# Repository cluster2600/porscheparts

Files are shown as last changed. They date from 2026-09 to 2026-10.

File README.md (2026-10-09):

<div align="center">

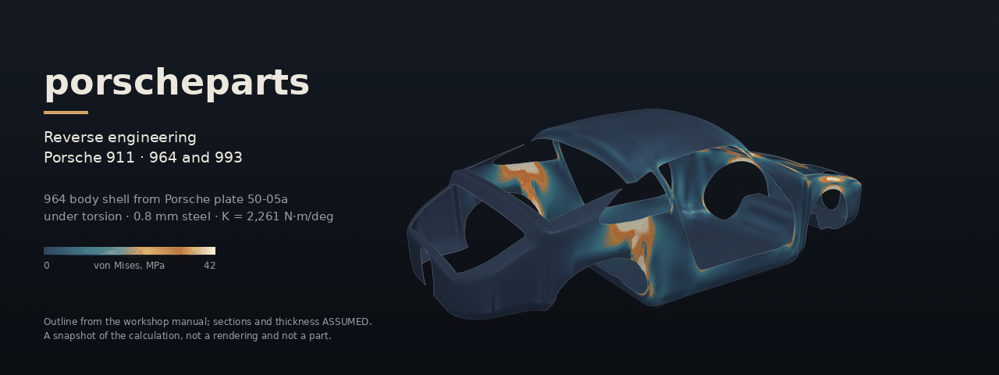
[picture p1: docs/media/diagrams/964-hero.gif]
The 964 body shell traced from the workshop manual, turning, coloured by von Mises stress under a torsion load


# porscheparts

**Reverse engineering for the Porsche 911 964 and 993**<br>
*Sourced data, falsifiable calculations, no part manufactured.*







[**Parts**](#2-993-parts-for-additive-manufacturing) ·
[**964 structure and monocoque**](#1-the-964-body-shell-and-the-carbon-monocoque-programme) ·
[**Engine cooling**](#3-engine-cooling) ·
[**Gallery**](docs/GALLERY.md) ·
[**Run the checks**](#quick-start) ·
[**Safety first**](SAFETY.md)

</div>

---

This repository does not publish a library of files to print. It publishes
**sourced data** and **falsifiable calculations**: every claim of fit, mass,
airflow or stiffness is tied to a measurement, a verifiable source or a
calculation anyone can rerun, and it is **withdrawn when it no longer holds**.
The repository has withdrawn several, listed
[further down this page](#what-the-repository-withdrew-from-its-own-results).

> [!IMPORTANT]
> **No part is validated.** All 41 part records are at status `concept`, and 23
> of them are `prohibited_pending_engineering`. Read [SAFETY.md](SAFETY.md).

<table>
<tr>
<td align="center"><h3>527</h3>qualified source records</td>
<td align="center"><h3>41</h3>part records<br><sub>23 prohibited as they stand</sub></td>
<td align="center"><h3>34</h3>993 design dossiers<br><sub>for additive manufacturing</sub></td>
</tr>
<tr>
<td align="center"><h3>10</h3>digital twin records<br><sub>none at <code>F2_interface</code></sub></td>
<td align="center"><h3>21</h3>LPBF print simulations<br><sub>17 screened, 4 not</sub></td>
<td align="center"><h3>3,391</h3>tests run by<br><code>make check</code></td>
</tr>
</table>

## What changed recently

| date | change |
|---|---|
| 2026-10-09 | **Two monocoque architectures in torsion**: on the same mesh and load, closed sections formed by the skin are 1.4 to 1.9 times stiffer per kilogram than tubes tangent to it, at all three meshes. A ranking of two hypotheses. [Comparison](twins/964-chassis/monocoque/README.md#two-architectures-one-load-case) |
| 2026-10-09 | **Torsion of the monocoque architecture**: K about 29,500 N·m/deg in steel and 22,300 in CFRP (75 kg), stable within 7% over three meshes, more than five times the open shell; carbon gives ×1.15 to ×1.28 per kilogram. A model value, not a car's. [Torsion](twins/964-chassis/monocoque/README.md#torsion-of-the-monocoque-architecture) |
| 2026-10-08 | **A ZESAD-type carbon monocoque in PicoGK**, inside the traced shell: closed sections around every aperture, boxed sills, tunnel and rails, sandwich floor and bulkheads; about 95 kg from assumed layups. A design envelope, not a part. [Monocoque](twins/964-chassis/monocoque/picogk/README.md) |
| 2026-10-08 | **A 911-shaped monocoque shell**: outline traced from the workshop manual's plate 50-05a, sections modelled, a first whole-body torsion run; it replaces the box cell in the banner. [Shell](twins/964-chassis/monocoque/README.md) |
| 2026-10-08 | **964 datum chain closed** from the workshop manual's own plates (50-02, 50-03, 50-05a): every suspension and power-unit mount of the monocoque interface contract now has a fore-aft position, checked against the underside scan. [Details](twins/964-chassis/README.md#the-longitudinal-chain-closed-from-plate-50-05a) |
| 2026-10-08 | **LPBF print simulation pictured**: build-up videos for the F1 cooling impeller and its stator. [Impeller dossier](docs/993/993_COOLING_IMPELLER_WE43_F1.md#print-simulation-pictured) |
| 2026-10-08 | **PicoGK batch 01**: ten parametric concept parts from one voxel-kernel project. [Batch page](parts/picogk-993-batch-01/README.md) |
| 2026-10-07 | **F1 cooling impeller redesigned from the original Turbo rotor**: same cup, windows and envelope, airfoil blades in WE43; the earlier generic shrouded design was withdrawn. [Dossier](docs/993/993_COOLING_IMPELLER_WE43_F1.md) |

> [!TIP]
> **Printable today:**
> - 🖨️ the **[switch trim ring, F1](parts/993-int-switch-trim-ring-f1-0001/print/README.md)**: a part the
>   repository designed, printed as designed, 17 minutes of PETG or ASA, no supports. Fit on the car not
>   checked yet ([decision 0010](docs/decisions/0010-print-the-trim-ring-f1-in-polymer.md)).
> - a **[fit-test kit for the dashboard switch blank](parts/993-int-switch-blank-0001/print/README.md)**: three
>   sizes to find the real opening ([decision 0009](docs/decisions/0009-first-fit-test-print-switch-blank.md)).
> - 🧩 **display mock-ups** of two prohibited designs, engraved "MOCK-UP / NOT FOR USE":
>   [the F0 connecting rod](parts/993-eng-connecting-rod-ti64-f0-0001/print/README.md) and
>   [the K16 wheel pair on a stand](parts/993-eng-k16-compressor-wheel-al2139-f1-0001/print/README.md)
>   ([decision 0011](docs/decisions/0011-printable-display-mockups-of-prohibited-parts.md)).
>
> None of them is validated.

## How the repository works

Every artifact climbs the same ladder, and every rung is checked by `make check`.
Nothing leaves the last rung: manufacturing is suspended by design.

```mermaid
flowchart LR
    S["Sources<br/><sub>catalog/sources/</sub>"] --> R["Part records<br/><sub>catalog/parts/</sub>"]
    R --> D["Design dossiers<br/><sub>docs/993/</sub>"]
    D --> T["Digital twins<br/><sub>twins/</sub>"]
    T --> C["FEA · CFD · print simulation<br/><sub>CalculiX · OpenFOAM · LPBF</sub>"]
    C --> G{"Quality gates<br/><sub>docs/QUALITY_GATES.md</sub>"}
    G -- "claim fails" --> W["Withdrawn, and said so"]
    G -- "claim holds" --> E["Evidence<br/><sub>pinned by SHA-256</sub>"]
    E -. "suspended in the active phase" .-> M["Manufacturing"]
    classDef stop fill:#fde2e1,stroke:#c0392b,color:#1a1a1a;
    classDef ok fill:#e3f1e6,stroke:#2e7d32,color:#1a1a1a;
    class M,W stop
    class E ok
```

### Where to start

| I want to… | go to |
|---|---|
| print something today | [the F1 switch trim ring](parts/993-int-switch-trim-ring-f1-0001/print/README.md) · [the switch blank fit-test kit](parts/993-int-switch-blank-0001/print/README.md) |
| see which 993 parts exist and their status | [the parts table](#2-993-parts-for-additive-manufacturing) → one page per part in [`docs/pieces/`](docs/pieces/) |
| follow the carbon monocoque programme | [section 1](#1-the-964-body-shell-and-the-carbon-monocoque-programme) → [the programme](docs/MONOCOQUE_964_993_PROGRAMME.md) |
| see the engine cooling work | [section 3](#3-engine-cooling) → [the fan programmes](docs/FAN_DEVELOPMENT_PROGRAMMES.md) |
| watch a print simulation | [F1 impeller build-up](parts/993-eng-cooling-impeller-we43-f1-0001/media/print-simulation/build.gif) · [all print screens](docs/993/print-screen-status.json) |
| know what may and may not be built | [SAFETY.md](SAFETY.md) · [docs/QUALITY_GATES.md](docs/QUALITY_GATES.md) |
| add a part or a source | [CONTRIBUTING.md](CONTRIBUTING.md) · [docs/WORKFLOW.md](docs/WORKFLOW.md) · [docs/SOURCE_POLICY.md](docs/SOURCE_POLICY.md) |
| find any document | [the documentation index](docs/README.md) · [the gallery](docs/GALLERY.md) · [dated reports](docs/reports/README.md) |
| browse the digital twins | [twins/README.md](twins/README.md) |
| run the checks locally | [Quick start](#quick-start) |

### Contents

1. [The 964 body shell and the carbon monocoque programme](#1-the-964-body-shell-and-the-carbon-monocoque-programme)
2. [993 parts for additive manufacturing](#2-993-parts-for-additive-manufacturing)
3. [Engine cooling](#3-engine-cooling)
4. [Engine and turbo research](#4-engine-and-turbo-research)
5. [Body and interior](#5-body-and-interior)
6. [The catalogue and its data contract](#6-the-catalogue-and-its-data-contract)
7. [The rules](#the-rules) · [What the repository withdrew](#what-the-repository-withdrew-from-its-own-results) · [What it does not claim](#what-the-project-does-not-claim)
8. [Quick start](#quick-start) · [Layout](#repository-layout) · [Status](#status)

---

## 1. The 964 body shell and the carbon monocoque programme

The main workstream. Its goal is a **replacement carbon monocoque for 964 and
993 restomods**, competing with the one existing offer on the axis where that
offer is bare: published data. The [programme](docs/MONOCOQUE_964_993_PROGRAMME.md)
says what has to be established, in what order, and that it **contradicts the
written scope** of [ROADMAP.md](ROADMAP.md).

### The structure: what the shell model shows

A finite-element shell model of the floor pan, the box section and the full
cell answers **relative** questions: between changing the material and closing
the body shell, which pays off more? Where does the load go in torsion?

The shell model, bare floor pan and full cell

**Results that hold**, see [`twins/964-chassis/fea/`](twins/964-chassis/fea/):

- the **side rail** carries torsion, not the floor pan, which agrees with plate
  50-013 of the workshop manual, which places high-strength steel there;
- **closing a ring does not just add stiffness, it changes the mechanism that
  carries it**: bending on the bare floor pan, shear on the closed cell;
- from bare floor pan to closed cell, **K × 3.77 for mass × 2.3**;
- roof and windshield frame together are worth **1.63 times** the sum of their
  separate contributions: the roof only works once the ring is closed;
- at equal mass, closing the body shell is worth more than switching to carbon.

von Mises stress on the bare floor pan

A **corpus of 3,000 CalculiX cases** in quadratic shells is built to train a
design surrogate later, its validation set frozen before any model exists:
[docs/MONOCOQUE_964_993_CHAINE_CALCUL.md](docs/MONOCOQUE_964_993_CHAINE_CALCUL.md).

### The shape: a 964 shell from the workshop manual

The box cell above has no 911 shape. The
[monocoque shell](twins/964-chassis/monocoque/README.md) takes its outline
from plate 50-05a, which draws the body-in-white to scale from the side and
from above, with wings, doors and lids off. Side profile, plan width, door
aperture, quarter window and rear wheel house are traced from it; the sections
between them (tumblehome, barrel sides, 880 mm beltline) are modelled.

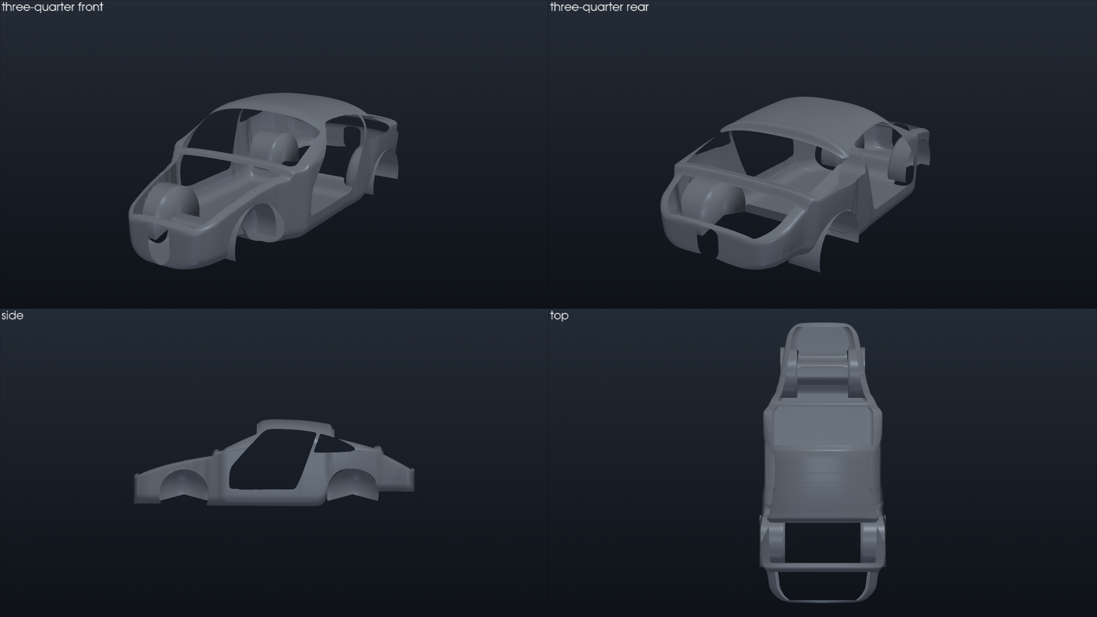
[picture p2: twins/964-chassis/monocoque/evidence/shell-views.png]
The monocoque shell traced from plate 50-05a


A first torsion run on it, uniform 0.8 mm steel with every aperture open,
puts the load around the windscreen frame, the A-pillars, the door corners and
the C-pillars: the open shell a monocoque has to close. Its K, 2,261 N·m/deg,
belongs to that surface model, not to a 964.

Inside that shell, [a ZESAD-type carbon monocoque](twins/964-chassis/monocoque/picogk/README.md)
is generated in voxels with PicoGK. Each aperture gets a closed section and
the sills, tunnel and rails are boxes, so the closures the box-cell study
ranked first are there by construction. Member sizes and layups are
hypotheses. In torsion, on the same mesh and load as the open shell, the
architecture is more than five times stiffer. Its K is stable within 7%
across meshes, while the open shell's is not
([torsion](twins/964-chassis/monocoque/README.md#torsion-of-the-monocoque-architecture)).

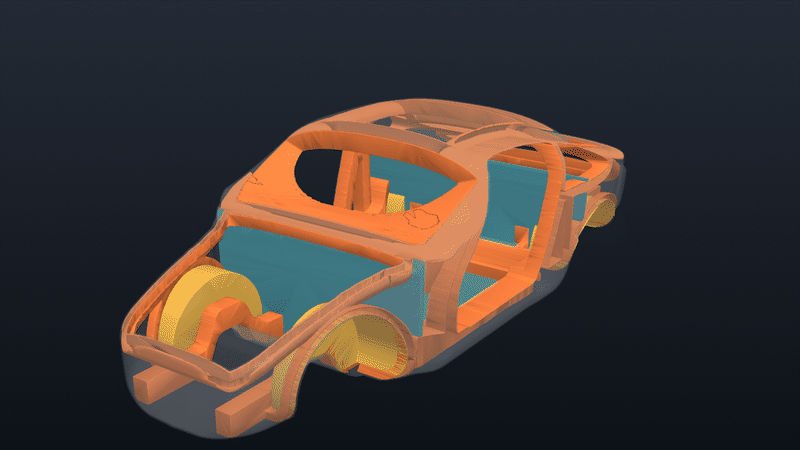
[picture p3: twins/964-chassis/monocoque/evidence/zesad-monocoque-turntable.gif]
A ZESAD-type monocoque generated with PicoGK


### The interfaces: where a monocoque has to bolt up

A monocoque replaces the body shell, so it must carry every suspension,
power-unit and jacking interface in one frame. Until October 2026 the
fore-aft position of those points could not be established. It now is, from
Porsche's own repair plates: plate 50-05a dimensions three points from a 0 line
through the front strut mounts, plate 50-02 shows dimension P is longitudinal,
and the rear diagonals of plate 50-03 are read the way both drawings and the
scan confirm. Two independent published paths place the front jacking point
within 1.9 mm of each other.

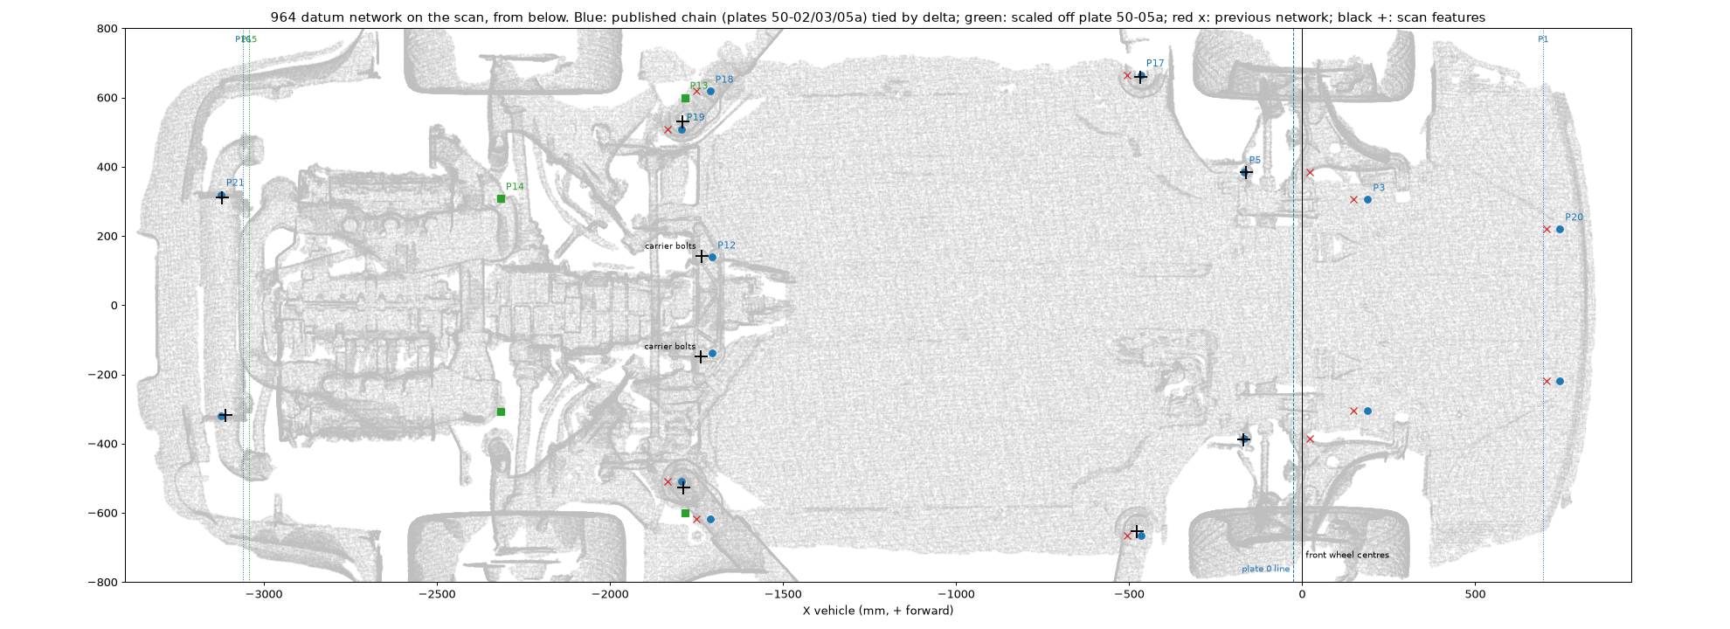
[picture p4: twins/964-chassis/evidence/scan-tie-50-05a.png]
Published datum chain tied to the underside scan


*Blue: points placed from published dimensions. Green: rear mounts scaled off
the plate. Black: features measured on the scan. Red: the previous, wrong
network.*

The monocoque's governing span, front suspension mount to transmission
carrier, is **1535.6 mm**, both ends published. What is missing now is
tolerance, not data: the points carry ±2 to 9 mm where a tool needs ±1 mm.
[The full chain, its checks and its limits](twins/964-chassis/README.md#the-longitudinal-chain-closed-from-plate-50-05a).

## 2. 993 parts for additive manufacturing

**34 design dossiers** in [`docs/993/`](docs/993/) and **41 part records**,
from the headlamp spring hook to the K16 turbine wheel in Inconel 718, by way
of the Ti-6Al-4V connecting rod, the AlSi10Mg compressor wheel, the IN625
exhaust manifold and the WE43 cooling impeller. Each dossier starts from
dimensions published by a supplier, separates what is sourced from what is
assumed, and states what it does not contain.

**Print simulation.** Every part with a STEP master goes through a geometric
LPBF simulation: full-height slicing at the material's layer thickness, fit in
the EOS M 290 envelope, an orientation, a support proxy, a wall-thickness
screen and a trapped-powder screen. 17 parts pass; 3 fail closed and say why, and 1 hit the memory cap, which is not a verdict.
It is not a process simulation, and it authorizes nothing.

<div align="center">

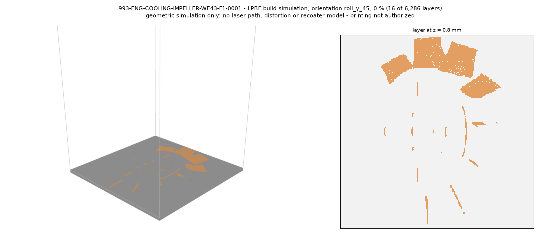
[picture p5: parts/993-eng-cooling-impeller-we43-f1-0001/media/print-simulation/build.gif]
The F1 cooling impeller built up layer by layer in the print simulation


*The F1 cooling impeller, 6,286 layers of 30 µm, tilted 45° on the plate,
with its support proxy in orange. Geometry only: printing is not authorized.*

</div>

**PicoGK batch 01.** [Ten parametric concept parts](parts/picogk-993-batch-01/README.md)
generated from one C# voxel-kernel project, each parameter tagged
`published`, `community` or `assumption`. Their mounting interfaces are
assumptions, so none is functional.

The table below is generated from `catalog/parts/` on every `make check`. The
"status" column is the record's, not an intention: a part **prohibited pending
engineering** stays so until an engineering review lifts it.

<!-- parts:start - generated by scripts/render_parts_table.py -->

> [!CAUTION]
> These are concept models for studying parts in software, not validated parts. 🖨️ marks a printable design, 🧩 an engraved display mock-up (never for use).

<table>
<tr>
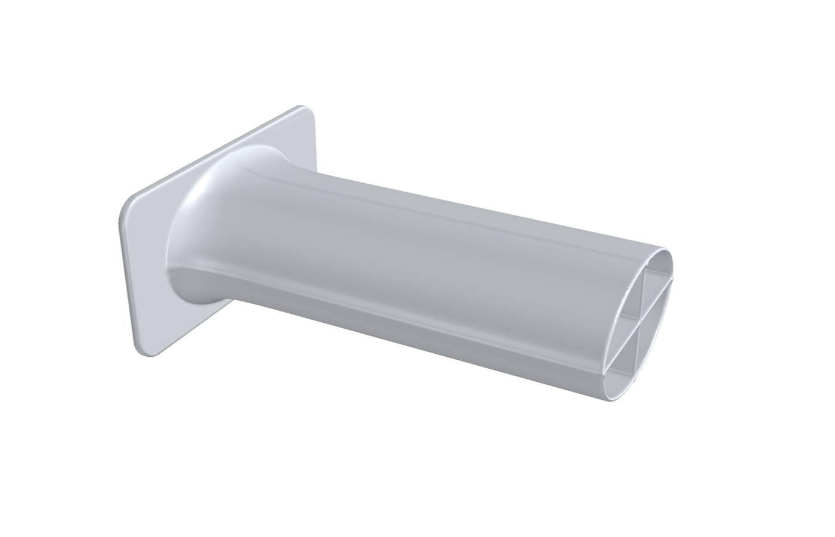
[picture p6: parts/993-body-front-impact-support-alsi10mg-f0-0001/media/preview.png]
993 front impact support
<td align="center" width="16%"><a href="parts/993-body-front-impact-support-alsi10mg-f0-0001/"><br><sub>993 front impact support</sub></a></td>
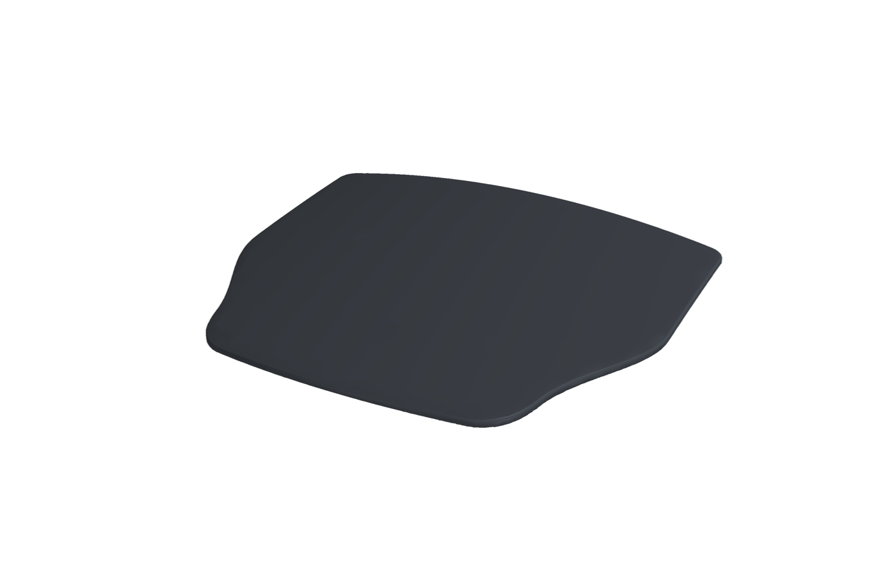
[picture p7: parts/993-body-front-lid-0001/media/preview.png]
Front lid
<td align="center" width="16%"><a href="parts/993-body-front-lid-0001/"><br><sub>Front lid</sub></a></td>
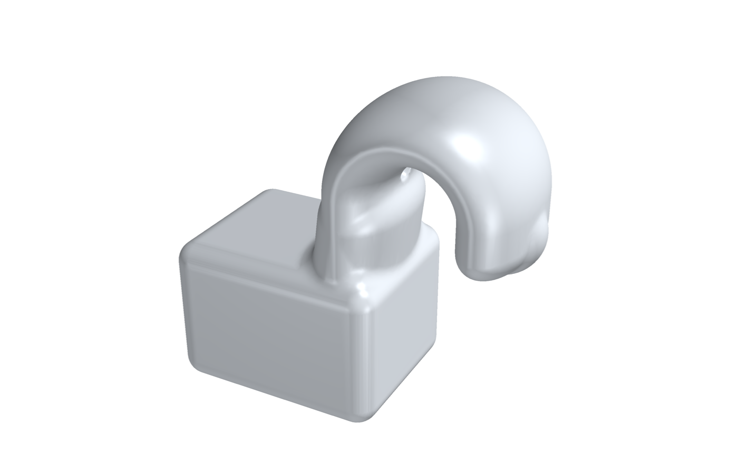
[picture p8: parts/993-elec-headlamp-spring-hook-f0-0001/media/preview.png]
Headlamp spring hook repair
<td align="center" width="16%"><a href="parts/993-elec-headlamp-spring-hook-f0-0001/"><br><sub>Headlamp spring hook repair</sub></a></td>
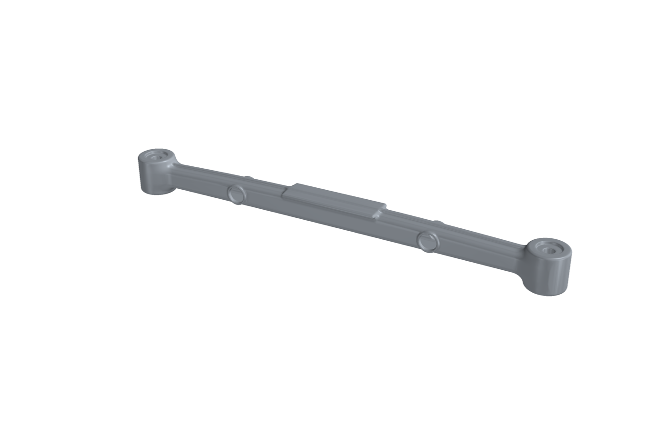
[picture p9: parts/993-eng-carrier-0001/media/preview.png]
Turbo engine carrier (Motortraege…
<td align="center" width="16%"><a href="parts/993-eng-carrier-0001/"><br><sub>Turbo engine carrier (Motortraege…</sub></a></td>
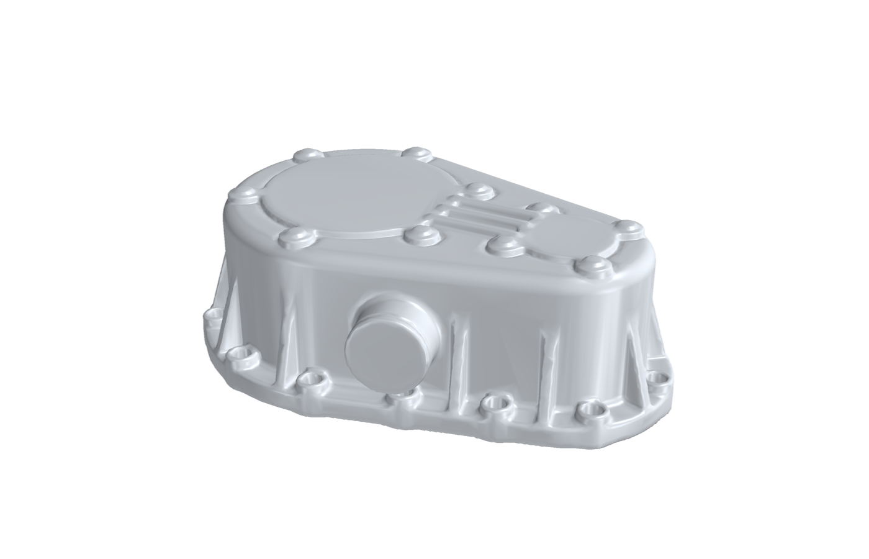
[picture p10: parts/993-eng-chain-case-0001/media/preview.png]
993 timing chain case and its lids
<td align="center" width="16%"><a href="parts/993-eng-chain-case-0001/"><br><sub>993 timing chain case and its lids</sub></a></td>
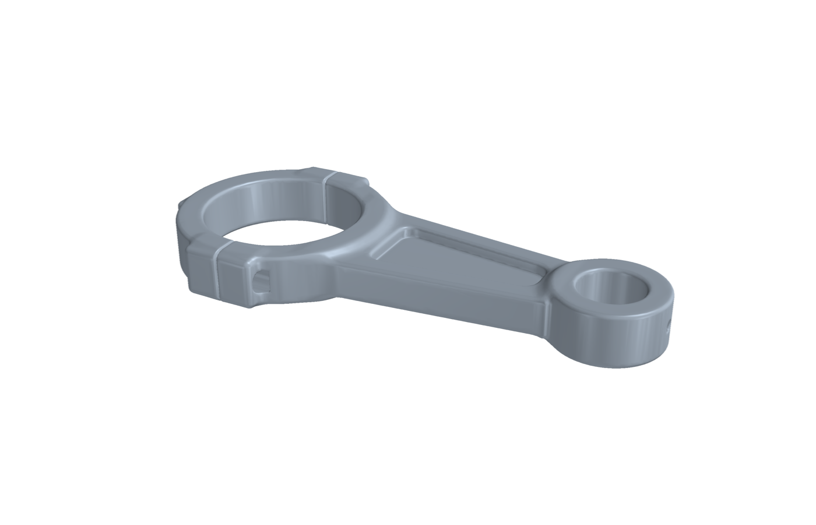
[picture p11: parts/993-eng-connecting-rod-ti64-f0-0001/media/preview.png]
🧩 993/993 Turbo connecting rod
<td align="center" width="16%"><a href="parts/993-eng-connecting-rod-ti64-f0-0001/"><br><sub>🧩 993/993 Turbo connecting rod</sub></a></td>
</tr>
<tr>
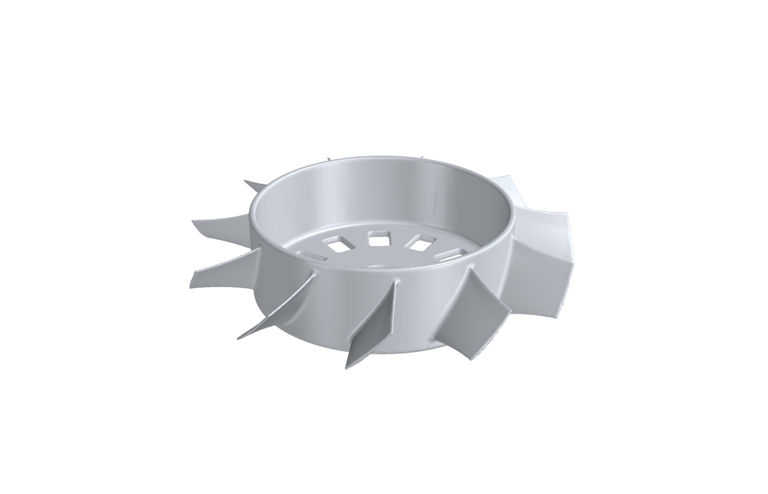
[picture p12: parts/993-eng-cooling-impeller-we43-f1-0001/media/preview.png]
Engine cooling fan impeller
<td align="center" width="16%"><a href="parts/993-eng-cooling-impeller-we43-f1-0001/"><br><sub>Engine cooling fan impeller</sub></a></td>
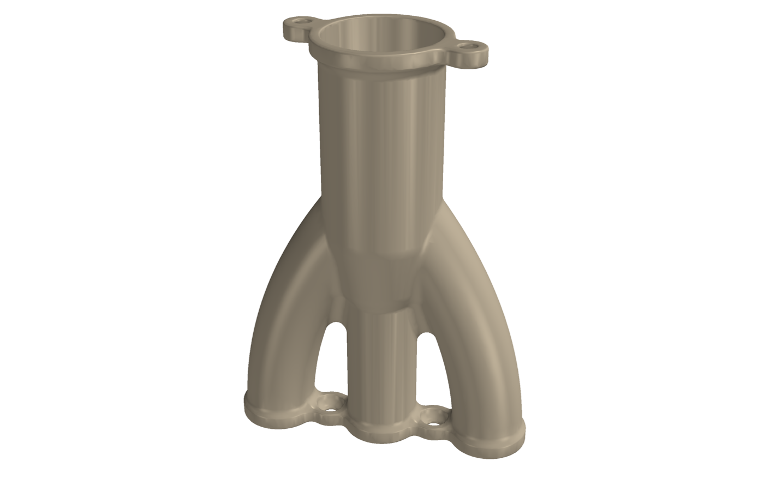
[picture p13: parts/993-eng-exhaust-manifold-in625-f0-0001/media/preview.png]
993 Turbo three-into-one exhaust…
<td align="center" width="16%"><a href="parts/993-eng-exhaust-manifold-in625-f0-0001/"><br><sub>993 Turbo three-into-one exhaust…</sub></a></td>
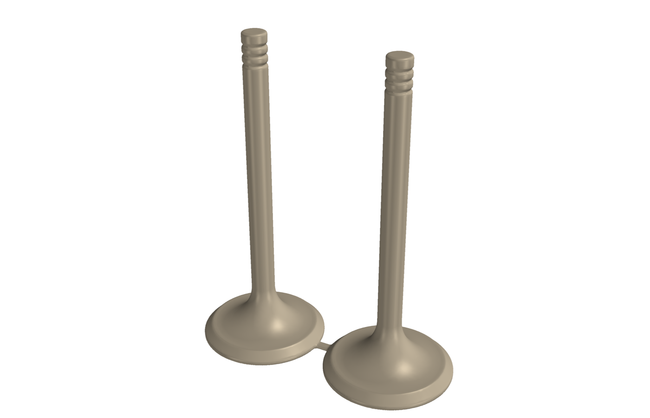
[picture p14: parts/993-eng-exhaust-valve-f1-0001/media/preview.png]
993 exhaust valves - F1 proxies
<td align="center" width="16%"><a href="parts/993-eng-exhaust-valve-f1-0001/"><br><sub>993 exhaust valves - F1 proxies</sub></a></td>
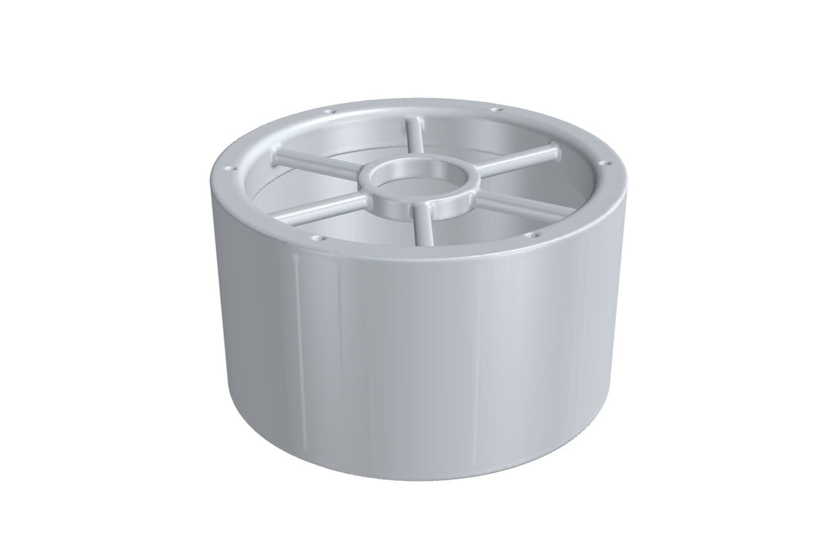
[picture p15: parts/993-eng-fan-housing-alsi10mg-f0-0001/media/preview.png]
Stationary engine fan housing
<td align="center" width="16%"><a href="parts/993-eng-fan-housing-alsi10mg-f0-0001/"><br><sub>Stationary engine fan housing</sub></a></td>
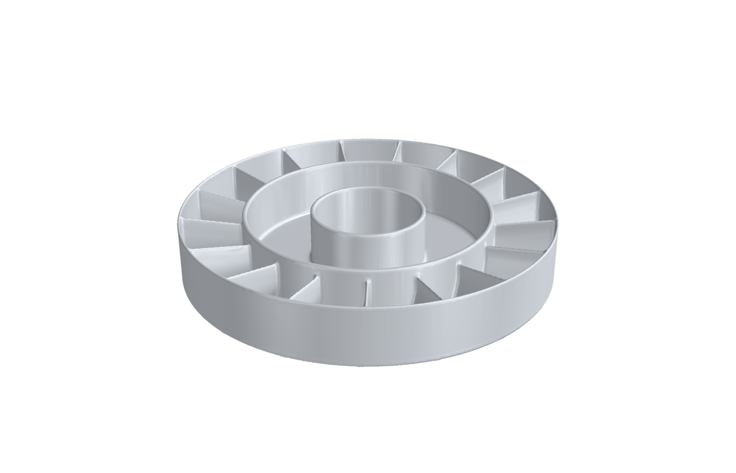
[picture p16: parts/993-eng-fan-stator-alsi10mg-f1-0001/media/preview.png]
Engine cooling fan guide-vane rin…
<td align="center" width="16%"><a href="parts/993-eng-fan-stator-alsi10mg-f1-0001/"><br><sub>Engine cooling fan guide-vane rin…</sub></a></td>
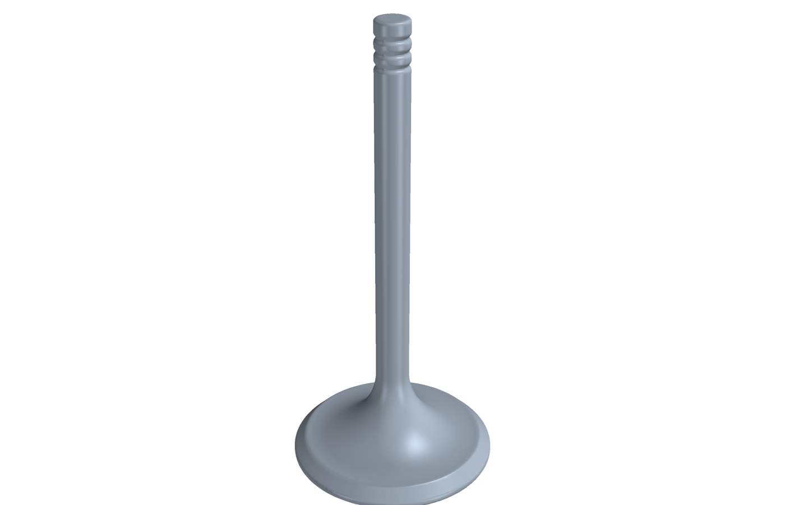
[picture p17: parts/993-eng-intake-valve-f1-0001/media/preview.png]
993 intake valve - F1 proxy and t…
<td align="center" width="16%"><a href="parts/993-eng-intake-valve-f1-0001/"><br><sub>993 intake valve - F1 proxy and t…</sub></a></td>
</tr>
<tr>
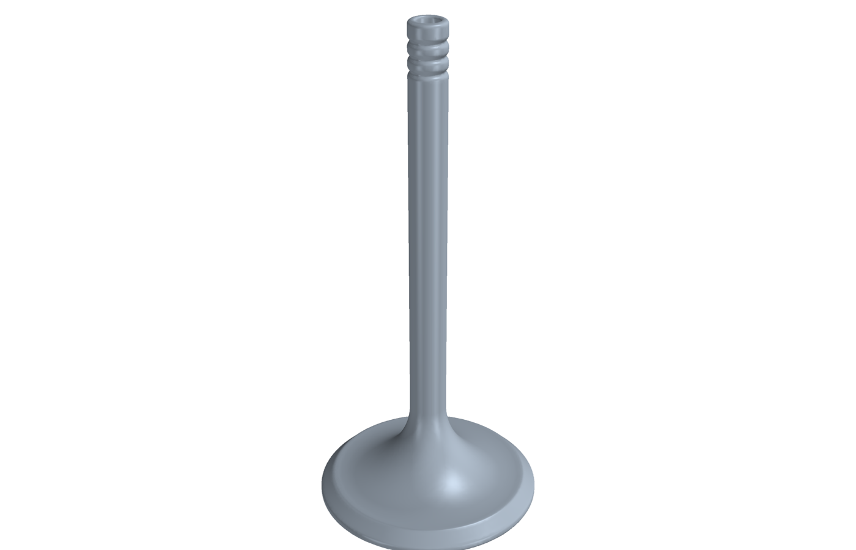
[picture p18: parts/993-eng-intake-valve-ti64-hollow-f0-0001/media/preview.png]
993 hollow Ti64 intake valve
<td align="center" width="16%"><a href="parts/993-eng-intake-valve-ti64-hollow-f0-0001/"><br><sub>993 hollow Ti64 intake valve</sub></a></td>
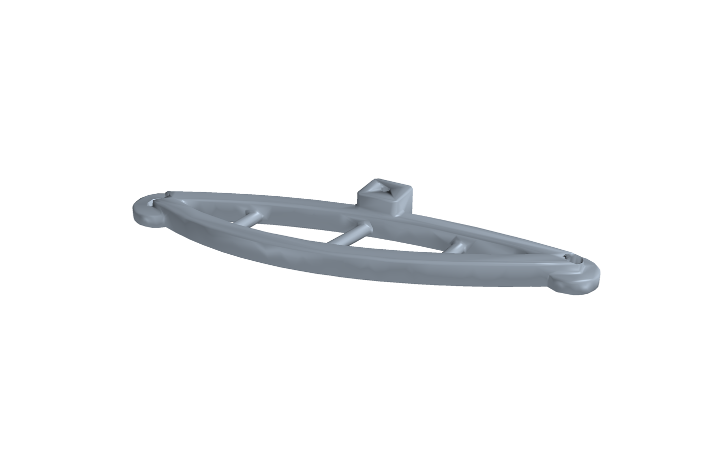
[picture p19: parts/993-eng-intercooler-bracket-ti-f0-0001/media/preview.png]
993 Turbo/GT2 intercooler bracket
<td align="center" width="16%"><a href="parts/993-eng-intercooler-bracket-ti-f0-0001/"><br><sub>993 Turbo/GT2 intercooler bracket</sub></a></td>
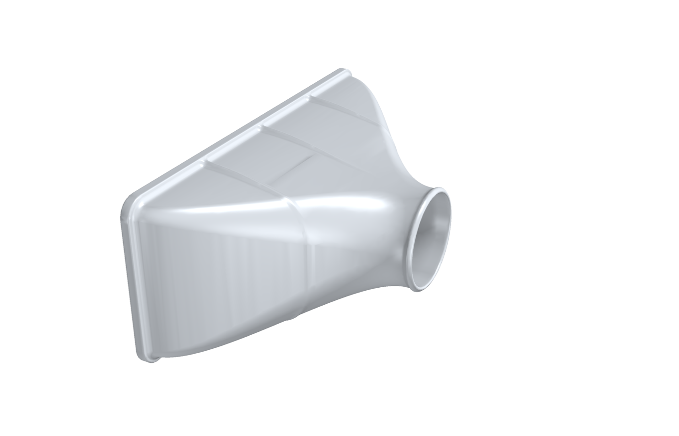
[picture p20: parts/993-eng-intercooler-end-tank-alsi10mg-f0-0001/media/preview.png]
993 Turbo intercooler end tank
<td align="center" width="16%"><a href="parts/993-eng-intercooler-end-tank-alsi10mg-f0-0001/"><br><sub>993 Turbo intercooler end tank</sub></a></td>
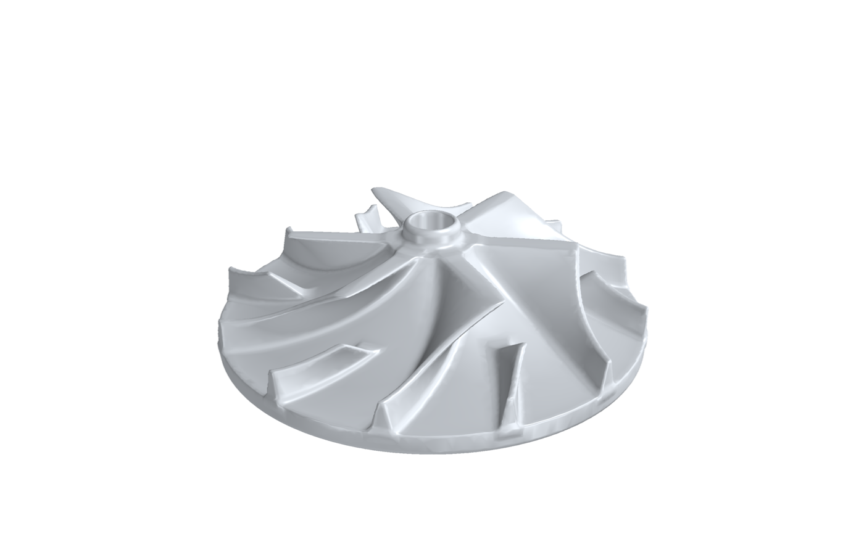
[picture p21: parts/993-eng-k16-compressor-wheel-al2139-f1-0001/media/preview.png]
🧩 K16 compressor wheel
<td align="center" width="16%"><a href="parts/993-eng-k16-compressor-wheel-al2139-f1-0001/"><br><sub>🧩 K16 compressor wheel</sub></a></td>
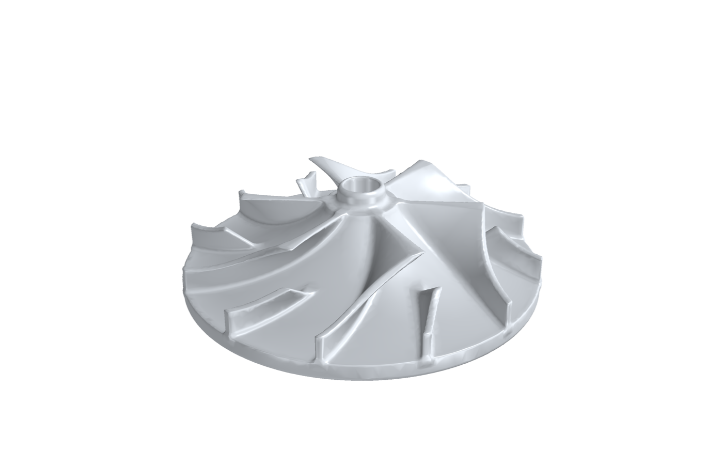
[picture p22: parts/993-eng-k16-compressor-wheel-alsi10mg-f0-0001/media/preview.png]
993 K16 compressor wheel
<td align="center" width="16%"><a href="parts/993-eng-k16-compressor-wheel-alsi10mg-f0-0001/"><br><sub>993 K16 compressor wheel</sub></a></td>
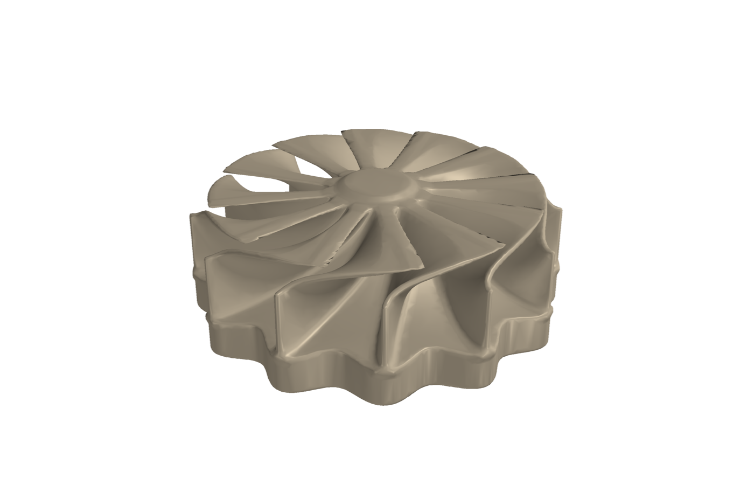
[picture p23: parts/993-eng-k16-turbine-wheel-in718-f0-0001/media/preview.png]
🧩 K16 turbine wheel
<td align="center" width="16%"><a href="parts/993-eng-k16-turbine-wheel-in718-f0-0001/"><br><sub>🧩 K16 turbine wheel</sub></a></td>
</tr>
<tr>
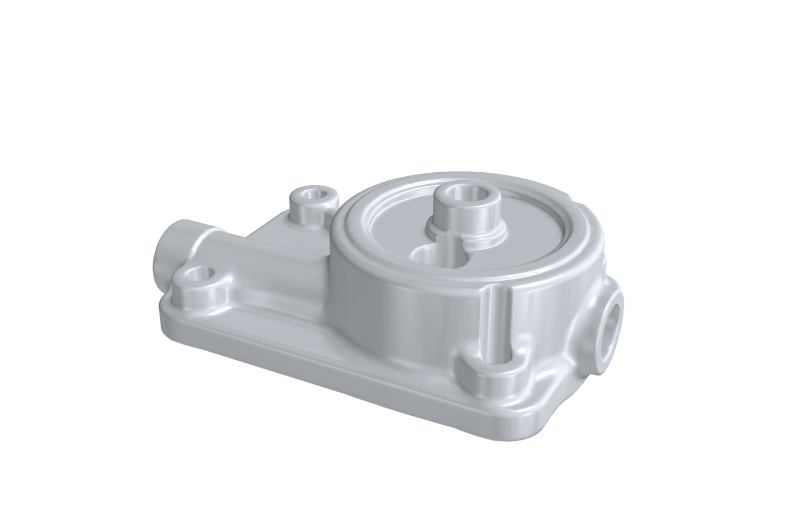
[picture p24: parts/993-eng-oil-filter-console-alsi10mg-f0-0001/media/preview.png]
Engine oil filter console with in…
<td align="center" width="16%"><a href="parts/993-eng-oil-filter-console-alsi10mg-f0-0001/"><br><sub>Engine oil filter console with in…</sub></a></td>
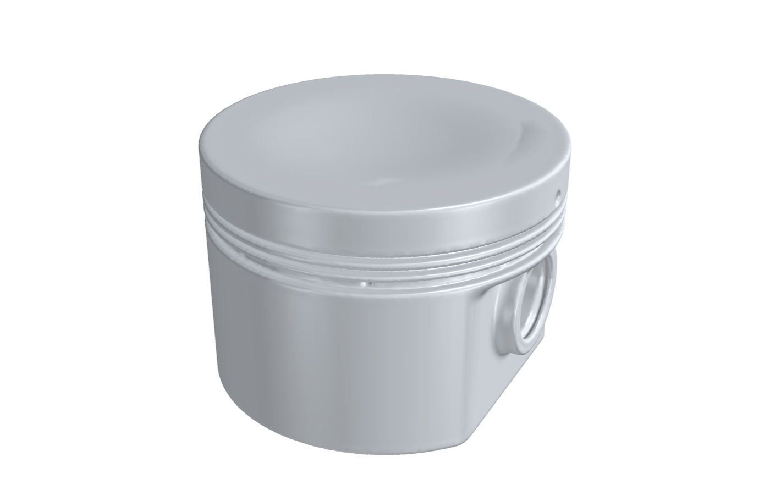
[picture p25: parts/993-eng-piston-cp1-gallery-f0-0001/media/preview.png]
M64/60 piston with cooling gallery
<td align="center" width="16%"><a href="parts/993-eng-piston-cp1-gallery-f0-0001/"><br><sub>M64/60 piston with cooling gallery</sub></a></td>
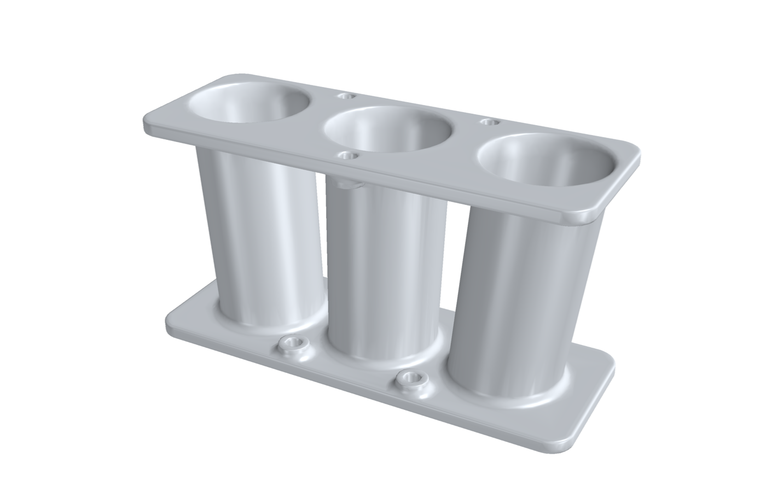
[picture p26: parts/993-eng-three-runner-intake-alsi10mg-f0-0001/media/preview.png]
993 three-runner intake manifold
<td align="center" width="16%"><a href="parts/993-eng-three-runner-intake-alsi10mg-f0-0001/"><br><sub>993 three-runner intake manifold</sub></a></td>
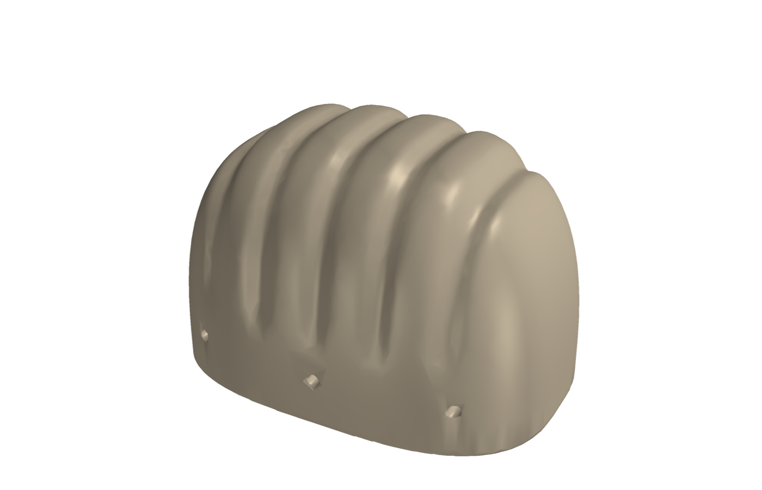
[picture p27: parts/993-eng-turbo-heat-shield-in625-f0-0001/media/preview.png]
993 left turbo heat shield cover
<td align="center" width="16%"><a href="parts/993-eng-turbo-heat-shield-in625-f0-0001/"><br><sub>993 left turbo heat shield cover</sub></a></td>
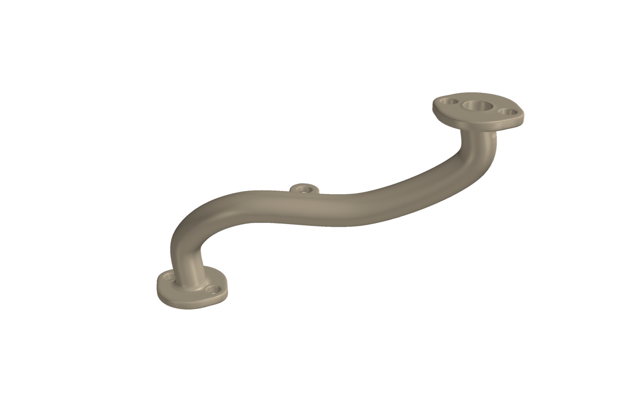
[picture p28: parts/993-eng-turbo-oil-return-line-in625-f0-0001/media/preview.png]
Turbo oil return line
<td align="center" width="16%"><a href="parts/993-eng-turbo-oil-return-line-in625-f0-0001/"><br><sub>Turbo oil return line</sub></a></td>
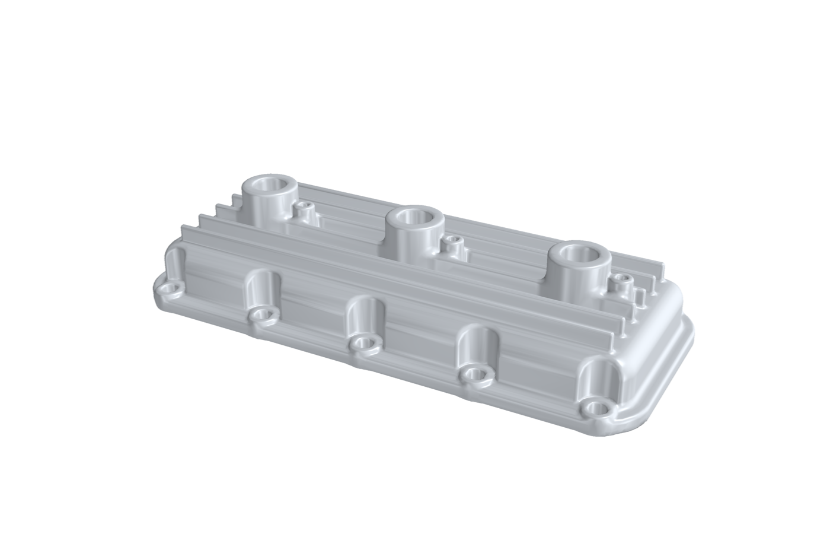
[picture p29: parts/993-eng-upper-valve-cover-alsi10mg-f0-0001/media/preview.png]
Upper valve cover with COP towers
<td align="center" width="16%"><a href="parts/993-eng-upper-valve-cover-alsi10mg-f0-0001/"><br><sub>Upper valve cover with COP towers</sub></a></td>
</tr>
<tr>
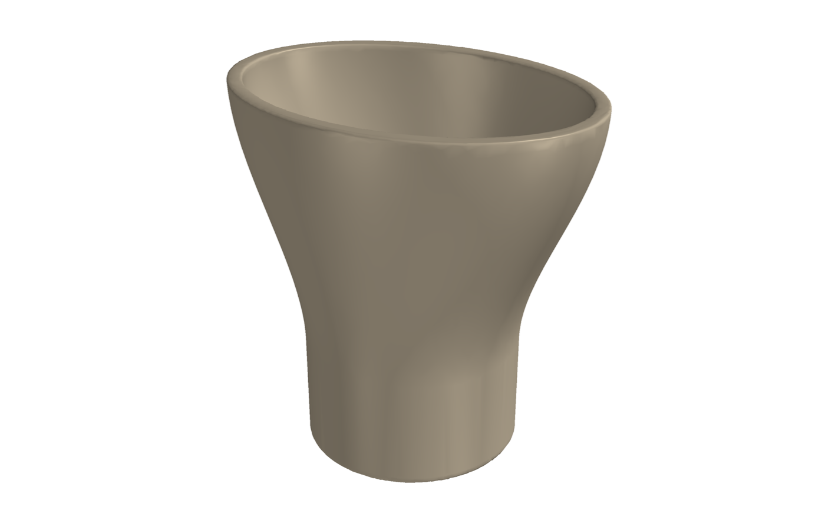
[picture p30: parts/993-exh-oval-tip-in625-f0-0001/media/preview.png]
993 oval exhaust tip
<td align="center" width="16%"><a href="parts/993-exh-oval-tip-in625-f0-0001/"><br><sub>993 oval exhaust tip</sub></a></td>
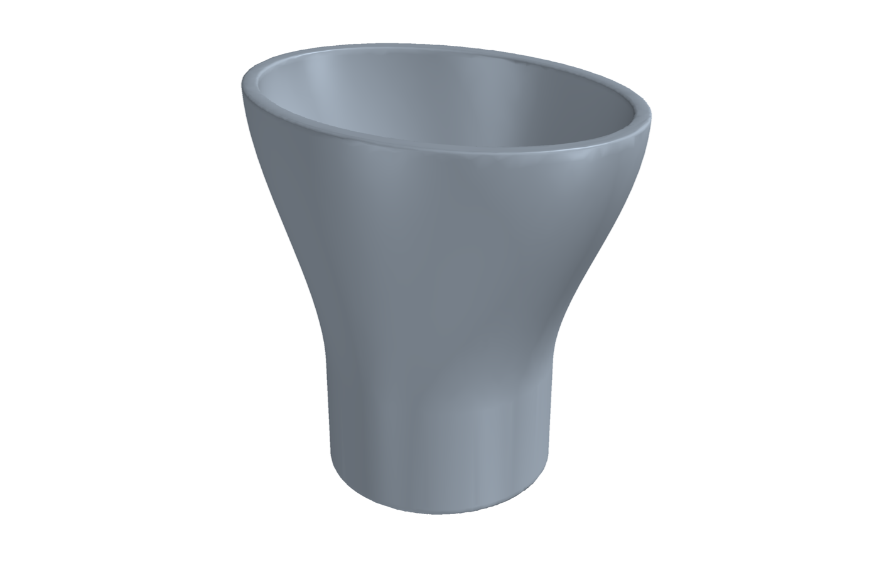
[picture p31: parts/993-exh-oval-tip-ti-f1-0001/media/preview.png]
Oval exhaust tip
<td align="center" width="16%"><a href="parts/993-exh-oval-tip-ti-f1-0001/"><br><sub>Oval exhaust tip</sub></a></td>
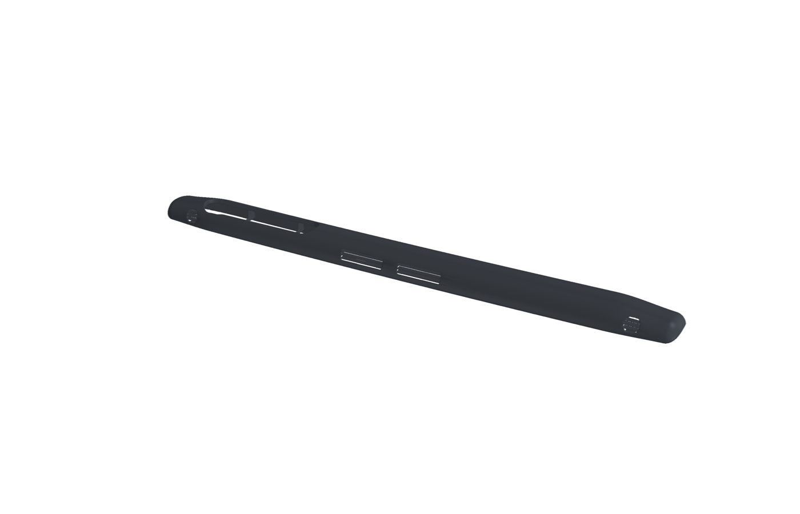
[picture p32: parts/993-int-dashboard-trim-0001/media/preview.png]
Dashboard trim
<td align="center" width="16%"><a href="parts/993-int-dashboard-trim-0001/"><br><sub>Dashboard trim</sub></a></td>
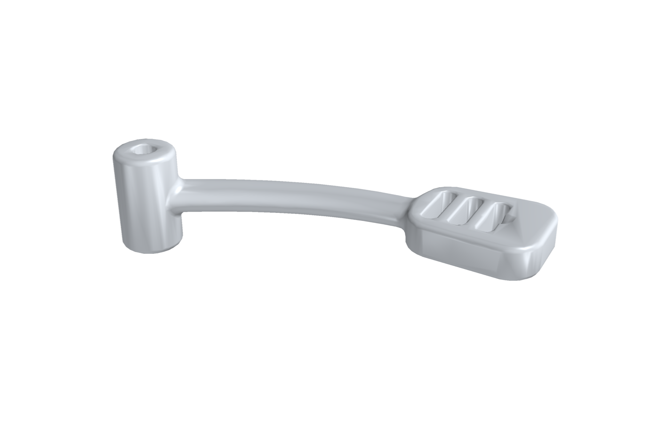
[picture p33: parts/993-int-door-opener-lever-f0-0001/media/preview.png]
993 interior door opener lever
<td align="center" width="16%"><a href="parts/993-int-door-opener-lever-f0-0001/"><br><sub>993 interior door opener lever</sub></a></td>
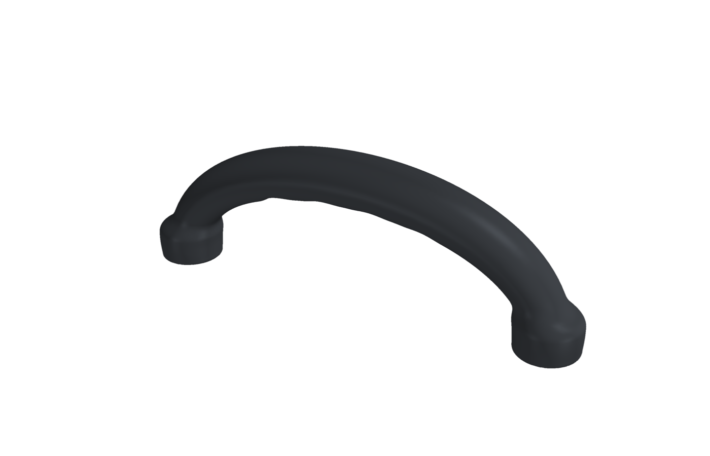
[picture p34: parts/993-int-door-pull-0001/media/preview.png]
Interior door pull handle
<td align="center" width="16%"><a href="parts/993-int-door-pull-0001/"><br><sub>Interior door pull handle</sub></a></td>
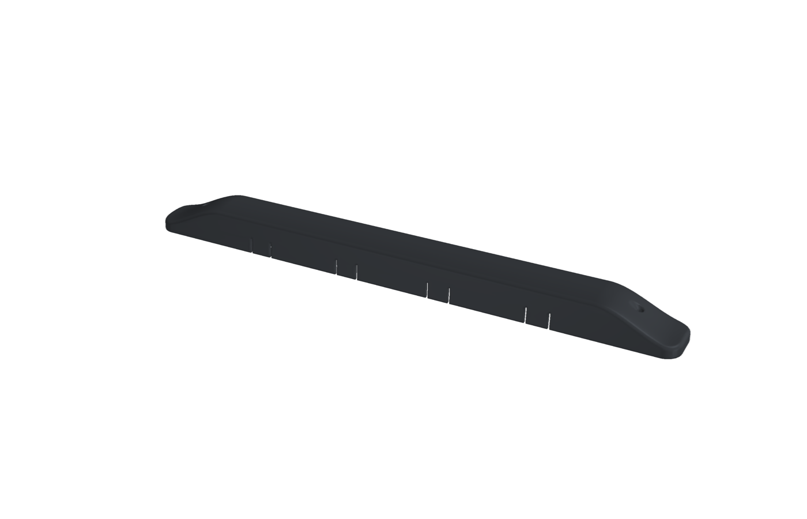
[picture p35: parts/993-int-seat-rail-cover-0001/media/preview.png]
Seat rail cover
<td align="center" width="16%"><a href="parts/993-int-seat-rail-cover-0001/"><br><sub>Seat rail cover</sub></a></td>
</tr>
<tr>
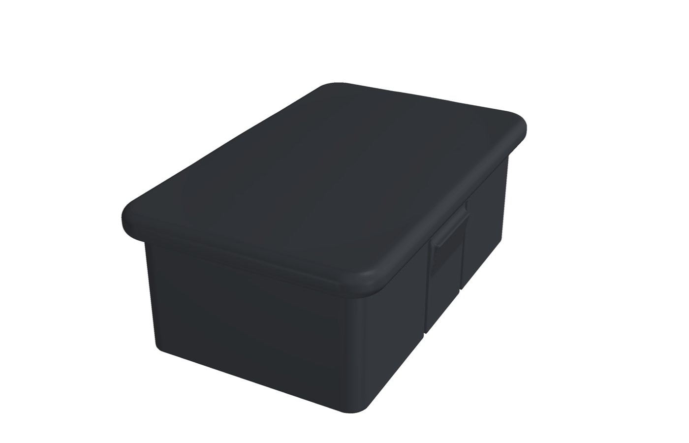
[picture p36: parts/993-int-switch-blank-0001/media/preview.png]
Switch blank
<td align="center" width="16%"><a href="parts/993-int-switch-blank-0001/"><br><sub>Switch blank</sub></a></td>
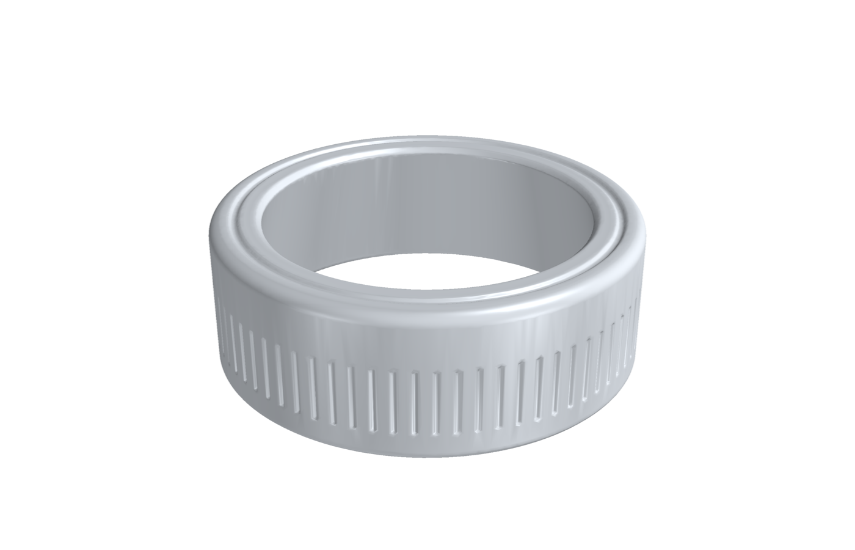
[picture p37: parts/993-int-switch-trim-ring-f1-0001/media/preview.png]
🖨️ Aluminum switch trim ring
<td align="center" width="16%"><a href="parts/993-int-switch-trim-ring-f1-0001/"><br><sub>🖨️ Aluminum switch trim ring</sub></a></td>
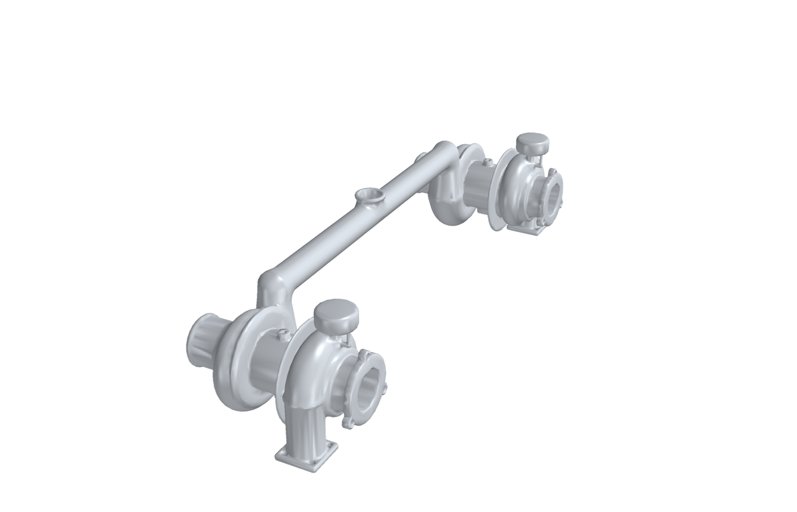
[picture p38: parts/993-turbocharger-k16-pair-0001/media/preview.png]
Pair of K16 turbochargers of the…
<td align="center" width="16%"><a href="parts/993-turbocharger-k16-pair-0001/"><br><sub>Pair of K16 turbochargers of the…</sub></a></td>
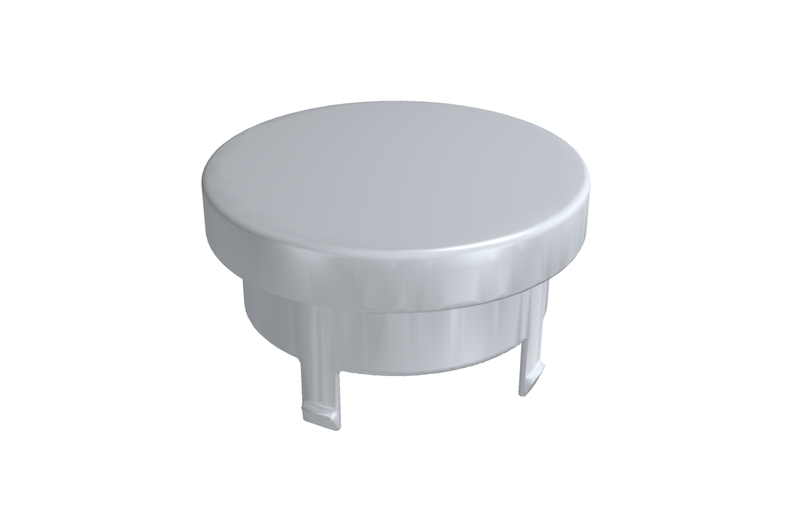
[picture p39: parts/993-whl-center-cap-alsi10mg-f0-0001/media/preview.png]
993 center cap
<td align="center" width="16%"><a href="parts/993-whl-center-cap-alsi10mg-f0-0001/"><br><sub>993 center cap</sub></a></td>
</tr>
</table>

*Concept models rendered by `scripts/render_part_previews.py`: 34 of 41 are PicoGK voxel models ([`parts/picogk-catalog/`](parts/picogk-catalog/README.md)), the others concept CAD blocks. **None of these is the original part, and none is validated**: 41 of 41 records are at `concept`, and 0 of 41 have measured geometry. 🖨️ Printable as designed, fit unchecked: Aluminum switch trim ring. 🧩 Printable as an engraved display mock-up, never for use: 993/993 Turbo connecting rod, K16 compressor wheel, K16 turbine wheel. Click a part to see it next to the original.*

```mermaid
pie showData title 41 part records by safety class
    "prohibited pending engineering" : 23
    "safety-critical" : 1
    "functional" : 12
    "non-critical" : 5
```

```mermaid
flowchart LR
    L0["concept<br/><b>41</b> records"]
    L1["dimensionally_reviewed<br/><b>0</b> records"]
    L2["prototype_fitted<br/><b>0</b> records"]
    L3["functionally_tested<br/><b>0</b> records"]
    L4["engineering_reviewed<br/><b>0</b> records"]
    L5["released<br/><b>0</b> records"]
    L0 --> L1 --> L2 --> L3 --> L4 --> L5
    classDef here fill:#fff4d6,stroke:#b7791f,color:#1a1a1a;
    classDef empty fill:#f4f4f4,stroke:#9e9e9e,color:#6b6b6b;
    class L0 here
    class L1 empty
    class L2 empty
    class L3 empty
    class L4 empty
    class L5 empty
```

*The validation ladder of `catalog/schemas/part.schema.json`, with the number of records whose `validation.status` names each step. Both charts are computed from the records.*

**Engine, intake and cooling**

| part | candidate material | process | status |
|---|---|---|---|
| [Turbo engine carrier (Motortraeger)](docs/pieces/993-eng-carrier-0001.md) | unknown | undecided | **safety-critical** |
| [993 timing chain case and its lids](docs/pieces/993-eng-chain-case-0001.md) | unidentified | undecided | **prohibited pending engineering** |
| [Left chain case lid 964 105 107 01](docs/pieces/993-eng-chain-case-lid-ti-f0-0001.md) | Ti-6Al-4V Grade 5, plate — deliberate c… | CNC | functional |
| [993/993 Turbo connecting rod](docs/pieces/993-eng-connecting-rod-ti64-f0-0001.md) | Ti-6Al-4V Grade 5 LPBF for screening | LPBF | **prohibited pending engineering** |
| [993 engine cooling fan — archived Carrera F0…](docs/pieces/993-eng-cooling-impeller-alsi10mg-f0-0001.md) | EOS Aluminium AlSi10Mg T6 for comparison | undecided | **prohibited pending engineering** |
| [Engine cooling fan impeller](docs/pieces/993-eng-cooling-impeller-we43-f1-0001.md) | WE43 LPBF, solutionized and aged, for c… | LPBF | **prohibited pending engineering** |
| [M64 four-valve cylinder head — creation prepa…](docs/pieces/993-eng-cylinder-head-4v-f0-0001.md) | not selected | undecided | **prohibited pending engineering** |
| [993 Turbo three-into-one exhaust manifold](docs/pieces/993-eng-exhaust-manifold-in625-f0-0001.md) | EOS NickelAlloy IN625 / UNS N06625 for… | undecided | **prohibited pending engineering** |
| [993 exhaust valves - F1 proxies](docs/pieces/993-eng-exhaust-valve-f1-0001.md) | INCONEL 751 / UNS N07751 candidate | CNC | **prohibited pending engineering** |
| [Stationary engine fan housing](docs/pieces/993-eng-fan-housing-alsi10mg-f0-0001.md) | EOS Aluminium AlSi10Mg T6 for comparison | undecided | **prohibited pending engineering** |
| [Engine cooling fan guide-vane ring (stator)](docs/pieces/993-eng-fan-stator-alsi10mg-f1-0001.md) | EOS Aluminium AlSi10Mg T6 for comparison | LPBF | **prohibited pending engineering** |
| [993 intake valve - F1 proxy and titanium vari…](docs/pieces/993-eng-intake-valve-f1-0001.md) | Ti-6Al-4V Grade 5 | DMLS | **prohibited pending engineering** |
| [993 hollow Ti64 intake valve](docs/pieces/993-eng-intake-valve-ti64-hollow-f0-0001.md) | Ti-6Al-4V Grade 5 LPBF, screening | LPBF | **prohibited pending engineering** |
| [993 Turbo/GT2 intercooler bracket](docs/pieces/993-eng-intercooler-bracket-ti-f0-0001.md) | Ti-6Al-4V Grade 5 for screening | CNC | functional |
| [993 Turbo intercooler end tank](docs/pieces/993-eng-intercooler-end-tank-alsi10mg-f0-0001.md) | EOS Aluminium AlSi10Mg for screening | LPBF | **prohibited pending engineering** |
| [K16 compressor wheel](docs/pieces/993-eng-k16-compressor-wheel-al2139-f1-0001.md) | EOS Aluminium Al2139 AM, M290 60 µm, he… | LPBF | **prohibited pending engineering** |
| [993 K16 compressor wheel](docs/pieces/993-eng-k16-compressor-wheel-alsi10mg-f0-0001.md) | EOS AlSi10Mg, screening | LPBF | **prohibited pending engineering** |
| [K16 turbine wheel](docs/pieces/993-eng-k16-turbine-wheel-in718-f0-0001.md) | EOS NickelAlloy IN718 API, M290 40 µm… | undecided | **prohibited pending engineering** |
| [Engine oil filter console with integrated gal…](docs/pieces/993-eng-oil-filter-console-alsi10mg-f0-0001.md) | EOS Aluminium AlSi10Mg T6 for comparison | undecided | **prohibited pending engineering** |
| [M64/60 piston with cooling gallery](docs/pieces/993-eng-piston-cp1-gallery-f0-0001.md) | Constellium Aheadd CP1, Velo3D Sapphire… | LPBF | **prohibited pending engineering** |
| [993 three-runner intake manifold](docs/pieces/993-eng-three-runner-intake-alsi10mg-f0-0001.md) | generic AlSi10Mg for screening | undecided | functional |
| [993 left turbo heat shield cover](docs/pieces/993-eng-turbo-heat-shield-in625-f0-0001.md) | EOS NickelAlloy IN625 / UNS N06625, scr… | undecided | functional |
| [Turbo oil return line](docs/pieces/993-eng-turbo-oil-return-line-in625-f0-0001.md) | EOS NickelAlloy IN625 / UNS N06625 for… | undecided | **prohibited pending engineering** |
| [Upper valve cover with COP towers](docs/pieces/993-eng-upper-valve-cover-alsi10mg-f0-0001.md) | EOS Aluminium AlSi10Mg T6, for comparis… | undecided | **prohibited pending engineering** |

**Charge air**

| part | candidate material | process | status |
|---|---|---|---|
| [993 Turbo charge-air tract transcribed parts…](docs/pieces/993-ca-charge-pipe-set-pet-0001.md) | unknown per line item (hoses are rubber… | undecided | non-critical |
| [993 Turbo turbocharging intake tract (group 1…](docs/pieces/993-ca-turbo-intake-manifold-pet-0001.md) | unknown | undecided | non-critical |

**Turbocharger**

| part | candidate material | process | status |
|---|---|---|---|
| [Pair of K16 turbochargers of the 993 Turbo](docs/pieces/993-turbocharger-k16-pair-0001.md) | undetermined | undecided | **prohibited pending engineering** |

**Exhaust**

| part | candidate material | process | status |
|---|---|---|---|
| [993 Turbo catalytic converters (front muffler…](docs/pieces/993-exh-cat-converter-pair-pet-0001.md) | unknown | undecided | **prohibited pending engineering** |
| [993 Turbo exhaust heat exchangers (manifolds)](docs/pieces/993-exh-heat-exchanger-pair-pet-0001.md) | unknown (an IN625 aftermarket offer exi… | undecided | **prohibited pending engineering** |
| [993 oval exhaust tip](docs/pieces/993-exh-oval-tip-in625-f0-0001.md) | EOS NickelAlloy IN625 / UNS N06625 for… | undecided | functional |
| [Oval exhaust tip](docs/pieces/993-exh-oval-tip-ti-f1-0001.md) | Ti-6Al-4V if the actual temperature all… | LPBF | functional |

**Body**

| part | candidate material | process | status |
|---|---|---|---|
| [993 front impact support](docs/pieces/993-body-front-impact-support-alsi10mg-f0-0001.md) | generic screening AlSi10Mg | undecided | **prohibited pending engineering** |
| [Front lid](docs/pieces/993-body-front-lid-0001.md) | fiber and resin to be determined | undecided | functional |

**Interior**

| part | candidate material | process | status |
|---|---|---|---|
| [Dashboard trim](docs/pieces/993-int-dashboard-trim-0001.md) | fiber and resin to be determined | undecided | functional |
| [993 interior door opener lever](docs/pieces/993-int-door-opener-lever-f0-0001.md) | AlSi10Mg, screening | LPBF | functional |
| [Interior door pull handle](docs/pieces/993-int-door-pull-0001.md) | to_be_determined_after_load_test | undecided | functional |
| [Seat rail cover](docs/pieces/993-int-seat-rail-cover-0001.md) | to_be_determined_after_fit_test | FFF | non-critical |
| [Switch blank](docs/pieces/993-int-switch-blank-0001.md) | to_be_determined_after_fit_test | FFF | non-critical |
| [Aluminum switch trim ring](docs/pieces/993-int-switch-trim-ring-f1-0001.md) | EN AW-6063 T6 retained for bright anodi… | CNC | non-critical |

**Lighting**

| part | candidate material | process | status |
|---|---|---|---|
| [Headlamp spring hook repair](docs/pieces/993-elec-headlamp-spring-hook-f0-0001.md) | EOS Aluminium AlSi10Mg / AlSi10Mg_FlexM… | LPBF | functional |

**Wheels**

| part | candidate material | process | status |
|---|---|---|---|
| [993 center cap](docs/pieces/993-whl-center-cap-alsi10mg-f0-0001.md) | AlSi10Mg for screening | undecided | functional |

*41 records, 23 of them prohibited pending engineering, none released. Each link opens the part's description page in [`docs/pieces/`](docs/pieces/), generated from its `catalog/parts/*.json` record; the design dossiers are in [`docs/993/`](docs/993/). Table generated by `scripts/render_parts_table.py`, checked by `make check`.*

<!-- parts:end -->

## 3. Engine cooling

Two programmes, kept separate
([docs/FAN_DEVELOPMENT_PROGRAMMES.md](docs/FAN_DEVELOPMENT_PROGRAMMES.md)):
the **upright 993 fan** behind the engine, and the **935-type horizontal fan**
lying on top of it.

| programme | where it stands | start here |
|---|---|---|
| 993 upright fan, F1 impeller | redesigned from the visual rebuild of the original Turbo rotor: same cup, windows and envelope, airfoil blades, WE43. On a duty inferred from the rebuild: +2 % air at equal power, +9 % with a matched stator. Print simulation passes. | [impeller dossier](docs/993/993_COOLING_IMPELLER_WE43_F1.md) · [stator](docs/993/993_FAN_STATOR_ALSI10MG_F1.md) |
| 993 fan system and CFD | reference rebuild, organic blade studies, mesh recovery and CFD campaigns, OpenUSD twin; no installed-airflow result yet | [system twin](twins/993-engine-cooling-fan-system-f0/README.md) · [latest results and open gates](twins/993-engine-cooling-fan-system-f0/program/ENGINEERING_RESULTS_20261003.md) |
| 935 horizontal fan | multilingual source research, CAD reconstruction, assembly S1, D2/D3 CFD diagnostics | [935 system](twins/935-horizontal-cooling-system/README.md) · [reconstruction](models/horizontal-fan-reconstruction/README.en.md) · [S1 assembly and manufacturing](models/horizontal-fan-reconstruction/ASSEMBLY_MANUFACTURING_S1.en.md) |
| fan alloys | aluminium, WE43 and Ti64 compared on the same rotor: mass, inertia, centrifugal stress | [alloy comparison](twins/fan-alloy-comparison-f0/README.en.md) |

No fan gain is claimed over the Porsche part: its performance is not
published, and every comparison here is against a rebuild or a synthetic
reference.

## 4. Engine and turbo research

- **M64/60 (993 Turbo)**: whole-engine bill of materials
  ([`m64-bom-v1.json`](twins/m64-engine-system/bom/m64-bom-v1.json),
  [coverage](twins/m64-engine-system/bom/coverage.md)) and a dated series of
  cylinder-head, valvetrain and meshing reports in
  [docs/reports/](docs/reports/README.md).
- **Four-valve cylinder head**: [air + oil study](docs/studies/993-air-oil-20261002/README.md).
- **K16 and hybrid turbos**: [2 October research](docs/research/993-turbo-20261002/README.md),
  [Mezger variants and materials](docs/research/mezger-turbo-materials-20261003/README.md),
  [German-source supplement](docs/research/mezger-german-sources-20261003/README.md).
- **Local compute**: [architecture](docs/architecture/README.md) and
  [local Qwen training](training/m64-qwen/README.md).

## 5. Body and interior

**Bolt-on** panels (fenders, lids, spoiler, doors) are a legitimate target;
the load-bearing structure is not. The factory catalogue draws the line in part
numbers: [docs/research/993-964-panneaux-carbone.md](docs/research/993-964-panneaux-carbone.md).

Those panels can already be ordered from several tuners, so the part chosen is
the one nobody sells: the **dashboard trim**, `993-INT-DASHBOARD-TRIM-0001`,
restricted to vehicles **without a passenger airbag**. On the others it
carries the deployment flap, which makes it an occupant-restraint part. Its
[measurement plan](parts/993-int-dashboard-trim-0001/evidence/measurement-plan.md)
opens with an entry gate that can stop the project.

## 6. The catalogue and its data contract

**527 source records** qualified by provenance, rights and level of evidence;
41 part records, 10 twin records, 4 components, 2 assemblies and 3 workshop-manual
transcriptions. Everything is validated by a JSON schema and by the test suite.

A record keeps technical access, reading method and reuse rights separate. An
accessible page is not redistributable; a page read in a browser is neither an
authorized download nor a validation of accuracy.

```mermaid
flowchart TB
    subgraph catalog["catalog/ — source of truth, JSON-schema validated"]
      direction LR
      src["sources/<br/>527 records"] --- prt["parts/<br/>41 records"]
      prt --- tw["twins/<br/>10 records"]
      prt --- cmp["components/ · assemblies/"]
      prt --- mea["measurements/<br/>3 manual transcriptions"]
    end
    prt -- "render_part_pages.py" --> pages["docs/pieces/<br/>one page per part"]
    prt -- "render_parts_table.py" --> table["README parts table"]
    tw --> twins["twins/&lt;zone&gt;/<br/>CAD · analysis · evidence"]
```

---

## The rules

| rule | what it requires |
|---|---|
| **Source before STL** | FreeCAD, OpenSCAD, build123d, PicoGK or STEP remain the master formats |
| **Evidence before publication** | every claim of fit or accuracy is tied to a measurement or a source |
| **Digital before prototype** | the active phase manufactures nothing |
| **Interface before appearance** | a measured zone that allows a clearance check beats a full scan of unknown accuracy |
| **Explicit safety** | when in doubt, the part is lowered to `prohibited_pending_engineering`; see [SAFETY.md](SAFETY.md) |
| **No vendor harvesting** | a site closed to robots is not queried; see [decision 0003](docs/decisions/0003-no-vendor-harvesting.md) |
| **Accessible tools** | a free, open-source, local toolchain |

## What the repository withdrew from its own results

This is the most useful part of its history, and it is public.

Stiffness by architecture in linear and quadratic shells

| withdrawn claim | what defeated it |
|---|---|
| "the structure works in membrane shear" | a test decoupling `E` and `G`: the bare floor pan works in almost pure bending |
| "stiffness follows thickness exactly linearly" | the exponent is 1.00 with linear elements and **1.10** with quadratic ones: the exactness belonged to the element |
| "the windshield frame has the best return per kilogram" | in quadratic shells, it is the center tunnel |
| a cross member counted in the model's mass | a connectivity check: it was attached to nothing |
| eleven lost analysis cases, read as a near-singular system | a defect in the solver's partitioner, whose message went to `stderr` |
| the datum network's front cross-member mount P5 | plate 50-02 draws dimension P as longitudinal, not as a diagonal: P5 was 230 mm out, and the monocoque's governing span with it |
| a first F1 cooling impeller, generic and shrouded | next to a photo of the original it shared nothing, and it left no room for the alternator end the original cup wraps |
| +20 % fan airflow from that impeller | radial equilibrium, once modelled, put its hub section at de Haller 0.58 with a stalled station |

The figures on this page are regenerated from data kept in the repository:
`twins/964-chassis/fea/figures.py` for the charts and model views,
`twins/964-chassis/fea/hero.py` for the banner, from the torsion snapshot of
the monocoque shell kept in `twins/964-chassis/monocoque/derived/`. None of them is a rendering: they are the
calculation's data.

## What the project does not claim

- **No absolute stiffness value is a 964 stiffness.** The model's sections are
  `ASSUMED` and the mesh is not converged; only ratios and rankings are usable.
- **No part is validated.** The printable files above have not been checked on
  a car. All 41 records are at status `concept`, 23 of them
  `prohibited_pending_engineering`. No twin reaches the `F2_interface` level.
- **No physical measurement is recorded yet.** The three records in
  `catalog/measurements/` are transcriptions from the workshop manual, not
  instrumented measurements.
- **No fan gain over the Porsche part.** Its performance is not published.
- **A rendering or a simulation is not evidence of physical behavior**:
  neither Omniverse, nor an image, nor a print simulation.

## What is archived

The **917 cylinder head** dossier, 891 files from iteration F1 to F50, is
retired as a product and kept as a numerical regression, along with the 935
cylinder-head scan. It was not moved into an archive folder:
[ARCHIVE.md](ARCHIVE.md) explains that it carries 2,014 SHA-256 digests that
moving it would invalidate. Evidence beats tidiness.

---

## Quick start

Requirements: Python 3.11 or newer and `make`. Clone onto a native Linux file
system (on WSL, not under `/mnt/c`; see [AGENTS.md](AGENTS.md)).

```bash
git clone https://github.com/cluster2600/porscheparts.git
cd porscheparts
make help                 # active targets, grouped by theme
make check                # schemas, tests, generators and digests
```

To add a part:

```bash
cp catalog/templates/part-record.json catalog/parts/993-xxx-0001.json
# fill in the record, add licensed CAD files under parts/<part_id>/
make part-pages parts-table   # regenerate its page and the README table
make check
```

Conventions in detail: [CONTRIBUTING.md](CONTRIBUTING.md). The `917-*` targets
drive the archived line and are listed by `make help-917`. Tests that need
`numpy`, `matplotlib` or CAD kernels are skipped or fail without them; the
compute images in [`containers/`](containers/) carry the full stack, and the
CAD, print-simulation and rendering scripts run in the `cadsim` image.

## Repository layout

```text
catalog/            records: sources, parts, measurements, twins, components
  schemas/            the catalogue's data contract
  templates/          record, measurement and manufacturing-request templates
parts/              geometry, evidence, media and print files per part
components/         component geometry; assemblies/ holds their evidence
twins/              digital twins, one folder per zone; see twins/README.md
  964-chassis/        964 chassis: datum chain, CAD, FEA, corpus
  993-*/              993 functional zones
  m64-*/              M64 engine and cylinder-head twins
models/             reconstructions, e.g. the horizontal fan
docs/               plans, quality criteria, software chain; see docs/README.md
  993/                the 34 design dossiers of the 993 parts
  pieces/             one generated page per part record
  decisions/          numbered architecture decisions
  reports/            dated execution and audit reports, indexed by day
  research/           source research by topic
  media/              diagrams, banner and video projects
  GALLERY.md          every figure and render on one page
simulation/         CFD and forced-induction analysis cases
archive/917/docs/   the written dossiers of the 917 cylinder head
scripts/  tests/    automatic checks, generators and guardrails
containers/ deploy/ reproducible compute images and deployment
```

## Status

| phase | state |
|---|---|
| 0 — foundation | ✅ done |
| 1 — source inventory | 🟡 past its quantitative threshold; cross-qualification and direct measurements still open |
| 2 — physical inventory and twin assembly | 🟡 run in digital mode; physical prototypes suspended, except non-critical printable files (decisions 0009, 0010, 0011) |
| 3 — titanium engineering twin, no manufacturing | ⬜ open: candidate `993-ENG-CARRIER-0001` under study |
| 4 — public catalog | ⬜ open: only parts that clear their quality gates will be published |

Details and exit criteria: [ROADMAP.md](ROADMAP.md) ·
[docs/PROJECT_CHARTER.md](docs/PROJECT_CHARTER.md) ·
[docs/DIGITAL_TWIN.md](docs/DIGITAL_TWIN.md) ·
[docs/QUALITY_GATES.md](docs/QUALITY_GATES.md).

Sourced state of the 993 digital twin

*Sourced logical relationships of the 993 twin, not the actual position of
the components in the car.*

---

## Disclaimer

This repository provides research and manufacturing data without warranty.
Printing, fitting and road use remain the responsibility of whoever makes and
installs the part. Read [SAFETY.md](SAFETY.md) before any manufacturing.

Porsche and 911 are trademarks of their respective owners. This project is
independent and not affiliated with Porsche AG.

## License

**© 2026 Maxime Grenu. All rights reserved.** The repository is under a custom
[proprietary license](LICENSE): you may view it, but copying, modifying,
printing or manufacturing parts, redistributing, commercial use and AI training
all need prior written permission; ask by opening an issue. Third-party
sources and models keep their own license; see [LICENSES.md](LICENSES.md).
Revisions published before 2026-09-25 were under the MIT License.

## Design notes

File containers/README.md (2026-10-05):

# Compute images

Seven reproducible images for the work that does not fit on an ordinary
workstation. They are not needed to contribute to the catalogue.

| File | Image | Requirement |
|---|---|---|
| `recon.Dockerfile` | `3dprinting993-recon` | CUDA GPU: photos to mesh |
| `cadsim.Dockerfile` | `3dprinting993-cadsim` | CPUs: CAD, meshing, FE, CFD, slicing |
| `mesh-cfd.Dockerfile` | `3dprinting993-mesh-cfd` | CPUs and memory: scans, segmentation and CFD |
| `physicsml.Dockerfile` | `3dprinting993-physicsml` | CUDA GPU: CAD, differentiable FE and Physics ML |
| `simready.Dockerfile` | `3dprinting993-simready` | RTX GPU: OVRTX, Material/Physics Agents and USD validation |
| `simready-workflow.Dockerfile` | `3dprinting993-simready-workflow` | RTX GPU: SimReady image, CAD preflight and verified Vast.ai startup |
| `simready-local-ai.Dockerfile` | `3dprinting993-simready-local-ai` | 48–80 GB GPU: SimReady, local Qwen VLM and PhysicsNeMo with no inference API |

```mermaid
flowchart LR
  subgraph CPU["CPU hosts"]
    cadsim["3dprinting993-cadsim"]
    meshcfd["3dprinting993-mesh-cfd"]
  end
  subgraph GPU["GPU hosts"]
    recon["3dprinting993-recon"]
    physicsml["3dprinting993-physicsml"]
    simready["3dprinting993-simready"]
    workflow["3dprinting993-simready-workflow"]
    localai["3dprinting993-simready-local-ai"]
  end
  cadsim --> W1["CAD, meshing, FE,<br/>CFD, slicing"]
  meshcfd --> W2["scans, segmentation, CFD"]
  recon --> W3["photos to mesh"]
  physicsml --> W4["differentiable FE,<br/>Physics ML"]
  simready --> W5["OVRTX, Material/Physics<br/>Agents, USD validation"]
  workflow --> W6["CAD preflight,<br/>verified Vast.ai startup"]
  localai --> W7["local Qwen VLM,<br/>PhysicsNeMo, no inference API"]
```

Every embedded tool runs without a graphical interface, so that a script can
replay a complete chain identically.

```bash
make container-cadsim
make container-smoke
make container-physicsml
make container-smoke-physicsml
make container-simready
make container-simready-workflow
make container-simready-local-ai
make container-smoke-simready
make container-smoke-simready-workflow
make container-smoke-simready-local-ai
```

`simready` is deliberately a single container. Vast.ai already runs the image
in an unprivileged container and does not allow Docker-in-Docker. OVRTX,
Material Agent and Physics Agent are therefore installed in separate Python
environments and launched directly by Supervisor. No secret is included in the
image: `simready-services start` refuses to start before the OpenBao wrapper has
installed `/workspace/secrets/nvidia.env`. It then runs
`simready-nvidia-auth-check`: a minimal call to the configured model must
succeed before OVRTX and the agents are launched, so as not to pay for a render
bound to end on an authorization error.

```mermaid
flowchart TD
  A["simready-services start"] --> B{"/workspace/secrets/nvidia.env<br/>installed by the OpenBao wrapper?"}
  B -- no --> X["refuses to start"]:::stop
  B -- yes --> C{"simready-nvidia-auth-check:<br/>minimal model call succeeds?"}
  C -- no --> Y["no render launched"]:::stop
  C -- yes --> D["OVRTX, Material Agent,<br/>Physics Agent under Supervisor"]:::ok
  classDef stop fill:#fde2e1,stroke:#c0392b,color:#1a1a1a;
  classDef ok fill:#e3f1e6,stroke:#2e7d32,color:#1a1a1a;
```

The `simready-workflow` image embeds `simready-vast-onstart`. This script fixes
the permissions of the `authorized_keys` file injected by Vast.ai, checks the
GPU and the SimReady runtime, then creates `/workspace/READY`. The OpenBao
wrapper can therefore call this script instead of copying a shell sequence that
could drift.

The validation environment includes Pillow: OVRTX renders can thus fail
automatically when a PNG is empty or uniform, instead of only validating that a
file exists. The smoke test blocks publication if this pixel inspection is not
available.

`simready-profile-validate <asset.usd> --profile <name> --version <version>`
adds the paths of the SimReady rules, functions and profiles installed in the
image. This wrapper prevents a profile that is present from being wrongly
reported as unregistered.

`simready-local-ai` embeds the vLLM runtime, PhysicsNeMo 2.2.0 and an immutable
snapshot of `Qwen/Qwen2.5-VL-7B-Instruct`. Material Agent and Physics Agent both
use `http://127.0.0.1:8000/v1`: no NVIDIA key and no remote inference API is
needed. The vLLM wheel is CUDA 12.9; its process prepends NVIDIA's immutable
`cuda-compat-12-9` package to its library path so it can be checked on the
reviewed r570/CUDA 12.8 Vast offer. The startup gate still requires a real GPU
run: NVIDIA reports errors 803 or 804 when the provider driver or GPU cannot
use forward compatibility. The weights add about 16.6 GB to the image; this
variant is therefore reserved for rentals with 500 GB of disk and at least 48 GB
of VRAM, 80 GB being preferable so that OVRTX and the solvers can coexist.

This image combines components under distinct licenses. The NVIDIA CAD
converter remains subject to its own Omniverse license and must not be presented
as a free component, even though the repository's orchestration is.

`physicsml` bundles JAX-FEM, PhysicsNeMo and DeepXDE with the
geometry/meshing/FE tools of `cadsim`. The PhysicsNeMo GNN extra is disabled by
default to keep a build reproducible across several architectures; enable it
with `--build-arg PHYSICSNEMO_EXTRAS=cu12,sym,mesh-extras,model-extras,gnns`.

`examples/cad_to_fea.py` runs the complete chain — parametric solid, STEP,
tetrahedral mesh, CalculiX analysis — without a single graphical interaction.
That is the useful check: a tool that answers `--version` proves nothing.

`smoke-test.sh` fails if an announced tool does not respond; `entrypoint.sh`
makes the container environment visible in sessions injected by a host;
`provision-vastai.sh` installs on demand what is too heavy for the image.

Deployment, costs and data hygiene:
[../docs/COMPUTE_ENVIRONMENT.md](../docs/COMPUTE_ENVIRONMENT.md).
Rationale for the software choices:
[../docs/decisions/0002-scriptable-toolchain.md](../docs/decisions/0002-scriptable-toolchain.md).

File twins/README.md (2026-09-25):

# Digital twins

Each directory below holds the code, contracts and evidence of one digital twin
or one twin workstream. Records live in `catalog/twins/*.json` where one exists;
files under any `evidence/` directory are pinned by SHA-256 digest and never
edited. No twin here releases a part: each page and record states its own
fidelity level and limits. The method, the fidelity levels and the overall state
are in [docs/DIGITAL_TWIN.md](../docs/DIGITAL_TWIN.md).

## Directories

| directory | what it is | source of the line |
|---|---|---|
| [`964-chassis/`](964-chassis/README.md) | 964 floor pan and body-shell frame, steel; `F1_envelope`, with the torsion shell FEA under [`fea/`](964-chassis/fea/README.md) | README, `TWIN-964-CHASSIS-FLOOR-0001` |
| [`993-cabin-dashboard-switch-0001/`](993-cabin-dashboard-switch-0001/) | functional zone of the dashboard switch cover; `F0_reference` | `TWIN-993-CABIN-DASH-SWITCH-0001` |
| [`993-door-opener-lever-alsi10mg-f0/`](993-door-opener-lever-alsi10mg-f0/) | 993 interior door opener lever in AlSi10Mg; `F1_envelope` | `TWIN-993-DOOR-OPENER-LEVER-ALSI10MG-F0` |
| [`993-engine-cooling-fan-system-f0/`](993-engine-cooling-fan-system-f0/) | 993 engine cooling fan housing and impeller subassembly; `F1_envelope` | `TWIN-993-ENGINE-COOLING-FAN-SYSTEM-F0` |
| [`993-exhaust-tip-ti-f0/`](993-exhaust-tip-ti-f0/) | evidence for the titanium F1 variant of the oval exhaust tip (Ti-6Al-4V and Ti-6242 routes, LPBF screen) | part record `993-EXH-OVAL-TIP-TI-F1-0001` |
| [`993-headlamp-spring-hook-alsi10mg-f0/`](993-headlamp-spring-hook-alsi10mg-f0/) | 993 headlamp spring repair hook in AlSi10Mg; `F1_envelope` | `TWIN-993-HEADLAMP-SPRING-HOOK-ALSI10MG-F0` |
| [`993-intercooler-bracket-ti-f0/`](993-intercooler-bracket-ti-f0/) | 993 Turbo/GT2 intercooler bracket in titanium; `F1_envelope` | `TWIN-993-INTERCOOLER-BRACKET-TI-F0` |
| [`993-m64-60-piston-gallery-f0/`](993-m64-60-piston-gallery-f0/) | M64/60 CP1 piston with closed oil gallery; `F1_envelope` | `TWIN-993-M64-60-PISTON-GALLERY-F0` |
| [`993-oval-exhaust-tip-in625-f0/`](993-oval-exhaust-tip-in625-f0/) | 993 oval exhaust tip in IN625; `F1_envelope` | `TWIN-993-OVAL-EXHAUST-TIP-IN625-F0` |
| [`993-reference-envelope/`](993-reference-envelope/README.md) | parametric bounding cage of the 993 USA profile from seven manual dimensions; not the body | README |
| [`993-switch-trim-ring-f1/`](993-switch-trim-ring-f1/) | switch trim ring F1 reconstruction: LPBF screen, supplier and turning routes; the route concluded it must be turned, not sintered | part record `993-INT-SWITCH-TRIM-RING-F1-0001` |
| [`engine-simulation-contracts/`](engine-simulation-contracts/README.md) | F1 register of engine components, interfaces, candidate materials and load cases; every simulation case blocked | README |
| [`m64-cylinder-head/`](m64-cylinder-head/README.md) | M64 cylinder head work: code, records and receipts; no validated cylinder head | README |
| [`m64-engine-twin/`](m64-engine-twin/) | GPU session manifest of 2026-09-15 for the agent-driven M64 engine twin; manufacturing not authorized | `session-20260915.json`, [deploy page](../deploy/vast/engine-twin/README.md) |
| [`omniverse-engine-assembly/`](omniverse-engine-assembly/README.md) | F0 OpenUSD scenes composing the 917 scan and the 935 valvetrain rig; not a single-engine assembly | README |
| [`reference-917-engine/`](reference-917-engine/README.md) | **archived** — Porsche 917 engine reference twin, iterations F1 to F50 | README, [ARCHIVE.md](../ARCHIVE.md) |
| [`reference-935-cylinder-head/`](reference-935-cylinder-head/README.md) | **archived** — Wolfe Classics 935 cylinder-head scan, reference morphology | README, [ARCHIVE.md](../ARCHIVE.md) |

The catalog also holds `TWIN-993-WHEEL-HUB-INTERFACES-0001` (Fuchs wheel and hub
nominal interfaces), which has no directory under `twins/`.

## Map by vehicle zone

Groupings follow the `scope.zone` of each record and what each README says it
covers.

```mermaid
flowchart LR
  subgraph BODY["Body shell and envelope"]
    C964["964-chassis"]
    ENV["993-reference-envelope"]
  end
  subgraph INT["Interior"]
    DASH["993-cabin-dashboard-switch-0001"]
    DOOR["993-door-opener-lever-alsi10mg-f0"]
    RING["993-switch-trim-ring-f1"]
  end
  subgraph LIGHT["Lighting"]
    HOOK["993-headlamp-spring-hook-alsi10mg-f0"]
  end
  subgraph EXH["Exhaust"]
    TIP["993-oval-exhaust-tip-in625-f0<br/>993-exhaust-tip-ti-f0"]
  end
  subgraph ENG["Engine, intake and cooling"]
    FAN["993-engine-cooling-fan-system-f0"]
    IC["993-intercooler-bracket-ti-f0"]
    M64["993-m64-60-piston-gallery-f0<br/>m64-cylinder-head<br/>m64-engine-twin"]
    SIM["engine-simulation-contracts<br/>omniverse-engine-assembly"]
  end
  subgraph ARC["Archived"]
    REF["reference-917-engine<br/>reference-935-cylinder-head"]
  end
  classDef stop fill:#fde2e1,stroke:#c0392b,color:#1a1a1a;
  class REF stop;
```

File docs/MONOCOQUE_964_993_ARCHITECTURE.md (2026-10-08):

# 964/993 monocoque — architecture concept and layup strategy

Status: **concept**. No geometry, no part dimension, no executable layup.
`prohibited_pending_engineering` class unchanged.

This document contains the design work that **depends on no unknown in the
datum network** — topology, load paths, ply orientation — and which could
therefore be done before the jig bench survey. The interfaces, for their part,
are declared as parameters in `twins/964-chassis/source/monocoque_interface.py`.

## 1. What the monocoque must do, according to our own measurements

`twins/964-chassis/fea/README.md` establishes three things that drive the form.

**Stiffness follows thickness linearly, not its cube** (1.251 for 1.250).
That rules out plate bending, but NOT thin-walled beam bending: see section
3bis, where the measurement shows that the floor pan alone works in bending and
not in shear, contrary to what the dossier claimed.

**What pays is closing the rings, not the material.** From the bare floor pan to
the closed cell, K x 3.7. But the windshield frame, 1.1 kg, returns 172 to 191
times more per kilogram than the roof, 10.5 kg; and the B-pillars added alone,
with nothing to close the front, return zero for 7.5 kg.

**Carbon is the weak lever.** x 1.25 at equal mass, against x 1.51 for closing
the box section.

Design conclusion: **a monocoque is not a carbon body shell, it is a body shell
whose rings are closed by construction.** The material comes after. That is
also what makes the concept defensible against ZESAD without access to their
product: the argument is structural, not commercial.

## 2. The rings, in order of return

The architecture is defined as a set of closed rings connected by longitudinal
beams. Order established by `ring_study.py` and `body_study.py`:

| ring / element | function | measured return |
|---|---|---|
| windshield frame | closes the cell at the top front | **the highest in the whole model** |
| center tunnel or equivalent longitudinal beam | connects the two end rings | +71 % on its own |
| wheel arches | extend the side rail upward at the ends | high |
| front bulkhead and rear bulkhead | close the box section at the ends | medium |
| B-pillars and sills | only worth anything if a ring closes | zero in isolation |
| roof | fills a surface already carried | near zero |

Two consequences that run against the "monocoque = shell" intuition:

- **the roof is not a structural part** at this load level. It can be thin,
  removable, or glazed, without notable loss of torsional stiffness. That is a
  design freedom, and it is free;
- **the B-pillars are not sized in isolation.** They only serve as the upright
  of a closed ring. A massive B-pillar without a windshield frame is dead mass,
  measured as such.

**Caveat.** The model that produces this ranking has no bonded glazing, no
doors, and no panel openings. All three absences flatter the closed ring. The
ranking is robust — verified at three mesh densities — but the ratios are less
so than the order.

## 3. The layup: result corrected after verification

**A first version of this section announced a x 1.75 gain for a +/-45 layup.
That number is wrong and it is withdrawn.** It held as an analytical prediction
— a +/-45 stack does give 1.75 times the shear modulus of a quasi-isotropic one
— but the assumption that carried it to the body shell, "this structure works
in shear", turned out to be false. See section 3bis.

Finite element calculation is now possible: `run_fea_laminate.py` solves a real
multilayer laminate (`*SHELL SECTION, COMPOSITE`, one `*ORIENTATION` per ply and
per panel family). The chain is validated on an analytical case — uniaxial
tension on a UD ply, `verify_laminate_shear.py` and the uniaxial check — which
gives back E1 at 0 degrees, E2 at 90 and the off-axis value at 45, to within
3 %.

Same mass, eight 0.4 mm plies, same boundary conditions:

| stack | floor pan alone (open) | closed cell |
|---|---|---|
| quasi-isotropic | 1586 | 6311 |
| **+/-45** | 696 (**0.44x**) | **6849 (1.09x)** |
| 0/90 | 1910 (1.20x) | 4043 (0.64x) |

**The ranking reverses between the open architecture and the closed
architecture.** On the floor pan alone, +/-45 loses more than half the
stiffness. On the closed cell it gains, but by 9 % — not by 75 %.

What this means for the layup:

- **there is no universally good stack** for this body shell. A ply is only good
  relative to the load path of the panel that carries it;
- **+/-45 dominant only in panels genuinely in shear** — side-rail webs of a
  closed section, bulkhead webs — and only once the rings are closed;
- **0/90 where the load is axial**: side-rail flanges, edges, bending paths,
  surroundings of hard points;
- **quasi-isotropic remains a reasonable default compromise**, which is a result
  in itself: it is not the bad setting this section used to claim.

Zoned layup remains the real process lever, but its gain is counted in tens of
percent, not in factors, and it requires knowing the load path panel by panel —
which the current model does not resolve.

## 3bis. This body shell does not work in shear, except once closed

The dossier claimed "box section in membrane shear, the criterion is `G/rho`
and not `E/rho`". That claim rested on two observations, neither of which
demonstrates it:

- stiffness follows thickness linearly and not its cube. That rules out
  **plate** bending, but not bending of a **thin-walled beam**, whose second
  moment of area also varies linearly with thickness;
- the iso-stiffness prediction when changing material landed at 6.9 %. But all
  the materials compared were isotropic, hence `G` proportional to `E`: that
  check cannot, by construction, distinguish one from the other.

`dominance_study.py` settles it by varying `E` and `G` **separately**, with a
fictitious orthotropic material in which the two are decoupled:

| architecture | double E | double G | mechanism |
|---|---|---|---|
| floor pan, side rails, crossmembers | **+93.8 %** | +2.1 % | bending, near pure |
| closed cell | +37.7 % | **+56.9 %** | shear dominant, but mixed |

**The floor pan alone does not work in shear at all.** In torsion, its two side
rails bend in opposite directions: they are two cantilevers, and the criterion
there is `E`. Shear only appears once the rings are closed, and it never becomes
exclusive.

It is the same discovery as ring closure, seen from the other end: **closing a
ring does not just add stiffness, it changes the mechanism that carries it.**
And that explains exactly the reversal in the layup table above.

Consequence for the material conclusions: for the floor pan alone, the
criterion is `E/rho`, not `G/rho`. The carbon > aramid ranking is not affected,
since carbon dominates on both criteria.

## 4. The question of the steel windshield frame

ZESAD sells a "monocoque with steel windshield frame" configuration. Our own
ranking puts the windshield frame first in return. Three possible readings, not
mutually exclusive, none confirmed:

1. **structural**: it is the most loaded ring, and a laminate handles
   concentrated loads and glass bonding poorly there;
2. **process**: the aperture requires a shape accuracy that large-format
   composite holds with difficulty without re-machining;
3. **vehicle identity**: retaining an original element can serve the
   homologation route, see `MONOCOQUE_964_993_PROGRAMME.md` section 7.

This question must be settled early: it changes the nature of the product, its
tooling and probably its regulatory dossier. It is settled by reading 3 first,
which is legal and cheap.

## 5. What remains undetermined, and what unblocks it

| undetermined | unblocked by |
|---|---|
| suspension and engine interface positions | jig bench survey (M1) |
| P5 -> P12 spacing, front axle crossmember support -> gearbox crossmember support (not the wheelbase) | jig bench survey (M1) |
| absolute stiffness target | torsion test on a donor body shell (M2) |
| load path panel by panel, to zone the layup | model with real sections, not available |
| load introduction at hard points | vehicle load model, not started |
| crashworthiness | physical tests, not substitutable |

## 6. What this document is not

- It is not a design: no dimension, no thickness, no stacking sequence.
- The x 1.75 announced in the first version was wrong: see section 3.
- The ring ranking comes from a model with `ASSUMED` sections that is not
  mesh-converged. Only the order and the orders of magnitude are usable.
- Nothing here concerns crashworthiness, strength, delamination, buckling,
  fatigue or fire.

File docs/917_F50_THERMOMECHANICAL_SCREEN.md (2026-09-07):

# F50 — criblage thermo-mécanique comparatif 2V / 4V

## Verdict

La campagne F50 a réellement exécuté **18 jobs CalculiX 2.21** sur six
maillages Gmsh : trois niveaux pour la version 2 soupapes et trois pour la
version 4 soupapes. Les trois indicateurs de convergence du couple
medium/fin passent pour les deux architectures.

Le résultat d'ingénierie reste néanmoins **rouge**. Au maillage fin, les deux
témoins dépassent 300 °C et leur contrainte thermo-élastique p95 dépasse même
la limite d'élasticité CP1 publiée à température ambiante. Une limite ambiante
n'est pas une limite admissible à chaud; elle n'est utilisée ici que comme
alarme optimiste.

Cette campagne n'est pas une FEA de culasse complète. Le maillage volumique de
la peau F43 est privé et n'est pas publié. F50 refuse donc de le remplacer par
une enveloppe inventée. Le domaine calculé est seulement un **témoin local
circulaire du pont de chambre**, à l'intérieur du bore de 90 mm, percé des
sections fonctionnelles circulaires F47. La peau extérieure F43 n'est ni
chargée, ni modifiée, ni approximée. Aucun ovale, aucune ellipse et aucun
redimensionnement anisotrope ne sont utilisés.

## Entrées verrouillées

Le contrat
[`thermomechanical-screen-f50.json`](../twins/reference-917-engine/thermomechanical-screen-f50.json)
verrouille par SHA-256 :

- le rapport de peau externe F43, dont on reprend uniquement l'aire totale
  publique et non la géométrie privée ;
- les architectures et sections circulaires F45/F47 ;
- une trace F46 complète par architecture, `Cd=0,72` et pas de vilebrequin
  `0,25°` ;
- le criblage matériau/process F49.

La F50 ne forme jamais une histoire de charge avec l'enveloppe point par point
F47. Chaque variante conserve l'identité d'une trajectoire F46 complète.

## Modèle mathématique

### Charges d'un cycle

Pour chaque trace complète, la pression mécanique est :

\[
p_g = \max_\theta p_{abs}(\theta)-101\,325\quad [\mathrm{Pa}].
\]

Le flux stationnaire du criblage est la moyenne signée sur les 720 degrés :

\[
\bar q = \frac{1}{720^\circ}\int_0^{720^\circ}q_w(\theta)\,d\theta.
\]

Le temps physique de la trace reste défini par :

\[
t=\frac{\theta}{6N},\qquad N=9\,000\ \mathrm{tr/min}.
\]

| Entrée F46 | 2V | 4V |
|---|---:|---:|
| Pression de pointe absolue | 20,139 MPa | 21,902 MPa |
| Pression de pointe relative | 20,038 MPa | 21,800 MPa |
| Flux moyen signé | 1,085 MW/m² | 1,149 MW/m² |
| Flux instantané maximal | 12,119 MW/m² | 13,028 MW/m² |

### Conduction

CalculiX résout sur le témoin :

\[
\nabla\cdot(k\nabla T)=0,
\]

avec `k = 187 W/(m·K)`, seule valeur CP1 publique de F49. Elle est maintenue
constante alors qu'elle n'est documentée qu'à température ambiante; la porte
« carte chaude » reste donc fermée.

La face chambre reçoit `q̄`. Les faces supérieure et périphérique reçoivent
une condition de Robin. Comme le témoin local omet les ailettes, la conductance
globale hypothétique est conservée par :

\[
h_{eq}=h_{air}\frac{A_{F43}}{A_{témoin}},
\]

avec `h_air = 250 W/(m²·K)`, `T_air = 80 °C` et
`A_F43 = 112 256,35 mm²`. Ce choix est une hypothèse de sensibilité et non une
CHT. Le bilan est contrôlé par :

\[
\varepsilon_Q=\frac{|Q_{entrée}-Q_{film}|}{|Q_{entrée}|}\le 2\%.
\]

### Structure

Le calcul C3D4 linéaire utilise :

\[
\nabla\cdot\boldsymbol\sigma=0,
\qquad
\boldsymbol\sigma=\mathbf C:
(\boldsymbol\varepsilon-\alpha(T-T_0)\mathbf I).
\]

Les hypothèses `E = 70 GPa`, `ν = 0,33` et
`α = 23×10⁻⁶ K⁻¹` ne proviennent pas d'une carte CP1 qualifiée F49. La rive
circulaire est encastrée; cette condition représente la continuité locale avec
la culasse et tend à majorer les contraintes thermiques. Le contact des sièges,
la précharge des goujons, la plasticité, le fluage et la relaxation ne sont pas
modélisés.

La contrainte équivalente publiée est :

\[
\sigma_{vm}=\sqrt{\frac12[(\sigma_1-\sigma_2)^2+
(\sigma_2-\sigma_3)^2+(\sigma_3-\sigma_1)^2]}.
\]

Le p95 principal exclut une bande fixe de 5 mm au voisinage de l'encastrement,
tout en conservant les maxima bruts dans le rapport.

### Proxy de fatigue

Faute de courbes HCF, LCF et TMF à chaud, F50 ne calcule ni durée de vie ni
dommage de Miner. Le seul indicateur est une demi-amplitude élastique
relâché-froid vers chargé-chaud :

\[
\sigma_a=\frac{\Delta\sigma_{vm}}{2},
\qquad
P_{SWT}^{*}=\frac{\sigma_a^2}{E}.
\]

Cet indicateur sert à comparer les architectures; son unité en MPa ne doit pas
être interprétée comme un critère de durée de vie.

## Résultats CalculiX

| Maillage | Variante | Tétraèdres | Tmin qualité | Tmax | p95 thermo-pression | Umax |
|---:|:---:|---:|---:|---:|---:|---:|
| 5,0 mm | 2V | 3 731 | > 0,38 | 382,87 °C | 777,98 MPa | 0,1926 mm |
| 3,5 mm | 2V | 10 164 | > 0,38 | 382,55 °C | 777,20 MPa | 0,1914 mm |
| 2,5 mm | 2V | 26 154 | 0,3895 | 382,48 °C | 769,46 MPa | 0,1973 mm |
| 5,0 mm | 4V | 3 809 | > 0,38 | 397,72 °C | 808,50 MPa | 0,1739 mm |
| 3,5 mm | 4V | 10 389 | > 0,38 | 397,31 °C | 786,76 MPa | 0,1796 mm |
| 2,5 mm | 4V | 25 864 | 0,3820 | 396,65 °C | 775,12 MPa | 0,1812 mm |

À pression seule sur la maille fine, le p95 vaut 53,54 MPa en 2V et
65,99 MPa en 4V. Le saut vers environ 770–775 MPa vient donc surtout de
l'expansion thermique empêchée par l'encastrement du témoin; il ne doit pas
être transposé tel quel à la culasse sans interfaces et contacts réels.

| Convergence medium → fin | Limite | 2V | 4V | Statut |
|---|---:|---:|---:|:---:|
| Tmax | 2 % | 0,0196 % | 0,1668 % | passe numérique |
| contrainte p95 | 10 % | 0,996 % | 1,479 % | passe numérique |
| Umax | 5 % | 2,996 % | 0,887 % | passe numérique |

Sur la maille fine, la 4V est plus chaude de 3,70 %, a un p95 supérieur de
0,74 %, un déplacement maximal inférieur de 8,14 % et un proxy SWT supérieur
de 1,48 %. Les deux variantes échouent néanmoins les écrans 300 °C et limite
d'élasticité ambiante.

## Reproduction

Le solveur ne détruit jamais un résultat existant. Il faut choisir un dossier
`work/` neuf :

```bash
make 917-thermomechanical-f50
make 917-thermomechanical-f50-publish
make 917-thermomechanical-f50-check
```

Le mode `solve` conserve localement les `.msh`, `.inp`, `.dat`, `.frd` et
`.npz`. Ils ne sont pas publiés. Le mode `publish` produit seulement le rapport
agrégé, les images de champs du témoin et leur manifeste :

- [`rapport agrégé`](../twins/reference-917-engine/evidence/f50-thermomechanical/thermomechanical-screen-report.json) ;
- [`champ 2V`](../twins/reference-917-engine/evidence/f50-thermomechanical/f50-local-deck-2v-fields.png) ;
- [`champ 4V`](../twins/reference-917-engine/evidence/f50-thermomechanical/f50-local-deck-4v-fields.png) ;
- [`convergence`](../twins/reference-917-engine/evidence/f50-thermomechanical/f50-local-deck-mesh-convergence.png) ;
- [`manifeste`](../twins/reference-917-engine/evidence/f50-thermomechanical/manifest.json).

## Ce qui bloque une validation de culasse

La convergence numérique du témoin ne ferme aucune des portes suivantes :

1. maillage solide complet lié à la même peau F43 pour 2V et 4V ;
2. surfaces chambre, ailettes, sièges, guides et goujons vérifiées sur la CAO ;
3. carte CP1 dépendante de la température avec plasticité, fluage et
   relaxation, issue des coupons du procédé exact ;
4. contacts, interférences de sièges/guides, précharges et cycle transitoire ;
5. CHT corrélée, thermocouples, pression cylindre et fatigue TMF ;
6. CT/CND, étanchéité, banc de flux et banc moteur.

En conséquence, `manufacturing_authorized`, `metal_print_authorized` et
`engine_start_authorized` restent explicitement `false`.

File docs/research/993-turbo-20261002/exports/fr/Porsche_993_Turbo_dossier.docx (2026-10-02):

# Porsche 993 Turbo — moteur M64/60

Recherche documentaire — 2 octobre 2026

# Objet et résultat

Le moteur recherché est le six cylindres boxer 3,6 litres biturbo refroidi par air de la Porsche 993 Turbo, identifié M64/60. La référence principale est la version 300 kW / 408 ch et 540 Nm. La recherche a croisé les deux dépôts cluster2600, la brochure Porsche de lancement, le PET Porsche, des bulletins de service et le catalogue BorgWarner. Les données 430 et 450 ch sont séparées. Le terme Mezger situe la filiation ; pour retrouver les documents, M64.60 et 911 Turbo (993) sont plus précis.

# Comment lire les preuves

« Usine vérifié » signifie que le document Porsche a été ouvert et la valeur localisée. « Architecture recoupée » désigne une correspondance mécanique ou de catalogue, avec une limite de variante explicite. Les déclarations vendeur décrivent un article précis. Les calculs sont dérivés des données et ne sont pas des mesures. Les références existantes non relues gardent leur statut. Aucune nuance de fabrication n’est inventée pour combler une absence.

# Couverture et limites

Le registre contient 164 entrées, 84 références documentaires, 15 points d’audit et 19 familles à documenter. Les 2496 enregistrements déjà présents dans le registre manuel Carrera restent dans leur corpus d’origine ; ils ne sont pas recopiés dans cet export public. Ces occurrences OCR ne sont pas des données Turbo validées. La recherche n’a pas obtenu le manuel complet spécifique M64/60, les plans OEM ni les cartes de vitesse des K16. Les moteurs de recherche généralistes ont renvoyé des challenges ou des résultats inutilisables ; la recherche s’appuie donc surtout sur les archives et documents directement accessibles. Une exhaustivité absolue n’est pas revendiquée.

# Résultats à retenir

Turbo 408 ch : 100 × 76,4 mm, 3 600 cm³, compression 8,0:1 ; 300 kW à 5 750 tr/min ; 540 Nm à 4 500 tr/min ; deux K16 en parallèle, pression maximale publiée 0,8 bar. Allumage simple, six bougies. Porsche annonce +15 % de vitesse du ventilateur, sans ratio absolu dans la brochure. Le rapport alternateur/vilebrequin 2,68:1 est explicitement confirmé par un bulletin.

# Disposition et flux

L’air filtré est mesuré, réparti vers les deux compresseurs K16, refroidi dans les circuits air-air et admis dans les cylindres. Les gaz de chaque banc passent par la turbine correspondante et la ligne d’échappement ; les wastegates intégrées limitent l’énergie turbine. L’air de refroidissement suit la grille d’aileron, l’échangeur, le ventilateur et les surfaces à ailettes avant d’être évacué sous la voiture. Les soupapes de bypass de l’admission et les wastegates ont des fonctions distinctes.

# Trois refroidissements à distinguer

L’air forcé évacue la chaleur des cylindres et culasses ; l’huile participe au refroidissement interne, notamment par les six gicleurs longs sous pistons ; les échangeurs air-air abaissent la température de charge. Il n’y a pas de circuit de refroidissement moteur à eau comme sur une 996/997. La brochure précise des choix d’aluminium, de magnésium et de composites pour le système, sans attribuer une nuance à chaque référence.

# Ce qui tourne et ce qui oscille

Le vilebrequin et la partie primaire du volant tournent au régime moteur. Les arbres à cames d’un quatre temps tournent à la moitié de ce régime. L’arbre intermédiaire est décrit à mi-régime dans l’architecture M64 ; l’allumeur simple se calcule à mi-régime pour distribuer les six combustions sur 720°. L’alternateur tourne à 2,68 fois le moteur dans la configuration du bulletin, hors glissement. Les pistons ne tournent pas : leur vitesse est alternative. Les bielles combinent translation et oscillation. Un rotor K16 relie turbine et compresseur au même régime, mais son régime varie avec le débit, la pression et la charge ; il n’est pas proportionnel au vilebrequin.

# Matériaux : niveau de certitude

Le carter aluminium–silicium et les composants forgés sont documentés pour la famille M64 et recoupés par références communes du PET. Les nuances exactes Turbo restent non obtenues. Le Nikasil est explicitement décrit pour les cylindres Carrera dans la formation ; il faut une preuve liée au cylindre Turbo exact avant de transformer cette information en spécification OEM M64.60. Les soupapes d’échappement Turbo ont des références différentes de la Carrera. Les matériaux Ti-6Al-4V, AlSi10Mg LPBF, Inconel 625/718 ou aluminium 2618 proposés dans des projets et kits ne décrivent pas automatiquement les pièces Porsche d’origine.

# Refroidissement du ventilateur : pas de fausse précision

Le ratio environ 1,6:1 et le débit 1 010 L/s à 6 100 tr/min proviennent de la documentation Carrera. La Turbo a des références spécifiques d’impeller, carter et poulies ; la brochure annonce +15 %. Le produit 1,6 × 1,15 = 1,84 est une hypothèse de rapprochement, pas une valeur usine confirmée. Il est conservé dans le registre avec ce statut. Une cote extérieure de poulie ne suffit pas : le rapport dépend des diamètres primitifs et de la configuration des demi-poulies.

# Turbos : données obtenues et absentes

BorgWarner confirme la paire K16-6735 / K16-6736. TurboMaster permet de relier 6736 au gauche et 6735 au droit via les références Porsche et fournit des identifiants de roues, CHRA et carters. Le catalogue n’a pas fourni de carte compresseur K16 spécifique avec lignes de vitesse. Les 500 hp stock et 555 hp upgrade sont des limites commerciales. Les 950/980 °C du tableau ne constituent pas des températures métal ou des valeurs mesurées sur le K16 de série. Aucune vitesse de rotor, efficacité ou inertie K16 n’est présentée comme acquise.

# Calculs et conventions

Les calculs utilisent une course de 0,0764 m. Vitesse moyenne piston = 2 × course × n / 60. À 5 750 tr/min : 14,643 m/s ; AAC et allumeur : 2 875 tr/min ; alternateur : 15 410 tr/min. Avec 540 Nm et 3,6 L, BMEP = 4πT/V = 18,85 bar ; cette moyenne effective n’est pas la pression maximale de cylindre. Le volume résiduel calculé à 8:1 est 85,72 cm³ par cylindre, incluant toutes les contributions au volume au PMH. À ambiance 1,0 bar, 0,8 bar de boost donne 1,8 bar absolu. Le régime 6 500 tr/min du tableau est un exemple de calcul, pas une limite de régime attestée.

# Apport par rapport aux dépôts

Porschefanatics sépare déjà correctement les données de série de celles du kit MAHLE 3,8 L. Porsche Parts apporte un grand registre Carrera et des références vendeurs, mais certaines fiches mélangent les variantes ou citent un mauvais lien. L’audit joint documente les corrections proposées avec la preuve primaire. Les nouveaux liens d’archives sont des pistes de complément ; leur absence de l’intégralité de factory-literature.json n’a pas été démontrée, car ce gros fichier n’a pas été intégralement obtenu par le connecteur. Aucun dépôt n’a été modifié ni publié.

# Documentation prioritaire à obtenir ensuite

Le complément décisif est le manuel usine spécifique 911 Turbo (993) avec données M64.60 et bulletins par millésime. Le bulletin de calage confirme son existence et ses pages 15-7 à 15-18. Pour les matériaux et vitesses internes, les définitions MAHLE et BorgWarner par références OEM seront plus utiles qu’un article généraliste. Les essais doivent préciser charge, température, ambiance et configuration ; les documents d’homologation GT2 restent une variante différente. Les pistes FIA et articles SAE/ATZ/MTZ n’ont pas produit ici de document spécifique exploitable.

# Fichiers et traçabilité

Le tableur comprend Données moteur, Sources, Vitesses calculées, Audit, À documenter ; le contexte Carrera reste dans le registre manuel existant du dépôt. Le JSON permet l’intégration future en conservant application, statut, source et localisation. Les CSV sont séparés par points-virgules en UTF-8 avec BOM. Les PDF Porsche et les pages commerciales ne sont pas redistribués dans le paquet : les liens et les faits extraits sont fournis. Les documents originaux ont servi à la consultation locale.

# Registre technique

## Identité et géométrie

Paramètre | Valeur | Preuve et limites
Code moteur | M64.60 | Usine vérifié — S05 Index modèles PDF p.6 M64/60 — Turbo 408 ch M64/60 est l’identifiant usine utile ; « Mezger » désigne sa filiation technique.
Architecture | Boxer, six cylindres opposés | Usine vérifié — S01 PDF p.22 M64/60 — Turbo 408 ch
Cycle | 4 temps, essence | Usine vérifié — S01 PDF p.22 M64/60 — Turbo 408 ch
Nombre de cylindres | 6 | Usine vérifié — S01 PDF p.22 M64/60 — Turbo 408 ch
Bancs | 2 | Usine vérifié — S01 PDF p.22 M64/60 — Turbo 408 ch Comptage dérivé de la configuration publiée.
Cylindres par banc | 3 | Usine vérifié — S01 PDF p.22 M64/60 — Turbo 408 ch Comptage dérivé de la configuration publiée.
Alésage nominal | 100 mm | Usine vérifié — S01 PDF p.22 M64/60 — Turbo 408 ch
Course | 76.4 mm | Usine vérifié — S01 PDF p.22 M64/60 — Turbo 408 ch
Cylindrée publiée | 3600 cm³ | Usine vérifié — S01 PDF p.22 M64/60 — Turbo 408 ch
Rapport volumétrique | 8 à 1 | Usine vérifié — S01 PDF p.22 M64/60 — Turbo 408 ch
Soupapes par cylindre | 2 | Usine vérifié — S01 PDF p.22 M64/60 — Turbo 408 ch
Soupapes totales | 12 | Usine vérifié — S01 PDF p.22 M64/60 — Turbo 408 ch Comptage dérivé de la configuration publiée.
Puissance nominale | 300 kW | Usine vérifié — S01 PDF p.22 M64/60 — Turbo 408 ch
Puissance nominale métrique | 408 ch / PS | Usine vérifié — S01 PDF p.22 M64/60 — Turbo 408 ch La brochure écrit 408 hp ; 300 kW correspond à environ 408 PS et 402 hp mécaniques.
Régime de puissance nominale | 5750 tr/min | Usine vérifié — S01 PDF p.22 M64/60 — Turbo 408 ch
Couple maximal | 540 N·m | Usine vérifié — S01 PDF p.22 M64/60 — Turbo 408 ch
Régime du couple maximal | 4500 tr/min | Usine vérifié — S01 PDF p.22 M64/60 — Turbo 408 ch
Carburant prescrit dans la brochure | 98 RON | Usine vérifié — S01 PDF p.22 M64/60 — Turbo 408 ch
Alternateur | 115 A | Usine vérifié — S01 PDF p.22 M64/60 — Turbo 408 ch
Puissance électrique annoncée | 1610 W | Usine vérifié — S01 PDF p.22 M64/60 — Turbo 408 ch
Puissance démarreur | 1.7 kW | Usine vérifié — S01 PDF p.22 M64/60 — Turbo 408 ch
Vitesse maximale de la voiture | 290 km/h | Usine vérifié — S01 PDF p.22 M64/60 — Turbo 408 ch Vitesse du véhicule, pas d’une pièce moteur.
0–100 km/h | 4.5 s | Usine vérifié — S01 PDF p.22 M64/60 — Turbo 408 ch
Embrayage | 240 mm | Usine vérifié — S01 PDF p.22 M64/60 — Turbo 408 ch Diamètre publié, volant bimasse.
Augmentation de puissance usine | 430 ch / PS | Usine vérifié — S22 Section Engines Turbo avec augmentation de puissance, dès MY1996 selon S22 Ne pas attribuer les valeurs de couple / calibration de cette variante au 408 ch sans document spécifique.
Turbo S / pack 450 ch | 450 ch / PS | Usine vérifié — S22 Section Engines Turbo S / pack 450 selon marché et millésime S22 cite MY1998 ; vérifier millésime et marché pour une voiture donnée.
Disposition des turbos | Parallèle | Usine vérifié — S04 Section 911 Turbo (993) M64/60 — Turbo 408 ch
Nombre de turbos | 2 | Usine vérifié — S04 Section 911 Turbo (993) M64/60 — Turbo 408 ch
Turbos par banc | 1 | Usine vérifié — S04 Section 911 Turbo (993) M64/60 — Turbo 408 ch
Wastegates | Intégrées aux turbos | Usine vérifié — S04 Section 911 Turbo (993) M64/60 — Turbo 408 ch
Pression de suralimentation maximale | 0.8 bar relatif | Usine vérifié — S04 Section 911 Turbo (993) M64/60 — Turbo 408 ch
Refroidissement de charge | Deux intercoolers / circuits air-air | Usine vérifié — S01 PDF p.6 M64/60 — Turbo 408 ch La présentation en deux circuits ne constitue pas deux références PET distinctes pour l’ensemble échangeur.
Bypass | Deux soupapes de bypass | Usine vérifié — S01 PDF p.6 M64/60 — Turbo 408 ch La présentation en deux circuits ne constitue pas deux références PET distinctes pour l’ensemble échangeur.
Catalyseurs | Deux | Usine vérifié — S01 PDF p.6 M64/60 — Turbo 408 ch La présentation en deux circuits ne constitue pas deux références PET distinctes pour l’ensemble échangeur.
Débitmètre | Un capteur de masse d’air à film chaud | Usine vérifié — S01 PDF p.6 M64/60 — Turbo 408 ch La présentation en deux circuits ne constitue pas deux références PET distinctes pour l’ensemble échangeur.
Injection | Séquentielle, gestion électronique | Usine vérifié — S01 PDF p.22 M64/60 — Turbo 408 ch
Gestion | Motronic ; régulation anti-cliquetis | Usine vérifié — S01 PDF p.7 et p.22 M64/60 — Turbo 408 ch
Réaction au cliquetis | Retard d’allumage et réduction de pression de suralimentation | Usine vérifié — S01 PDF p.7 M64/60 — Turbo 408 ch
Surveillance émissions | OBD II, sondes d’oxygène additionnelles après catalyseurs | Usine vérifié — S01 PDF p.7 M64/60 — Turbo 408 ch Équipement/calibration à vérifier par marché et millésime ; brochure UK février 1995.
Refroidissement principal | Air forcé ; cylindres à ailettes | Usine vérifié — S01 PDF p.7 M64/60 — Turbo 408 ch
Trajet air moteur | Grille d’aileron → échangeur → ventilateur → ailettes → évacuation vers le sol | Usine vérifié — S01 PDF p.7 M64/60 — Turbo 408 ch
Régime du ventilateur par rapport à la référence de Porsche | Augmenté de 15 % | Usine vérifié — S01 PDF p.7 M64/60 — Turbo 408 ch La brochure ne donne pas ici le rapport absolu vilebrequin/ventilateur ni la référence de comparaison chiffrée.
Matériaux du système de refroidissement | Aluminium pour éléments fortement sollicités ; composites synthétiques ou magnésium pour éléments moins sollicités | Usine vérifié — S01 PDF p.7 M64/60 — Turbo 408 ch Déclaration globale ; aucune cartographie pièce → nuance précise.
Graissage | Carter sec, réservoir séparé | Architecture recoupée — S02; S06 PET groupes huile ; S06 D-3 M64/60 — Turbo 408 ch Les capacités, débits et pressions exacts doivent venir d’un document M64.60 ; la fiche S06 est Carrera.
Gicleurs de refroidissement piston | 6 longs | Usine vérifié — S09 PDF p.2 M64/60 — Turbo 408 ch Bulletin : ne pas réusiner l’alésage. Le millésime est MY1996 et suivants.
Longueur gicleur long | 33.5 mm | Usine vérifié — S09 PDF p.2 M64/60 — Turbo 408 ch Bulletin : ne pas réusiner l’alésage. Le millésime est MY1996 et suivants.
Diamètre gicleur standard | 6.3 mm | Usine vérifié — S09 PDF p.2 M64/60 — Turbo 408 ch Bulletin : ne pas réusiner l’alésage. Le millésime est MY1996 et suivants.
Diamètre gicleur surcote | 6.7 mm | Usine vérifié — S09 PDF p.2 M64/60 — Turbo 408 ch Bulletin : ne pas réusiner l’alésage. Le millésime est MY1996 et suivants.
Profondeur d’alésage exigée pour gicleur long | 33 mm | Usine vérifié — S09 PDF p.2 M64/60 — Turbo 408 ch Bulletin : ne pas réusiner l’alésage. Le millésime est MY1996 et suivants.
Gicleur long standard | 993 101 018 51 | Usine vérifié — S09 PDF p.2 M64/60 — Turbo 408 ch Bulletin : ne pas réusiner l’alésage. Le millésime est MY1996 et suivants.
Gicleur long surcote | 993 101 018 60 | Usine vérifié — S09 PDF p.2 M64/60 — Turbo 408 ch Bulletin : ne pas réusiner l’alésage. Le millésime est MY1996 et suivants.
Petit filtre Turbo historique | 993 107 203 02 | Usine vérifié — S10 PDF p.1 M64/60 — Turbo 408 ch Références datées ; ce dossier n’établit pas la disponibilité ni la dernière substitution.
Grand filtre historique | 993 207 201 01 | Usine vérifié — S10 PDF p.1 M64/60 — Turbo 408 ch Références datées ; ce dossier n’établit pas la disponibilité ni la dernière substitution.
Petit filtre Turbo PET 2017 | 993 107 203 04 | Usine vérifié — S02 PDF p.120 M64/60 — Turbo 408 ch Références datées ; ce dossier n’établit pas la disponibilité ni la dernière substitution.
Erreur de petit filtre | Mauvaise référence susceptible de fumée au démarrage à froid | Usine vérifié — S10 PDF p.1 M64/60 — Turbo 408 ch
Soufflet remplissage huile | 993 207 363 50 | Usine vérifié — S13 PDF p.1 M64/60 — Turbo 408 ch Nouvelle version à partir de production juin 1996.
Allongement du nouveau soufflet | 40 mm | Usine vérifié — S13 PDF p.1 M64/60 — Turbo 408 ch Nouvelle version à partir de production juin 1996.
Longueur annoncée étirée | 210–225 mm | Usine vérifié — S13 PDF p.1 M64/60 — Turbo 408 ch Nouvelle version à partir de production juin 1996.
Turbocompresseur gauche Porsche | 993 123 013 51 / 52 / CX | Usine vérifié — S02 PDF p.144 / planche 202-16 M64/60 — Turbo 408 ch Le catalogue ne définit pas à lui seul le débit ni la vitesse de pompe.
Turbocompresseur droit Porsche | 993 123 014 51 / 52 / DX | Usine vérifié — S02 PDF p.144 / planche 202-16 M64/60 — Turbo 408 ch Le catalogue ne définit pas à lui seul le débit ni la vitesse de pompe.
Collecteur huile turbo gauche | 993 107 127 51 | Usine vérifié — S02 PDF p.144 / planche 202-16 M64/60 — Turbo 408 ch Le catalogue ne définit pas à lui seul le débit ni la vitesse de pompe.
Collecteur huile turbo droit | 993 107 128 51 | Usine vérifié — S02 PDF p.144 / planche 202-16 M64/60 — Turbo 408 ch Le catalogue ne définit pas à lui seul le débit ni la vitesse de pompe.
Conduites huile gauche | 993 107 125 53 ; 993 107 339 53 | Usine vérifié — S02 PDF p.144 / planche 202-16 M64/60 — Turbo 408 ch Le catalogue ne définit pas à lui seul le débit ni la vitesse de pompe.
Conduites huile droite | 993 107 126 53 ; 993 107 338 53 | Usine vérifié — S02 PDF p.144 / planche 202-16 M64/60 — Turbo 408 ch Le catalogue ne définit pas à lui seul le débit ni la vitesse de pompe.
Support avec pompe huile turbo | 993 107 005 52 / 53 | Usine vérifié — S02 PDF p.144 / planche 202-16 M64/60 — Turbo 408 ch Le catalogue ne définit pas à lui seul le débit ni la vitesse de pompe.
K16 gauche BorgWarner | 5316-988-6736 | Fabricant / vendeur vérifié — S03; S20; S21 S03 PDF p.56 ; pages TurboMaster M64/60 — Turbo 408 ch Latéralité recoupée avec références Porsche. La nomenclature n’est pas un plan géométrique.
K16 droit BorgWarner | 5316-988-6735 | Fabricant / vendeur vérifié — S03; S20; S21 S03 PDF p.56 ; pages TurboMaster M64/60 — Turbo 408 ch Latéralité recoupée avec références Porsche. La nomenclature n’est pas un plan géométrique.
Famille modèle TurboMaster | K16-2467GGA/8.88 | Fabricant / vendeur vérifié — S03; S20; S21 S03 PDF p.56 ; pages TurboMaster M64/60 — Turbo 408 ch Latéralité recoupée avec références Porsche. La nomenclature n’est pas un plan géométrique.
CHRA catalogué | 5316-710-0520 | Fabricant / vendeur vérifié — S03; S20; S21 S03 PDF p.56 ; pages TurboMaster M64/60 — Turbo 408 ch Latéralité recoupée avec références Porsche. La nomenclature n’est pas un plan géométrique.
Roue turbine cataloguée | 5316-120-5000 | Fabricant / vendeur vérifié — S03; S20; S21 S03 PDF p.56 ; pages TurboMaster M64/60 — Turbo 408 ch Latéralité recoupée avec références Porsche. La nomenclature n’est pas un plan géométrique.
Roue compresseur cataloguée | 5324-123-2006 | Fabricant / vendeur vérifié — S03; S20; S21 S03 PDF p.56 ; pages TurboMaster M64/60 — Turbo 408 ch Latéralité recoupée avec références Porsche. La nomenclature n’est pas un plan géométrique.
Carter de palier gauche | 5316-151-0008 | Fabricant / vendeur vérifié — S03; S20; S21 S03 PDF p.56 ; pages TurboMaster M64/60 — Turbo 408 ch Latéralité recoupée avec références Porsche. La nomenclature n’est pas un plan géométrique.
Carter de palier droit | 5316-151-0002 | Fabricant / vendeur vérifié — S03; S20; S21 S03 PDF p.56 ; pages TurboMaster M64/60 — Turbo 408 ch Latéralité recoupée avec références Porsche. La nomenclature n’est pas un plan géométrique.
Actionneur catalogué | 5825-110-4006 | Fabricant / vendeur vérifié — S03; S20; S21 S03 PDF p.56 ; pages TurboMaster M64/60 — Turbo 408 ch Latéralité recoupée avec références Porsche. La nomenclature n’est pas un plan géométrique.
A/R affiché par TurboMaster | 8.00 | Vendeur — convention à clarifier — S20; S21 M64/60 — Turbo 408 ch Ne pas traiter 8.00 comme une valeur A/R automobile normalisée de 0,xx.
Limite commerciale stock turbo | 500 hp selon catalogue | Fabricant — limite commerciale — S03 PDF p.56 M64/60 — Turbo 408 ch Valeur de capacité du système turbo, pas de résistance validée du moteur.
Upgrade BorgWarner | 5324-988-7003 + 7004 | Fabricant — aftermarket — S03 PDF p.56 K24 upgrade
Limite commerciale upgrade | 555 hp selon catalogue | Fabricant — aftermarket — S03 PDF p.56 K24 upgrade
Max. T3 continu / temporaire | 950 / 980 °C | Fabricant — tableau upgrade — S03 PDF p.56 Ligne upgrade 993 du catalogue Ni température réelle mesurée sur K16 de série, ni température métal, ni certificat de matériau.
Allumeur Turbo | Un : 993 602 016 00 | Usine vérifié — S02 PDF p.596 / planche 901-01 M64/60 — Turbo 408 ch Allumage simple : ne pas copier les 12 bougies de la Carrera atmosphérique.
Bobine Turbo | Une : 993 602 073 00 | Usine vérifié — S02 PDF p.596 / planche 901-01 M64/60 — Turbo 408 ch Allumage simple : ne pas copier les 12 bougies de la Carrera atmosphérique.
Nombre de bougies Turbo | 6 | Usine vérifié — S02 PDF p.596 / planche 901-01 M64/60 — Turbo 408 ch Allumage simple : ne pas copier les 12 bougies de la Carrera atmosphérique.
Bougie cataloguée | 999 170 195 90 / 14FR 6LDU | Usine vérifié — S02 PDF p.596 / planche 901-01 M64/60 — Turbo 408 ch Allumage simple : ne pas copier les 12 bougies de la Carrera atmosphérique.
Ordre d’allumage | 1–6–2–4–3–5 | M64 — à confirmer dans manuel Turbo — S06 D-4 M64/60 — Turbo 408 ch S06 concerne Carrera ; aucune fiche d’ordre d’allumage M64.60 distincte obtenue.
Arbres à cames | Un par banc, entraînement par chaînes doubles | Architecture recoupée — S02; S05 Groupes distribution ; S05 p.56 imprimée M64/60 — Turbo 408 ch Les levées et angles de la Carrera ne sont pas transposés au M64.60.
Rattrapage du jeu | Hydraulique | Usine vérifié — S01 PDF p.7 M64/60 — Turbo 408 ch
Poussoir Turbo standard | 993 105 141 03 | Usine vérifié — S08 PDF p.1 M64/60 — Turbo 408 ch
Poussoir Turbo taille 1 | 993 105 141 50 | Usine vérifié — S08 PDF p.1 M64/60 — Turbo 408 ch
Poussoir Turbo taille 2 | 993 105 141 60 | Usine vérifié — S08 PDF p.1 M64/60 — Turbo 408 ch
Exception calage AAC MY1996 | Moteurs 61T00500 à 61T00657 : contrôle au comparateur | Usine vérifié — S11 PDF p.1 M64/60 — Turbo 408 ch Erreur possible de position de rainure ; manuel Turbo p.15-13 à 15-18. Pas de valeur de calage chiffrée dans ce bulletin.
Rapport alternateur / vilebrequin | 2.68 :1 | Usine vérifié — S07 PDF p.1 M64/60 — Turbo 408 ch Rapport théorique, glissement de courroie non inclus.
Courroie alternateur révisée | 999 192 372 50 | Usine vérifié — S07 PDF p.1 M64/60 — Turbo 408 ch Rapport théorique, glissement de courroie non inclus.
Longueur courroie alternateur révisée | 757 mm | Usine vérifié — S07 PDF p.1 M64/60 — Turbo 408 ch Rapport théorique, glissement de courroie non inclus.
Demi-poulies alternateur révisées | 993 106 268 01 | Usine vérifié — S07 PDF p.1 M64/60 — Turbo 408 ch Rapport théorique, glissement de courroie non inclus.
Épaisseurs de cales disponibles | 0,5 / 0,7 mm | Usine vérifié — S07 PDF p.1 M64/60 — Turbo 408 ch Rapport théorique, glissement de courroie non inclus.
Ventilateur Turbo | 964 106 015 21 / 22 | Usine vérifié — S02 PDF p.78 / planche 105-00 M64/60 — Turbo 408 ch Pièces spécifiques M64.60 ; 96410601531 et 99310666703 concernent d’autres affectations dans ce PET.
Carter ventilateur Turbo | 993 106 667 50 | Usine vérifié — S02 PDF p.78 / planche 105-00 M64/60 — Turbo 408 ch Pièces spécifiques M64.60 ; 96410601531 et 99310666703 concernent d’autres affectations dans ce PET.
Demi-poulie ventilateur intérieure Turbo | 993 106 509 50 | Usine vérifié — S02 PDF p.78 / planche 105-00 M64/60 — Turbo 408 ch Pièces spécifiques M64.60 ; 96410601531 et 99310666703 concernent d’autres affectations dans ce PET.
Demi-poulie ventilateur extérieure Turbo | 993 106 510 50 | Usine vérifié — S02 PDF p.78 / planche 105-00 M64/60 — Turbo 408 ch Pièces spécifiques M64.60 ; 96410601531 et 99310666703 concernent d’autres affectations dans ce PET.
Courroie ventilateur Turbo | 999 192 343 50 — 9,5 × 760 mm | Usine vérifié — S02 PDF p.78 / planche 105-00 M64/60 — Turbo 408 ch Pièces spécifiques M64.60 ; 96410601531 et 99310666703 concernent d’autres affectations dans ce PET.
Accès à la courroie | Console climatisation parfois à reprendre pour dégagement | Usine vérifié — S12 PDF p.1 M64/60 — Turbo 408 ch Bulletin MY1996 ; contient une illustration de la zone, pas de cote de reprise.
Vilebrequin catalogue à partir de 1995 | 993 102 021 02 | Usine vérifié — S02 PDF p.43–52 M64/60 — Turbo 408 ch
Volant bimasse M64.60 | 996 114 012 50 | Usine vérifié — S02 PDF p.43–52 M64/60 — Turbo 408 ch
Bielle, familles révisées | 993 103 020 64 à 69 | Usine vérifié — S02 PDF p.43–52 M64/60 — Turbo 408 ch
Classes de masse bielles révisées | 534–540 / 540–546 / 546–552 / 552–558 / 558–564 / 564–570 g | Usine vérifié — S02 PDF p.43–52 M64/60 — Turbo 408 ch
Seuil moteur de bielle révisée pour Turbo | M 61T 00932 >> | Usine vérifié — S02 PDF p.43–52 M64/60 — Turbo 408 ch
Ensemble cylindre/piston Turbo groupe 5 jusqu’à MY1996 | 993 103 915 51 / 52 | Usine vérifié — S02 PDF p.43–52 M64/60 — Turbo 408 ch
Ensemble cylindre/piston Turbo groupe 5 dès MY1997 | 993 103 915 56 / 57 | Usine vérifié — S02 PDF p.43–52 M64/60 — Turbo 408 ch
Classes de masse piston Turbo cataloguées | 576–584 / 584–592 g | Usine vérifié — S02 PDF p.43–52 M64/60 — Turbo 408 ch Les classes de masse de l’ensemble vendu ne définissent pas une pesée de piston nu. Les références dépendent du groupe et du millésime.
Joint de pied cylindre | 999 707 152 40 — 102 × 2 mm | Usine vérifié — S02 PDF p.43–52 M64/60 — Turbo 408 ch
Joint de culasse | 964 104 115 20 — quantité 6 | Usine vérifié — S02 PDF p.43–52 M64/60 — Turbo 408 ch
Guide-air Turbo | 993 106 257 51 — quantité 6 | Usine vérifié — S02 PDF p.43–52 M64/60 — Turbo 408 ch
Culasse M64.60 | 993 104 033 52 / 993 104 053 52 | Usine vérifié — S02 PDF p.35 et 54 M64/60 — Turbo 408 ch
Soupape admission M64.60 | 993 105 409 02 — quantité 6 | Usine vérifié — S02 PDF p.35 et 54 M64/60 — Turbo 408 ch
Soupape échappement M64.60 | 993 105 419 52 — quantité 6 | Usine vérifié — S02 PDF p.35 et 54 M64/60 — Turbo 408 ch
Jeu ressorts de soupape | 993 105 901 51 — quantité 12 | Usine vérifié — S02 PDF p.35 et 54 M64/60 — Turbo 408 ch
Écrou culasse M64.60 | 993 104 382 53 — quantité 24 | Usine vérifié — S02 PDF p.35 et 54 M64/60 — Turbo 408 ch
Goujons de culasse M64.60 | 993 101 170 51 / 53 — quantité 24 | Usine vérifié — S02 PDF p.35 et 54 M64/60 — Turbo 408 ch
Goujons Dilavar | Famille Dilavar ; substitution 93010117002 → 99310117051 | Usine recoupé — S02; S16 PET p.35 ; bulletin p.1 M64/60 — Turbo 408 ch Nuance chimique et propriétés métallurgiques exactes non publiées dans ces documents.
Carter moteur | Alliage aluminium–silicium, deux demi-carters | Architecture M64 recoupée — S02; S05 S05 PDF p.57 / page imprimée 53 M64/60 — Turbo 408 ch Chapitre Carrera ; le PET partage les familles carter. Nuance OEM et procédé exact Turbo non établis ici.
Vilebrequin / bielles | Forgeage documenté dans la famille M64 | Architecture M64 — recoupement — S05; S06; S02 S06 D-2 ; PET 102-00 M64/60 — Turbo 408 ch La composition exacte de l’acier, le traitement et la dureté d’origine Turbo restent à obtenir.
Cylindres Turbo | Cylindres pressés selon brochure ; alliage léger | Usine / architecture recoupée — S01; S05 S01 PDF p.7 M64/60 — Turbo 408 ch Brochure « pressed cylinders ». Nikasil explicitement documenté sur Carrera dans S05, pas confirmé ici par une fiche spécifique Turbo.
Couvre-arbres polyamide renforcé fibre de verre | Documenté pour Carrera 993 | Contexte Carrera uniquement — S05 PDF p.63 / imprimée p.59 Carrera 993 Ne permet pas de qualifier tous les couvercles de la Turbo.
Sorties optionnelles XLB | Acier inoxydable chromé | Usine vérifié — S23 PDF p.1 993 Turbo, option XLB Références gauche 99311198103, droite 99311198203 ; nuance inox non précisée.
Soupape admission de remplacement | Tête 49 ; queue 8 mm | Déclaration vendeur existante — SRC-FVD-993-INLET-VALVE-DIMENSIONS FVD 99310540902EQ1, remplacement M64.60 Le produit est explicitement non refroidi au sodium ; ne pas assimiler son matériau ou sa masse à l’OEM.
Soupape échappement de remplacement | Longueur 108,9 ; tête 43,5 ; queue 8 mm | Déclaration vendeur existante — SRC-PARTWORKS-993-EXHAUST-VALVE-DIMENSIONS SM Motorenteile / partworks pour Turbo 408 ch Pas de tolérances ni de preuve métallurgique. Diffère de la soupape Carrera tête 42,5 mm.
Piston MAHLE 3,8 L | 2618 ; 468 g ; axe 23 mm | Aftermarket déjà référencé — S19 PP102-012N / LN105-102/109, alésage 102 mm Aucune de ces valeurs ne prouve l’alliage ni la masse du piston 3,6 L de série.
Support moteur révisé | 964 375 043 81 ; remplacement par paire | Usine vérifié — S14 PDF p.1 Turbo S / Turbo X73 MY1997–1998
Rondelles support moteur révisé | 45.5 mm | Usine vérifié — S14 PDF p.1 Turbo S / Turbo X73 MY1997–1998 Ancienne rondelle 34 mm ; ne pas extrapoler aux interfaces de fixation.
Vis support moteur version X73 / S | M12 × 1,5 × 125 mm | Usine vérifié — S14 PDF p.1 Turbo S / Turbo X73 MY1997–1998 Corps du bulletin ; table de pièces comporte 1,2 au lieu de 1,5, contradiction conservée dans l’audit.
Banc à rouleaux — bulletin historique | Porsche déconseille le test de la nouvelle Turbo | Usine vérifié — S15 PDF p.1 M64/60 — Turbo 408 ch Air de charge insuffisamment refroidi → baisse puissance et surchauffe ; transmission / glissement des pneus. Ce n’est pas une certification d’un banc moderne.
Cylindrée géométrique | 3600.2652 cm³ | Calcul — S01; S04 Formule dans commentaire M64/60 — Turbo 408 ch π/4 × 100² × 76,4 × 6, unités mm.
Cylindrée unitaire | 600.0442 cm³ | Calcul — S01; S04 Formule dans commentaire M64/60 — Turbo 408 ch Cylindrée géométrique / 6.
Rayon de manivelle | 38.2 mm | Calcul — S01; S04 Formule dans commentaire M64/60 — Turbo 408 ch Course / 2.
Volume résiduel théorique à 8:1 | 85.7206 cm³ / cylindre | Calcul — S01; S04 Formule dans commentaire M64/60 — Turbo 408 ch Vd/(r−1) ; volume total au PMH, pas le volume nu de la culasse.
Puissance spécifique | 83.3333 kW/L | Calcul — S01; S04 Formule dans commentaire M64/60 — Turbo 408 ch Puissance nominale / cylindrée publiée.
Couple spécifique | 150.0 N·m/L | Calcul — S01; S04 Formule dans commentaire M64/60 — Turbo 408 ch Couple maximal / cylindrée publiée.
Pression moyenne effective au couple maximal | 18.8496 bar | Calcul — S01; S04 Formule dans commentaire M64/60 — Turbo 408 ch BMEP = 4πT/V pour moteur 4 temps ; ce n’est pas la pression maximale de combustion.
Couple correspondant à 300 kW et 5750 tr/min | 498.2242 N·m | Calcul — S01; S04 Formule dans commentaire M64/60 — Turbo 408 ch T = P/ω.
Puissance à 540 Nm et 4500 tr/min | 254.469 kW | Calcul — S01; S04 Formule dans commentaire M64/60 — Turbo 408 ch P = Tω ; n’est pas la puissance maximale.
Pression admission absolue avec 0,8 bar de boost | 1.8 bar | Calcul — S01; S04 Formule dans commentaire M64/60 — Turbo 408 ch Hypothèse ambiance 1,0 bar ; la vraie pression dépend de l’ambiante.
Intervalle moyen entre combustions | 120 degrés vilebrequin | Calcul — S01; S04 Formule dans commentaire M64/60 — Turbo 408 ch 720° / 6 pour allumage régulier.
Alternateur à 1000 tr/min moteur | 2680.0 tr/min | Calcul — S01; S07; S02 M64/60 — Turbo 408 ch Sans glissement de courroie ; distribution 4 temps, architecture M64
Arbres à cames à 1000 tr/min moteur | 500.0 tr/min | Calcul — S01; S07; S02 M64/60 — Turbo 408 ch Sans glissement de courroie ; distribution 4 temps, architecture M64
Allumeur à 1000 tr/min moteur | 500.0 tr/min | Calcul — S01; S07; S02 M64/60 — Turbo 408 ch Sans glissement de courroie ; distribution 4 temps, architecture M64
Vitesse moyenne piston à 1000 tr/min moteur | 2.5467 m/s | Calcul — S01; S07; S02 M64/60 — Turbo 408 ch Sans glissement de courroie ; distribution 4 temps, architecture M64
Combustions de tout le moteur à 1000 tr/min moteur | 50.0 Hz | Calcul — S01; S07; S02 M64/60 — Turbo 408 ch Sans glissement de courroie ; distribution 4 temps, architecture M64
Alternateur à 4500 tr/min moteur | 12060.0 tr/min | Calcul — S01; S07; S02 M64/60 — Turbo 408 ch Sans glissement de courroie ; distribution 4 temps, architecture M64
Arbres à cames à 4500 tr/min moteur | 2250.0 tr/min | Calcul — S01; S07; S02 M64/60 — Turbo 408 ch Sans glissement de courroie ; distribution 4 temps, architecture M64
Allumeur à 4500 tr/min moteur | 2250.0 tr/min | Calcul — S01; S07; S02 M64/60 — Turbo 408 ch Sans glissement de courroie ; distribution 4 temps, architecture M64
Vitesse moyenne piston à 4500 tr/min moteur | 11.46 m/s | Calcul — S01; S07; S02 M64/60 — Turbo 408 ch Sans glissement de courroie ; distribution 4 temps, architecture M64
Combustions de tout le moteur à 4500 tr/min moteur | 225.0 Hz | Calcul — S01; S07; S02 M64/60 — Turbo 408 ch Sans glissement de courroie ; distribution 4 temps, architecture M64
Alternateur à 5750 tr/min moteur | 15410.0 tr/min | Calcul — S01; S07; S02 M64/60 — Turbo 408 ch Sans glissement de courroie ; distribution 4 temps, architecture M64
Arbres à cames à 5750 tr/min moteur | 2875.0 tr/min | Calcul — S01; S07; S02 M64/60 — Turbo 408 ch Sans glissement de courroie ; distribution 4 temps, architecture M64
Allumeur à 5750 tr/min moteur | 2875.0 tr/min | Calcul — S01; S07; S02 M64/60 — Turbo 408 ch Sans glissement de courroie ; distribution 4 temps, architecture M64
Vitesse moyenne piston à 5750 tr/min moteur | 14.6433 m/s | Calcul — S01; S07; S02 M64/60 — Turbo 408 ch Sans glissement de courroie ; distribution 4 temps, architecture M64
Combustions de tout le moteur à 5750 tr/min moteur | 287.5 Hz | Calcul — S01; S07; S02 M64/60 — Turbo 408 ch Sans glissement de courroie ; distribution 4 temps, architecture M64
Alternateur à 6500 tr/min moteur | 17420.0 tr/min | Calcul — S01; S07; S02 M64/60 — Turbo 408 ch 6500 tr/min est un exemple de calcul, pas un régime limite confirmé
Arbres à cames à 6500 tr/min moteur | 3250.0 tr/min | Calcul — S01; S07; S02 M64/60 — Turbo 408 ch 6500 tr/min est un exemple de calcul, pas un régime limite confirmé
Allumeur à 6500 tr/min moteur | 3250.0 tr/min | Calcul — S01; S07; S02 M64/60 — Turbo 408 ch 6500 tr/min est un exemple de calcul, pas un régime limite confirmé
Vitesse moyenne piston à 6500 tr/min moteur | 16.5533 m/s | Calcul — S01; S07; S02 M64/60 — Turbo 408 ch 6500 tr/min est un exemple de calcul, pas un régime limite confirmé
Combustions de tout le moteur à 6500 tr/min moteur | 325.0 Hz | Calcul — S01; S07; S02 M64/60 — Turbo 408 ch 6500 tr/min est un exemple de calcul, pas un régime limite confirmé
Rapport de vitesse ventilateur conditionnel | 1.84 :1 | Hypothèse non validée — S01; S06 M64/60 — Turbo 408 ch 1,6 × 1,15 ; seulement si la référence du +15 % est exactement la Carrera à 1,6. Ne pas publier 1,84 comme ratio usine Turbo.
Arbre turbo | Turbine et compresseur du même turbo : même régime | Relation mécanique — S20; S21 M64/60 — Turbo 408 ch Aucun rapport fixe au vilebrequin. Les deux turbos ne sont pas mécaniquement synchronisés.

## Performance et électricité

Paramètre | Valeur | Preuve et limites
Code moteur | M64.60 | Usine vérifié — S05 Index modèles PDF p.6 M64/60 — Turbo 408 ch M64/60 est l’identifiant usine utile ; « Mezger » désigne sa filiation technique.
Architecture | Boxer, six cylindres opposés | Usine vérifié — S01 PDF p.22 M64/60 — Turbo 408 ch
Cycle | 4 temps, essence | Usine vérifié — S01 PDF p.22 M64/60 — Turbo 408 ch
Nombre de cylindres | 6 | Usine vérifié — S01 PDF p.22 M64/60 — Turbo 408 ch
Bancs | 2 | Usine vérifié — S01 PDF p.22 M64/60 — Turbo 408 ch Comptage dérivé de la configuration publiée.
Cylindres par banc | 3 | Usine vérifié — S01 PDF p.22 M64/60 — Turbo 408 ch Comptage dérivé de la configuration publiée.
Alésage nominal | 100 mm | Usine vérifié — S01 PDF p.22 M64/60 — Turbo 408 ch
Course | 76.4 mm | Usine vérifié — S01 PDF p.22 M64/60 — Turbo 408 ch
Cylindrée publiée | 3600 cm³ | Usine vérifié — S01 PDF p.22 M64/60 — Turbo 408 ch
Rapport volumétrique | 8 à 1 | Usine vérifié — S01 PDF p.22 M64/60 — Turbo 408 ch
Soupapes par cylindre | 2 | Usine vérifié — S01 PDF p.22 M64/60 — Turbo 408 ch
Soupapes totales | 12 | Usine vérifié — S01 PDF p.22 M64/60 — Turbo 408 ch Comptage dérivé de la configuration publiée.
Puissance nominale | 300 kW | Usine vérifié — S01 PDF p.22 M64/60 — Turbo 408 ch
Puissance nominale métrique | 408 ch / PS | Usine vérifié — S01 PDF p.22 M64/60 — Turbo 408 ch La brochure écrit 408 hp ; 300 kW correspond à environ 408 PS et 402 hp mécaniques.
Régime de puissance nominale | 5750 tr/min | Usine vérifié — S01 PDF p.22 M64/60 — Turbo 408 ch
Couple maximal | 540 N·m | Usine vérifié — S01 PDF p.22 M64/60 — Turbo 408 ch
Régime du couple maximal | 4500 tr/min | Usine vérifié — S01 PDF p.22 M64/60 — Turbo 408 ch
Carburant prescrit dans la brochure | 98 RON | Usine vérifié — S01 PDF p.22 M64/60 — Turbo 408 ch
Alternateur | 115 A | Usine vérifié — S01 PDF p.22 M64/60 — Turbo 408 ch
Puissance électrique annoncée | 1610 W | Usine vérifié — S01 PDF p.22 M64/60 — Turbo 408 ch
Puissance démarreur | 1.7 kW | Usine vérifié — S01 PDF p.22 M64/60 — Turbo 408 ch
Vitesse maximale de la voiture | 290 km/h | Usine vérifié — S01 PDF p.22 M64/60 — Turbo 408 ch Vitesse du véhicule, pas d’une pièce moteur.
0–100 km/h | 4.5 s | Usine vérifié — S01 PDF p.22 M64/60 — Turbo 408 ch
Embrayage | 240 mm | Usine vérifié — S01 PDF p.22 M64/60 — Turbo 408 ch Diamètre publié, volant bimasse.
Augmentation de puissance usine | 430 ch / PS | Usine vérifié — S22 Section Engines Turbo avec augmentation de puissance, dès MY1996 selon S22 Ne pas attribuer les valeurs de couple / calibration de cette variante au 408 ch sans document spécifique.
Turbo S / pack 450 ch | 450 ch / PS | Usine vérifié — S22 Section Engines Turbo S / pack 450 selon marché et millésime S22 cite MY1998 ; vérifier millésime et marché pour une voiture donnée.
Disposition des turbos | Parallèle | Usine vérifié — S04 Section 911 Turbo (993) M64/60 — Turbo 408 ch
Nombre de turbos | 2 | Usine vérifié — S04 Section 911 Turbo (993) M64/60 — Turbo 408 ch
Turbos par banc | 1 | Usine vérifié — S04 Section 911 Turbo (993) M64/60 — Turbo 408 ch
Wastegates | Intégrées aux turbos | Usine vérifié — S04 Section 911 Turbo (993) M64/60 — Turbo 408 ch
Pression de suralimentation maximale | 0.8 bar relatif | Usine vérifié — S04 Section 911 Turbo (993) M64/60 — Turbo 408 ch
Refroidissement de charge | Deux intercoolers / circuits air-air | Usine vérifié — S01 PDF p.6 M64/60 — Turbo 408 ch La présentation en deux circuits ne constitue pas deux références PET distinctes pour l’ensemble échangeur.
Bypass | Deux soupapes de bypass | Usine vérifié — S01 PDF p.6 M64/60 — Turbo 408 ch La présentation en deux circuits ne constitue pas deux références PET distinctes pour l’ensemble échangeur.
Catalyseurs | Deux | Usine vérifié — S01 PDF p.6 M64/60 — Turbo 408 ch La présentation en deux circuits ne constitue pas deux références PET distinctes pour l’ensemble échangeur.
Débitmètre | Un capteur de masse d’air à film chaud | Usine vérifié — S01 PDF p.6 M64/60 — Turbo 408 ch La présentation en deux circuits ne constitue pas deux références PET distinctes pour l’ensemble échangeur.
Injection | Séquentielle, gestion électronique | Usine vérifié — S01 PDF p.22 M64/60 — Turbo 408 ch
Gestion | Motronic ; régulation anti-cliquetis | Usine vérifié — S01 PDF p.7 et p.22 M64/60 — Turbo 408 ch
Réaction au cliquetis | Retard d’allumage et réduction de pression de suralimentation | Usine vérifié — S01 PDF p.7 M64/60 — Turbo 408 ch
Surveillance émissions | OBD II, sondes d’oxygène additionnelles après catalyseurs | Usine vérifié — S01 PDF p.7 M64/60 — Turbo 408 ch Équipement/calibration à vérifier par marché et millésime ; brochure UK février 1995.
Refroidissement principal | Air forcé ; cylindres à ailettes | Usine vérifié — S01 PDF p.7 M64/60 — Turbo 408 ch
Trajet air moteur | Grille d’aileron → échangeur → ventilateur → ailettes → évacuation vers le sol | Usine vérifié — S01 PDF p.7 M64/60 — Turbo 408 ch
Régime du ventilateur par rapport à la référence de Porsche | Augmenté de 15 % | Usine vérifié — S01 PDF p.7 M64/60 — Turbo 408 ch La brochure ne donne pas ici le rapport absolu vilebrequin/ventilateur ni la référence de comparaison chiffrée.
Matériaux du système de refroidissement | Aluminium pour éléments fortement sollicités ; composites synthétiques ou magnésium pour éléments moins sollicités | Usine vérifié — S01 PDF p.7 M64/60 — Turbo 408 ch Déclaration globale ; aucune cartographie pièce → nuance précise.
Graissage | Carter sec, réservoir séparé | Architecture recoupée — S02; S06 PET groupes huile ; S06 D-3 M64/60 — Turbo 408 ch Les capacités, débits et pressions exacts doivent venir d’un document M64.60 ; la fiche S06 est Carrera.
Gicleurs de refroidissement piston | 6 longs | Usine vérifié — S09 PDF p.2 M64/60 — Turbo 408 ch Bulletin : ne pas réusiner l’alésage. Le millésime est MY1996 et suivants.
Longueur gicleur long | 33.5 mm | Usine vérifié — S09 PDF p.2 M64/60 — Turbo 408 ch Bulletin : ne pas réusiner l’alésage. Le millésime est MY1996 et suivants.
Diamètre gicleur standard | 6.3 mm | Usine vérifié — S09 PDF p.2 M64/60 — Turbo 408 ch Bulletin : ne pas réusiner l’alésage. Le millésime est MY1996 et suivants.
Diamètre gicleur surcote | 6.7 mm | Usine vérifié — S09 PDF p.2 M64/60 — Turbo 408 ch Bulletin : ne pas réusiner l’alésage. Le millésime est MY1996 et suivants.
Profondeur d’alésage exigée pour gicleur long | 33 mm | Usine vérifié — S09 PDF p.2 M64/60 — Turbo 408 ch Bulletin : ne pas réusiner l’alésage. Le millésime est MY1996 et suivants.
Gicleur long standard | 993 101 018 51 | Usine vérifié — S09 PDF p.2 M64/60 — Turbo 408 ch Bulletin : ne pas réusiner l’alésage. Le millésime est MY1996 et suivants.
Gicleur long surcote | 993 101 018 60 | Usine vérifié — S09 PDF p.2 M64/60 — Turbo 408 ch Bulletin : ne pas réusiner l’alésage. Le millésime est MY1996 et suivants.
Petit filtre Turbo historique | 993 107 203 02 | Usine vérifié — S10 PDF p.1 M64/60 — Turbo 408 ch Références datées ; ce dossier n’établit pas la disponibilité ni la dernière substitution.
Grand filtre historique | 993 207 201 01 | Usine vérifié — S10 PDF p.1 M64/60 — Turbo 408 ch Références datées ; ce dossier n’établit pas la disponibilité ni la dernière substitution.
Petit filtre Turbo PET 2017 | 993 107 203 04 | Usine vérifié — S02 PDF p.120 M64/60 — Turbo 408 ch Références datées ; ce dossier n’établit pas la disponibilité ni la dernière substitution.
Erreur de petit filtre | Mauvaise référence susceptible de fumée au démarrage à froid | Usine vérifié — S10 PDF p.1 M64/60 — Turbo 408 ch
Soufflet remplissage huile | 993 207 363 50 | Usine vérifié — S13 PDF p.1 M64/60 — Turbo 408 ch Nouvelle version à partir de production juin 1996.
Allongement du nouveau soufflet | 40 mm | Usine vérifié — S13 PDF p.1 M64/60 — Turbo 408 ch Nouvelle version à partir de production juin 1996.
Longueur annoncée étirée | 210–225 mm | Usine vérifié — S13 PDF p.1 M64/60 — Turbo 408 ch Nouvelle version à partir de production juin 1996.
Turbocompresseur gauche Porsche | 993 123 013 51 / 52 / CX | Usine vérifié — S02 PDF p.144 / planche 202-16 M64/60 — Turbo 408 ch Le catalogue ne définit pas à lui seul le débit ni la vitesse de pompe.
Turbocompresseur droit Porsche | 993 123 014 51 / 52 / DX | Usine vérifié — S02 PDF p.144 / planche 202-16 M64/60 — Turbo 408 ch Le catalogue ne définit pas à lui seul le débit ni la vitesse de pompe.
Collecteur huile turbo gauche | 993 107 127 51 | Usine vérifié — S02 PDF p.144 / planche 202-16 M64/60 — Turbo 408 ch Le catalogue ne définit pas à lui seul le débit ni la vitesse de pompe.
Collecteur huile turbo droit | 993 107 128 51 | Usine vérifié — S02 PDF p.144 / planche 202-16 M64/60 — Turbo 408 ch Le catalogue ne définit pas à lui seul le débit ni la vitesse de pompe.
Conduites huile gauche | 993 107 125 53 ; 993 107 339 53 | Usine vérifié — S02 PDF p.144 / planche 202-16 M64/60 — Turbo 408 ch Le catalogue ne définit pas à lui seul le débit ni la vitesse de pompe.
Conduites huile droite | 993 107 126 53 ; 993 107 338 53 | Usine vérifié — S02 PDF p.144 / planche 202-16 M64/60 — Turbo 408 ch Le catalogue ne définit pas à lui seul le débit ni la vitesse de pompe.
Support avec pompe huile turbo | 993 107 005 52 / 53 | Usine vérifié — S02 PDF p.144 / planche 202-16 M64/60 — Turbo 408 ch Le catalogue ne définit pas à lui seul le débit ni la vitesse de pompe.
K16 gauche BorgWarner | 5316-988-6736 | Fabricant / vendeur vérifié — S03; S20; S21 S03 PDF p.56 ; pages TurboMaster M64/60 — Turbo 408 ch Latéralité recoupée avec références Porsche. La nomenclature n’est pas un plan géométrique.
K16 droit BorgWarner | 5316-988-6735 | Fabricant / vendeur vérifié — S03; S20; S21 S03 PDF p.56 ; pages TurboMaster M64/60 — Turbo 408 ch Latéralité recoupée avec références Porsche. La nomenclature n’est pas un plan géométrique.
Famille modèle TurboMaster | K16-2467GGA/8.88 | Fabricant / vendeur vérifié — S03; S20; S21 S03 PDF p.56 ; pages TurboMaster M64/60 — Turbo 408 ch Latéralité recoupée avec références Porsche. La nomenclature n’est pas un plan géométrique.
CHRA catalogué | 5316-710-0520 | Fabricant / vendeur vérifié — S03; S20; S21 S03 PDF p.56 ; pages TurboMaster M64/60 — Turbo 408 ch Latéralité recoupée avec références Porsche. La nomenclature n’est pas un plan géométrique.
Roue turbine cataloguée | 5316-120-5000 | Fabricant / vendeur vérifié — S03; S20; S21 S03 PDF p.56 ; pages TurboMaster M64/60 — Turbo 408 ch Latéralité recoupée avec références Porsche. La nomenclature n’est pas un plan géométrique.
Roue compresseur cataloguée | 5324-123-2006 | Fabricant / vendeur vérifié — S03; S20; S21 S03 PDF p.56 ; pages TurboMaster M64/60 — Turbo 408 ch Latéralité recoupée avec références Porsche. La nomenclature n’est pas un plan géométrique.
Carter de palier gauche | 5316-151-0008 | Fabricant / vendeur vérifié — S03; S20; S21 S03 PDF p.56 ; pages TurboMaster M64/60 — Turbo 408 ch Latéralité recoupée avec références Porsche. La nomenclature n’est pas un plan géométrique.
Carter de palier droit | 5316-151-0002 | Fabricant / vendeur vérifié — S03; S20; S21 S03 PDF p.56 ; pages TurboMaster M64/60 — Turbo 408 ch Latéralité recoupée avec références Porsche. La nomenclature n’est pas un plan géométrique.
Actionneur catalogué | 5825-110-4006 | Fabricant / vendeur vérifié — S03; S20; S21 S03 PDF p.56 ; pages TurboMaster M64/60 — Turbo 408 ch Latéralité recoupée avec références Porsche. La nomenclature n’est pas un plan géométrique.
A/R affiché par TurboMaster | 8.00 | Vendeur — convention à clarifier — S20; S21 M64/60 — Turbo 408 ch Ne pas traiter 8.00 comme une valeur A/R automobile normalisée de 0,xx.
Limite commerciale stock turbo | 500 hp selon catalogue | Fabricant — limite commerciale — S03 PDF p.56 M64/60 — Turbo 408 ch Valeur de capacité du système turbo, pas de résistance validée du moteur.
Upgrade BorgWarner | 5324-988-7003 + 7004 | Fabricant — aftermarket — S03 PDF p.56 K24 upgrade
Limite commerciale upgrade | 555 hp selon catalogue | Fabricant — aftermarket — S03 PDF p.56 K24 upgrade
Max. T3 continu / temporaire | 950 / 980 °C | Fabricant — tableau upgrade — S03 PDF p.56 Ligne upgrade 993 du catalogue Ni température réelle mesurée sur K16 de série, ni température métal, ni certificat de matériau.
Allumeur Turbo | Un : 993 602 016 00 | Usine vérifié — S02 PDF p.596 / planche 901-01 M64/60 — Turbo 408 ch Allumage simple : ne pas copier les 12 bougies de la Carrera atmosphérique.
Bobine Turbo | Une : 993 602 073 00 | Usine vérifié — S02 PDF p.596 / planche 901-01 M64/60 — Turbo 408 ch Allumage simple : ne pas copier les 12 bougies de la Carrera atmosphérique.
Nombre de bougies Turbo | 6 | Usine vérifié — S02 PDF p.596 / planche 901-01 M64/60 — Turbo 408 ch Allumage simple : ne pas copier les 12 bougies de la Carrera atmosphérique.
Bougie cataloguée | 999 170 195 90 / 14FR 6LDU | Usine vérifié — S02 PDF p.596 / planche 901-01 M64/60 — Turbo 408 ch Allumage simple : ne pas copier les 12 bougies de la Carrera atmosphérique.
Ordre d’allumage | 1–6–2–4–3–5 | M64 — à confirmer dans manuel Turbo — S06 D-4 M64/60 — Turbo 408 ch S06 concerne Carrera ; aucune fiche d’ordre d’allumage M64.60 distincte obtenue.
Arbres à cames | Un par banc, entraînement par chaînes doubles | Architecture recoupée — S02; S05 Groupes distribution ; S05 p.56 imprimée M64/60 — Turbo 408 ch Les levées et angles de la Carrera ne sont pas transposés au M64.60.
Rattrapage du jeu | Hydraulique | Usine vérifié — S01 PDF p.7 M64/60 — Turbo 408 ch
Poussoir Turbo standard | 993 105 141 03 | Usine vérifié — S08 PDF p.1 M64/60 — Turbo 408 ch
Poussoir Turbo taille 1 | 993 105 141 50 | Usine vérifié — S08 PDF p.1 M64/60 — Turbo 408 ch
Poussoir Turbo taille 2 | 993 105 141 60 | Usine vérifié — S08 PDF p.1 M64/60 — Turbo 408 ch
Exception calage AAC MY1996 | Moteurs 61T00500 à 61T00657 : contrôle au comparateur | Usine vérifié — S11 PDF p.1 M64/60 — Turbo 408 ch Erreur possible de position de rainure ; manuel Turbo p.15-13 à 15-18. Pas de valeur de calage chiffrée dans ce bulletin.
Rapport alternateur / vilebrequin | 2.68 :1 | Usine vérifié — S07 PDF p.1 M64/60 — Turbo 408 ch Rapport théorique, glissement de courroie non inclus.
Courroie alternateur révisée | 999 192 372 50 | Usine vérifié — S07 PDF p.1 M64/60 — Turbo 408 ch Rapport théorique, glissement de courroie non inclus.
Longueur courroie alternateur révisée | 757 mm | Usine vérifié — S07 PDF p.1 M64/60 — Turbo 408 ch Rapport théorique, glissement de courroie non inclus.
Demi-poulies alternateur révisées | 993 106 268 01 | Usine vérifié — S07 PDF p.1 M64/60 — Turbo 408 ch Rapport théorique, glissement de courroie non inclus.
Épaisseurs de cales disponibles | 0,5 / 0,7 mm | Usine vérifié — S07 PDF p.1 M64/60 — Turbo 408 ch Rapport théorique, glissement de courroie non inclus.
Ventilateur Turbo | 964 106 015 21 / 22 | Usine vérifié — S02 PDF p.78 / planche 105-00 M64/60 — Turbo 408 ch Pièces spécifiques M64.60 ; 96410601531 et 99310666703 concernent d’autres affectations dans ce PET.
Carter ventilateur Turbo | 993 106 667 50 | Usine vérifié — S02 PDF p.78 / planche 105-00 M64/60 — Turbo 408 ch Pièces spécifiques M64.60 ; 96410601531 et 99310666703 concernent d’autres affectations dans ce PET.
Demi-poulie ventilateur intérieure Turbo | 993 106 509 50 | Usine vérifié — S02 PDF p.78 / planche 105-00 M64/60 — Turbo 408 ch Pièces spécifiques M64.60 ; 96410601531 et 99310666703 concernent d’autres affectations dans ce PET.
Demi-poulie ventilateur extérieure Turbo | 993 106 510 50 | Usine vérifié — S02 PDF p.78 / planche 105-00 M64/60 — Turbo 408 ch Pièces spécifiques M64.60 ; 96410601531 et 99310666703 concernent d’autres affectations dans ce PET.
Courroie ventilateur Turbo | 999 192 343 50 — 9,5 × 760 mm | Usine vérifié — S02 PDF p.78 / planche 105-00 M64/60 — Turbo 408 ch Pièces spécifiques M64.60 ; 96410601531 et 99310666703 concernent d’autres affectations dans ce PET.
Accès à la courroie | Console climatisation parfois à reprendre pour dégagement | Usine vérifié — S12 PDF p.1 M64/60 — Turbo 408 ch Bulletin MY1996 ; contient une illustration de la zone, pas de cote de reprise.
Vilebrequin catalogue à partir de 1995 | 993 102 021 02 | Usine vérifié — S02 PDF p.43–52 M64/60 — Turbo 408 ch
Volant bimasse M64.60 | 996 114 012 50 | Usine vérifié — S02 PDF p.43–52 M64/60 — Turbo 408 ch
Bielle, familles révisées | 993 103 020 64 à 69 | Usine vérifié — S02 PDF p.43–52 M64/60 — Turbo 408 ch
Classes de masse bielles révisées | 534–540 / 540–546 / 546–552 / 552–558 / 558–564 / 564–570 g | Usine vérifié — S02 PDF p.43–52 M64/60 — Turbo 408 ch
Seuil moteur de bielle révisée pour Turbo | M 61T 00932 >> | Usine vérifié — S02 PDF p.43–52 M64/60 — Turbo 408 ch
Ensemble cylindre/piston Turbo groupe 5 jusqu’à MY1996 | 993 103 915 51 / 52 | Usine vérifié — S02 PDF p.43–52 M64/60 — Turbo 408 ch
Ensemble cylindre/piston Turbo groupe 5 dès MY1997 | 993 103 915 56 / 57 | Usine vérifié — S02 PDF p.43–52 M64/60 — Turbo 408 ch
Classes de masse piston Turbo cataloguées | 576–584 / 584–592 g | Usine vérifié — S02 PDF p.43–52 M64/60 — Turbo 408 ch Les classes de masse de l’ensemble vendu ne définissent pas une pesée de piston nu. Les références dépendent du groupe et du millésime.
Joint de pied cylindre | 999 707 152 40 — 102 × 2 mm | Usine vérifié — S02 PDF p.43–52 M64/60 — Turbo 408 ch
Joint de culasse | 964 104 115 20 — quantité 6 | Usine vérifié — S02 PDF p.43–52 M64/60 — Turbo 408 ch
Guide-air Turbo | 993 106 257 51 — quantité 6 | Usine vérifié — S02 PDF p.43–52 M64/60 — Turbo 408 ch
Culasse M64.60 | 993 104 033 52 / 993 104 053 52 | Usine vérifié — S02 PDF p.35 et 54 M64/60 — Turbo 408 ch
Soupape admission M64.60 | 993 105 409 02 — quantité 6 | Usine vérifié — S02 PDF p.35 et 54 M64/60 — Turbo 408 ch
Soupape échappement M64.60 | 993 105 419 52 — quantité 6 | Usine vérifié — S02 PDF p.35 et 54 M64/60 — Turbo 408 ch
Jeu ressorts de soupape | 993 105 901 51 — quantité 12 | Usine vérifié — S02 PDF p.35 et 54 M64/60 — Turbo 408 ch
Écrou culasse M64.60 | 993 104 382 53 — quantité 24 | Usine vérifié — S02 PDF p.35 et 54 M64/60 — Turbo 408 ch
Goujons de culasse M64.60 | 993 101 170 51 / 53 — quantité 24 | Usine vérifié — S02 PDF p.35 et 54 M64/60 — Turbo 408 ch
Goujons Dilavar | Famille Dilavar ; substitution 93010117002 → 99310117051 | Usine recoupé — S02; S16 PET p.35 ; bulletin p.1 M64/60 — Turbo 408 ch Nuance chimique et propriétés métallurgiques exactes non publiées dans ces documents.
Carter moteur | Alliage aluminium–silicium, deux demi-carters | Architecture M64 recoupée — S02; S05 S05 PDF p.57 / page imprimée 53 M64/60 — Turbo 408 ch Chapitre Carrera ; le PET partage les familles carter. Nuance OEM et procédé exact Turbo non établis ici.
Vilebrequin / bielles | Forgeage documenté dans la famille M64 | Architecture M64 — recoupement — S05; S06; S02 S06 D-2 ; PET 102-00 M64/60 — Turbo 408 ch La composition exacte de l’acier, le traitement et la dureté d’origine Turbo restent à obtenir.
Cylindres Turbo | Cylindres pressés selon brochure ; alliage léger | Usine / architecture recoupée — S01; S05 S01 PDF p.7 M64/60 — Turbo 408 ch Brochure « pressed cylinders ». Nikasil explicitement documenté sur Carrera dans S05, pas confirmé ici par une fiche spécifique Turbo.
Couvre-arbres polyamide renforcé fibre de verre | Documenté pour Carrera 993 | Contexte Carrera uniquement — S05 PDF p.63 / imprimée p.59 Carrera 993 Ne permet pas de qualifier tous les couvercles de la Turbo.
Sorties optionnelles XLB | Acier inoxydable chromé | Usine vérifié — S23 PDF p.1 993 Turbo, option XLB Références gauche 99311198103, droite 99311198203 ; nuance inox non précisée.
Soupape admission de remplacement | Tête 49 ; queue 8 mm | Déclaration vendeur existante — SRC-FVD-993-INLET-VALVE-DIMENSIONS FVD 99310540902EQ1, remplacement M64.60 Le produit est explicitement non refroidi au sodium ; ne pas assimiler son matériau ou sa masse à l’OEM.
Soupape échappement de remplacement | Longueur 108,9 ; tête 43,5 ; queue 8 mm | Déclaration vendeur existante — SRC-PARTWORKS-993-EXHAUST-VALVE-DIMENSIONS SM Motorenteile / partworks pour Turbo 408 ch Pas de tolérances ni de preuve métallurgique. Diffère de la soupape Carrera tête 42,5 mm.
Piston MAHLE 3,8 L | 2618 ; 468 g ; axe 23 mm | Aftermarket déjà référencé — S19 PP102-012N / LN105-102/109, alésage 102 mm Aucune de ces valeurs ne prouve l’alliage ni la masse du piston 3,6 L de série.
Support moteur révisé | 964 375 043 81 ; remplacement par paire | Usine vérifié — S14 PDF p.1 Turbo S / Turbo X73 MY1997–1998
Rondelles support moteur révisé | 45.5 mm | Usine vérifié — S14 PDF p.1 Turbo S / Turbo X73 MY1997–1998 Ancienne rondelle 34 mm ; ne pas extrapoler aux interfaces de fixation.
Vis support moteur version X73 / S | M12 × 1,5 × 125 mm | Usine vérifié — S14 PDF p.1 Turbo S / Turbo X73 MY1997–1998 Corps du bulletin ; table de pièces comporte 1,2 au lieu de 1,5, contradiction conservée dans l’audit.
Banc à rouleaux — bulletin historique | Porsche déconseille le test de la nouvelle Turbo | Usine vérifié — S15 PDF p.1 M64/60 — Turbo 408 ch Air de charge insuffisamment refroidi → baisse puissance et surchauffe ; transmission / glissement des pneus. Ce n’est pas une certification d’un banc moderne.
Cylindrée géométrique | 3600.2652 cm³ | Calcul — S01; S04 Formule dans commentaire M64/60 — Turbo 408 ch π/4 × 100² × 76,4 × 6, unités mm.
Cylindrée unitaire | 600.0442 cm³ | Calcul — S01; S04 Formule dans commentaire M64/60 — Turbo 408 ch Cylindrée géométrique / 6.
Rayon de manivelle | 38.2 mm | Calcul — S01; S04 Formule dans commentaire M64/60 — Turbo 408 ch Course / 2.
Volume résiduel théorique à 8:1 | 85.7206 cm³ / cylindre | Calcul — S01; S04 Formule dans commentaire M64/60 — Turbo 408 ch Vd/(r−1) ; volume total au PMH, pas le volume nu de la culasse.
Puissance spécifique | 83.3333 kW/L | Calcul — S01; S04 Formule dans commentaire M64/60 — Turbo 408 ch Puissance nominale / cylindrée publiée.
Couple spécifique | 150.0 N·m/L | Calcul — S01; S04 Formule dans commentaire M64/60 — Turbo 408 ch Couple maximal / cylindrée publiée.
Pression moyenne effective au couple maximal | 18.8496 bar | Calcul — S01; S04 Formule dans commentaire M64/60 — Turbo 408 ch BMEP = 4πT/V pour moteur 4 temps ; ce n’est pas la pression maximale de combustion.
Couple correspondant à 300 kW et 5750 tr/min | 498.2242 N·m | Calcul — S01; S04 Formule dans commentaire M64/60 — Turbo 408 ch T = P/ω.
Puissance à 540 Nm et 4500 tr/min | 254.469 kW | Calcul — S01; S04 Formule dans commentaire M64/60 — Turbo 408 ch P = Tω ; n’est pas la puissance maximale.
Pression admission absolue avec 0,8 bar de boost | 1.8 bar | Calcul — S01; S04 Formule dans commentaire M64/60 — Turbo 408 ch Hypothèse ambiance 1,0 bar ; la vraie pression dépend de l’ambiante.
Intervalle moyen entre combustions | 120 degrés vilebrequin | Calcul — S01; S04 Formule dans commentaire M64/60 — Turbo 408 ch 720° / 6 pour allumage régulier.
Alternateur à 1000 tr/min moteur | 2680.0 tr/min | Calcul — S01; S07; S02 M64/60 — Turbo 408 ch Sans glissement de courroie ; distribution 4 temps, architecture M64
Arbres à cames à 1000 tr/min moteur | 500.0 tr/min | Calcul — S01; S07; S02 M64/60 — Turbo 408 ch Sans glissement de courroie ; distribution 4 temps, architecture M64
Allumeur à 1000 tr/min moteur | 500.0 tr/min | Calcul — S01; S07; S02 M64/60 — Turbo 408 ch Sans glissement de courroie ; distribution 4 temps, architecture M64
Vitesse moyenne piston à 1000 tr/min moteur | 2.5467 m/s | Calcul — S01; S07; S02 M64/60 — Turbo 408 ch Sans glissement de courroie ; distribution 4 temps, architecture M64
Combustions de tout le moteur à 1000 tr/min moteur | 50.0 Hz | Calcul — S01; S07; S02 M64/60 — Turbo 408 ch Sans glissement de courroie ; distribution 4 temps, architecture M64
Alternateur à 4500 tr/min moteur | 12060.0 tr/min | Calcul — S01; S07; S02 M64/60 — Turbo 408 ch Sans glissement de courroie ; distribution 4 temps, architecture M64
Arbres à cames à 4500 tr/min moteur | 2250.0 tr/min | Calcul — S01; S07; S02 M64/60 — Turbo 408 ch Sans glissement de courroie ; distribution 4 temps, architecture M64
Allumeur à 4500 tr/min moteur | 2250.0 tr/min | Calcul — S01; S07; S02 M64/60 — Turbo 408 ch Sans glissement de courroie ; distribution 4 temps, architecture M64
Vitesse moyenne piston à 4500 tr/min moteur | 11.46 m/s | Calcul — S01; S07; S02 M64/60 — Turbo 408 ch Sans glissement de courroie ; distribution 4 temps, architecture M64
Combustions de tout le moteur à 4500 tr/min moteur | 225.0 Hz | Calcul — S01; S07; S02 M64/60 — Turbo 408 ch Sans glissement de courroie ; distribution 4 temps, architecture M64
Alternateur à 5750 tr/min moteur | 15410.0 tr/min | Calcul — S01; S07; S02 M64/60 — Turbo 408 ch Sans glissement de courroie ; distribution 4 temps, architecture M64
Arbres à cames à 5750 tr/min moteur | 2875.0 tr/min | Calcul — S01; S07; S02 M64/60 — Turbo 408 ch Sans glissement de courroie ; distribution 4 temps, architecture M64
Allumeur à 5750 tr/min moteur | 2875.0 tr/min | Calcul — S01; S07; S02 M64/60 — Turbo 408 ch Sans glissement de courroie ; distribution 4 temps, architecture M64
Vitesse moyenne piston à 5750 tr/min moteur | 14.6433 m/s | Calcul — S01; S07; S02 M64/60 — Turbo 408 ch Sans glissement de courroie ; distribution 4 temps, architecture M64
Combustions de tout le moteur à 5750 tr/min moteur | 287.5 Hz | Calcul — S01; S07; S02 M64/60 — Turbo 408 ch Sans glissement de courroie ; distribution 4 temps, architecture M64
Alternateur à 6500 tr/min moteur | 17420.0 tr/min | Calcul — S01; S07; S02 M64/60 — Turbo 408 ch 6500 tr/min est un exemple de calcul, pas un régime limite confirmé
Arbres à cames à 6500 tr/min moteur | 3250.0 tr/min | Calcul — S01; S07; S02 M64/60 — Turbo 408 ch 6500 tr/min est un exemple de calcul, pas un régime limite confirmé
Allumeur à 6500 tr/min moteur | 3250.0 tr/min | Calcul — S01; S07; S02 M64/60 — Turbo 408 ch 6500 tr/min est un exemple de calcul, pas un régime limite confirmé
Vitesse moyenne piston à 6500 tr/min moteur | 16.5533 m/s | Calcul — S01; S07; S02 M64/60 — Turbo 408 ch 6500 tr/min est un exemple de calcul, pas un régime limite confirmé
Combustions de tout le moteur à 6500 tr/min moteur | 325.0 Hz | Calcul — S01; S07; S02 M64/60 — Turbo 408 ch 6500 tr/min est un exemple de calcul, pas un régime limite confirmé
Rapport de vitesse ventilateur conditionnel | 1.84 :1 | Hypothèse non validée — S01; S06 M64/60 — Turbo 408 ch 1,6 × 1,15 ; seulement si la référence du +15 % est exactement la Carrera à 1,6. Ne pas publier 1,84 comme ratio usine Turbo.
Arbre turbo | Turbine et compresseur du même turbo : même régime | Relation mécanique — S20; S21 M64/60 — Turbo 408 ch Aucun rapport fixe au vilebrequin. Les deux turbos ne sont pas mécaniquement synchronisés.
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

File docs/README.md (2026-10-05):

# Documentation index

Every document in `docs/`, grouped by what you are trying to do. Progress of the translation: [TRANSLATION.md](TRANSLATION.md).

```mermaid
flowchart LR
    A["Rules<br/><sub>charter · safety · gates</sub>"] --> B["Sources<br/><sub>policy · inventory · research</sub>"]
    B --> C["Design<br/><sub>993 dossiers · part pages</sub>"]
    C --> D["Digital twin<br/><sub>twin · stack · compute</sub>"]
    D --> E["Analysis<br/><sub>FEA · CFD · AM pipeline</sub>"]
    E --> F["Decisions & reports<br/><sub>ADRs · dated reports</sub>"]
```

## Start here

| document | what it answers |
|---|---|
| [../README.md](../README.md) | what the repository is, and what it has found |
| [PROJECT_CHARTER.md](PROJECT_CHARTER.md) | why the project exists and what it will not do |
| [../SAFETY.md](../SAFETY.md) | what may be built, what may not, and why |
| [QUALITY_GATES.md](QUALITY_GATES.md) | what a part must prove at each level |
| [WORKFLOW.md](WORKFLOW.md) | how a part goes from idea to record |
| [../CONTRIBUTING.md](../CONTRIBUTING.md) | how to contribute a part, a source or a fix |
| [TRANSLATION.md](TRANSLATION.md) | the French-to-English translation: scope, glossary, progress |
| [GALLERY.md](GALLERY.md) | every figure, render and print screen on one page |
| [../twins/README.md](../twins/README.md) | the digital twins, zone by zone |
| [FAN_DEVELOPMENT_PROGRAMMES.md](FAN_DEVELOPMENT_PROGRAMMES.en.md) | the two improved cooling programmes: vertical 993 and complete horizontal 935 architecture |

## Sources and measurement

| document | what it answers |
|---|---|
| [SOURCE_POLICY.md](SOURCE_POLICY.md) | which sources are admissible, and how rights are recorded |
| [PHASE1_SOURCE_INVENTORY.md](PHASE1_SOURCE_INVENTORY.md) | the phase 1 source inventory |
| [MEASUREMENT_CAMPAIGN.md](MEASUREMENT_CAMPAIGN.md) | the phase 2 measurement campaign |
| [research/935-horizontal-cooling/README.md](research/935-horizontal-cooling/README.en.md) | research and reconstruction for a lighter, improved horizontal 935 cooling system |
| [PORSCHEFANATICS_993_TURBO_AUDIT.md](PORSCHEFANATICS_993_TURBO_AUDIT.md) | local audit of a 993 Turbo source |
| [research/](research/) | source research by topic (German-language sources, carbon panels, M64 reviews, scans) |

## Parts and design

| document | what it answers |
|---|---|
| [pieces/](pieces/) | one generated page per part record: status, material, sources, evidence |
| [993/](993/) | the design dossiers of the 993 parts (`*_F0`, `*_F1`) |
| [TITANIUM.md](TITANIUM.md) | when titanium is justified, and when it is not |
| [COMPONENT_INVENTORY.md](COMPONENT_INVENTORY.md) | the twin's physical components |
| [AM_VALIDATION_PIPELINE.md](AM_VALIDATION_PIPELINE.md) | the mandatory metal printing and Omniverse pipeline |

## 964/993 monocoque

| document | what it answers |
|---|---|
| [MONOCOQUE_964_993_PROGRAMME.md](MONOCOQUE_964_993_PROGRAMME.md) | the carbon monocoque program and what it must establish |
| [MONOCOQUE_964_993_ARCHITECTURE.md](MONOCOQUE_964_993_ARCHITECTURE.md) | architecture concept and layup strategy |
| [MONOCOQUE_964_993_CHAINE_CALCUL.md](MONOCOQUE_964_993_CHAINE_CALCUL.md) | the analysis chain: who does what, and where something else is needed |

## Digital twin and compute

Start with the [M64 architecture](architecture/README.md), its
[workflow](architecture/engineering-workflow.md) and
[migration/verification plan](architecture/migration-verification.md).
The [local Qwen pilot](../training/m64-qwen/README.md) implements the first AI increment.

| document | what it answers |
|---|---|
| [DIGITAL_TWIN.md](DIGITAL_TWIN.md) | the 993 digital twin, its zones and levels |
| [SOFTWARE_STACK.md](SOFTWARE_STACK.md) | the twin's software stack |
| [AI_DIGITAL_TWIN_STACK.md](AI_DIGITAL_TWIN_STACK.md) | the open-source suite for building the twin |
| [QWEN_TRAINING.md](QWEN_TRAINING.md) | how Qwen was trained, the actual datasets and results, and the next experiments for the 993 project |
| [TOOLCHAIN.md](TOOLCHAIN.md) | the local CAD and analysis toolchain |
| [COMPUTE_ENVIRONMENT.md](COMPUTE_ENVIRONMENT.md) | compute environment and images |
| [GITHUB_OPENBAO_WRAPPER.md](GITHUB_OPENBAO_WRAPPER.md) | the GitHub wrapper bounded by OpenBao |

## 993 Turbo and forced induction

| document | what it answers |
|---|---|
| [TURBO_DIGITAL_TWIN_PLAN.md](TURBO_DIGITAL_TWIN_PLAN.md) | data plan for the 993 Turbo twin |
| [TURBO_AIRFLOW_SIMULATION_DATA.md](TURBO_AIRFLOW_SIMULATION_DATA.md) | airflow simulation data |
| [research/993-turbo-20261002/README.md](research/993-turbo-20261002/README.md) | sourced M64/60 engine research, K16 hybrid/map leads and training-data package |
| [research/mezger-turbo-materials-20261003/README.md](research/mezger-turbo-materials-20261003/README.md) | turbo and racing engine variants, scoped alloy/process/thickness evidence and separate training increment |
| [research/mezger-german-sources-20261003/README.md](research/mezger-german-sources-20261003/README.md) | German primary sources: RR350/2618A grade data, magnesium-case manufacture, hybrid-wheel declarations and racing comparisons |
| [OPENFOAM_POISEUILLE_VERIFICATION_F25.md](OPENFOAM_POISEUILLE_VERIFICATION_F25.md) | OpenFOAM verification against Poiseuille flow |

## Decisions and reports

| document | what it answers |
|---|---|
| [decisions/](decisions/) | numbered architecture decisions (ADR 0001–0011) |
| [reports/](reports/README.md) | dated execution and audit reports, indexed by day |
| [media/](media/) | diagrams and video projects |

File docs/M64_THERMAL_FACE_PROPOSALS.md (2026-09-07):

# Groupes candidats de surfaces pour la préparation CHT

7 septembre 2026. Il s'agit de **propositions de provenance géométrique** du
STEP F53, pas d'affectations physiques ni d'une validation du M64. Aucune
température, conductivité, précharge ou condition de convection n'est définie.

Provenance du scan : Wolfe Classics, source catalogue
`SRC-WOLFE-CLASSICS-935-BILLET-CYLINDER-HEAD-SCAN`. Réutilisation confirmée par
le propriétaire selon ce registre ; texte exact de licence non archivé.
Les données géométriques détaillées restent privées ; l'image est un rendu
diagnostique original de la reconstruction, pas une nouvelle mesure Porsche.

## Méthode exécutée

`propose_thermal_face_groups.py` vérifie les empreintes du STEP F53, des deux
inventaires, du contrat F47 et de son constructeur avant tout classement.

1. Une face F53 est rapprochée des faces F43 par type de surface, boîte
   englobante, centre et aire. Une correspondance unique devient une
   **candidate héritée**, pas automatiquement une ailette refroidie par air.
2. Les faces non appariées sont échantillonnées sur leur surface OCCT exacte :
   grille UV 5 × 5 limitée aux points intérieurs à la face découpée, plus tous
   ses sommets. Les coordonnées ne viennent pas du rendu triangulé.
3. Chaque échantillon est confronté aux supports **finis** des cylindres de
   construction F47 : paroi latérale ou disque de fermeture. Sont distingués
   chambres/registres, conduits, poches de sièges, guides, bougie et galerie
   d'huile. Un point sur la prolongation infinie du cylindre ne suffit pas.
4. Pour les surfaces restantes, les distances des mêmes échantillons aux
   faces F43 découpées sont évaluées après filtrage spatial. Un seul appariement
   admissible propose une surface héritée puis retaillée. Un plan horizontal
   demeure explicitement fonctionnellement indéterminé.

Tolérance géométrique : 10⁻⁴ unité du scan ; les signatures demandent aussi
l'accord relatif des aires à 10⁻⁷. Les distances point–face utilisent
[OCCT BRepExtrema_DistShapeShape](https://occt3d.com/dev/doc/refman/html/class_b_rep_extrema___dist_shape_shape.html).
Les contrôles sont échantillonnés : ils ne constituent pas une preuve
d'identité exhaustive des surfaces ni une preuve de leur usage thermique.

Les paramètres F47 sont ceux d'un ancien **candidat de recherche**, notamment
son alésage de 90 unités du scan. Leur usage ici sert uniquement à retrouver
ce qui a construit F53 : ils ne sont pas copiés dans le contrat moteur M64.
La hauteur de départ des conduits est explicitement liée à la constante du
constructeur historique, dont le hash est enregistré.

## Entrées et preuve de l'enveloppe

- STEP F53 : `700baea66bc72cdb6aee529e21b167270ebde11db94b06f8e1e55ee08bdd9bf2`.
- Inventaire F53 : `849ab37dad9df0e14c038d430dd2d39d72251f0a1db5ac7f99b65c85a8694423`.
- Enveloppe F43 rejouée sur Kali : `00c26d32820b23b3589beb7b26d34bc3eb176a89000b9374ffdbe334278b41ef`.
- Inventaire F43 : `898841ec21ee995521f783499477ece8836709c5a1b8cbc5bc231fe3d93ed977`.
- Contrat F47 : `cdf1c54c038994d12ba1e6d726746240a270e1d1683ffe5409db27bc4ea5693e`.
- Constructeur F47 : `9a418c5210b4e89c4fd5646a0533a4afd7a6ac7683363d6e23631151faf5d0fb`.

Le hash historique F43 `38f8ed…` n'est pas renommé : le rapport
`evidence/f43-scan-contour-patch/f43-scan-contour-patch-report.json` documente
le rejeu sous Gmsh 4.12.1 et son hash différent. Le rapprochement actuel porte
sur la géométrie effectivement présente, pas une égalité binaire supposée.

## Premier résultat, avant rapprochement des surfaces retaillées

| Groupe candidat | Faces |
| --- | ---: |
| Surface héritée par signature | 4 583 |
| Chambre / registre | 2 |
| Admission | 14 |
| Échappement | 14 |
| Logements de sièges | 12 |
| Guides / perçages ouverts | 4 |
| Bougie | 1 |
| Galerie et accès huile | 7 |
| Non résolu | 292 |

Les 292 faces non résolues représentent 30 652,86 unités², soit environ
21,2 % de l'aire. Deux grands plans représentent à eux seuls 27 489,87 unités².
Un faible nombre de faces ambiguës peut donc dominer le bilan thermique :
**un pourcentage de faces classées ne remplace pas une couverture par aire**.

Le premier calcul et son rendu sont conservés sous
`/tmp/917-f50/out/m64-thermal-face-proposals-20260907/` sur Kali.
Le second rapprochement utilise un répertoire distinct afin de conserver la
comparaison. Les sorties détaillées contiennent des indices et informations
de géométrie privée ; seules les images et agrégats peuvent rejoindre le dépôt.
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

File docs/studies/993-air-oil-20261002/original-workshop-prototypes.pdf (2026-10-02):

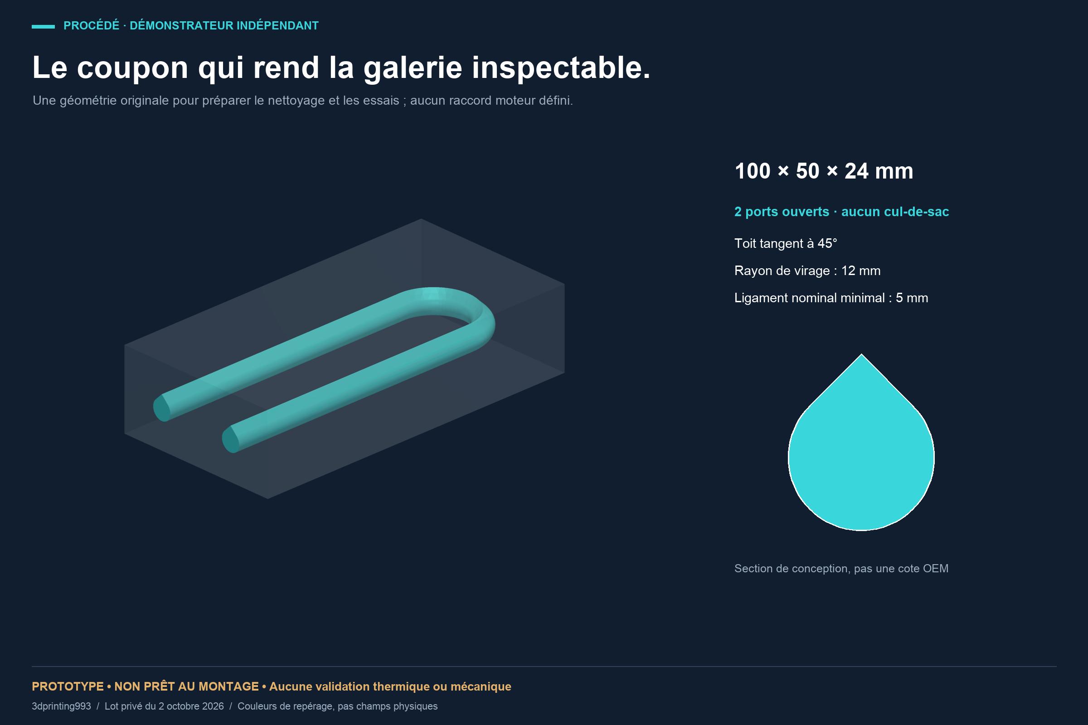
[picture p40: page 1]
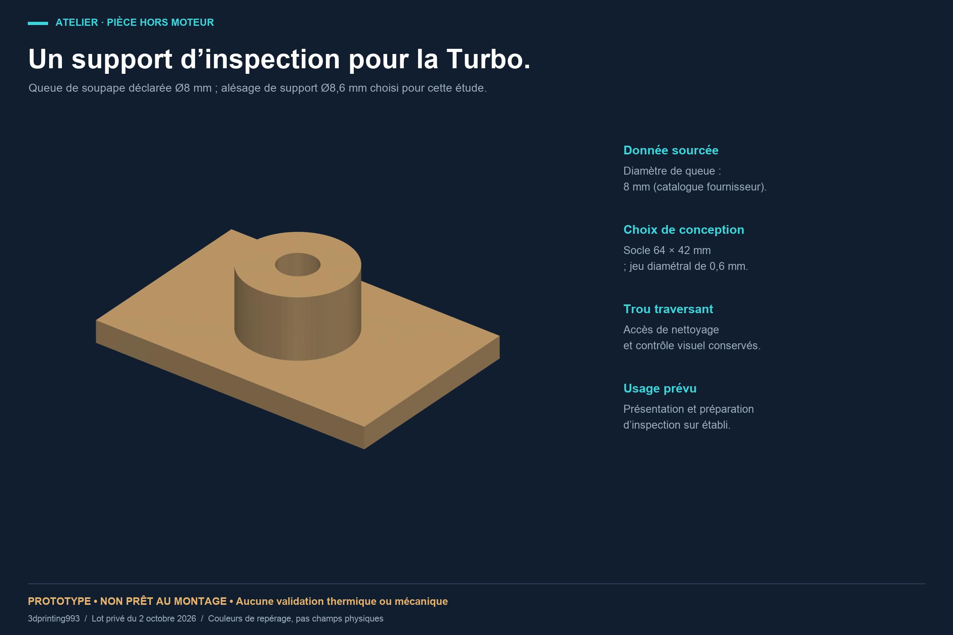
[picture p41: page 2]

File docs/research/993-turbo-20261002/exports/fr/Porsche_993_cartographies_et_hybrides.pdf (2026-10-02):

993 Turbo • Cartographies et hybrides • Recherche du 02/10/2026 | 1

# Porsche 993 Turbo Cartographies et K16 hybrides

### Complément de recherche • M64/60, 3,6 litres • 2 octobre 2026

Objectif confirmé : plus de 550 ch au vilebrequin, priorité à la puissance, réemploi des turbos d’origine pour hybridation.

Résultat : TTE650 et TTH K16-650 décrivent des offres spécifiques à la 993, annoncées à 650 PS, réalisées à partir de K16 originaux. Elles correspondent au principe de votre projet. Les fiches consultées ne fournissent toutefois ni carte compresseur, ni carte turbine, ni jeu complet de mesures validant ces puissances sur un moteur donné.

Une vraie carte historique KKK 2467 GGA/GGB est publique chez SJM. Son rapprochement avec la famille du K16 de 993 est intéressant, mais elle est publiée pour le turbo 5316-988-6717, différent des 6735/6736. Elle doit rester une carte candidate tant que les roues et carters ne sont pas identifiés.
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

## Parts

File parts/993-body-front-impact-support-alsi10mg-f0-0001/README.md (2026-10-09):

<!-- generated by scripts/render_part_pages.py - do not edit by hand -->

<div align="center">

# 993 front impact support, AlSi10Mg graded-core concept F0

**`993-BODY-FRONT-IMPACT-SUPPORT-ALSI10MG-F0-0001`** · Porsche 993 · 1994–1998

  

</div>

> [!CAUTION]
> **Not ready to print, and not a copy of the original part.** The model shown here is a
> concept block for studying the part in software:
> - validation status `concept`: nothing has been checked against a real part;
> - geometry `mixed`: its dimensions are partly sourced, partly assumed, not measured on the original part;
> - safety class `prohibited_pending_engineering`;
> - no part in this repository is released — read [SAFETY.md](../../SAFETY.md).

<table><tr>
<td width="50%" valign="top">
<b>Original part</b><br><br>
The original part is documented — pictures, catalogue entries or published data — on these pages. They are copyrighted, so they are linked here, not copied:<br><br>
↗ <a href="https://porschefanatics.com/993/">PorscheFanatics - lightweight 993 front bumper support</a><br>
↗ <a href="https://www.fvd.net/de-ch/shop/prallrohr-993-vorne-alu-1stk-ca-145-gr-fvd50501700~p237473">FVD - 993 aluminum front impact support</a><br>
</td>
<td width="50%" valign="top" align="center">
<b>This repository's concept model</b><br><br>
Concept CAD block for 993 front impact support, AlSi10Mg graded-core concept F0<br>
<sub>Concept CAD block, 139.3 × 100.1 × 53.0 mm — <b>not</b> the original part, not a print file, not evidence of fit.</sub>
</td>
</tr></table>

> [!CAUTION]
> **Prohibited pending engineering** — risk, or insufficient data. Never published as a released part.

## What it is

Independent front support concept with an elliptical shell and a graded open cruciform core, used to screen the value of LPBF AlSi10Mg. PorscheFanatics corroborates the lightweight FVD support at 145 g; FVD publishes a 139 x 100 x 53 mm envelope and states only aluminum, with no alloy and no interface geometry.

## What it does on the car

CAD, mass, stability, energy and DfAM screening only; manufacture, fitting, driving and impact testing prohibited without an approved crash program

## At a glance

| | |
|---|---|
| Porsche part numbers | not recorded |
| variants | `993_Carrera`, `993_Turbo`, `993_GT2` |
| candidate material | generic screening AlSi10Mg |
| candidate process | undecided |
| safety class | `prohibited_pending_engineering` |
| validation status | `concept` |
| geometry | mixed, master build123d |

## Where it stands

```mermaid
flowchart LR
    L0["concept"]
    L1["dimensionally_reviewed"]
    L2["prototype_fitted"]
    L3["functionally_tested"]
    L4["engineering_reviewed"]
    L5["released"]
    L0 --> L1 --> L2 --> L3 --> L4 --> L5
    X["⛔ prohibited pending engineering"]
    L0 -. blocked .-> X
    classDef here fill:#fff4d6,stroke:#b7791f,color:#1a1a1a,stroke-width:3px;
    classDef done fill:#e3f1e6,stroke:#2e7d32,color:#1a1a1a;
    classDef todo fill:#f4f4f4,stroke:#9e9e9e,color:#6b6b6b;
    classDef stop fill:#fde2e1,stroke:#c0392b,color:#1a1a1a;
    class L0 here
    class L1 todo
    class L2 todo
    class L3 todo
    class L4 todo
    class L5 todo
    class X stop
```

*Validation ladder of `catalog/schemas/part.schema.json`; this record is at `concept`.*

## Views

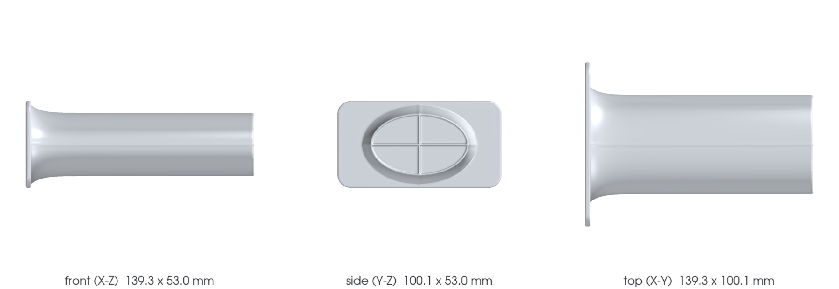
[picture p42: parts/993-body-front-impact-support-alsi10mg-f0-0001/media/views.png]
Front, side and top orthographic views


*Orthographic views of the same concept CAD, with its bounding dimensions — not drawings of the original part.*

## Screens and evidence images

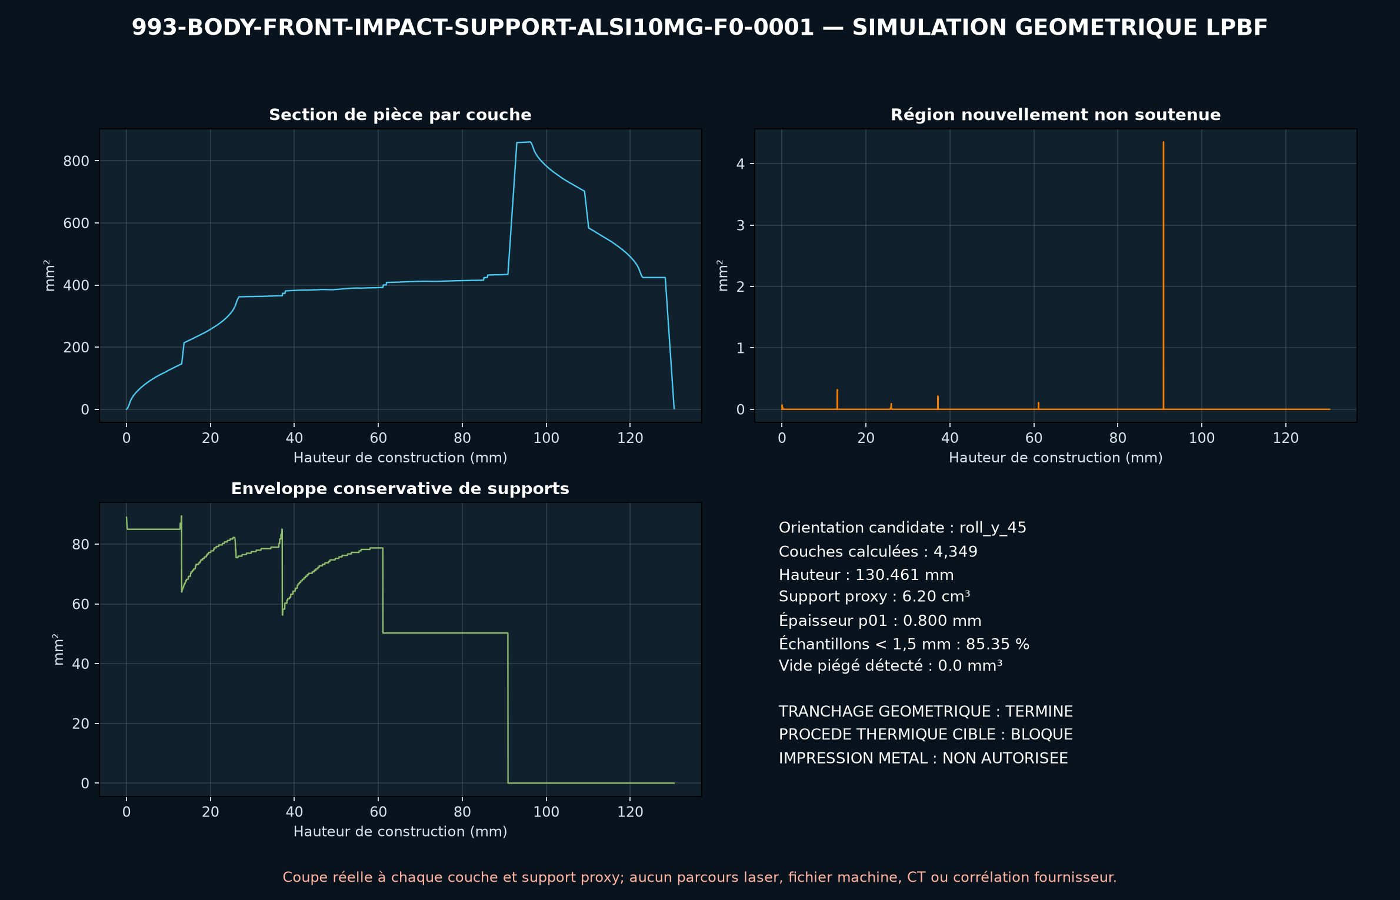
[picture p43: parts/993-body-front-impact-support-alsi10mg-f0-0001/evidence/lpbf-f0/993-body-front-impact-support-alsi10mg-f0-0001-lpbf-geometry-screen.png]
993-body-front-impact-support-alsi10mg-f0-0001-lpbf-geometry-screen


*`evidence/lpbf-f0/993-body-front-impact-support-alsi10mg-f0-0001-lpbf-geometry-screen.png` — a screening output, not a validation.*

## What's in this folder

| folder | what it holds | files |
|---|---|---|
| `derived/` | CAD exports generated from the source (STEP for CAD tools, STL for meshing) | [`derived/front_impact_support_alsi10mg_f0-picogk.json`](derived/front_impact_support_alsi10mg_f0-picogk.json), [`derived/front_impact_support_alsi10mg_f0-picogk.stl`](derived/front_impact_support_alsi10mg_f0-picogk.stl), [`derived/front_impact_support_alsi10mg_f0.step`](derived/front_impact_support_alsi10mg_f0.step), [`derived/front_impact_support_alsi10mg_f0.stl`](derived/front_impact_support_alsi10mg_f0.stl) |
| `evidence/` | screens, reports and manifests — **pinned by SHA-256, never edited by hand** | [`evidence/engineering-screen.json`](evidence/engineering-screen.json), [`evidence/lpbf-f0/993-body-front-impact-support-alsi10mg-f0-0001-layer-metrics.csv`](evidence/lpbf-f0/993-body-front-impact-support-alsi10mg-f0-0001-layer-metrics.csv), [`evidence/lpbf-f0/993-body-front-impact-support-alsi10mg-f0-0001-lpbf-geometry-manifest.json`](evidence/lpbf-f0/993-body-front-impact-support-alsi10mg-f0-0001-lpbf-geometry-manifest.json), [`evidence/lpbf-f0/993-body-front-impact-support-alsi10mg-f0-0001-lpbf-geometry-report.json`](evidence/lpbf-f0/993-body-front-impact-support-alsi10mg-f0-0001-lpbf-geometry-report.json), [`evidence/lpbf-f0/993-body-front-impact-support-alsi10mg-f0-0001-lpbf-geometry-screen.png`](evidence/lpbf-f0/993-body-front-impact-support-alsi10mg-f0-0001-lpbf-geometry-screen.png) |
| `media/` | concept-model views rendered from the CAD by `scripts/render_part_previews.py` — not pictures of the original | [`media/preview.json`](media/preview.json), [`media/preview.png`](media/preview.png), [`media/views.png`](media/views.png) |
| `source/` | parametric source — the editable master that generates the geometry | [`source/front_impact_support.py`](source/front_impact_support.py), [`source/picogk.json`](source/picogk.json) |

## Read more

- **Full description page**, with sources and evidence: [docs/pieces/993-body-front-impact-support-alsi10mg-f0-0001.md](../../docs/pieces/993-body-front-impact-support-alsi10mg-f0-0001.md)
- **Catalogue record** (source of truth): [`catalog/parts/993-body-front-impact-support-alsi10mg-f0-0001.json`](../../catalog/parts/993-body-front-impact-support-alsi10mg-f0-0001.json)
- **Design dossier**: [993_FRONT_IMPACT_SUPPORT_ALSI10MG_F0](../../docs/993/993_FRONT_IMPACT_SUPPORT_ALSI10MG_F0.md)
- **Safety rules**: [SAFETY.md](../../SAFETY.md)

---

*This page is generated from the catalogue record by `scripts/render_part_pages.py` and checked by `make check`. Edit the record, not this page.*

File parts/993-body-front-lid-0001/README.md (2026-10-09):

<!-- generated by scripts/render_part_pages.py - do not edit by hand -->

<div align="center">

# Front lid, composite panel

**`993-BODY-FRONT-LID-0001`** · Porsche 993 · 1994–1998

  

</div>

> [!CAUTION]
> **Not ready to print, and not a copy of the original part.** The model shown here is a
> concept block for studying the part in software:
> - validation status `concept`: nothing has been checked against a real part;
> - geometry `estimated`: its dimensions are estimated design variables, not measured on the original part;
> - safety class `functional`;
> - no part in this repository is released — read [SAFETY.md](../../SAFETY.md).

<table><tr>
<td width="50%" valign="top">
<b>Original part</b><br><br>
The original part is documented — pictures, catalogue entries or published data — on these pages. They are copyrighted, so they are linked here, not copied:<br><br>
↗ <a href="https://psautoart.com/993r/">Paul Stephens Autoart - 993R, body weight reduction</a><br>
↗ <a href="https://www.carscoops.com/2022/08/gunther-werks-project-tornado-is-a-carbon-bodied-porsche-993-turbo-restomod-with-up-to-700-hp/">Specialist press - Gunther Werks, carbon-bodied 993</a><br>
↗ <a href="http://www.federleichte-elfer.de/dp93/aussen.html">Federleichte Elfer - mass table, 993 exterior parts</a><br>
</td>
<td width="50%" valign="top" align="center">
<b>This repository's concept model</b><br><br>
Concept CAD block for Front lid, composite panel<br>
<sub>Concept CAD block, 1250.3 × 1100.3 × 109.7 mm — <b>not</b> the original part, not a print file, not evidence of fit.</sub>
</td>
</tr></table>

> [!NOTE]
> **Functional** — loaded part whose failure can immobilize or damage the vehicle. Published only after documented functional testing.

## What it is

993 front lid reproduced in composite from the original steel panel. Bolted skin part, with no structural function and no anti-intrusion bar, retained as the first lightweight body pilot.

## What it does on the car

Closes the front compartment; the part carries no load, but its retention is a safety matter at high speed

## At a glance

| | |
|---|---|
| Porsche part numbers | 993 511 010 01, 993 511 010 31 |
| variants | `to_confirm_on_vehicle` |
| candidate material | fiber and resin to be determined |
| candidate process | undecided |
| safety class | `functional` |
| validation status | `concept` |
| geometry | estimated, master build123d |

## Where it stands

```mermaid
flowchart LR
    L0["concept"]
    L1["dimensionally_reviewed"]
    L2["prototype_fitted"]
    L3["functionally_tested"]
    L4["engineering_reviewed"]
    L5["released"]
    L0 --> L1 --> L2 --> L3 --> L4 --> L5
    classDef here fill:#fff4d6,stroke:#b7791f,color:#1a1a1a,stroke-width:3px;
    classDef done fill:#e3f1e6,stroke:#2e7d32,color:#1a1a1a;
    classDef todo fill:#f4f4f4,stroke:#9e9e9e,color:#6b6b6b;
    classDef stop fill:#fde2e1,stroke:#c0392b,color:#1a1a1a;
    class L0 here
    class L1 todo
    class L2 todo
    class L3 todo
    class L4 todo
    class L5 todo
```

*Validation ladder of `catalog/schemas/part.schema.json`; this record is at `concept`.*

## Views

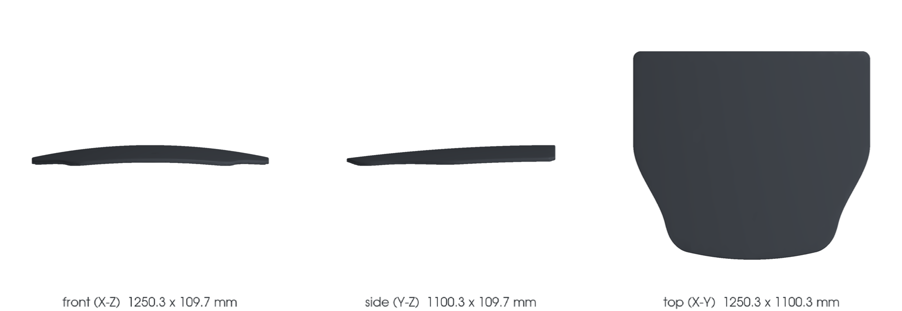
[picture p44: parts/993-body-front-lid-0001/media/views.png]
Front, side and top orthographic views


*Orthographic views of the same concept CAD, with its bounding dimensions — not drawings of the original part.*

## What's in this folder

| folder | what it holds | files |
|---|---|---|
| `derived/` | CAD exports generated from the source (STEP for CAD tools, STL for meshing) | [`derived/front_lid_concept_f0-picogk.json`](derived/front_lid_concept_f0-picogk.json), [`derived/front_lid_concept_f0-picogk.stl`](derived/front_lid_concept_f0-picogk.stl), [`derived/front_lid_concept_f0.step`](derived/front_lid_concept_f0.step) |
| `evidence/` | screens, reports and manifests — **pinned by SHA-256, never edited by hand** | [`evidence/concept-f0.json`](evidence/concept-f0.json), [`evidence/measurement-plan.md`](evidence/measurement-plan.md) |
| `media/` | concept-model views rendered from the CAD by `scripts/render_part_previews.py` — not pictures of the original | [`media/preview.json`](media/preview.json), [`media/preview.png`](media/preview.png), [`media/views.png`](media/views.png) |
| `source/` | parametric source — the editable master that generates the geometry | [`source/picogk.json`](source/picogk.json) |

## Read more

- **Full description page**, with sources and evidence: [docs/pieces/993-body-front-lid-0001.md](../../docs/pieces/993-body-front-lid-0001.md)
- **Catalogue record** (source of truth): [`catalog/parts/993-body-front-lid-0001.json`](../../catalog/parts/993-body-front-lid-0001.json)
- **Safety rules**: [SAFETY.md](../../SAFETY.md)

---

*This page is generated from the catalogue record by `scripts/render_part_pages.py` and checked by `make check`. Edit the record, not this page.*

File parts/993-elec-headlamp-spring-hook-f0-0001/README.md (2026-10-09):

<!-- generated by scripts/render_part_pages.py - do not edit by hand -->

<div align="center">

# Headlamp spring hook repair, F0 aluminum concept

**`993-ELEC-HEADLAMP-SPRING-HOOK-F0-0001`** · Porsche 993 · 1994–1998

  

</div>

> [!CAUTION]
> **Not ready to print, and not a copy of the original part.** The model shown here is a
> concept block for studying the part in software:
> - validation status `concept`: nothing has been checked against a real part;
> - geometry `estimated`: its dimensions are estimated design variables, not measured on the original part;
> - safety class `functional`;
> - no part in this repository is released — read [SAFETY.md](../../SAFETY.md).

<table><tr>
<td width="50%" valign="top">
<b>Original part</b><br><br>
The original part is documented — pictures, catalogue entries or published data — on these pages. They are copyrighted, so they are linked here, not copied:<br><br>
↗ <a href="https://shop.roadster-fashion.de/de/reparaturteil-federhaken-am-scheinwerfer.html">Roadster-Fashion - printed headlamp spring hook for 993</a><br>
</td>
<td width="50%" valign="top" align="center">
<b>This repository's concept model</b><br><br>
Concept CAD block for Headlamp spring hook repair, F0 aluminum concept<br>
<sub>Concept CAD block, 16.0 × 8.0 × 15.0 mm — <b>not</b> the original part, not a print file, not evidence of fit.</sub>
</td>
</tr></table>

> [!NOTE]
> **Functional** — loaded part whose failure can immobilize or damage the vehicle. Published only after documented functional testing.

## What it is

Independent hollow hook concept for studying an additive repair of the lamp spring mount of a 993 headlamp. A commercial offer proves that metal printing is really used for this function, but no public dimension allows this F0 to be presented as its copy or as a fitted part.

## What it does on the car

CAD, LPBF and mechanical screening of a repair concept; no fitting and no lamp retention authorized

## At a glance

| | |
|---|---|
| Porsche part numbers | not recorded |
| variants | `993_headlamp_application_declared_by_vendor_to_confirm` |
| candidate material | EOS Aluminium AlSi10Mg / AlSi10Mg_FlexM291 2.01 / 30 µm, screening candidate not attributed to the commercial part |
| candidate process | LPBF |
| safety class | `functional` |
| validation status | `concept` |
| geometry | estimated, master build123d |

## Where it stands

```mermaid
flowchart LR
    L0["concept"]
    L1["dimensionally_reviewed"]
    L2["prototype_fitted"]
    L3["functionally_tested"]
    L4["engineering_reviewed"]
    L5["released"]
    L0 --> L1 --> L2 --> L3 --> L4 --> L5
    classDef here fill:#fff4d6,stroke:#b7791f,color:#1a1a1a,stroke-width:3px;
    classDef done fill:#e3f1e6,stroke:#2e7d32,color:#1a1a1a;
    classDef todo fill:#f4f4f4,stroke:#9e9e9e,color:#6b6b6b;
    classDef stop fill:#fde2e1,stroke:#c0392b,color:#1a1a1a;
    class L0 here
    class L1 todo
    class L2 todo
    class L3 todo
    class L4 todo
    class L5 todo
```

*Validation ladder of `catalog/schemas/part.schema.json`; this record is at `concept`.*

## Views

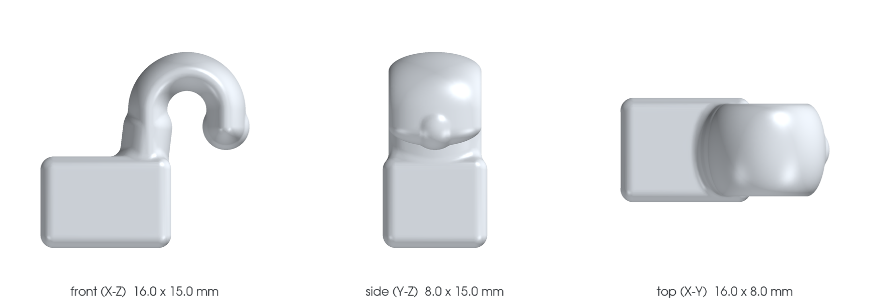
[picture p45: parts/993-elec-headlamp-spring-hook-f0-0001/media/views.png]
Front, side and top orthographic views


*Orthographic views of the same concept CAD, with its bounding dimensions — not drawings of the original part.*

## PicoGK voxel model

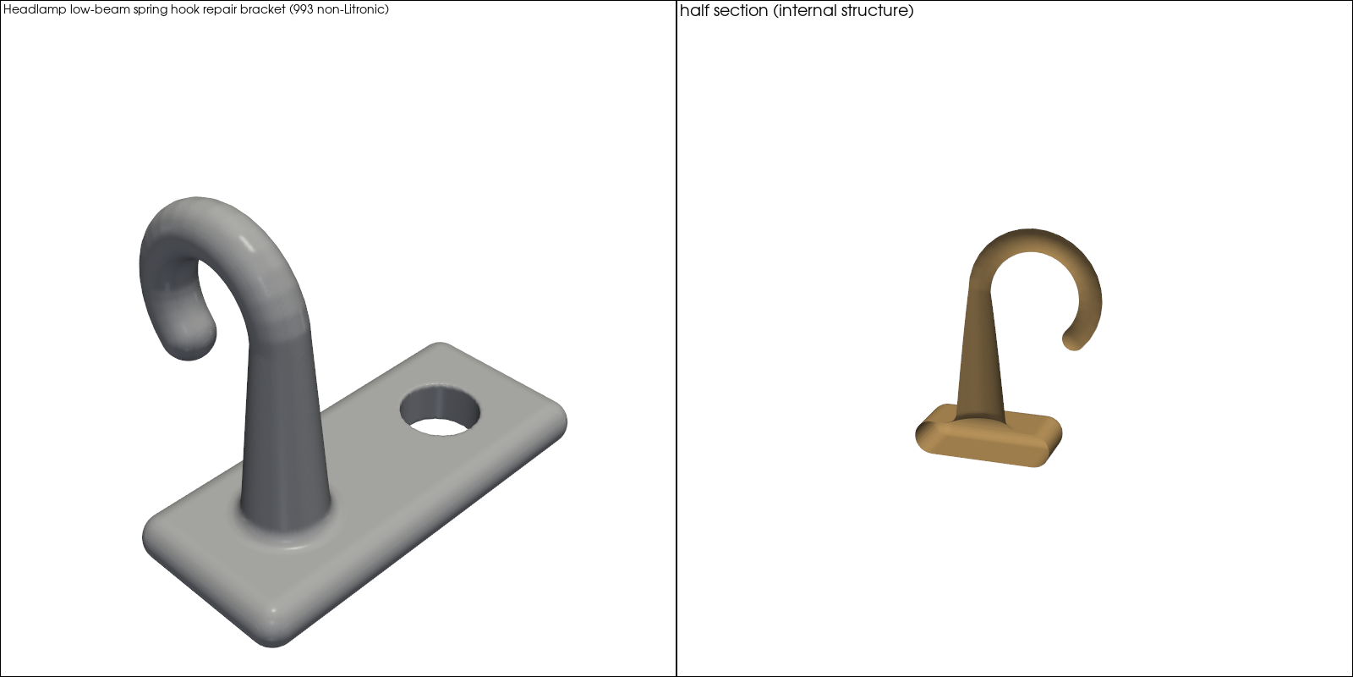
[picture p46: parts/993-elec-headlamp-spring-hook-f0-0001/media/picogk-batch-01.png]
PicoGK model: shaded view and half section


*Variant generated with the PicoGK voxel kernel in [`parts/picogk-993-batch-01`](../../parts/picogk-993-batch-01/README.md): published overall envelope, internal structure (double wall, lattice core or vanes) shown in the half section. Mounting interfaces are assumptions — not the original part, not a print file, not evidence of fit.*

## Screens and evidence images

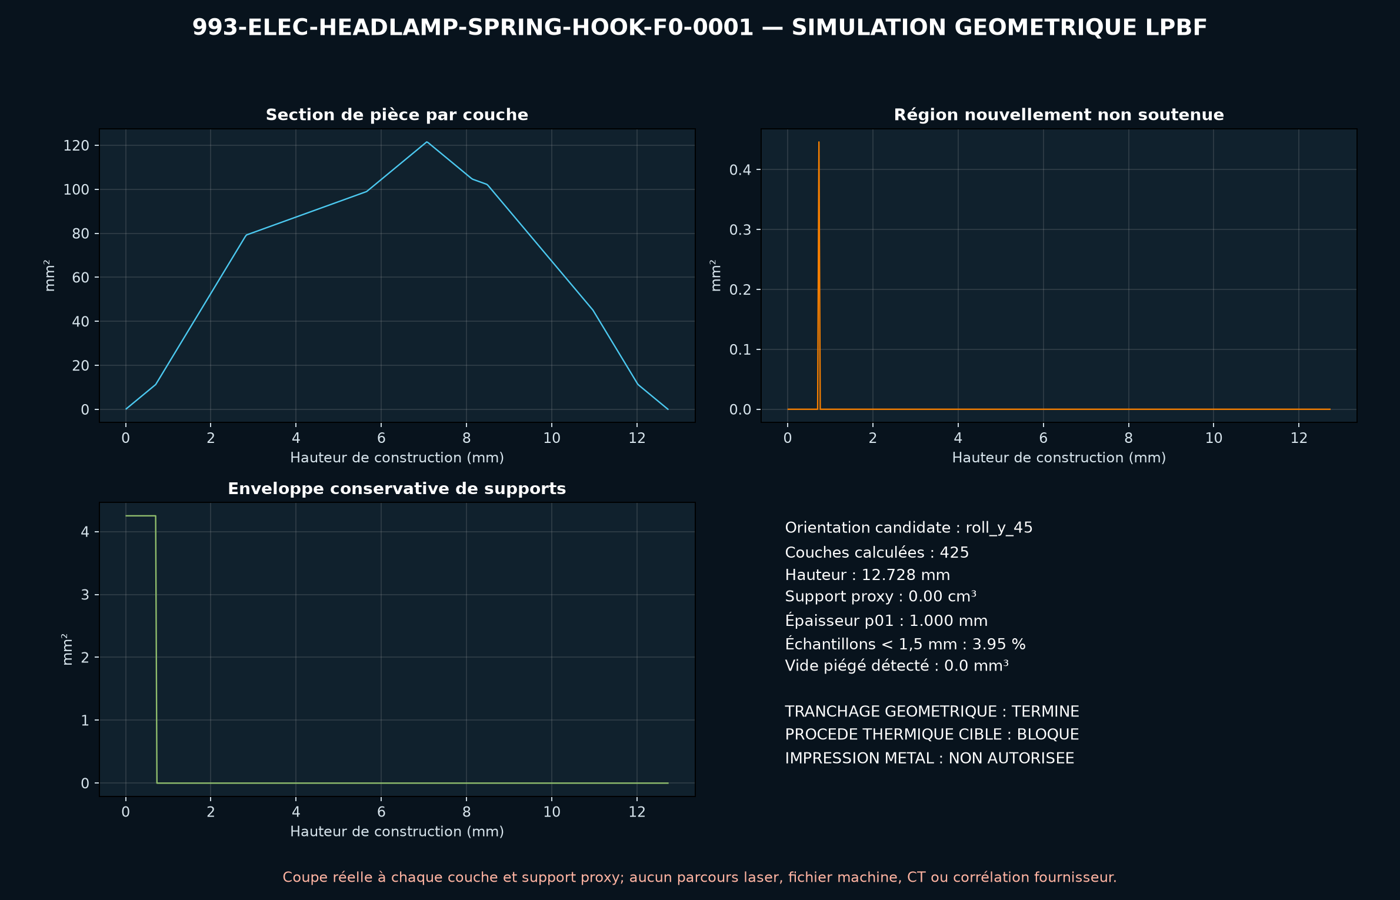
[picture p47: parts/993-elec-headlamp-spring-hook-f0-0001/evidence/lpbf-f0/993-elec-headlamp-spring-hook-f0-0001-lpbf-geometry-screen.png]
993-elec-headlamp-spring-hook-f0-0001-lpbf-geometry-screen


*`evidence/lpbf-f0/993-elec-headlamp-spring-hook-f0-0001-lpbf-geometry-screen.png` — a screening output, not a validation.*

## What's in this folder

| folder | what it holds | files |
|---|---|---|
| `derived/` | CAD exports generated from the source (STEP for CAD tools, STL for meshing) | [`derived/headlamp_spring_hook_f0-picogk.json`](derived/headlamp_spring_hook_f0-picogk.json), [`derived/headlamp_spring_hook_f0-picogk.stl`](derived/headlamp_spring_hook_f0-picogk.stl), [`derived/headlamp_spring_hook_f0.step`](derived/headlamp_spring_hook_f0.step), [`derived/headlamp_spring_hook_f0.stl`](derived/headlamp_spring_hook_f0.stl) |
| `evidence/` | screens, reports and manifests — **pinned by SHA-256, never edited by hand** | [`evidence/engineering-screen.json`](evidence/engineering-screen.json), [`evidence/lpbf-f0/993-elec-headlamp-spring-hook-f0-0001-layer-metrics.csv`](evidence/lpbf-f0/993-elec-headlamp-spring-hook-f0-0001-layer-metrics.csv), [`evidence/lpbf-f0/993-elec-headlamp-spring-hook-f0-0001-lpbf-geometry-manifest.json`](evidence/lpbf-f0/993-elec-headlamp-spring-hook-f0-0001-lpbf-geometry-manifest.json), [`evidence/lpbf-f0/993-elec-headlamp-spring-hook-f0-0001-lpbf-geometry-report.json`](evidence/lpbf-f0/993-elec-headlamp-spring-hook-f0-0001-lpbf-geometry-report.json), [`evidence/lpbf-f0/993-elec-headlamp-spring-hook-f0-0001-lpbf-geometry-screen.png`](evidence/lpbf-f0/993-elec-headlamp-spring-hook-f0-0001-lpbf-geometry-screen.png) |
| `media/` | concept-model views rendered from the CAD by `scripts/render_part_previews.py` — not pictures of the original | [`media/picogk-batch-01.png`](media/picogk-batch-01.png), [`media/preview.json`](media/preview.json), [`media/preview.png`](media/preview.png), [`media/views.png`](media/views.png) |
| `source/` | parametric source — the editable master that generates the geometry | [`source/headlamp_spring_hook.py`](source/headlamp_spring_hook.py), [`source/picogk.json`](source/picogk.json) |

## Read more

- **Full description page**, with sources and evidence: [docs/pieces/993-elec-headlamp-spring-hook-f0-0001.md](../../docs/pieces/993-elec-headlamp-spring-hook-f0-0001.md)
- **Catalogue record** (source of truth): [`catalog/parts/993-elec-headlamp-spring-hook-f0-0001.json`](../../catalog/parts/993-elec-headlamp-spring-hook-f0-0001.json)
- **Design dossier**: [993_HEADLAMP_SPRING_HOOK_ALSI10MG_F0](../../docs/993/993_HEADLAMP_SPRING_HOOK_ALSI10MG_F0.md)
- **Digital twin record**: [`twin-993-headlamp-spring-hook-alsi10mg-f0.json`](../../catalog/twins/twin-993-headlamp-spring-hook-alsi10mg-f0.json) — see [twins/README.md](../../twins/README.md)
- **Safety rules**: [SAFETY.md](../../SAFETY.md)

---

*This page is generated from the catalogue record by `scripts/render_part_pages.py` and checked by `make check`. Edit the record, not this page.*

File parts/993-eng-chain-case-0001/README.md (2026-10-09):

<!-- generated by scripts/render_part_pages.py - do not edit by hand -->

<div align="center">

# 993 timing chain case and its lids

**`993-ENG-CHAIN-CASE-0001`** · Porsche 993 · 1994–1998

  

</div>

> [!CAUTION]
> **Not ready to print, and not a copy of the original part.** The model shown here is a
> concept block for studying the part in software:
> - validation status `concept`: nothing has been checked against a real part;
> - geometry `estimated`: its dimensions are estimated design variables, not measured on the original part;
> - safety class `prohibited_pending_engineering`;
> - no part in this repository is released — read [SAFETY.md](../../SAFETY.md).

<table><tr>
<td width="50%" valign="top">
<b>Original part</b><br><br>
The original part is documented — pictures, catalogue entries or published data — on these pages. They are copyrighted, so they are linked here, not copied:<br><br>
↗ <a href="https://porschefanatics.com/oem/993/103-05/">993 factory catalogue, plate 103-05 Chain case</a><br>
</td>
<td width="50%" valign="top" align="center">
<b>This repository's concept model</b><br><br>
Concept CAD block for 993 timing chain case and its lids<br>
<sub>Concept CAD block, 181.5 × 120.4 × 61.1 mm — <b>not</b> the original part, not a print file, not evidence of fit.</sub>
</td>
</tr></table>

> [!CAUTION]
> **Prohibited pending engineering** — risk, or insufficient data. Never published as a released part.

## What it is

Investigation target: the chain case from factory plate 103-05, its three lids, its oil bridges and its tensioner. The record establishes identity and material reasoning; it is neither a replacement geometry nor a manufacturing authorization. Selected because the factory catalogue triage makes it a serious consolidation case — and because the titanium grid rejects it three times.

## What it does on the car

Documentary investigation and process comparison; no manufacturing, no fitting, no start-up

## At a glance

| | |
|---|---|
| Porsche part numbers | 993 105 093 05, 964 105 094 04, 993 105 022 01, 964 105 107 01, 964 105 108 01, 993 107 087 51, 993 107 088 52, 993 107 088 00 |
| variants | `993_all_models_to_confirm_by_variant` |
| candidate material | unidentified |
| candidate process | undecided |
| safety class | `prohibited_pending_engineering` |
| validation status | `concept` |
| geometry | estimated, master build123d |

## Where it stands

```mermaid
flowchart LR
    L0["concept"]
    L1["dimensionally_reviewed"]
    L2["prototype_fitted"]
    L3["functionally_tested"]
    L4["engineering_reviewed"]
    L5["released"]
    L0 --> L1 --> L2 --> L3 --> L4 --> L5
    X["⛔ prohibited pending engineering"]
    L0 -. blocked .-> X
    classDef here fill:#fff4d6,stroke:#b7791f,color:#1a1a1a,stroke-width:3px;
    classDef done fill:#e3f1e6,stroke:#2e7d32,color:#1a1a1a;
    classDef todo fill:#f4f4f4,stroke:#9e9e9e,color:#6b6b6b;
    classDef stop fill:#fde2e1,stroke:#c0392b,color:#1a1a1a;
    class L0 here
    class L1 todo
    class L2 todo
    class L3 todo
    class L4 todo
    class L5 todo
    class X stop
```

*Validation ladder of `catalog/schemas/part.schema.json`; this record is at `concept`.*

## Views

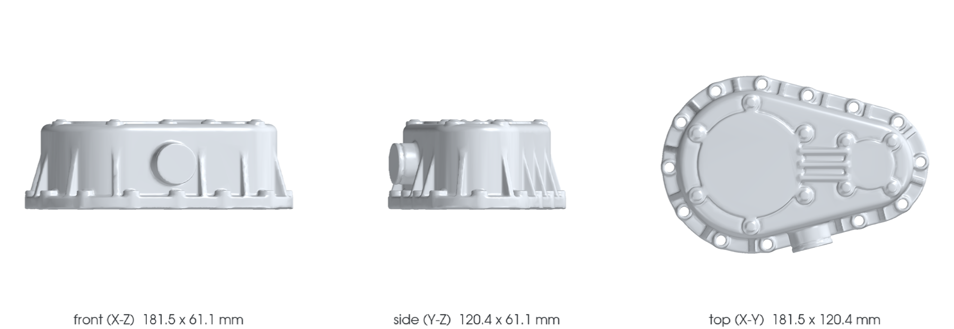
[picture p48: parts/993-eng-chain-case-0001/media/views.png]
Front, side and top orthographic views


*Orthographic views of the same concept CAD, with its bounding dimensions — not drawings of the original part.*

## What's in this folder

| folder | what it holds | files |
|---|---|---|
| `derived/` | CAD exports generated from the source (STEP for CAD tools, STL for meshing) | [`derived/chain_case_concept_f0-picogk.json`](derived/chain_case_concept_f0-picogk.json), [`derived/chain_case_concept_f0-picogk.stl`](derived/chain_case_concept_f0-picogk.stl), [`derived/chain_case_concept_f0.step`](derived/chain_case_concept_f0.step) |
| `evidence/` | screens, reports and manifests — **pinned by SHA-256, never edited by hand** | [`evidence/concept-f0.json`](evidence/concept-f0.json) |
| `media/` | concept-model views rendered from the CAD by `scripts/render_part_previews.py` — not pictures of the original | [`media/preview.json`](media/preview.json), [`media/preview.png`](media/preview.png), [`media/views.png`](media/views.png) |
| `source/` | parametric source — the editable master that generates the geometry | [`source/picogk.json`](source/picogk.json) |

## Read more

- **Full description page**, with sources and evidence: [docs/pieces/993-eng-chain-case-0001.md](../../docs/pieces/993-eng-chain-case-0001.md)
- **Catalogue record** (source of truth): [`catalog/parts/993-eng-chain-case-0001.json`](../../catalog/parts/993-eng-chain-case-0001.json)
- **Safety rules**: [SAFETY.md](../../SAFETY.md)

---

*This page is generated from the catalogue record by `scripts/render_part_pages.py` and checked by `make check`. Edit the record, not this page.*

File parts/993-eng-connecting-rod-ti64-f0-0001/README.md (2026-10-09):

<!-- generated by scripts/render_part_pages.py - do not edit by hand -->

<div align="center">

# 993/993 Turbo connecting rod, Ti64 F0 topology concept

**`993-ENG-CONNECTING-ROD-TI64-F0-0001`** · Porsche 993 · 1993–1998

  

</div>

> [!WARNING]
> **A 1:1 display mock-up is printable — never for use.** [`print/`](print/README.md): the design, unchanged except for MOCK-UP / NOT FOR USE engraved in it, sliced in 4h 57m 5s (51.22 cm³). The part itself stays prohibited ([decision 0011](../../docs/decisions/0011-printable-display-mockups-of-prohibited-parts.md)).

> [!CAUTION]
> **Prohibited, not validated, and not a copy of the original.** The mock-up is a display piece; the model shown here is a
> design whose fit has not been checked against the car:
> - validation status `concept`: nothing has been checked against a real part;
> - geometry `mixed`: its dimensions are partly sourced, partly assumed, not measured on the original part;
> - safety class `prohibited_pending_engineering`;
> - no part in this repository is released — read [SAFETY.md](../../SAFETY.md).

<table><tr>
<td width="50%" valign="top">
<b>Original part</b><br><br>
The original part is documented — pictures, catalogue entries or published data — on these pages. They are copyrighted, so they are linked here, not copied:<br><br>
↗ <a href="https://www.tzr-motorsport.de/993-230-580-1270F">TZR Motorsport - manufacturer dimensions of the PAUTER 993/993 Turbo connecting rod</a><br>
↗ <a href="https://porschefanatics.com/engine/993/">PorscheFanatics - titanium connecting rods for the 993 engine</a><br>
↗ <a href="https://www.elferclassic.de/technik/techdaten/993-turbo-95-98-techdat.php">elferclassic - 993 Turbo technical data</a><br>
</td>
<td width="50%" valign="top" align="center">
<b>What you can print: a display mock-up</b><br><br>
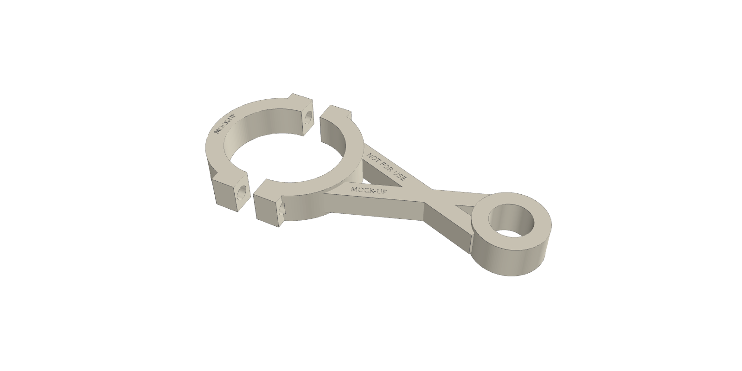
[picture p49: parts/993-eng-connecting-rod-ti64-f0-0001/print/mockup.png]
Engraved display mock-up of 993/993 Turbo connecting rod, Ti64 F0 topology concept
<br>
<sub>1:1 display mock-up with MOCK-UP / NOT FOR USE engraved in it. <b>Never</b> for an engine; not the original part.</sub>
</td>
</tr></table>

> [!CAUTION]
> **Prohibited pending engineering** — risk, or insufficient data. Never published as a released part.

## What it is

Independent two-open-flange concept to screen an LPBF Ti-6Al-4V connecting rod. The key dimensions come from a PAUTER/TZR record; outer diameters, flanges, cap split and bolt passages remain F0 assumptions with no commercial surface reused.

## What it does on the car

CAD, DfAM, mass, synthetic loads, nominal stresses and buckling screening only; no manufacturing, installation or engine start-up authorized

## At a glance

| | |
|---|---|
| Porsche part numbers | not recorded |
| variants | 993, `993_Turbo`, `M64_60_research` |
| candidate material | Ti-6Al-4V Grade 5 LPBF for screening |
| candidate process | LPBF |
| safety class | `prohibited_pending_engineering` |
| validation status | `concept` |
| geometry | mixed, master build123d |

## Where it stands

```mermaid
flowchart LR
    L0["concept"]
    L1["dimensionally_reviewed"]
    L2["prototype_fitted"]
    L3["functionally_tested"]
    L4["engineering_reviewed"]
    L5["released"]
    L0 --> L1 --> L2 --> L3 --> L4 --> L5
    X["⛔ prohibited pending engineering"]
    L0 -. blocked .-> X
    classDef here fill:#fff4d6,stroke:#b7791f,color:#1a1a1a,stroke-width:3px;
    classDef done fill:#e3f1e6,stroke:#2e7d32,color:#1a1a1a;
    classDef todo fill:#f4f4f4,stroke:#9e9e9e,color:#6b6b6b;
    classDef stop fill:#fde2e1,stroke:#c0392b,color:#1a1a1a;
    class L0 here
    class L1 todo
    class L2 todo
    class L3 todo
    class L4 todo
    class L5 todo
    class X stop
```

*Validation ladder of `catalog/schemas/part.schema.json`; this record is at `concept`.*

## Views

Front, side and top orthographic views

*Orthographic views of the same concept CAD, with its bounding dimensions — not drawings of the original part.*

## Screens and evidence images

mockup

*`print/mockup.png` — a screening output, not a validation.*

## What's in this folder

| folder | what it holds | files |
|---|---|---|
| `derived/` | CAD exports generated from the source (STEP for CAD tools, STL for meshing) | [`derived/connecting_rod_ti64_f0-picogk.json`](derived/connecting_rod_ti64_f0-picogk.json), [`derived/connecting_rod_ti64_f0-picogk.stl`](derived/connecting_rod_ti64_f0-picogk.stl), [`derived/connecting_rod_ti64_f0.step`](derived/connecting_rod_ti64_f0.step), [`derived/connecting_rod_ti64_f0.stl`](derived/connecting_rod_ti64_f0.stl) |
| `evidence/` | screens, reports and manifests — **pinned by SHA-256, never edited by hand** | [`evidence/engineering-screen.json`](evidence/engineering-screen.json) |
| `media/` | concept-model views rendered from the CAD by `scripts/render_part_previews.py` — not pictures of the original | [`media/preview.json`](media/preview.json), [`media/preview.png`](media/preview.png), [`media/views.png`](media/views.png) |
| `print/` | **ready-to-print files**: 3MF project, STL and instructions | [`print/connecting_rod_f0_mockup.3mf`](print/connecting_rod_f0_mockup.3mf), [`print/connecting_rod_f0_mockup.step`](print/connecting_rod_f0_mockup.step), [`print/connecting_rod_f0_mockup.stl`](print/connecting_rod_f0_mockup.stl), [`print/mockup.png`](print/mockup.png), [`print/print.json`](print/print.json) |
| `source/` | parametric source — the editable master that generates the geometry | [`source/connecting_rod.py`](source/connecting_rod.py), [`source/export_mockup.py`](source/export_mockup.py), [`source/picogk.json`](source/picogk.json), [`source/render_mockup.py`](source/render_mockup.py) |

## Read more

- **Full description page**, with sources and evidence: [docs/pieces/993-eng-connecting-rod-ti64-f0-0001.md](../../docs/pieces/993-eng-connecting-rod-ti64-f0-0001.md)
- **Catalogue record** (source of truth): [`catalog/parts/993-eng-connecting-rod-ti64-f0-0001.json`](../../catalog/parts/993-eng-connecting-rod-ti64-f0-0001.json)
- **Design dossier**: [993_K16_ROD_IMPROVEMENT_PROGRAMME](../../docs/993/993_K16_ROD_IMPROVEMENT_PROGRAMME.md)
- **Safety rules**: [SAFETY.md](../../SAFETY.md)

---

*This page is generated from the catalogue record by `scripts/render_part_pages.py` and checked by `make check`. Edit the record, not this page.*

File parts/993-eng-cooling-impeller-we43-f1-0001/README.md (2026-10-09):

<!-- generated by scripts/render_part_pages.py - do not edit by hand -->

<div align="center">

# Engine cooling fan impeller, WE43 magnesium concept F1 redesigned from the Turbo rotor rebuild

**`993-ENG-COOLING-IMPELLER-WE43-F1-0001`** · Porsche 993 · 1994–1998

  

</div>

> [!CAUTION]
> **Not ready to print, and not a copy of the original part.** The model shown here is a
> concept block for studying the part in software:
> - validation status `concept`: nothing has been checked against a real part;
> - geometry `estimated`: its dimensions are estimated design variables, not measured on the original part;
> - safety class `prohibited_pending_engineering`;
> - no part in this repository is released — read [SAFETY.md](../../SAFETY.md).

<table><tr>
<td width="50%" valign="top">
<b>Original part</b><br><br>
The original part is documented — pictures, catalogue entries or published data — on these pages. They are copyrighted, so they are linked here, not copied:<br><br>
↗ <a href="https://www.fvd.net/fr/shop/turbine-965-993-turbo-96410601522~p252068">FVD - Porsche 965/993 Turbo cooling fan rotor 964 106 015 22</a><br>
↗ <a href="https://porschefanatics.com/parts/c/cooling/">PorscheFanatics - 964/993 engine cooling fan impeller</a><br>
↗ <a href="https://impact.ornl.gov/en/publications/additive-manufacturing-of-dense-we43-mg-alloy-by-laser-powder-bed/">Additive manufacturing of dense WE43 Mg alloy by laser powder bed fusion (Hyer et al., 2020)</a><br>
↗ <a href="https://www.azom.com/article.aspx?ArticleID=9279">AZoM - Magnesium Elektron WE43 alloy properties</a><br>
</td>
<td width="50%" valign="top" align="center">
<b>This repository's concept model</b><br><br>
Concept CAD block for Engine cooling fan impeller, WE43 magnesium concept F1 redesigned from the Turbo rotor rebuild<br>
<sub>Concept CAD block, 242.8 × 244.9 × 56.9 mm — <b>not</b> the original part, not a print file, not evidence of fit.</sub>
</td>
</tr></table>

> [!CAUTION]
> **Prohibited pending engineering** — risk, or insufficient data. Never published as a released part.

## What it is

Improved variant of the 993 Turbo cooling fan rotor, drawn from the repository's visual rebuild of the original. It keeps the rebuild's 245 mm envelope, its 165 mm cup 56 mm deep that wraps the alternator end, the cup's twelve windows, three bolt holes and bore, eleven blades and no shroud. It replaces the rebuild's constant-pitch cambered plates with twisted airfoil blades designed from velocity triangles, and moves to LPBF WE43 magnesium. A one-dimensional blade-element model with radial equilibrium, on a duty inferred from the rebuild, estimates about 2 % more air than the rebuild rotor on the same shaft power, and about 9 % with a matched stator. These are model estimates on visual hypotheses, not measurements and not a comparison with the Porsche part.

## What it does on the car

F1 design study: airfoil blades inside the original rotor's envelope, one-dimensional fan-curve comparison with the rebuild rotor on a duty inferred from it, lighter-alloy comparison; no manufacture, rotation, installation or start-up authorized

## At a glance

| | |
|---|---|
| Porsche part numbers | 96410601522 |
| variants | `993_Turbo`, `M64_60_research` |
| candidate material | WE43 LPBF, solutionized and aged, for comparison |
| candidate process | LPBF |
| safety class | `prohibited_pending_engineering` |
| validation status | `concept` |
| geometry | estimated, master build123d |

## Where it stands

```mermaid
flowchart LR
    L0["concept"]
    L1["dimensionally_reviewed"]
    L2["prototype_fitted"]
    L3["functionally_tested"]
    L4["engineering_reviewed"]
    L5["released"]
    L0 --> L1 --> L2 --> L3 --> L4 --> L5
    X["⛔ prohibited pending engineering"]
    L0 -. blocked .-> X
    classDef here fill:#fff4d6,stroke:#b7791f,color:#1a1a1a,stroke-width:3px;
    classDef done fill:#e3f1e6,stroke:#2e7d32,color:#1a1a1a;
    classDef todo fill:#f4f4f4,stroke:#9e9e9e,color:#6b6b6b;
    classDef stop fill:#fde2e1,stroke:#c0392b,color:#1a1a1a;
    class L0 here
    class L1 todo
    class L2 todo
    class L3 todo
    class L4 todo
    class L5 todo
    class X stop
```

*Validation ladder of `catalog/schemas/part.schema.json`; this record is at `concept`.*

## Views

Front, side and top orthographic views

*Orthographic views of the same concept CAD, with its bounding dimensions — not drawings of the original part.*

## Screens and evidence images

fan-curves

*`evidence/fan-curves.png` — a screening output, not a validation.*

flat-fan-sizing-f2

*`evidence/flat-fan-sizing-f2.png` — a screening output, not a validation.*

993-eng-cooling-impeller-we43-f1-0001-lpbf-geometry-screen

*`evidence/lpbf-f0/993-eng-cooling-impeller-we43-f1-0001-lpbf-geometry-screen.png` — a screening output, not a validation.*

## What's in this folder

| folder | what it holds | files |
|---|---|---|
| `derived/` | CAD exports generated from the source (STEP for CAD tools, STL for meshing) | [`derived/cooling_impeller_we43_f1-picogk.json`](derived/cooling_impeller_we43_f1-picogk.json), [`derived/cooling_impeller_we43_f1-picogk.stl`](derived/cooling_impeller_we43_f1-picogk.stl), [`derived/cooling_impeller_we43_f1.step`](derived/cooling_impeller_we43_f1.step), [`derived/cooling_impeller_we43_f1.stl`](derived/cooling_impeller_we43_f1.stl) |
| `evidence/` | screens, reports and manifests — **pinned by SHA-256, never edited by hand** | [`evidence/engineering-screen.json`](evidence/engineering-screen.json), [`evidence/fan-curves.png`](evidence/fan-curves.png), [`evidence/flat-fan-sizing-f2.json`](evidence/flat-fan-sizing-f2.json), [`evidence/flat-fan-sizing-f2.png`](evidence/flat-fan-sizing-f2.png), [`evidence/lpbf-f0/993-eng-cooling-impeller-we43-f1-0001-layer-metrics.csv`](evidence/lpbf-f0/993-eng-cooling-impeller-we43-f1-0001-layer-metrics.csv), [`evidence/lpbf-f0/993-eng-cooling-impeller-we43-f1-0001-lpbf-geometry-manifest.json`](evidence/lpbf-f0/993-eng-cooling-impeller-we43-f1-0001-lpbf-geometry-manifest.json), [`evidence/lpbf-f0/993-eng-cooling-impeller-we43-f1-0001-lpbf-geometry-report.json`](evidence/lpbf-f0/993-eng-cooling-impeller-we43-f1-0001-lpbf-geometry-report.json), [`evidence/lpbf-f0/993-eng-cooling-impeller-we43-f1-0001-lpbf-geometry-screen.png`](evidence/lpbf-f0/993-eng-cooling-impeller-we43-f1-0001-lpbf-geometry-screen.png) |
| `media/` | concept-model views rendered from the CAD by `scripts/render_part_previews.py` — not pictures of the original | [`media/preview.json`](media/preview.json), [`media/preview.png`](media/preview.png), [`media/print-simulation/build-plate.png`](media/print-simulation/build-plate.png), [`media/print-simulation/build.gif`](media/print-simulation/build.gif), [`media/print-simulation/build.mp4`](media/print-simulation/build.mp4), [`media/print-simulation/layers.png`](media/print-simulation/layers.png), [`media/print-simulation/visuals.json`](media/print-simulation/visuals.json), [`media/views.png`](media/views.png) |
| `source/` | parametric source — the editable master that generates the geometry | [`source/cooling_impeller_f1.py`](source/cooling_impeller_f1.py), [`source/flat_fan_sizing_f2.py`](source/flat_fan_sizing_f2.py), [`source/picogk.json`](source/picogk.json) |

## Read more

- **Full description page**, with sources and evidence: [docs/pieces/993-eng-cooling-impeller-we43-f1-0001.md](../../docs/pieces/993-eng-cooling-impeller-we43-f1-0001.md)
- **Catalogue record** (source of truth): [`catalog/parts/993-eng-cooling-impeller-we43-f1-0001.json`](../../catalog/parts/993-eng-cooling-impeller-we43-f1-0001.json)
- **Design dossier**: [993_COOLING_IMPELLER_WE43_F1](../../docs/993/993_COOLING_IMPELLER_WE43_F1.md)
- **Design dossier**: [993_FAN_STATOR_ALSI10MG_F1](../../docs/993/993_FAN_STATOR_ALSI10MG_F1.md)
- **Design dossier**: [993_FLAT_FAN_SIZING_F2](../../docs/993/993_FLAT_FAN_SIZING_F2.md)
- **Design dossier**: [993_K16_ROD_IMPROVEMENT_PROGRAMME](../../docs/993/993_K16_ROD_IMPROVEMENT_PROGRAMME.md)
- **Safety rules**: [SAFETY.md](../../SAFETY.md)

---

*This page is generated from the catalogue record by `scripts/render_part_pages.py` and checked by `make check`. Edit the record, not this page.*

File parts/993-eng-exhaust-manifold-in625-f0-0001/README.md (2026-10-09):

<!-- generated by scripts/render_part_pages.py - do not edit by hand -->

<div align="center">

# 993 Turbo three-into-one exhaust manifold, IN625 F0 concept

**`993-ENG-EXHAUST-MANIFOLD-IN625-F0-0001`** · Porsche 993 · 1995–1998

  

</div>

> [!CAUTION]
> **Not ready to print, and not a copy of the original part.** The model shown here is a
> concept block for studying the part in software:
> - validation status `concept`: nothing has been checked against a real part;
> - geometry `mixed`: its dimensions are partly sourced, partly assumed, not measured on the original part;
> - safety class `prohibited_pending_engineering`;
> - no part in this repository is released — read [SAFETY.md](../../SAFETY.md).

<table><tr>
<td width="50%" valign="top">
<b>Original part</b><br><br>
The original part is documented — pictures, catalogue entries or published data — on these pages. They are copyrighted, so they are linked here, not copied:<br><br>
↗ <a href="https://www.kline-innovation.com/exhaust-collection/porsche/993-2/porsche-993-turbo/">Kline Innovation - Porsche 993 Turbo exhaust</a><br>
↗ <a href="https://porschefanatics.com/parts/c/exhaust/">PorscheFanatics - IN625 manifolds with heat exchanger for 993 Turbo</a><br>
↗ <a href="https://assets-v2.porsche.com/us/-/media/Project/PCOM/SharedSite/PorscheClassic/Original-Parts-Catalogue/PDF-EN-US/KAT517_USA_911_98_KATALOG">Porsche PET 993 - Turbo exhaust and heat exchangers 202-10</a><br>
↗ <a href="https://www.specialmetals.com/documents/technical-bulletins/inconel/inconel-alloy-625.pdf">Special Metals - INCONEL alloy 625</a><br>
</td>
<td width="50%" valign="top" align="center">
<b>This repository's concept model</b><br><br>
Concept CAD block for 993 Turbo three-into-one exhaust manifold, IN625 F0 concept<br>
<sub>Concept CAD block, 150.4 × 70.4 × 215.1 mm — <b>not</b> the original part, not a print file, not evidence of fit.</sub>
</td>
</tr></table>

> [!CAUTION]
> **Prohibited pending engineering** — risk, or insufficient data. Never published as a released part.

## What it is

Independent concept of an IN625 three-into-one flow core to screen LPBF manufacturing without internal welds in the manifold. Kline and PorscheFanatics publish an IN625 offer at 2.9 kg per side with heat exchanger; the PET identifies the left and right parts. No public geometry is used.

## What it does on the car

CAD, DfAM, flow, pressure, acoustic and thermal screening; no manufacturing, installation, engine start or heating function authorized

## At a glance

| | |
|---|---|
| Porsche part numbers | not recorded |
| variants | `993_Turbo`, `M64_60_research` |
| candidate material | EOS NickelAlloy IN625 / UNS N06625 for screening |
| candidate process | undecided |
| safety class | `prohibited_pending_engineering` |
| validation status | `concept` |
| geometry | mixed, master build123d |

## Where it stands

```mermaid
flowchart LR
    L0["concept"]
    L1["dimensionally_reviewed"]
    L2["prototype_fitted"]
    L3["functionally_tested"]
    L4["engineering_reviewed"]
    L5["released"]
    L0 --> L1 --> L2 --> L3 --> L4 --> L5
    X["⛔ prohibited pending engineering"]
    L0 -. blocked .-> X
    classDef here fill:#fff4d6,stroke:#b7791f,color:#1a1a1a,stroke-width:3px;
    classDef done fill:#e3f1e6,stroke:#2e7d32,color:#1a1a1a;
    classDef todo fill:#f4f4f4,stroke:#9e9e9e,color:#6b6b6b;
    classDef stop fill:#fde2e1,stroke:#c0392b,color:#1a1a1a;
    class L0 here
    class L1 todo
    class L2 todo
    class L3 todo
    class L4 todo
    class L5 todo
    class X stop
```

*Validation ladder of `catalog/schemas/part.schema.json`; this record is at `concept`.*

## Views

Front, side and top orthographic views

*Orthographic views of the same concept CAD, with its bounding dimensions — not drawings of the original part.*

## Screens and evidence images

993-eng-exhaust-manifold-in625-f0-0001-lpbf-geometry-screen

*`evidence/lpbf-f0/993-eng-exhaust-manifold-in625-f0-0001-lpbf-geometry-screen.png` — a screening output, not a validation.*

## What's in this folder

| folder | what it holds | files |
|---|---|---|
| `derived/` | CAD exports generated from the source (STEP for CAD tools, STL for meshing) | [`derived/exhaust_manifold_in625_f0-picogk.json`](derived/exhaust_manifold_in625_f0-picogk.json), [`derived/exhaust_manifold_in625_f0-picogk.stl`](derived/exhaust_manifold_in625_f0-picogk.stl), [`derived/exhaust_manifold_in625_f0.step`](derived/exhaust_manifold_in625_f0.step), [`derived/exhaust_manifold_in625_f0.stl`](derived/exhaust_manifold_in625_f0.stl) |
| `evidence/` | screens, reports and manifests — **pinned by SHA-256, never edited by hand** | [`evidence/engineering-screen.json`](evidence/engineering-screen.json), [`evidence/lpbf-f0/993-eng-exhaust-manifold-in625-f0-0001-layer-metrics.csv`](evidence/lpbf-f0/993-eng-exhaust-manifold-in625-f0-0001-layer-metrics.csv), [`evidence/lpbf-f0/993-eng-exhaust-manifold-in625-f0-0001-lpbf-geometry-manifest.json`](evidence/lpbf-f0/993-eng-exhaust-manifold-in625-f0-0001-lpbf-geometry-manifest.json), [`evidence/lpbf-f0/993-eng-exhaust-manifold-in625-f0-0001-lpbf-geometry-report.json`](evidence/lpbf-f0/993-eng-exhaust-manifold-in625-f0-0001-lpbf-geometry-report.json), [`evidence/lpbf-f0/993-eng-exhaust-manifold-in625-f0-0001-lpbf-geometry-screen.png`](evidence/lpbf-f0/993-eng-exhaust-manifold-in625-f0-0001-lpbf-geometry-screen.png) |
| `media/` | concept-model views rendered from the CAD by `scripts/render_part_previews.py` — not pictures of the original | [`media/preview.json`](media/preview.json), [`media/preview.png`](media/preview.png), [`media/views.png`](media/views.png) |
| `source/` | parametric source — the editable master that generates the geometry | [`source/exhaust_manifold.py`](source/exhaust_manifold.py), [`source/picogk.json`](source/picogk.json) |

## Read more

- **Full description page**, with sources and evidence: [docs/pieces/993-eng-exhaust-manifold-in625-f0-0001.md](../../docs/pieces/993-eng-exhaust-manifold-in625-f0-0001.md)
- **Catalogue record** (source of truth): [`catalog/parts/993-eng-exhaust-manifold-in625-f0-0001.json`](../../catalog/parts/993-eng-exhaust-manifold-in625-f0-0001.json)
- **Design dossier**: [993_EXHAUST_MANIFOLD_IN625_F0](../../docs/993/993_EXHAUST_MANIFOLD_IN625_F0.md)
- **Safety rules**: [SAFETY.md](../../SAFETY.md)

---

*This page is generated from the catalogue record by `scripts/render_part_pages.py` and checked by `make check`. Edit the record, not this page.*

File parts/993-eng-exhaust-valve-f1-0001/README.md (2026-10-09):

<!-- generated by scripts/render_part_pages.py - do not edit by hand -->

<div align="center">

# 993 exhaust valves - F1 proxies

**`993-ENG-EXHAUST-VALVE-F1-0001`** · Porsche 993 · 1994–1998

  

</div>

> [!CAUTION]
> **Not ready to print, and not a copy of the original part.** The model shown here is a
> concept block for studying the part in software:
> - validation status `concept`: nothing has been checked against a real part;
> - geometry `estimated`: its dimensions are estimated design variables, not measured on the original part;
> - safety class `prohibited_pending_engineering`;
> - no part in this repository is released — read [SAFETY.md](../../SAFETY.md).

<table><tr>
<td width="50%" valign="top">
<b>Original part</b><br><br>
The original part is documented — pictures, catalogue entries or published data — on these pages. They are copyrighted, so they are linked here, not copied:<br><br>
↗ <a href="https://partworks.de/Porsche/993-Ersatzteile_s2">partworks - Stated dimensions of 993 exhaust valves</a><br>
↗ <a href="https://www.specialmetals.com/documents/technical-bulletins/inconel/inconel-alloy-751.pdf">Special Metals - INCONEL alloy 751</a><br>
</td>
<td width="50%" valign="top" align="center">
<b>This repository's concept model</b><br><br>
Concept CAD block for 993 exhaust valves - F1 proxies<br>
<sub>Concept CAD block, 91.1 × 43.6 × 109.2 mm — <b>not</b> the original part, not a print file, not evidence of fit.</sub>
</td>
</tr></table>

> [!CAUTION]
> **Prohibited pending engineering** — risk, or insufficient data. Never published as a released part.

## What it is

Non-functional parametric proxies of the Carrera and Turbo exhaust valves to compare packaging and mass between generic steel, Inconel 751 and Ti-6Al-4V, without concluding on engine suitability.

## What it does on the car

Preliminary thermal and dynamic simulation, comparative mass and packaging check only

## At a glance

| | |
|---|---|
| Porsche part numbers | 99310541901, 99310541984, 99310541952, 99310541953 |
| variants | `993_Carrera`, `993_Turbo` |
| candidate material | INCONEL 751 / UNS N07751 candidate |
| candidate process | CNC |
| safety class | `prohibited_pending_engineering` |
| validation status | `concept` |
| geometry | estimated, master build123d |

## Where it stands

```mermaid
flowchart LR
    L0["concept"]
    L1["dimensionally_reviewed"]
    L2["prototype_fitted"]
    L3["functionally_tested"]
    L4["engineering_reviewed"]
    L5["released"]
    L0 --> L1 --> L2 --> L3 --> L4 --> L5
    X["⛔ prohibited pending engineering"]
    L0 -. blocked .-> X
    classDef here fill:#fff4d6,stroke:#b7791f,color:#1a1a1a,stroke-width:3px;
    classDef done fill:#e3f1e6,stroke:#2e7d32,color:#1a1a1a;
    classDef todo fill:#f4f4f4,stroke:#9e9e9e,color:#6b6b6b;
    classDef stop fill:#fde2e1,stroke:#c0392b,color:#1a1a1a;
    class L0 here
    class L1 todo
    class L2 todo
    class L3 todo
    class L4 todo
    class L5 todo
    class X stop
```

*Validation ladder of `catalog/schemas/part.schema.json`; this record is at `concept`.*

## Views

Front, side and top orthographic views

*Orthographic views of the same concept CAD, with its bounding dimensions — not drawings of the original part.*
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

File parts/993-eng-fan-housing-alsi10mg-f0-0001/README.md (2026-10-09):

<!-- generated by scripts/render_part_pages.py - do not edit by hand -->

<div align="center">

# Stationary engine fan housing, AlSi10Mg F0 concept

**`993-ENG-FAN-HOUSING-ALSI10MG-F0-0001`** · Porsche 993 · 1994–1998

  

</div>

> [!CAUTION]
> **Not ready to print, and not a copy of the original part.** The model shown here is a
> concept block for studying the part in software:
> - validation status `concept`: nothing has been checked against a real part;
> - geometry `mixed`: its dimensions are partly sourced, partly assumed, not measured on the original part;
> - safety class `prohibited_pending_engineering`;
> - no part in this repository is released — read [SAFETY.md](../../SAFETY.md).
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

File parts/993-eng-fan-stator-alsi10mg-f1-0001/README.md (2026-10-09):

<!-- generated by scripts/render_part_pages.py - do not edit by hand -->

<div align="center">

# Engine cooling fan guide-vane ring (stator), AlSi10Mg concept F1

**`993-ENG-FAN-STATOR-ALSI10MG-F1-0001`** · Porsche 993 · 1994–1998

  ![candidate process:
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

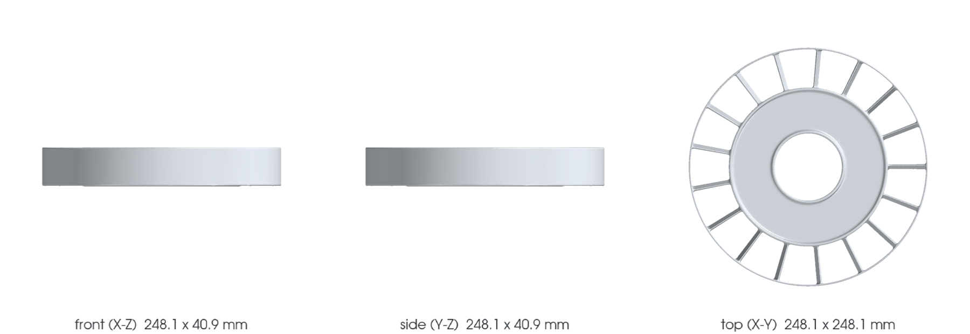
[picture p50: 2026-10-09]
parts/993-eng-fan-stator-alsi10mg-f1-0001/media/views.png

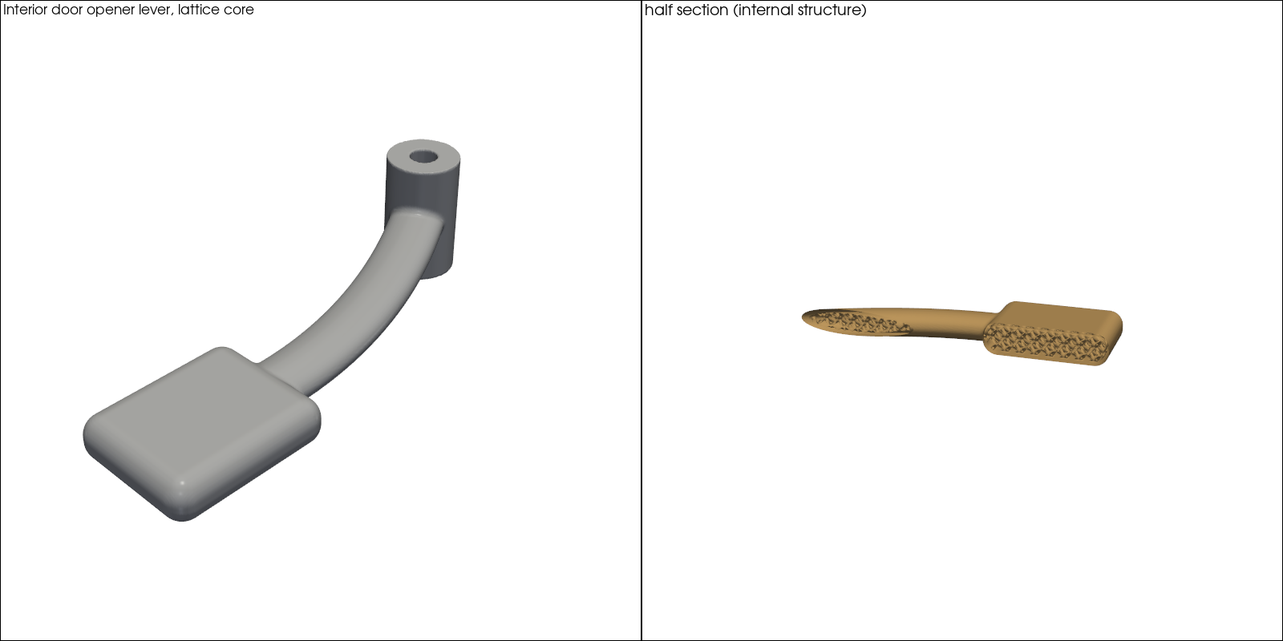
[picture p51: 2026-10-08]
parts/993-int-door-opener-lever-f0-0001/media/picogk-batch-01.png

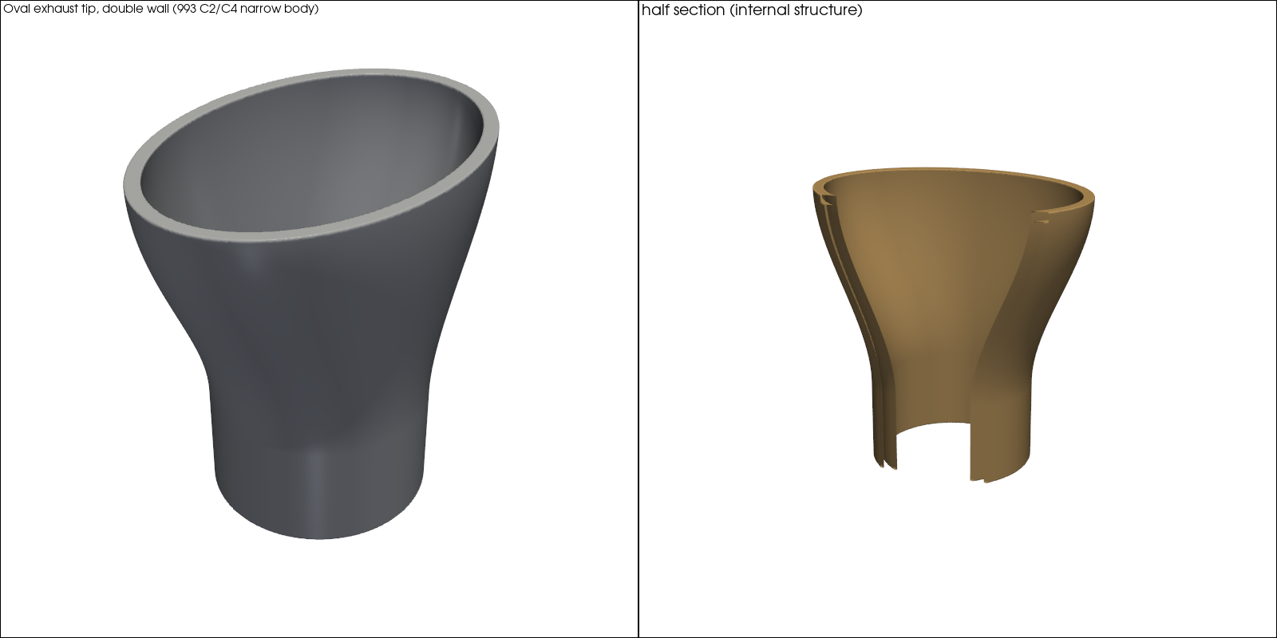
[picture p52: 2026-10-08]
parts/picogk-993-batch-01/media/PGK993-01-OVAL-EXHAUST-TIP.png

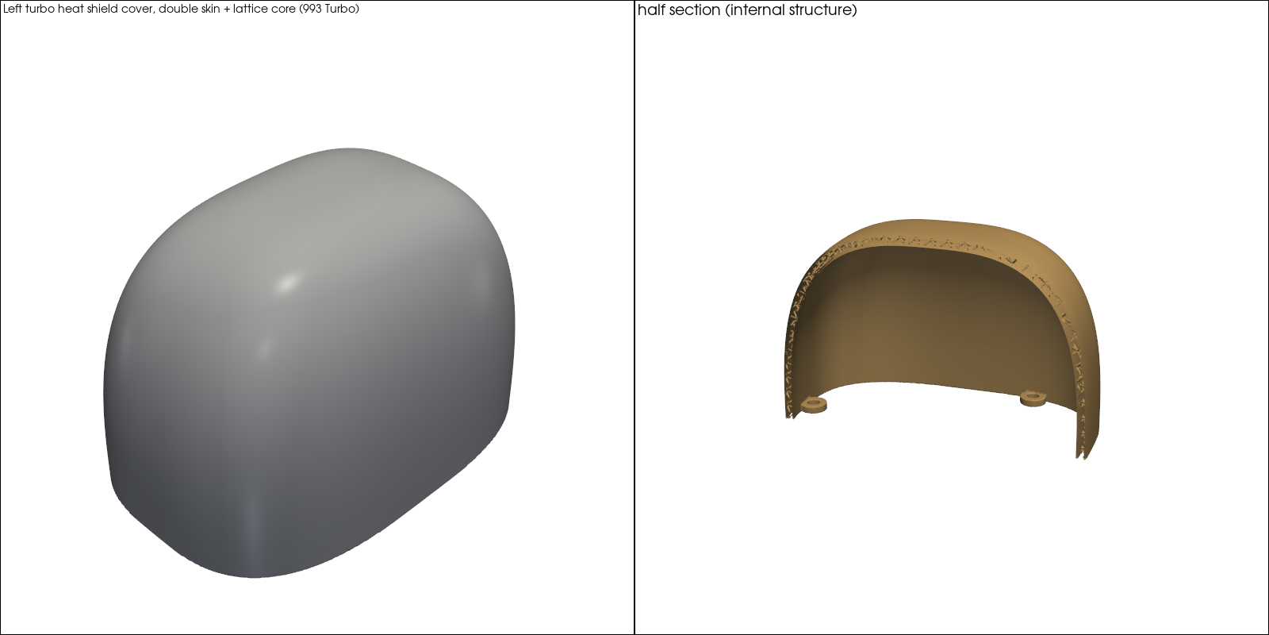
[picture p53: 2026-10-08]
parts/993-eng-turbo-heat-shield-in625-f0-0001/media/picogk-batch-01.png

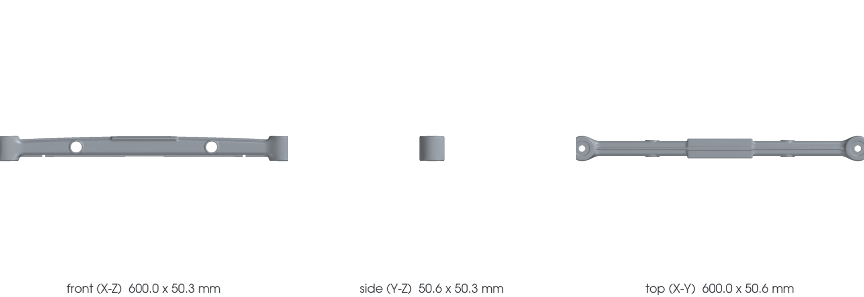
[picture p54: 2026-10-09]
parts/993-eng-carrier-0001/media/views.png

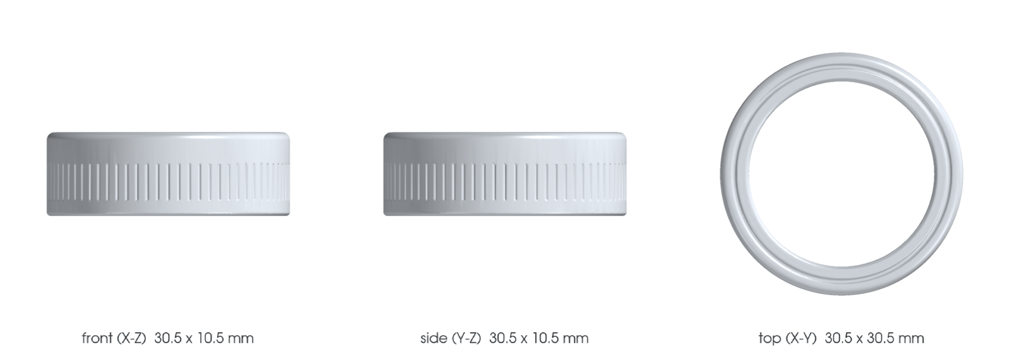
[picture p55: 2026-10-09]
parts/993-int-switch-trim-ring-f1-0001/media/views.png

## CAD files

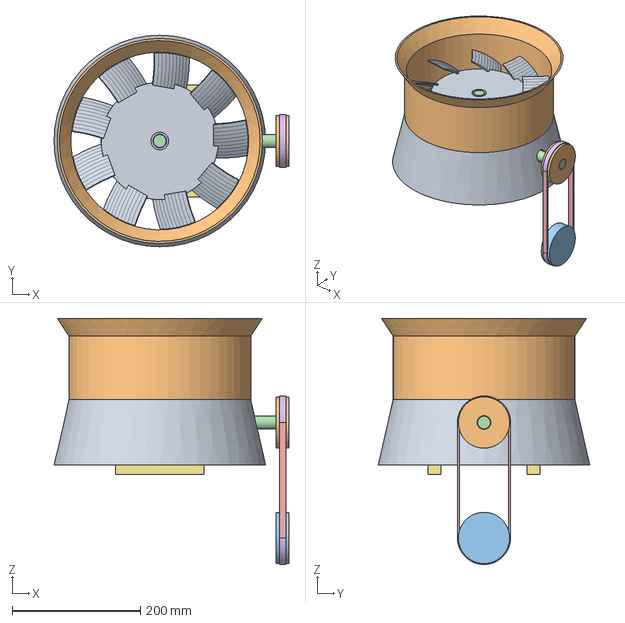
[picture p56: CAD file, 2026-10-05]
models/horizontal-fan-reconstruction/results/assembly/S1/S1-assembly.step
366.5 x 330.0 x 383.8 mm

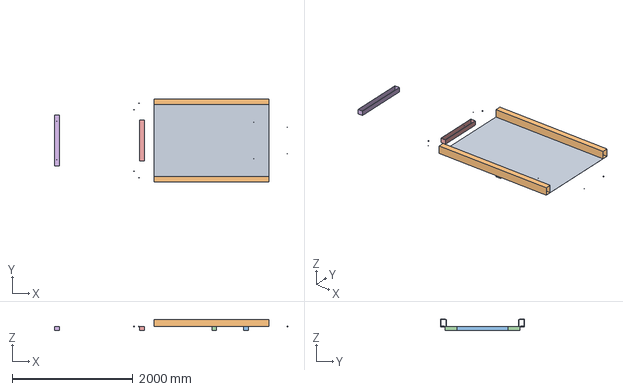
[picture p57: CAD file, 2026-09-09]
twins/964-chassis/derived/964-floor-assembly.step
3860.2 x 1380.0 x 190.0 mm

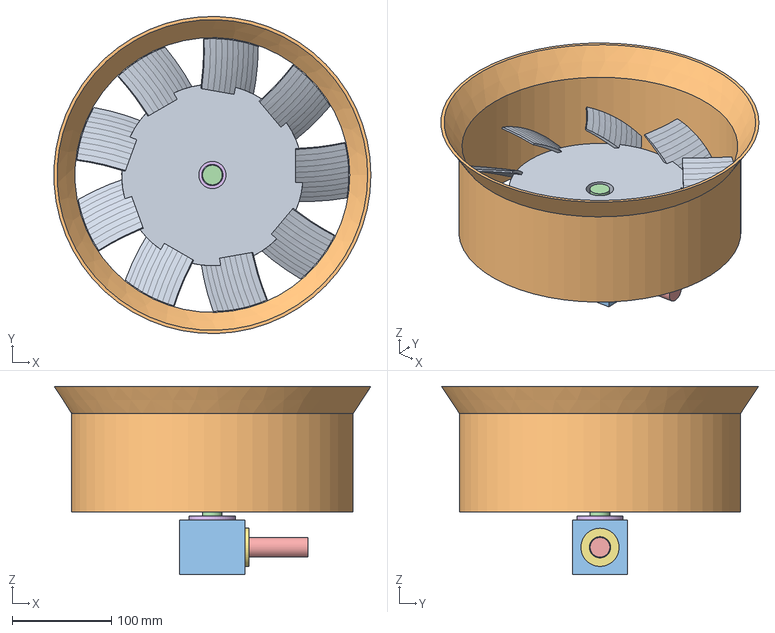
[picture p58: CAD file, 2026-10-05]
models/horizontal-fan-reconstruction/results/assembly/S1/geometry/V2_original_assembly.step
319.6 x 319.7 x 189.8 mm

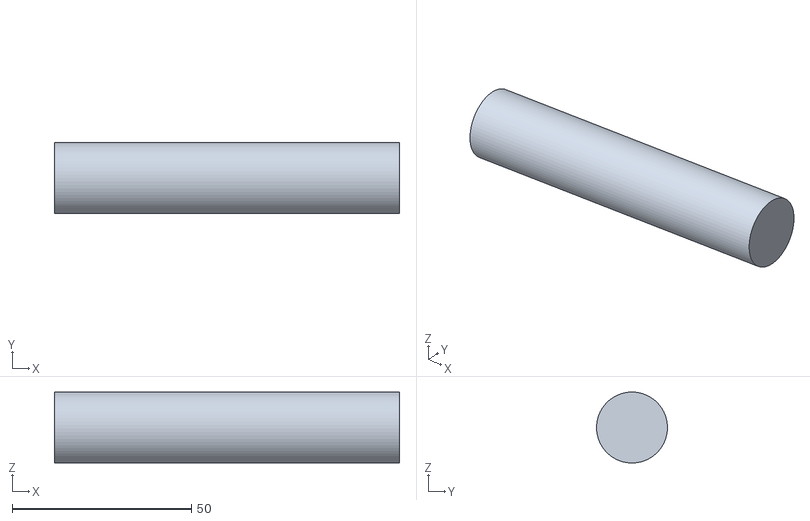
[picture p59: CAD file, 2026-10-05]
models/horizontal-fan-reconstruction/results/assembly/S1/geometry/V2_original_assembly_solid4.stl
96.2 x 19.8 x 19.8

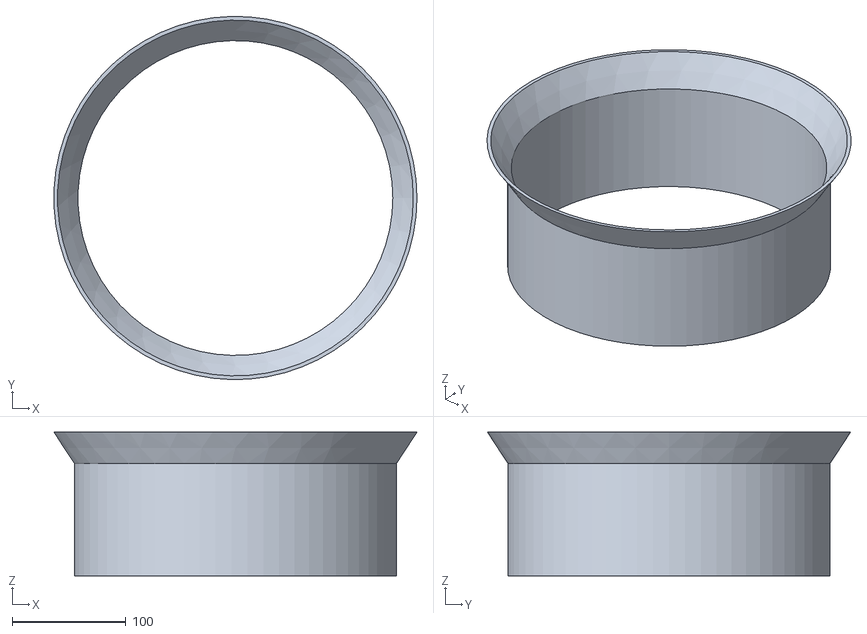
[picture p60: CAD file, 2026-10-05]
models/horizontal-fan-reconstruction/results/assembly/S1/geometry/V2_original_assembly_solid1.stl
319.6 x 319.7 x 126.5

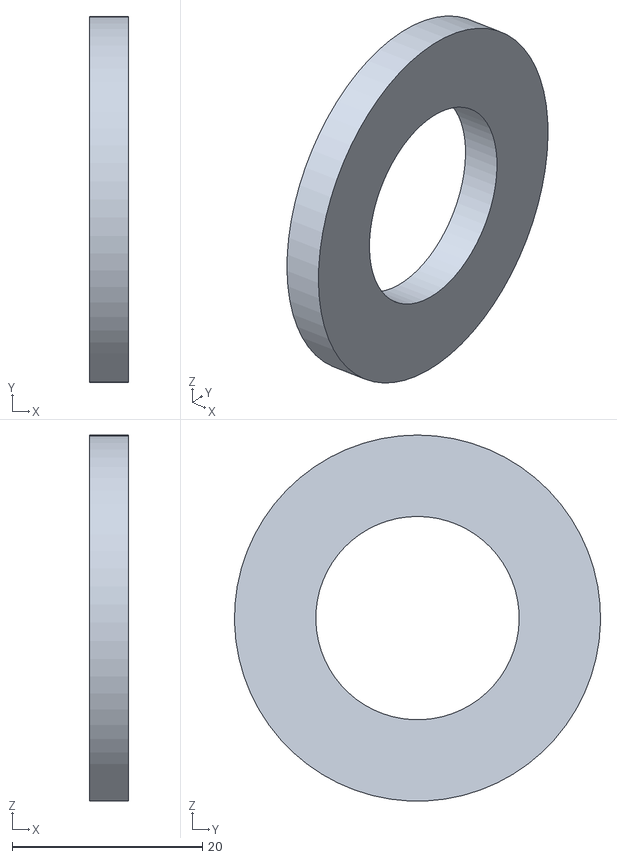
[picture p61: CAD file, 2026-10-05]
models/horizontal-fan-reconstruction/results/assembly/S1/geometry/V2_original_assembly_solid6.stl
4.12 x 38.5 x 38.5

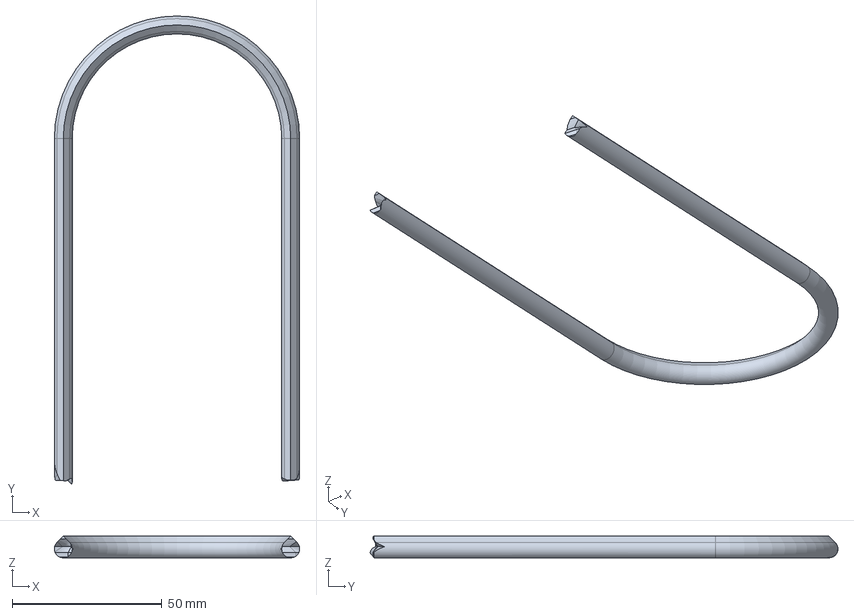
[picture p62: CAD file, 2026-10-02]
docs/studies/993-air-oil-20261002/cad/head-fluid-domain.step
82.0 x 156.4 x 7.24 mm

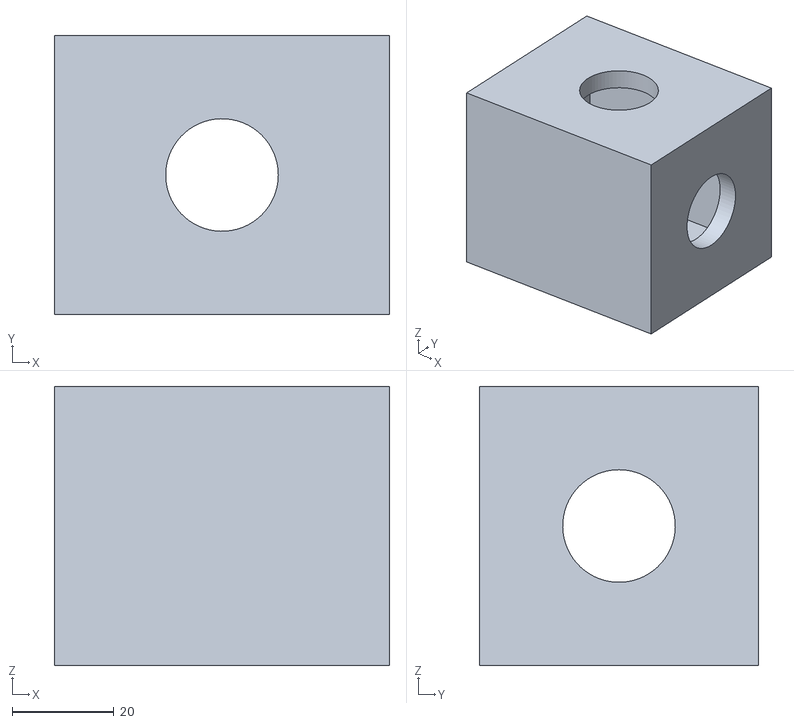
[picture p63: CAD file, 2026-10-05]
models/horizontal-fan-reconstruction/results/assembly/S1/geometry/V2_original_assembly_solid2.stl
66.0 x 55.0 x 55.0

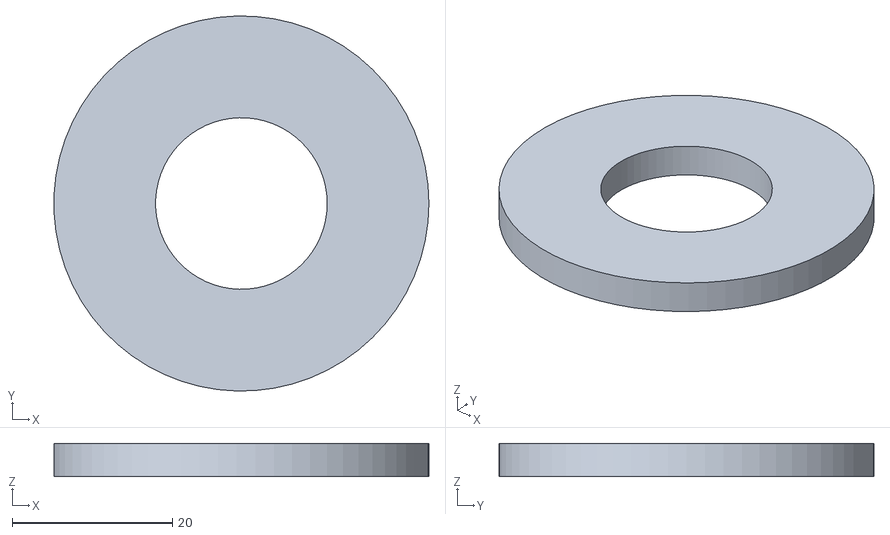
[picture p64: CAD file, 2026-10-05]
models/horizontal-fan-reconstruction/results/assembly/S1/geometry/V2_original_assembly_solid5.stl
46.7 x 46.7 x 4.12

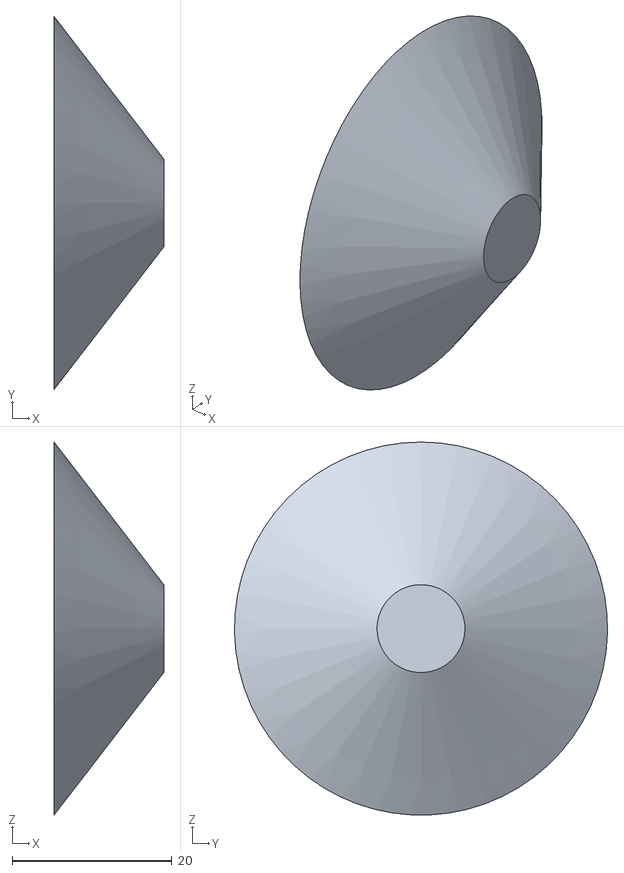
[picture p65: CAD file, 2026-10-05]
models/horizontal-fan-reconstruction/results/assembly/S1/geometry/V2_original_assembly_solid8.stl
13.8 x 46.7 x 46.7

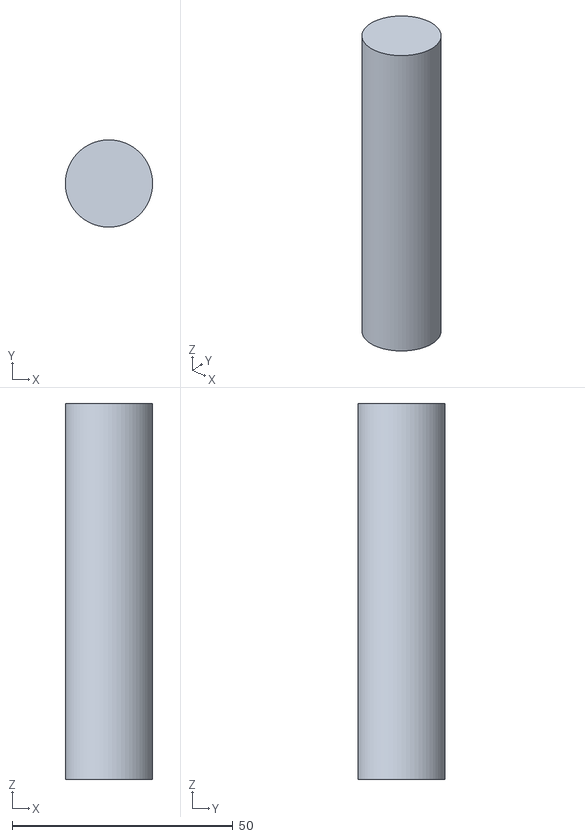
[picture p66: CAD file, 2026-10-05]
models/horizontal-fan-reconstruction/results/assembly/S1/geometry/V2_original_assembly_solid3.stl
19.8 x 19.8 x 85.2

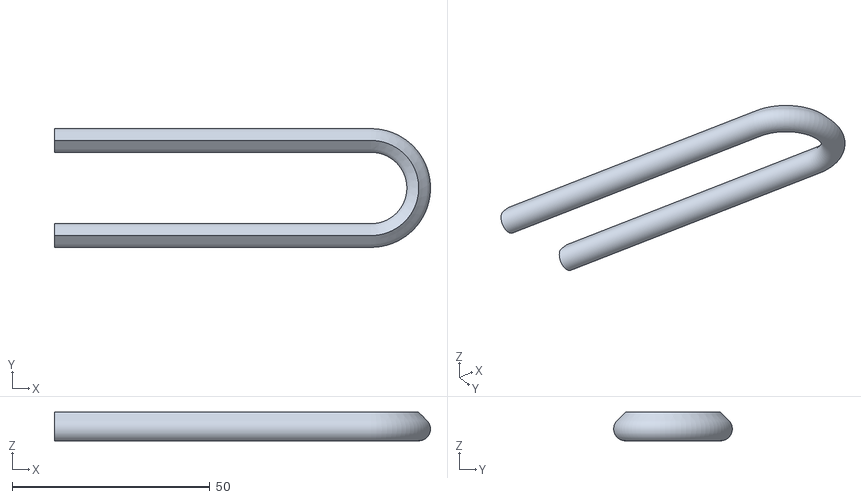
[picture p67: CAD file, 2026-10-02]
docs/studies/993-air-oil-20261002/cad/coupon-fluid-domain-concept-only.stl
95.0 x 30.0 x 7.24

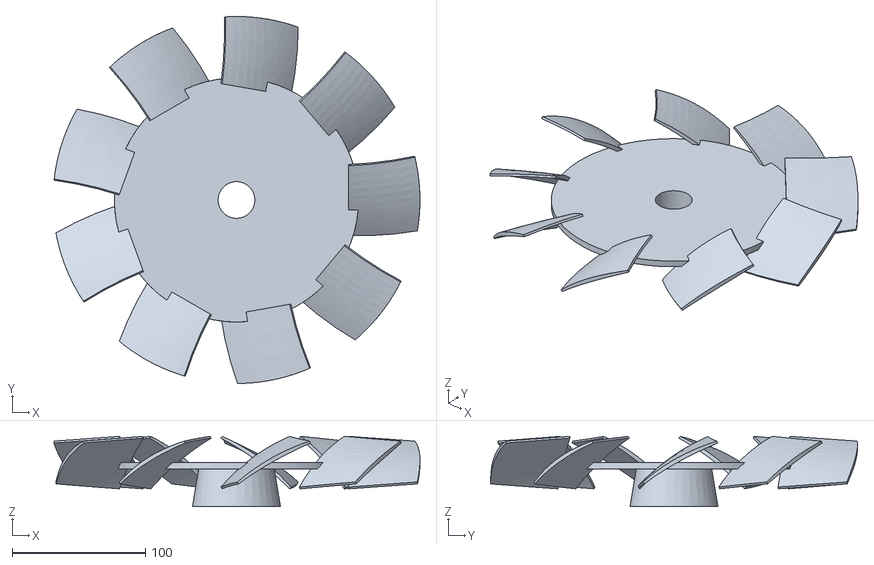
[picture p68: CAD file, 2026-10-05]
models/horizontal-fan-reconstruction/results/assembly/S1/geometry/V2_original_assembly_solid0.stl
274.2 x 275.0 x 52.7

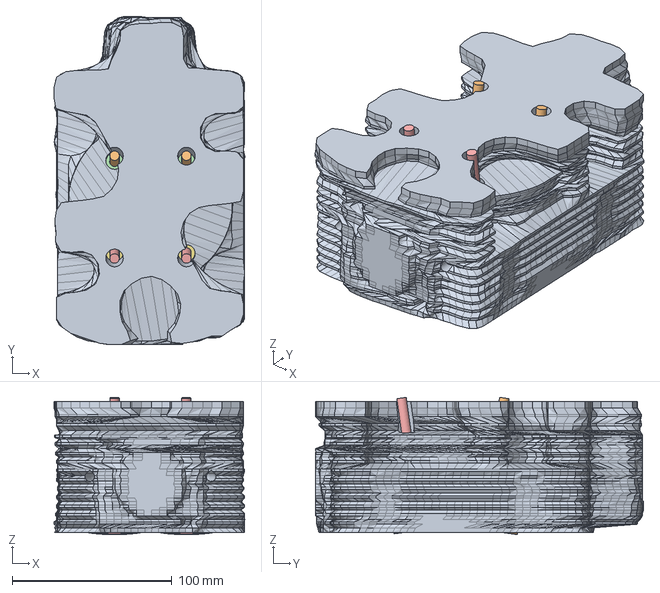
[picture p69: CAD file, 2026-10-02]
docs/studies/993-air-oil-20261002/cad/head-4v-air-oil-assembly.step
119.5 x 205.5 x 85.9 mm

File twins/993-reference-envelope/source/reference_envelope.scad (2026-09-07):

// Generated by scripts/generate_twin_envelope.py; edit the generator or source data.
// This is a reference envelope and datum cage, not a reconstructed Porsche body.
// Coordinate system: X front-to-rear, Y left/right about centreline, Z upward from ground.
// Axle positions are centred in the length only for visualisation; their overhangs are not sourced.

length_mm = 4260; // MNL-TECH-0022, PDF p.19
width_mm = 1735; // MNL-TECH-0023, PDF p.19
height_mm = 1315; // MNL-TECH-0024, PDF p.19
wheelbase_mm = 2272; // MNL-TECH-0026, PDF p.19
front_track_mm = 1405; // MNL-TECH-0027, PDF p.19
rear_track_mm = 1444; // MNL-TECH-0028, PDF p.19
ground_clearance_mm = 120; // MNL-TECH-0029, PDF p.19
display_beam_mm = 2; // visualisation thickness, not a vehicle dimension
front_axle_x = (length_mm - wheelbase_mm) / 2; // visualisation assumption
rear_axle_x = front_axle_x + wheelbase_mm; // visualisation assumption

module beam_x(x, y, z, length) {
    translate([x, y, z]) cube([length, display_beam_mm, display_beam_mm]);
}
module beam_y(x, y, z, length) {
    translate([x, y, z]) cube([display_beam_mm, length, display_beam_mm]);
}
module beam_z(x, y, z, length) {
    translate([x, y, z]) cube([display_beam_mm, display_beam_mm, length]);
}

module envelope_cage() {
    color([0.20, 0.55, 0.95, 0.35]) {
        for (z = [0, height_mm]) for (y = [-width_mm / 2, width_mm / 2])
            beam_x(0, y, z, length_mm);
        for (z = [0, height_mm]) for (x = [0, length_mm])
            beam_y(x, -width_mm / 2, z, width_mm);
        for (x = [0, length_mm]) for (y = [-width_mm / 2, width_mm / 2])
            beam_z(x, y, 0, height_mm);
    }
}

module datum_cage() {
    // The clearance line is a reference plane, not the underside of a body surface.
    color([1.00, 0.70, 0.10, 0.75])
        beam_y(0, -width_mm / 2, ground_clearance_mm, width_mm);
    color([0.90, 0.15, 0.15, 0.85]) {
        beam_y(front_axle_x, -front_track_mm / 2, 0, front_track_mm);
        beam_y(rear_axle_x, -rear_track_mm / 2, 0, rear_track_mm);
    }
}

envelope_cage();
datum_cage();

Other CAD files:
models/horizontal-fan-reconstruction/V5-assembly.step
models/horizontal-fan-reconstruction/R0-assembly.step
docs/studies/993-air-oil-20261002/cad/head-fluid-domain-concept-only.stl
docs/studies/993-air-oil-20261002/cad/coupon-fluid-domain.step
archive/935-cad-recode-20260927/run/fresh-v2/recovered/circular-profiles.step
docs/studies/993-air-oil-20261002/cad/component-01-context.stl
docs/studies/993-air-oil-20261002/cad/component-02-context.stl
docs/studies/993-air-oil-20261002/cad/component-03-context.stl
docs/studies/993-air-oil-20261002/cad/component-04-context.stl
docs/studies/993-air-oil-20261002/cad/component-05-context.stl
docs/studies/993-air-oil-20261002/cad/component-06-context.stl
docs/studies/993-air-oil-20261002/cad/component-07-context.stl
docs/studies/993-air-oil-20261002/cad/component-08-context.stl
docs/studies/993-air-oil-20261002/cad/component-09-context.stl
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

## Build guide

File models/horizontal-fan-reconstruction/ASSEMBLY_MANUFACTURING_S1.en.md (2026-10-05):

# S1 assembly and V2 manufacturing preparation

The S1 study assembly and V2 stock with allowances are now editable and checked
as geometry. Functional manufacturing remains blocked by physical interfaces
and process qualification. 935/993 identity, the 275 mm scale and nine blades
remain unverified. This dossier extends existing calculations; no improvement
in flow, service life or fit is inferred from these new envelopes.

[**S1 STEP assembly**](results/assembly/S1/S1-assembly.step) ·
[CAD checks](results/assembly/S1/geometry-report.json) ·
[Editable parameters](parameters/assembly-study-S1.json) ·
[Conditional bill of materials](results/assembly/S1-review-packet.json) ·
[Stock STEP with allowances](results/lpbf/V2-stock-scenario/V2-stock-scenario.step) ·
[S1 OpenUSD](omniverse/S1-layout.usda)

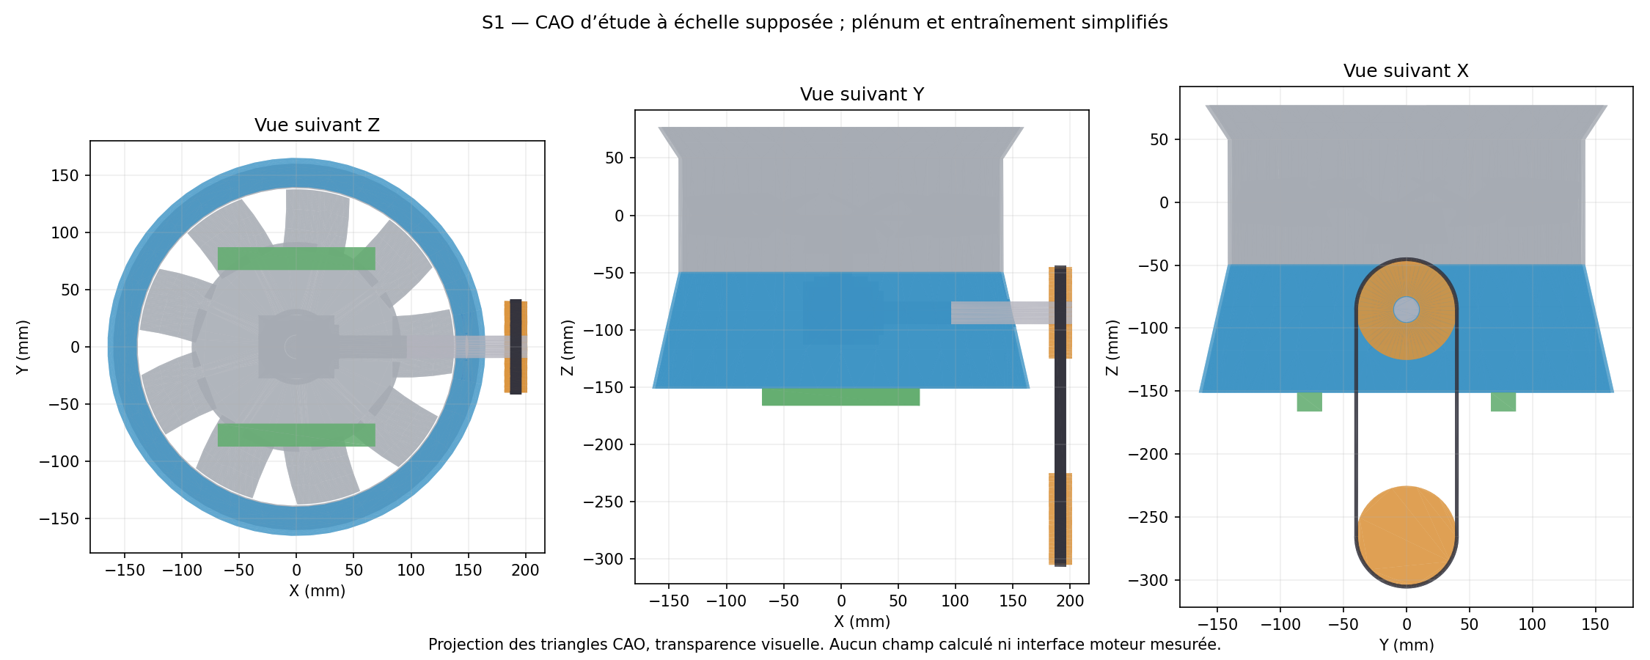
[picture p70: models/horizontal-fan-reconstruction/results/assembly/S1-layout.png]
Actual S1 CAD projections


## What was drawn and what remains to be measured

Original V2 geometry is imported without moving or modifying its solids.
The new plenum is an open conical shell: depth 101.75 mm, upper radius
141.90 mm, lower radius 165 mm and nominal thickness 2.5 mm, all chosen for
the study. A central 60.5 mm exclusion is reserved symbolically for the
right-angle drive; no measured central tube or cylinder-head passage is
claimed. The 12 mm-radius side passage avoids the shaft envelope. The BRep
check finds no volumetric intersection between this shell and the original
V2 assembly.

Two pulleys are represented by their 80 mm pitch-diameter envelopes, 180 mm
center distance and 20 mm width. The input shaft has an envelope extension;
the belt follows the pitch path of equal pulleys. Two 20×15 mm bars represent
support stocks. These positions define a packaging variant; they are not axes,
holes, seating surfaces or attachments measured on an engine. Teeth, belt
profiles, bearings, retention, passage sealing, the distribution collector and
cylinder-head connections remain to be defined. Right-angle-drive envelopes
are not manufacturable gears.

The seven groups contain 19 solids. Every BRep is valid and has positive volume
after STEP export/reimport. The conical shell has a relative volume difference
of approximately 6.17×10⁻⁷; the representation bound retained for S1 is 10⁻⁶,
distinct from historical checks and without manufacturing-tolerance authority.
No actual-engine packaging, rubbing, fastening or loaded-transmission check
is closed.

The [independent contract](parameters/assembly-interface-contract.json) defines
nine interfaces, 52 features to fill in and the load paths:
rotor→shaft→bearings→housing→support→engine;
engine drive→belt→pulley→shaft→bearings→right-angle drive→rotor;
housing/plenum→supports→engine. The
[blank measurement sheet](results/assembly/S1-interface-measurement-sheet.csv)
requires values, units, uncertainty, instrument/calibration, datums, reference,
evidence and review. The exact catalogue variant, manufacturing limits and
service-entry review are also missing: 55 open items. CAD output does not
provide its own measurement evidence. The
[admission check](source/assembly_interface_gate.py) rejects functional
promotion incompatible with this contract.

## Conditional drive and plenum sizing

For the chosen scenario, 5 Nm at 6000 rpm represent 3.142 kW. An 80 mm pulley
gives 25.13 m/s belt speed and a 125 N tension difference. With 200 N pretension
per span, simplified tensions become 262.5 / 137.5 N and the radial load for
equal pulleys is 400 N. These formulas ignore stiffness, dynamic tension,
losses, excitation, effective angle and manufacturer data: no belt, bearing
or shaft model is selected. The ideal ratio is 1 and the open-belt pitch length
is 611.33 mm; commercial length and tensioner remain to be selected after
measurement.

The assumed available bottom annular area is 0.07049 m². The unconverged
point D2 flow of 1.156 m³/s would give 16.40 m/s through this area. This
continuity calculation predicts neither distribution to the cylinder heads,
pressure losses nor plenum efficiency. The six cooling flows and installed-path
resistances remain to be established. S1 is not the D2 CFD domain: its shell
has not yet been meshed or simulated.

## Rotor stock and LPBF scenario

The [original V2](V2-rotor.step) rotor retains its assumed final geometry.
The [study stock](results/lpbf/V2-stock-scenario/V2-stock-scenario.step) adds
0.5 mm radially at the bore and 0.5 mm at each hub face. Other surfaces remain
identical. The stock bore becomes 26.5 mm for an assumed final 27.5 mm bore;
no physical fit is established. The stock forms one valid connected solid,
verified after STEP reimport.

Volume increases from 265377.43 to 269123.98 mm³; the allowance represents
3746.55 mm³. At the indicative 2700 kg/m³ density, mass increases from 0.7165
to 0.7266 kg. Neither this density nor the 0.5 mm are approved properties or
allowances for an AlSi10Mg lot. Earlier R0/V5 manufacturing distortions do not
justify these stocks and do not automatically transfer to V2.

The [tessellated stock screening](results/lpbf/V2-stock-orientation-screen.json)
compares six orientations, without actual supports or a laser recipe. Flat
stock measures approximately 274.20×274.98×53.17 mm. With 10 mm clearance per
side it does not fit the conservative 250×250×300 mm scenario; it nominally
fits the reference BLT 400/450×300×400 mm envelopes. Edgewise with diagonal
rotation, its box is 212.77×215.22×274.98 mm: it fits all three scenarios with
the chosen clearance. The geometric layer count at 50 µm increases from 1064
to 5500. This is neither a manufacturing time nor a qualified thickness.
STL volume differs from BRep by 0.189 %; this is a representation check.
Support-column proxies may overlap and are not printable support geometry.

Machine variants remain references. The exact S400 version, usable volume,
material/lot, treatment and recipe require confirmation; see the
[manufacturing review and its primary sources](MANUFACTURING_REVIEW.md).
The 12 earlier elastic simulations evaluate an assumed contraction with
idealized supports; they do not simulate melting, thermal history, plasticity,
laser scanning or porosity. No new V2 process solver was executed for this
dossier.

## Proposed route for technical review

| Step | Required input and evidence | State |
| --- | --- | --- |
| Definition | Exact variant, measured interfaces, datums and toleranced drawing; flow, speed and fatigue needs | Missing |
| Material/process | AlSi10Mg lot and final condition, qualified machine/recipe, directional and temperature-dependent properties | Candidates, unqualified |
| Preparation | Revised stock, supports/plate, contact zones and removal access, orientation, representative witnesses | Study stock and screening available |
| Calibration | Distortion and material specimens, independent build for process-model validation | No physical data |
| Build | Signed machine file, atmosphere and parameter logs, material/build traceability | No manufacturing authorized |
| Treatment/cutting | Approved sequence, furnace record, measurements before/after release, accessible removal | To be defined with the workshop |
| Machining | Bore/faces located in approved datums, access and clamping, deburring without critical root reduction | Study stocks and access only |
| Inspection | Dimensions/runout, CT or qualified method, defects/surface, material and coupons; engineer-defined limits | No physical acceptance |
| Balancing/service | Correction plans, prestressed modal/gyroscopic analysis, fatigue, contained rotation tests and professional review | Plan to approve, no actual test |

The plenum and support stocks have possible conventional routes; the drive
requires a mechanical definition and suitable components. The
[bill of materials](results/assembly/S1-review-packet.json) leaves unknown
quantities, masses and suppliers at `null`, rather than converting visual
envelopes into order references.

## OpenUSD and reproduction

The [S1 asset](omniverse/S1-layout.usda) separates the 19 solids under their
groups, in meters, with +Z axis and no deformation. Colors identify visual
roles. It links parameters, interface contract, CAD, CFD diagnosis and this
dossier. All STL-derived coordinates are checked against their float32 storage.
The [OpenUSD checks](omniverse/S1-layout-validation.json) cover composition,
topology, units and material bindings; the Sdr shader rule remains blocked by
resources missing from the available runtime. No GPU, Omniverse RTX, qualified
SimReady or validated physical twin is claimed. The
[NVIDIA CAD→SimReady workflow](https://github.com/NVIDIA/skills/tree/main/skills/omniverse-cad-to-simready)
requires a GPU/Content Agents chain unavailable here; it was not installed.

With the CAD and OpenUSD libraries already present, from this directory,
in new private directories:

```sh
"$CAD_PYTHON" source/build_assembly_study.py . "$PRIVATE_FAN_WORKSPACE/S1"
"$CAD_PYTHON" source/prepare_v2_manufacturing_stock.py . "$PRIVATE_FAN_WORKSPACE/V2-stock"
python3 source/screen_v2_stock.py "$PRIVATE_FAN_WORKSPACE/V2-stock" "$PRIVATE_FAN_WORKSPACE/V2-stock-screen.json"
```

The [OpenUSD/render exporter](source/export_s1_layout.py) requires the USD
runtime; [review-packet generation](source/build_s1_review_packet.py) requires
only published reports. None of these tools launches a solver, installs
software or contacts a workshop.
[D3 diagnosis and independent compute budget](D3_ESTABLISHMENT_DIAGNOSTIC.en.md).

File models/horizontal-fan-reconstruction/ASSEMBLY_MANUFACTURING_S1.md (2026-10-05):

# Assemblage S1 et préparation de fabrication V2

L'assemblage d'étude S1 et le brut V2 avec surépaisseurs sont maintenant
éditables et contrôlés comme géométrie. Leur fabrication fonctionnelle reste
bloquée par les interfaces physiques et la qualification du procédé.
L'identité935/993, l'échelle275 mm et les neuf pales restent non vérifiées.
Ce dossier prolonge les calculs existants ; aucune amélioration de débit,
durée de vie ou aptitude au montage n'est déduite de ces nouvelles enveloppes.

[**Assemblage STEP S1**](results/assembly/S1/S1-assembly.step) ·
[Contrôles CAO](results/assembly/S1/geometry-report.json) ·
[Paramètres modifiables](parameters/assembly-study-S1.json) ·
[Nomenclature conditionnelle](results/assembly/S1-review-packet.json) ·
[Brut STEP avec surépaisseurs](results/lpbf/V2-stock-scenario/V2-stock-scenario.step) ·
[OpenUSD S1](omniverse/S1-layout.usda)

Projections de la CAO réelle S1

## Ce qui a été dessiné et ce qui reste à mesurer

La géométrie V2 d'origine est importée sans déplacement ni modification de ses
solides. Le nouveau plénum est une coque conique ouverte : profondeur101,75 mm,
rayon supérieur141,90 mm, rayon inférieur165 mm et épaisseur nominale2,5 mm,
tous choisis pour l'étude. Une exclusion centrale de60,5 mm est réservée
symboliquement au renvoi d'angle ; aucun tube central ni passage de culasse
mesuré n'est prétendu. Le passage latéral de rayon12 mm évite l'enveloppe de
l'arbre. Le contrôle BRep ne trouve aucune intersection volumique entre cette
coque et l'assemblage V2 d'origine.

Deux poulies sont représentées par leurs enveloppes de diamètre primitif80 mm,
entraxe180 mm et largeur20 mm. L'arbre d'entrée possède une prolongation
d'enveloppe ; la courroie suit le chemin primitif de poulies égales. Deux
barres20×15 mm représentent des stocks de support. Ces positions définissent
une variante de packaging ; elles ne sont pas des axes, perçages, portées ou
fixations relevés sur un moteur. Dentures, profils de courroie, roulements,
retenues, étanchéité du passage, collecteur de distribution et raccords des
culasses restent à définir. Les enveloppes du renvoi d'angle ne sont pas des
engrenages fabricables.

Les sept groupes contiennent19 solides. Tous les BRep sont valides et ont un
volume positif après export/réimport STEP. La coque conique présente une
différence volumique relative d'environ6,17×10⁻⁷ ; la borne de représentation
retenue pour S1 est10⁻⁶, distincte des contrôles historiques et sans valeur
de tolérance de fabrication. Aucune vérification de packaging moteur réel,
de frottement, de fixation ou de transmission sous charge n'est close.

Le [contrat indépendant](parameters/assembly-interface-contract.json) définit
neuf interfaces,52 caractéristiques à renseigner et les chemins d'efforts :
rotor→arbre→roulements→carter→support→moteur ; entraînement moteur→courroie→
poulie→arbre→roulements→renvoi d'angle→rotor ; carter/plénum→supports→moteur.
La [fiche de mesures vierge](results/assembly/S1-interface-measurement-sheet.csv)
demande valeurs, unités, incertitude, instrument/calibration, datums, référence,
preuve et revue. La variante catalogue exacte, les limites de fabrication et
la revue de mise en service manquent aussi :55 éléments non clos. Une sortie
CAO ne fournit pas ses propres preuves de mesure. Le
[contrôle d'admission](source/assembly_interface_gate.py) rejette toute
promotion fonctionnelle incompatible avec ce contrat.

## Dimensionnement conditionnel de l'entraînement et du plénum

Pour le scénario choisi,5 Nm à6000 rpm représentent3,142 kW. Une poulie80 mm
donne25,13 m/s de vitesse de courroie et125 N de différence de tension.
Avec200 N de prétension par brin, les tensions simplifiées deviennent262,5 /
137,5 N et la charge radiale de poulies égales400 N. Ces formules ignorent
raideur, tension dynamique, pertes, excitation, angle effectif et données
fabricant : aucun modèle de courroie, roulement ou arbre n'est sélectionné.
Le ratio idéal vaut1, la longueur primitive de courroie ouverte611,33 mm ;
la longueur commerciale et le tendeur restent à choisir après mesure.

L'aire annulaire disponible supposée en bas vaut0,07049 m². Le débit ponctuel
D2 non convergé de1,156 m³/s donnerait16,40 m/s à travers cette aire. Ce calcul
de continuité ne prédit ni répartition vers les culasses, ni pertes de charge,
ni efficacité du plénum. Les six débits de refroidissement et les résistances
des chemins installés restent des données à établir. S1 n'est pas le domaine
CFD D2 : sa coque n'a pas encore été maillée ou simulée.

## Brut de rotor et scénario LPBF

Le rotor [V2 original](V2-rotor.step) conserve sa géométrie finale supposée.
Le [brut d'étude](results/lpbf/V2-stock-scenario/V2-stock-scenario.step) ajoute
0,5 mm radial au bore et0,5 mm sur chaque face de moyeu. Les autres surfaces
restent identiques. Le bore du brut devient26,5 mm pour un bore final supposé
de27,5 mm ; aucun ajustement physique n'est établi. Le brut forme un solide
connecté valide, vérifié après réimport STEP.

Le volume passe de265377,43 à269123,98 mm³ ; la surépaisseur représente3746,55 mm³.
À la densité indicative2700 kg/m³, la masse passe de0,7165 à0,7266 kg. Ni cette
densité ni les0,5 mm ne sont des propriétés ou allowances approuvées pour un
lot AlSi10Mg. Les déformations de fabrication antérieures R0/V5 ne justifient
pas ces stocks et ne se transfèrent pas automatiquement à V2.

Le [screening du brut tessellé](results/lpbf/V2-stock-orientation-screen.json)
compare six orientations, sans support réel ou recette laser. À plat, le brut
mesure environ274,20×274,98×53,17 mm. Avec10 mm de marge par côté il ne rentre
pas dans le scénario conservateur250×250×300 mm ; il rentre nominalement dans
les enveloppes BLT de référence400/450×300×400 mm. Sur chant avec rotation
diagonale, sa boîte vaut212,77×215,22×274,98 mm : elle rentre dans les trois
scénarios avec la marge choisie. Le nombre géométrique de couches à50 µm passe
de1064 à5500. Ce n'est ni un temps de fabrication, ni une épaisseur qualifiée.
Le volume du STL diffère de0,189 % du BRep ; c'est un contrôle de représentation.
Les proxies de colonnes de supports peuvent se chevaucher et ne constituent
pas une géométrie de support imprimable.

Les variantes de machine restent des références. La version exacte S400,
le volume utile, le matériau/lot, le traitement et la recette doivent être
confirmés ; voir la [revue de fabrication et ses sources primaires](MANUFACTURING_REVIEW.md).
Les12 simulations élastiques antérieures évaluent une contraction supposée,
avec supports idéalisés, et ne simulent pas fusion, histoire thermique,
plasticité, scan laser ou porosité. Aucun nouveau solveur de procédé V2 n'a
été exécuté pour ce dossier.

## Gamme proposée pour la revue technique

| Étape | Entrée et preuve attendues | État |
| --- | --- | --- |
| Définition | Variante exacte, interfaces mesurées, datums et dessin tolérancé ; besoins de débit, régime et fatigue | Manquants |
| Matière/process | Lot AlSi10Mg et état final, machine/recette qualifiés, propriétés directionnelles et dépendantes de température | Candidats, non qualifiés |
| Préparation | Brut révisé, supports/plateau, zones de contact et accès de dépose, orientation, témoins représentatifs | Brut d'étude et screening disponibles |
| Calibration | Éprouvettes de distorsion et matériau, build indépendant de validation du modèle process | Aucune donnée physique |
| Construction | Fichier machine signé, journal d'atmosphère et paramètres, traçabilité matière/build | Aucune fabrication autorisée |
| Traitement/découpe | Séquence approuvée, enregistrement four, mesures avant/après libération, dépose accessible | À définir avec l'atelier |
| Usinage | Reprise bore/faces dans datums approuvés, accès et bridage, ébavurage sans réduction critique des racines | Stocks et accès d'étude seulement |
| Inspection | Dimensions/runout, CT ou méthode qualifiée, défauts/surface, matière et coupons ; limites fixées par l'ingénieur | Aucune acceptation physique |
| Équilibrage/service | Plans de correction, modal précontraint/gyroscopie, fatigue, essais de rotation contenus et revue professionnelle | Plan à approuver, aucun essai réel |

Le plénum et les stocks de supports ont des routes conventionnelles possibles ;
l'entraînement exige une définition mécanique et des composants adaptés.
La [nomenclature](results/assembly/S1-review-packet.json) laisse les quantités,
masses et fournisseurs inconnus à `null`, au lieu de transformer les
enveloppes visuelles en références de commande.

## OpenUSD et reproduction

L'[asset S1](omniverse/S1-layout.usda) sépare les19 solides sous leurs groupes,
en mètres, axe+Z, sans déformation. Les couleurs identifient les rôles visuels.
Il relie paramètres, contrat d'interfaces, CAO, diagnostic CFD et présent dossier.
Toutes les coordonnées issues des STL sont contrôlées contre leur stockage
float32. Les [contrôles OpenUSD](omniverse/S1-layout-validation.json) couvrent
composition, topologie, unités et liaisons de matériaux ; la règle shader Sdr
reste bloquée par les ressources absentes du runtime disponible. Aucun GPU,
Omniverse RTX, SimReady qualifié ou jumeau physique validé n'est revendiqué.
Le [workflow NVIDIA CAD→SimReady](https://github.com/NVIDIA/skills/tree/main/skills/omniverse-cad-to-simready)
requiert une chaîne GPU/Content Agents qui n'est pas disponible ici ; elle
n'a pas été installée.

Avec les bibliothèques CAO et OpenUSD déjà présentes, depuis ce dossier,
dans de nouveaux répertoires privés :

```sh
"$CAD_PYTHON" source/build_assembly_study.py . "$PRIVATE_FAN_WORKSPACE/S1"
"$CAD_PYTHON" source/prepare_v2_manufacturing_stock.py . "$PRIVATE_FAN_WORKSPACE/V2-stock"
python3 source/screen_v2_stock.py "$PRIVATE_FAN_WORKSPACE/V2-stock" "$PRIVATE_FAN_WORKSPACE/V2-stock-screen.json"
```

L'[exporteur OpenUSD/rendu](source/export_s1_layout.py) exige le runtime USD ;
la [génération du paquet de revue](source/build_s1_review_packet.py) exige
seulement les rapports publiés. Aucun de ces outils ne lance un solveur,
n'installe un logiciel ou ne contacte un atelier.
[Diagnostic D3 et budget de calcul indépendant](D3_ESTABLISHMENT_DIAGNOSTIC.md).

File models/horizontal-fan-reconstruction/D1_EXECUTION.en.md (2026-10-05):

# D1 executed and stopped within the initial budget

The diagnosis received an explicit Kali2 window after the Ti pilot was released.
It does not produce a complete comparison at 960: the control finishes, the
strict branch is interrupted. No result is admitted and no solver is restarted
after the limit. [Native report](results/cfd/D1-bounded-result.json) ·
[Actually computed residuals](results/cfd/D1-residuals.png) ·
[Input hashes](results/cfd/D1-diagnostic-input-manifest.json).

## Execution and exact measurements

The first preparation stops in 8.24 s before any solver: copying processor
directories dereferenced their `900/uniform` links, creating four extra files
in one branch. The strict partition guard rejected the difference. The fix
retains those links (`symlinks=True`); no physics, condition, tolerance, cell,
initial field or iteration is added. The
[initially prepared code](source/run_d1_in_container_setup_v1.py) and
[initial manifest](parameters/D1-prepared-pair-manifest-setup-v1.json) remain
preserved. The corrected partition is identical before both solvers.

The repair, preparation diagnosis and both solvers stay within the same
initial ten-minute limit: the outer envelope is recalculated with 202 s
remaining, then stops only the D1 container. The native ledger measures
**590.318 s from initial launch**, without exceeding 600 s. The first
preparation calculated zero flow iterations.

| Branch | Completed iterations | Measurements per table, including initial state | New measurements | Final 941–960 window | Final 960 fields | Status |
| --- | ---: | ---: | ---: | --- | --- | --- |
| relTol 0.01 | 60, 901–960 | 61 | 60 | twenty verified measurements | reconstructed, five complete fields of 453496 cells | unadmitted: pressure |
| relTol 0 | 29, 901–929 | 30 | 29 | absent | absent; only restart 900 exists | incomplete, not evaluated for admission |

Iteration 930 is entered but completes only two of three p corrections;
it has neither complete flow/torque measurement nor `ExecutionTime`.
It is excluded from statistics and rendering. Original thresholds remain
unchanged. The [control at 960](results/cfd/D1-control-960-flow-summary.json)
passes U, turbulence, mass, stability, direction and finite-field criteria,
but its maximum initial p residual over the last twenty iterations is
1.38616×10⁻⁴ against 10⁻⁴. Mean flow 1.15229935 m³/s, power 2429.758 W;
these values are not admitted performance.

## Convergence difference over the common prospective window

Only the first planned window 901–920 has twenty complete measurements for
both branches. The strict 921–940 window is incomplete; strict 941–960 is
absent. They are not replaced by a window selected after calculation.

| Measurement 901–920 | relTol 0.01 | relTol 0 |
| --- | ---: | ---: |
| Maximum initial p residual | 1.30859×10⁻⁴ | 1.31086×10⁻⁴ |
| Maximum final linear p residual | 9.60328×10⁻⁷ | 9.90354×10⁻⁹ |
| Mean linear p iterations, sum of three corrections | 11.20 | 29.95 |
| Mean flow, m³/s | 1.152299245 | 1.152299252 |
| Mean power, W | 2429.7772 | 2429.7775 |

The final linear residual decreases by a factor of 96.97 and linear-iteration
cost increases by a factor of 2.674. The initial residual maximum changes by
only +0.174 % and stays above the threshold. Initial curves nearly overlap
over the twenty-nine available strict iterations. On this window, this weakens
the explanation that linear stopping alone causes the exceedance.
Nonlinear coupling, mesh/wake and outlet effects remain to be distinguished.
No physical oscillatory phenomenon, confidence interval, variant ranking or
improved efficiency is established. The incomplete strict 960 target prevents
a final paired conclusion.

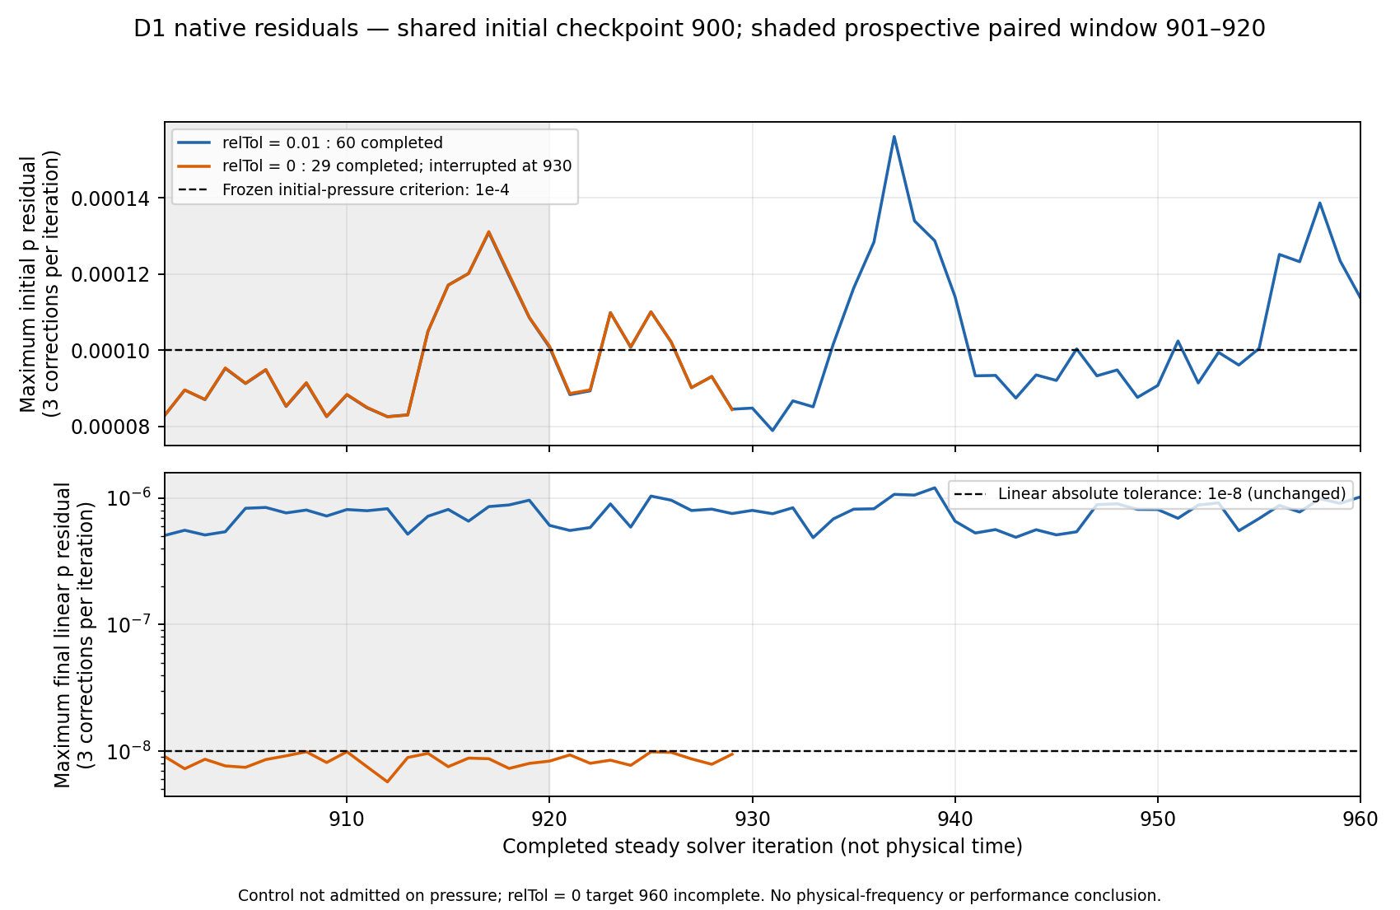
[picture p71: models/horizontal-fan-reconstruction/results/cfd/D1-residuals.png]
Native D1 residuals, without extrapolating the interrupted branch


## Preserved evidence and released resources

The observed container respects 4 CPU, cpuset 0/2/4/5, 5 GiB RAM and
memory+swap, no networking, UID 1000, dropped capabilities and read-only
mounted sources. It is no longer active; at 17:07:52 UTC only the two
pre-existing services remain. No installation, rental or service change.

The retrieved private archive preserves both attempts, logs, measurements,
protocols, partition evidence and the control's 960 checkpoint: 63 files,
47047995 compressed bytes, SHA-256
`362c82e93a3ed2ae27532f1c7aaa62115b8c02e49146f900caba2fbf1c411dc2`.
Members and transfer are verified; the 900 checkpoint and mesh are already
retained in the initial native archive. The twenty small inputs used in
analysis match that archive's hashes. Post-calculation archiving took 1.72 s,
bounded at 1 CPU/1 GiB; it restarts no solver. Complete fields/logs remain
private. The [archive evidence](results/runtime/D1-native-archive-verification.json)
attests preservation without publishing complete outputs.

Historical fine R0 admission remains withdrawn; D1 supplies none of its
missing measurements. A final strict comparison would require a newly
explicitly coordinated window: no restart or extension is launched.
Physical interfaces and installed-cooling scenarios also remain to be established.

The [local analysis of preserved fields and proposed next trial](D1_NEXT_DIAGNOSTIC.en.md)
complements this result without new execution. The
[installed subsystems](SUBSYSTEM_PARAMETERS.en.md) remain symbolic and without
measured dimensions.

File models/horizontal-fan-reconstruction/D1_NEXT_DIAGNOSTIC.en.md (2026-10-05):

# After D1: possible causes and proposed discriminating trial

**Update:** the single trial prepared here was authorized and executed.
The [D1C result](D1C_EXECUTION.en.md) passes original numerical criteria but retains
backflow and physical limits. No additional batch was launched.

The [verified private native fields](results/cfd/D1-local-field-diagnostic.json)
allow this lightweight analysis without a new solver. It complements the
[D1 result](D1_EXECUTION.en.md). The control remains unadmitted on pressure;
the strict branch remains incomplete. Field differences do not locate the
pressure equation's algebraic residual.

## Ranked hypotheses

| Priority | Hypothesis | Quantified indicators and scope |
| --- | --- | --- |
| 1 | Nonlinear velocity–pressure update in the blade-tip wake | At 901–920, the strict solver reduces the final residual by a factor of 96.97 and mean local continuity error by 19.40, but the initial maximum changes by +0.174 %. Over the control's 60 iterations, the third correction starts on average at 21.27 % of the first correction's initial residual; some first corrections still exceed the threshold during later updates. Global linearization/correction merits a sensitivity test, without concluding it is the cause. |
| 2 | Nearby-outlet influence in a backflow zone | At 960, net flow is 1.15229968 m³/s and gross backflow 0.12399009 m³/s, or 10.76 % of net flow; 35.15 % of outlet area has inward flux. The ten largest pressure variations remain 31.7–34.1 mm from this outlet, approximately 0.12 D. Proximity and backflow make length sensitivity plausible; they do not prove an incorrect condition. |
| 3 | Mesh conditioning or local resolution | Reproduced metrics match the independent check: non-orthogonality 71.0857°, skewness 1.09927, minimum determinant 0.00515090. The 1 448 cells with \|Δp\| > 1 Pa have maximum non-orthogonality 55.05°, maximum skewness 0.80398 and minimum determinant 0.02393. None overlaps the 69 cells above 65°. The ten maxima have angles 14.9–32.8°. The “worst cells alone” cause is weakened; wake resolution and absent layers remain unqualified. |

The order above represents test priority, not cause probability.
Coarse V2 converges despite maximum non-orthogonality above that of the fine
grid; one global metric therefore does not justify remeshing.

Between 900 and 960, volume-weighted RMS Δp = 0.291515 Pa, maximum = 131.776 Pa;
RMS ΔU = 0.0221393 m/s. Cells above 1 Pa occupy 0.240615 % of volume.
Maxima are at radii 129.3–137.0 mm, z = −15.4 to −17.9 mm, 0.51–2.43 mm from
the nearest rotor-face centroid. These distances are geometric proxies, not
wall distances. Cellular correlation \|Δp\| / \|ΔU\| is 0.487; it proves no causality.

## Condition and flux consistency

Condition types are identical at 900 and 960: rotor `MRFnoSlip` /
pressure `zeroGradient`, housing `noSlip` / pressure `zeroGradient`,
inlet and outlet `pressureInletOutletVelocity`, zero inlet total pressure
and zero outlet static pressure. This configuration does permit observed
backflow. It represents an isolated fan, not measured engine thermal or
hydraulic resistance. Imposed backflow turbulence, engine interfaces and
compressible sensitivity remain to be qualified.

The discrete divergence sum of relative MRF `phi` at 960 is 1.78165×10⁻⁷ m³/s
and matches the sum of **four** patches. The two ports alone have imbalance
1.64016×10⁻⁵ m³/s; relative rotating-face fluxes explain the difference.
This sum is not read as absolute wall leakage. The diagnosis accesses neither
the pressure matrix nor its cellular residual field; it does not claim to
identify cells with the maximum initial residual.

The [official correction code](https://raw.githubusercontent.com/OpenFOAM/OpenFOAM-13/master/applications/modules/incompressibleFluid/correctPressure.C)
shows that `consistent yes` changes the inverse diagonal coefficient and
flux/velocity corrections. The
[geometric-check code](https://raw.githubusercontent.com/OpenFOAM/OpenFOAM-13/master/src/meshCheck/primitiveMeshCheck/primitiveMeshCheck.C)
underlies the three reproduced local metrics; their extrema are compared to
independent results before this report is accepted.

## Smallest proposed trial before launch: one branch

The [fixed protocol](parameters/D1-coupling-proposed-protocol.json) and
[candidate dictionary](parameters/D1-coupling-candidate/fvSolution) change
**only `SIMPLE.consistent no` to `yes`**. The D1 control's 60 complete iterations
are reused rather than recalculated. The candidate branch would start from
the same 900 checkpoint and MPI partition for 901–960. Grid, initial fields,
physics, conditions, schemes, p relaxation = 0.15, relTol = 0.01, absolute
tolerance = 10⁻⁸ and all criteria are identical. Each hash and `uniform`
link is verified before the solver.

Proposed cost: 4 CPU / 5 GiB RAM **and memory+swap**, one branch; approximately
112 s of solver time based on the native control, approximately 180 s total,
**300 s overall ceiling including preparation/reconstruction/audit**, MPI
ceiling 180 s. No third-party service, installation or new access. Launch is
blocked until a window is coordinated; an error or overrun ends the batch
and preserves its receipt, without automatic restart.

The three windows 901–920 / 921–940 / 941–960 are fixed before calculation;
telemetry every iteration and checkpoint at 960. Original criteria remain
mandatory over 941–960: p ≤10⁻⁴, U ≤10⁻⁵, k/ω ≤10⁻⁴, imbalance ≤0.5 %, flow CV
≤1 %, torque CV ≤2 %, direction and complete finite fields.

- A maximum p reduced by at least 30 % relative to the control **and** every
  original criterion satisfied would support coupling sensitivity.
- A change below 10 % over a complete window would not support it.
- Between these bounds or if incomplete: a descriptive result, with no
  invented causal conclusion, extension or admission.

These rules are prospective discrimination criteria, not relaxed admission
thresholds. Even numerical success would not qualify installed flow, cooling,
efficiency or physical oscillation. If this trial is not discriminating, the
next preparation would concern a common outlet length, with documented
CAD/mesh gates and field transfer before any new calculation authorization.

Reproduce lightweight analysis from private local archives:

```sh
OPENBLAS_NUM_THREADS=1 OMP_NUM_THREADS=1 VECLIB_MAXIMUM_THREADS=1 python source/analyze_d1_local_fields.py PRIVATE_OLD_INPUTS PRIVATE_960_INPUTS PRIVATE_D1_LOGS work/D1-local-field-diagnostic.json
python source/verify_study.py
```

The script launches neither a solver nor a mesh modification and publishes
no complete native field. Archives and scan remain private.

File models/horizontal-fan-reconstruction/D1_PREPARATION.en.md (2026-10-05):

# Prospective D1 preparation — snapshot before execution

This document describes preparation before launch. The
[current result](D1_EXECUTION.en.md) reports the completed control and interrupted
strict branch, without admission. At the date of this preparation, the batch
awaited explicit coordinated release of Kali2. The Ti pilot retains its window;
no D1 solver, container or mesh copy was launched. Small V2/900 dictionaries
were read-only and cross-checked against the private native archive: eight
files, 8027 bytes. Fields and mesh remain on their original resource.

## Comparison frozen before calculation

The [prepared-pair manifest](parameters/D1-prepared-pair-manifest.json)
links nine 900-checkpoint files, thirteen constant files, prepared
configurations and sources. The two branches are:

| Branch | Pressure GAMG relTol | Absolute tolerance | p relaxation | Iterations |
| --- | ---: | ---: | ---: | --- |
| control | 0.01 | 10⁻⁸ | 0.15 | 901–960 |
| absolute | 0 | 10⁻⁸ | 0.15 | 901–960 |

Model, physical conditions, CAD, mesh, other tolerances and original criteria
are unchanged. The future executor copies the same 900 state, verifies copy
hashes, decomposes once and copies the same initial MPI partition into both
branches before the first solver. Cases are sequential. It reruns no failed
case.

Checkpoints have interval 60 and the three flow/force functions interval 1.
The admission window requires twenty measurements at 941–960. The prospective
report also requires all sixty measurements for its three windows:
901–920, 921–940, 941–960. p/U/turbulence residuals, mass, flow/torque stability,
direction and complete finite fields remain required at original thresholds.
The expected 453496-cell count is linked to the native 900 field summary.

Each window reports mean, standard deviation, min/max and CV where the mean
is nonzero: Qin/Qout, total torque, initial and final linear p residual,
global continuity. Differences between final branch means and their CVs are
descriptive. These steady-iteration variations are not physical noise,
independent observations, a confidence interval or a rotor frequency.
No significance threshold is adjusted after calculation. A newly admitted
diagnosis never restores missing historical fine-grid measurements or
retroactively restores fine R0 admission.

## Bounded future execution

The launcher is [launch_d1_pair.py](source/launch_d1_pair.py), with an
[isolated executor](source/run_d1_in_container.py). It uses only the already
available frozen Foundation 13 image, without networking or download:
4 CPU, cpuset 0/2/4/5, 5 GiB RAM and memory+swap, tasks at nice 10.
It requires 6 GiB available at admission and rejects another container of
this image. The overall ceiling is 600 s, including preparation/copies;
container work is capped at 580 s, each MPI at 270 s, without extension.
The launcher reserves time to stop only its named container on timeout,
then preserves logs and receipts. No third-party service is touched.
Estimate: 4–6 min; ceiling: 10 min. Native execution of these new helpers is
not yet verified: that verification awaits the window.

After release and transfer of the local preparation capsule, the Kali2 command
will have the following form. This block documents future execution; it was
not executed.

```sh
python D1_CAPSULE/source/launch_d1_pair.py NATIVE_V2_900_CASE D1_CAPSULE NEW_D1_OUTPUT --coordinated-release COORDINATOR_RELEASE_REFERENCE
```

To reproduce only local preparation, without solver or mesh:

```sh
python source/prepare_d1_configurations.py NATIVE_SMALL_CONFIG SOURCE_IDENTITY_JSON NEW_CONFIG_OUTPUT
```

## Visible subsystems, dimensions pending

The [qualitative contract](parameters/qualitative-subsystem-contract.json)
distinguishes four subsystems to document before functional reconstruction:
installed plenum, front pulley/belt train, ribbed support and observed
central envelope. All parameters and interfaces are unknown (`null`).
The video confirms only a general layout; it measures no diameter, ratio,
attachment axis, material or tolerance. R0 remains an analytical rotor,
housing and transmission; its own model supplies none of the new subsystems'
missing measurements. No new dimensioned geometry or fit evidence is generated.

The [exact publication supplied by the parent](https://www.instagram.com/patrickmotorsports/reel/DeC4x04yjNP/)
claims a “935 3.5L Flat Fan MoTeC EFI” assembly and a 993 6-speed transaxle;
this identifies neither the engine base as 993 nor fan equivalence.
Third-party images remain private. Public engine research is not duplicated here.

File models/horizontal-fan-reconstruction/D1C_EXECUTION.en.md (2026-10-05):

# D1C: completed trial, limited numerical admission

One 60-iteration branch was authorized after Kali2 reservations were released.
It restarts the same V2/900 state and 80 MPI partition files as the preserved
D1 control. The only numerical change is `SIMPLE.consistent no` → `yes`.
No mesh, physical condition, scheme, relaxation, tolerance or admission
criterion is changed.

[Result and native windows](results/cfd/D1C-bounded-result.json) ·
[Original summary at 960](results/cfd/D1C-960-flow-summary.json) ·
[Compared fields and backflow](results/cfd/D1C-matched960-field-differences.json) ·
[Port balance](results/cfd/D1C-960-energy-and-port-analysis.json) ·
[Preservation](results/runtime/D1C-native-archive-verification.json).

## Identical measurements and criteria

All iterations 901–960 finish, without a partial tail. Each native table
contains **61 measurements, including state 900**, or 60 new measurements.
The three prospective windows 901–920 / 921–940 / 941–960 have twenty consecutive
samples; the last is the admission window. Each of the five final
U/p/k/omega/nut fields contains 453 496 finite cells.

| Measurement over 941–960 | D1 control consistent no | D1C consistent yes |
| --- | ---: | ---: |
| Maximum initial p residual | 1.386159985×10⁻⁴ | 7.622277815×10⁻⁵ |
| Mean outlet flow, m³/s | 1.15229935155 | 1.152299802885 |
| Mean power, W | 2429.758222624 | 2429.768471103 |
| Flow CV | 2.77178×10⁻⁷ | 3.30038×10⁻⁷ |
| Torque CV | 3.04282×10⁻⁵ | 2.59172×10⁻⁵ |
| Maximum port imbalance | 1.44516×10⁻⁵ | 1.43770×10⁻⁵ |

The initial p maximum decreases by **45.0116 %**. The candidate passes every
original criterion: p ≤10⁻⁴, U ≤10⁻⁵, k/ω ≤10⁻⁴, imbalance ≤0.5 %, flow CV ≤1 %,
torque CV ≤2 %, direction and complete finite fields. It satisfies the
prospective rule “p decrease ≥30 % and all gates”: this supports **numerical
sensitivity to coupling**, without identifying a physical cause. The D1
control remains unadmitted on p. Missing R0 measurements are not restored and
no historical fine pair is retroactively admitted.

Mean flow changes by +0.00003917 % and power by +0.00042179 %. These differences
prove no cooling or efficiency gain. Steady iterations represent neither
physical time, rotor frequency nor independent statistical realizations.

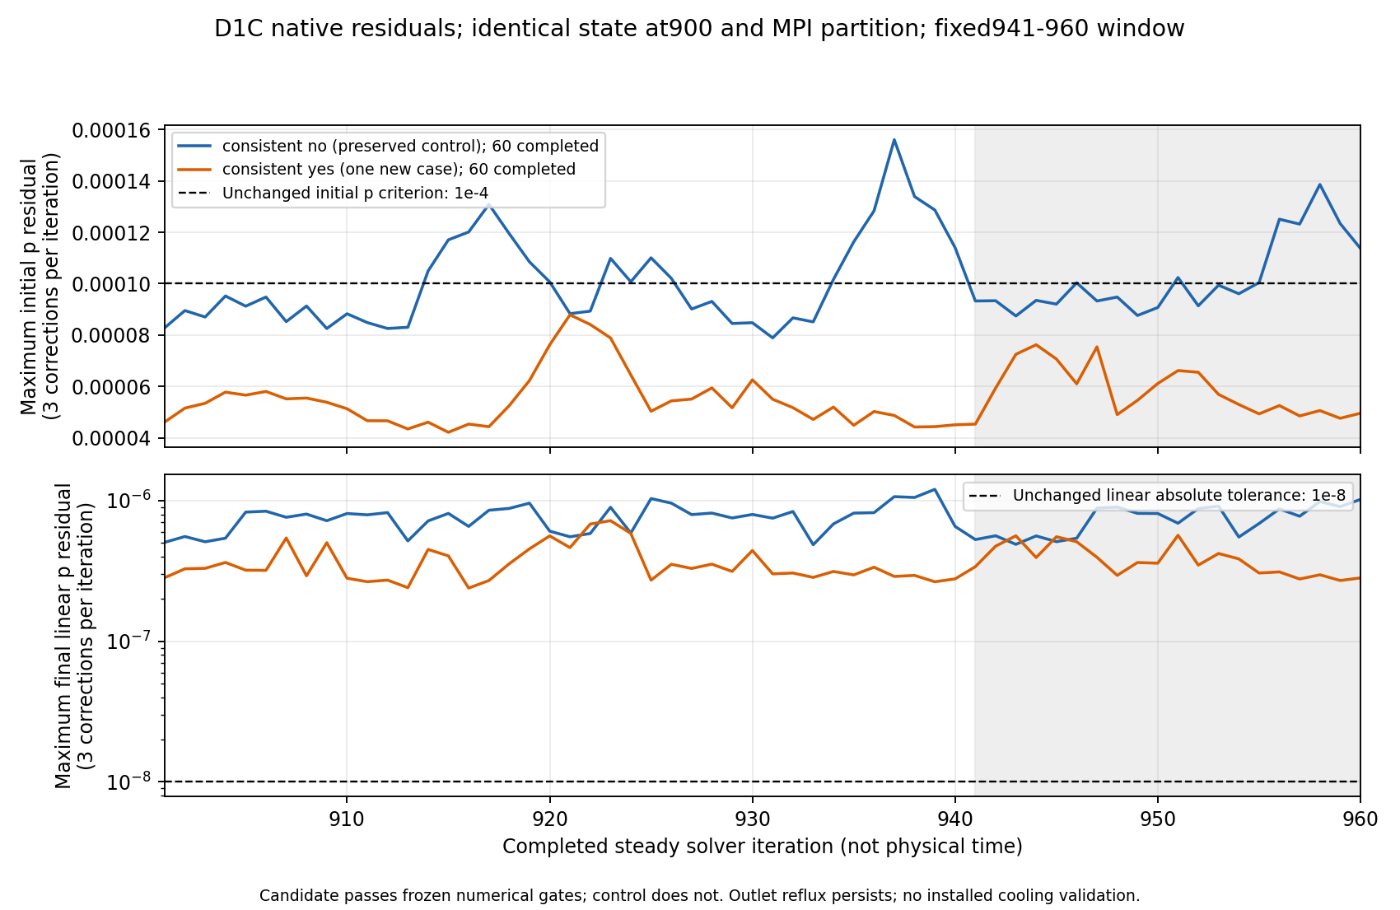
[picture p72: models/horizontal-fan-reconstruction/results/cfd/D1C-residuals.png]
Native D1C/control residuals, final window fixed before calculation


## Backflow and local fields: explicit limits

At 960, gross backflow remains **0.123990213 m³/s**, or **10.76024 %** of net
flow. It concerns the same 1 572 faces out of 4 542 and **35.15382 %** of outlet
area, practically as in the control. Residual improvement did not resolve the
possible influence of this nearby outlet or provide measured engine resistance.

Field comparison at 960 gives a volume-weighted p RMS difference of
0.544038 Pa but a local maximum of **317.669 Pa**; ΔU RMS is 0.0624630 m/s.
Stable integrated flow/torque therefore does not guarantee local-field
insensitivity. These differences are neither cellular algebraic residuals
nor experimental uncertainty. Mesh independence, wall layers and installed
interfaces/conditions remain unqualified.

Maximum absolute Mach remains 0.3766 under screening assumptions:
compressible sensitivity is still required. Flux-weighted outlet total
pressure is 1569.57 Pa. The port-energy/power ratio 0.7444 is not qualified
efficiency. Pressure torque is recovered with relative error 4.68×10⁻¹² and
wall velocity Ω×r at 7.05×10⁻⁹ m/s; these identities verify output reading,
not physical validation.

## Budget and closure

Current preflight: Kali2 amd64, 12 logical CPU, 11 353 784 320 available memory
bytes, no active flow container. Actual limits are 4 CPU, cpuset 0/2/4/5,
5 GiB RAM and memory+swap, no networking, UID/GID 1000, dropped capabilities
and read-only sources/baseline/capsule. Pre-existing services remain identical.

Solver 117.18 s, reconstruction 4.97 s, native audit 2.63 s; including
preparation, archiving and verification, **128.169 s total**, below the overall
300 s ceiling. The owned container was released at **18:25:36 UTC on
October 4, 2026**. No second branch, additional phase, restart or extension.

The private archive of final fields, logs, systems and receipts contains
25 verified members, 47 464 242 bytes, SHA-256
`916c4b4e2a23c22e112763f58a9592896ee28e8f7e05ae8cb608e73c776fbfad`.
The three native tables are preserved and retrieved separately: their hashes
match the original native summary included in the archive. Transfer and every
member are verified. Scan, complete fields and tables remain private;
published reports are sanitized.

The [used configurations](parameters/D1C-executed-configurations/) and
[capsule manifest](parameters/D1C-executed-capsule-manifest.json) are preserved.
Frozen protocols' `not_launched` indicators describe their preparation before
launch; they do not replace the execution receipt. The
[prospective protocol](parameters/D1-coupling-proposed-protocol.json) remains
preserved without rewriting after the result became known.

Reproduce the package and analyses from private native inputs:

~~~sh
python source/prepare_d1c_capsule.py . work/D1C-capsule
python source/analyze_d1c_result.py PRIVATE_D1C_INPUTS . work/D1C-result.json
OPENBLAS_NUM_THREADS=1 OMP_NUM_THREADS=1 python source/compare_d1c_native_fields.py PRIVATE_D1_CONTROL_FIELDS PRIVATE_D1C_INPUTS work/D1C-field-differences.json
OPENBLAS_NUM_THREADS=1 OMP_NUM_THREADS=1 python source/analyze_flow_balance.py PRIVATE_D1C_CASE work/D1C-port-analysis.json --time 960
python source/verify_study.py
~~~

These commands launch no solver. Reproducing the calculation with
`launch_d1c.py` requires a new coordinated window and private 900/partition
sources; it is not launched automatically.

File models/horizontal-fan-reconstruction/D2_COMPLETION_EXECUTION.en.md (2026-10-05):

# D2 completed at 1020: comparison still inconclusive

The single authorized restart completed **1001–1020** from the verified native
1000 checkpoint, without rerunning the control. The extended branch therefore
totals **40 + 20 complete iterations**; the control retains its original
60 iterations. Geometry, partitions, MRF, boundary conditions, numerics and
criteria remain unchanged. **Pressure still fails numerical and steadiness
criteria.** The batch is closed, resources released, with no 1040 continuation.

[Back to study](README.en.md) · [Home](../../README.md) ·
[Initial D2 batch, preserved evidence](D2_EXECUTION.en.md) ·
[1000→1020 preparation and protocol](D2_COMPLETION_PREPARATION.en.md)

## Execution and resources

The [native preflight](results/runtime/D2-supervisor-native-input-verification.json)
checks 96 files in the prepared copy, 16 capsule files, 12 reused native inputs
and common selections. A first supervisor entry stopped before container
creation: the Python import had added a cache to the verified capsule. The
final capsule and `python3 -B` start correct this point; no solver had launched.
The initial transfer containing auxiliary macOS files was also rejected before
launch. These preparations modify no CFD state.

The [execution receipt](results/runtime/D2-completion-execution-receipt.json)
contains exactly three commands, all completed with exit code 0:

| Native command | Measured time | Phase ceiling |
|---|---:|---:|
| One `foamRun -parallel`, four ranks, 1001–1020 | 67.007 s | 110 s |
| `reconstructPar -time 1000,1020` | 12.875 s | 25 s |
| Final check and analysis of both windows/domains | 16.724 s | 30 s |

The [supervisor](source/launch_d2_completion.py) and
[single-branch runner](source/run_d2_completion.py) use one monotonic deadline
for admission, copy, solver, reconstruction, analysis, archiving and release.
**Actually measured overall time: 110.505 s under 240 s**,
[sanitized native evidence](results/runtime/D2-completion-launcher-receipt-sanitized.json).
Actual CPU capped at 4, a cpuset of four distinct physical cores,
**5 GiB** RAM+swap, no networking, and read-only sources/preparation/control/selections.
Admission: 11 294 654 464 available bytes, 12 logical CPU, load 1.369.
Peak child RSS 460 348 KiB: this value is not an aggregate measurement.

The container was released on October 4, 2026 at **21:26:53 UTC**.
The [independent confirmation at 21:31:28 UTC](results/runtime/D2-completion-release-confirmation.json)
observes its absence and unchanged pre-existing services. No third-party
service was stopped, persistent access added, installation, rental or spending
performed. No Mac/Kali2 reservation is maintained.

## Checkpoint and window validation

The [native 1020 certificate](results/runtime/D2-completion-native1020-verification.json)
verifies 32 files: `p/U/k/omega/nut/phi/Uf` and `uniform/time` on four ranks,
correct cardinalities, finite values and consistent 1020 indices/times.
Reconstructed serial fields each cover 680 596 cells. The log contains exactly
twenty complete steps 1001–1020 and `End`; every final table has the twenty
required consecutive measurements. The window is no longer missing.

The [final native summary](results/cfd/D2-extended1020-flow-summary.json) remains
**unadmitted**:

| Original criterion over 1001–1020 | Measurement | Limit | State |
|---|---:|---:|---|
| Maximum initial p residual | 0.0106874 | 0.0001 | Reject |
| Maximum initial residual of a U component | 0.00184464 | 0.00001 | Reject |
| Maximum initial k residual | 0.00443590 | 0.0001 | Reject |
| Maximum initial ω residual | 0.000003672 | 0.0001 | Pass |
| Maximum flow imbalance | 0.0000340581 | 0.005 | Pass |
| Boundary-flow CV | 0.00115817 | 0.01 | Pass |
| Torque CV | 0.00115130 | 0.02 | Pass |

Finite fields, finite measurements and the declared flow direction pass.
The reused control retains its ten original criteria and seven admitted
additional checks. The extended branch still fails four of the seven
steadiness checks:

| Additional check | Measurement | Limit |
|---|---:|---:|
| Common-pressure standard deviation, 1001–1020 window | **6.1701 Pa** | 2 Pa |
| Pressure-mean difference, 981–1000 / 1001–1020 | **15.5991 Pa** | 2 Pa |
| Core volumetric pressure RMS, 1000→1020 | **10.3471 Pa** | 1 Pa |
| Core volumetric velocity RMS, 1000→1020 | **0.381724 m/s** | 0.1 m/s |

P99/max of local core variations: 30.170 / 195.111 Pa and 1.337 / 60.557 m/s.
Fixed-zone variations and local differences between domains appear in the
[complete analysis](results/cfd/D2-completed-pair-analysis.json).
These indicators remain variations of steady SIMPLE iterations, without
physical time; they do not demonstrate an actual engine oscillation.

## Descriptive comparison, without admission

Over twenty native measurements 1001–1020:

| Common observable | Reused control | Completed extension |
|---|---:|---:|
| Oriented flow at common plane | 1.152300435 m³/s | 1.153996582 m³/s |
| Band-mean static pressure | 85.647426 Pa | 82.145799 Pa |
| Fluid torque on rotor | −3.867106500 N·m | −3.822585586 N·m |
| Rotor mechanical power, assumed 6000 rpm | 2429.7747 W | 2401.8014 W |

Symmetric differences: flow 0.14698 %, torque/power 1.15127 %, pressure
3.501627 Pa against a descriptive 5 Pa band. **All four descriptive bands
pass, but their numerical and steadiness prerequisites fail.** Status remains
`inconclusive_domain_comparison`; no steady physical domain sensitivity,
general independence or airflow improvement is established. Band pressure is
not a pressure rise between ports.

At 1020, gross backflow: control 0.123976 m³/s; extension at the common plane
0.107130 m³/s; extension at the distant boundary 0.125093 m³/s. Backflow persists
at the moved boundary. Core-field RMS differences between domains are
38.6723 Pa and 1.49356 m/s; these unadmitted snapshots do not qualify a steady
domain effect. Final maximum local velocity is 128.760 m/s, or estimated Mach
0.3754 with 343 m/s: this incompressible MRF model does not qualify compressibility.

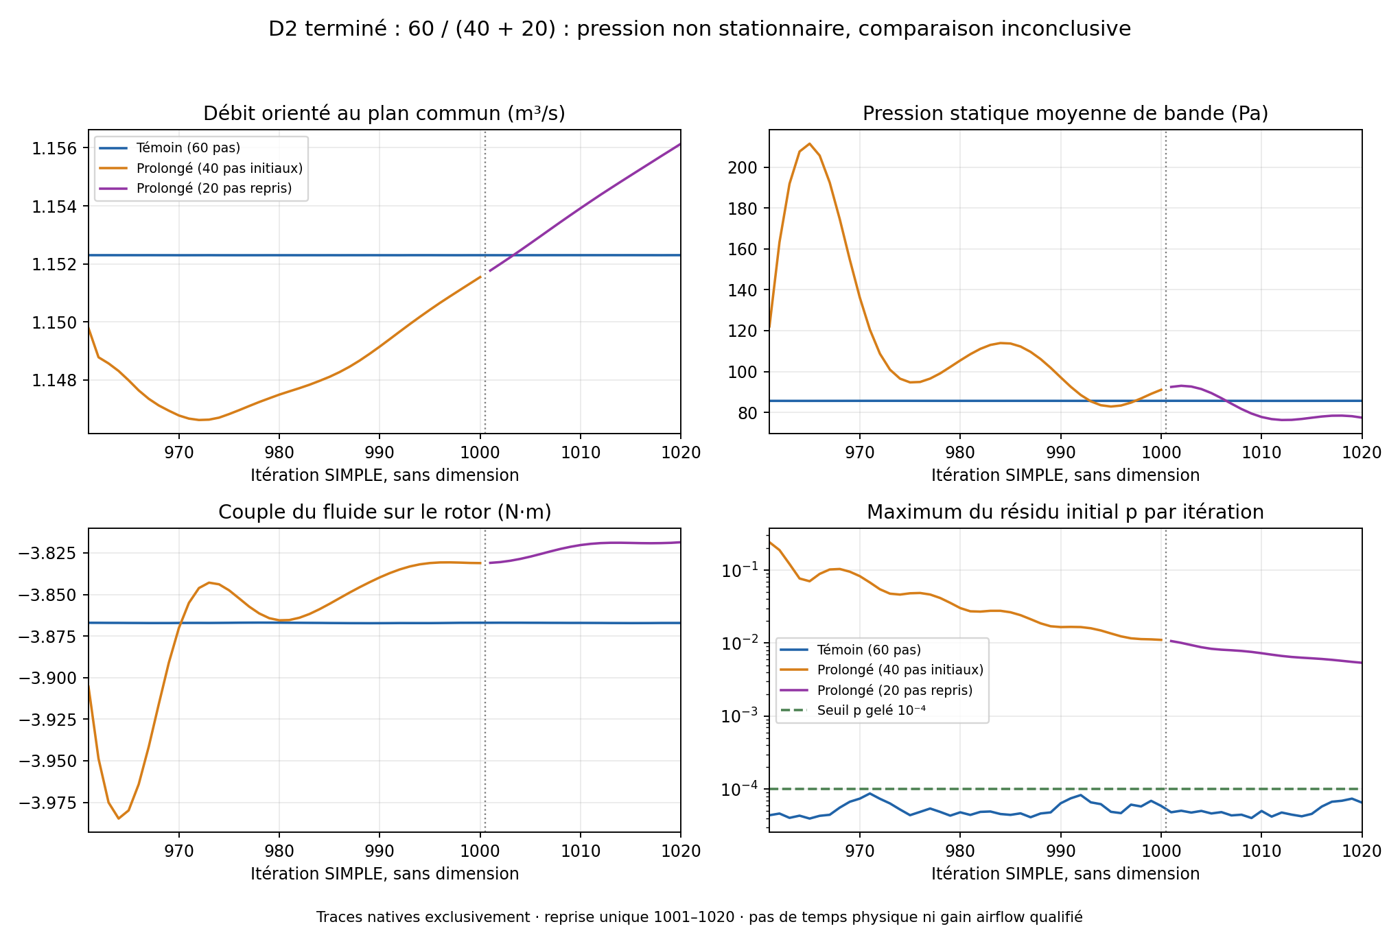
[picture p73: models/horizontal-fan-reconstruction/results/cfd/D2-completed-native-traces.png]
Native D2 traces, separate 20-step restart


[Render provenance](results/cfd/D2-completed-native-traces.json): only
measurements and residuals from the control's 60 steps, initial extension's
40 steps and 20 restarted steps. No extrapolation or invented image.
The 1000/1001 separation is visible and axes carry units.

## Preservation and reproduction

The [transferred and verified private archive](results/runtime/D2-completion-native-archive-verification.json)
contains **181 files**, 352 214 760 compressed bytes, SHA256
`5b2591992c93d92781f871fb6f69a86befb991938ae9807d0af83ecad67c3c6f`.
Every member is verified natively and after transfer. Native partition fields
1000 and 1020, meshes, separate logs, tables and the exact capsule are retained;
raw scan is not included. No raw native field, mesh or table is published in
the repository.

The [composed analysis](results/cfd/D2-completion-comparison-provenance.json)
explicitly declares 40 + 20 steps. Original logs remain separate; the old
log's incomplete 1001 block is not a complete step. Only three derived table
views assemble native rows, checking the duplicated 1000 measurement and both
source SHAs. They are not presented as one native log. The control is reused
without a solver.

The [actually executed capsule](parameters/D2-completion-executed-capsule-manifest.json)
is retained with its exact sources and configurations. `make fan-program-check`
verifies identities, native evidence and qualification limits. Software tests
cover the single branch, 240 s/4 CPU/5 GiB limits, isolation before solver,
termination of only the owned container, timeout without restart, unqualified
partial archiving and startup without Python cache. One test explicitly refuses
promotion when descriptive bands pass but pressure remains unsteady.

**Final 1020 stop respected.** 935/993 identity, scan units, installed dimensions
and interfaces, compressible model, walls, materials, fatigue, qualified LPBF
process simulation and validated NVIDIA physical twin remain open under the
other documented stages. No present result authorizes manufacturing or service.

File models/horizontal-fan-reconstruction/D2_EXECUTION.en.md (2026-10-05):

# D2: extended outlet, closed batch and inconclusive comparison

**Control completed; extended outlet partial; resources released.** The
[prepared protocol](OUTLET_SENSITIVITY_PREPARATION.en.md) was retained: same V2
rotor, `SIMPLE.consistent yes`, 275 mm extension towards −Z, 50 uniform 5.5 mm
layers, no distance or iteration increase after observing results. The
[audited comparison](results/cfd/D2-partial-pair-analysis.json) rejects steady
admission of the pair. No airflow gain, domain independence, qualified local
field or installed validation is established.

## What actually ran

Five preliminary geometry tests pass: core connectivity/volumes, added prism
volume, flux, orientation, written zones and field mappings. Native vector
table checks and partial-window rejection then bring the suite to seven tests,
explicitly rejecting partial admission or missing fields.

The [mesher](source/append_outlet_prisms.py) adds 227100 prisms: 680596 cells
against 453496. Rotor, its faces, core points and IDs, neighbours and MRF
membership are retained. Added volume is 0.016591727271 m³, equal to outlet
area × length; minimum added volume is 4.37078e−8 m³. Maximum core volume
difference is 6.35275e−22 m³. [Preparation evidence](results/cfd/D2-mesh-preparation.json)
links mesh, initial field and private selection hashes.

**Both meshes pass independent standard and extended checks, zero failures,
unchanged thresholds**: [control](results/cfd/D2-current-independent-mesh-gate.json)
and [extended](results/cfd/D2-extended-independent-mesh-gate.json).
[Observables at 960](results/cfd/D2-seed-observables-verification.json), calculated
without another iteration, reproduce the three zone pressures and original
oriented flow to output precision. The functionObjects fragment syntax was
corrected before launch: Foundation13 uses `faceZone` and `cellZone`, rather
than `regionType/name`.

A first preparation stopped **before any CFD iteration**: manual decomposition
`dataFile` required a quoted string. This [first attempt](results/runtime/D2-first-execution-receipt.json),
its capsule and archive are retained. Syntax correction and the `faceZoneList`
header were frozen in a second capsule. The original timer was not reset.
Manual assignment follows [Foundation13 code](https://raw.githubusercontent.com/OpenFOAM/OpenFOAM-13/master/src/parallel/decompose/decompositionMethods/manual/manual.C).

Original core partition across four ranks is verified exactly in both cases.
Columns belong to the owner rank of their former outlet face.
[Extended counts](results/cfd/D2-extended-partition-verification.json) are
122709 / 167115 / 208232 / 182540 cells: preserving ownership induces imbalance
without redistributing the core.

The [runner](source/run_d2_in_container.py) then executes two sequential
branches from the same private `consistent yes/960` state:

| Case | Complete iterations | Native tables including state 960 | Final state |
|---|---:|---:|---|
| Current outlet | 60, 961–1020 | 61 rows per table | `End`, complete fields, reconstruction 980/1000/1020 |
| Extended outlet | 40, 961–1000 | 41 rows per table | 1001 started then interrupted; no `End` or field 1020 |

The control uses 118.731 s solver time. The extended branch actually has
**159 s** until the closure reserve of the original deadline; it stops cleanly
with timeout code 124 after 160.030 s including signaling/stopping. The 300 s
limit was a maximum subordinate to the global timer. No missing iteration is
extrapolated or added.

## Steadiness criteria and common differences

The [control1020 summary](results/cfd/D2-current1020-flow-summary.json) passes
**ten original criteria**; window 1001–1020 contains twenty consecutive
measurements. Its **seven additional checks** also pass: flow and band pressure,
window differences, field RMS from 1000→1020. Volume-weighted Δp RMS is
0.28765 Pa, ΔU 0.04178 m/s. Local maxima nevertheless reach 122.284 Pa and
48.196 m/s: passing global criteria still does not qualify local fields.

The extended branch entirely lacks the required 1001–1020 window and final
fields. At 981–1000 its maximum initial p residual is **0.0277275** against
0.0001; U reaches 0.00409826 against 0.00001, k 0.00797796 against 0.0001.
Band pressure standard deviation is **11.795 Pa** against 2 Pa, and its mean
changes from 138.957 to 97.745 Pa between available windows. It remains
numerically unadmitted and unsteady under planned checks. Residuals normalized
on different domains do not measure a physical domain effect.

The only paired twenty-measurement comparison available, **981–1000**, is
**descriptive**:

| Quantity in the common region | Current outlet | Extended outlet | Difference |
|---|---:|---:|---:|
| Mean oriented flow [m³/s] | 1.152299531 | 1.149390387 | −0.25246% symmetric relative |
| Mean fluid torque on rotor [N·m] | −3.867153957 | −3.842874987 | 0.62783% in absolute magnitude |
| Volume-weighted mean static pressure [Pa] | 85.644954 | 97.744930 | +12.099976 Pa |

Power follows the same relative change as torque at fixed speed. Pressure is
from the **same 5825 cells**, not a port pressure rise. Its difference exceeds
the 5 Pa screening band, but pair steadiness prerequisites fail. Domain
comparison gates **are therefore not evaluated as an admission**.

Actual saved fields at 1000 show common Δp RMS 38.337 Pa, ΔU 1.284 m/s and
maximum Δp 514.162 Pa. These describe an unconverged iterative state, not a
qualified steady outlet effect or experimental uncertainty.

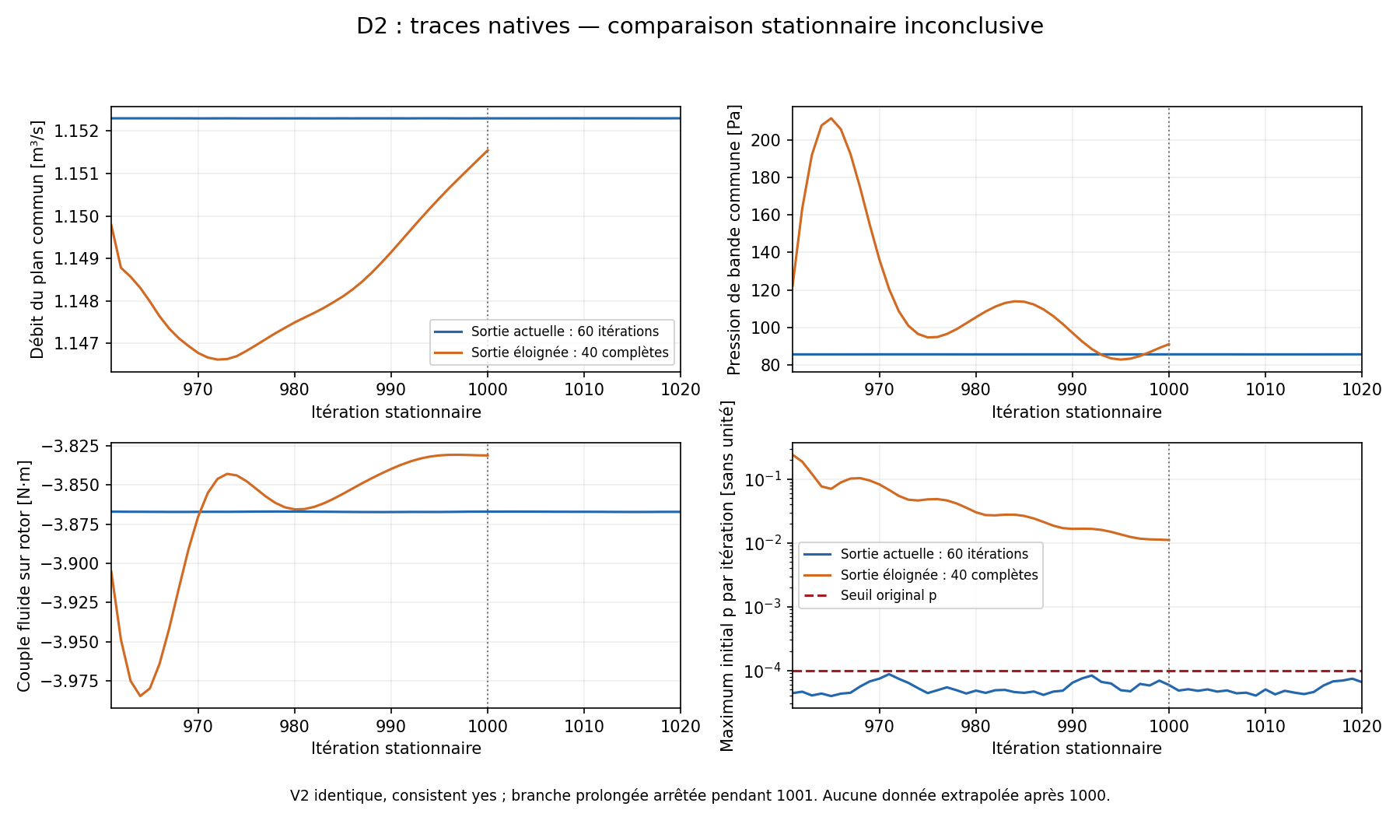
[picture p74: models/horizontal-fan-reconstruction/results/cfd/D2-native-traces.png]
Native traces: control60 and extended40


The [script](source/plot_d2_native_trace.py) and
[provenance hashes](results/cfd/D2-native-traces.json) retain every actually
complete point. The axis shows steady solver iterations without a physical
frequency or duration; no extended curve continues after 1000.

## Actual backflow retained at 1000

Extended MPI1000 fields are read by global IDs without another solver or
`reconstructPar`. Five fields cover 680596 cells exactly once. The 4542 common
plane faces are covered once and their phi reproduces the native functionObject
sum.

| Location in saved state 1000 | Net flow [m³/s] | Gross backflow [m³/s] | Backflow / net |
|---|---:|---:|---:|
| Control, current outlet plane | 1.152299642 | 0.123988412 | 10.7601% |
| Extended, same plane now internal | 1.151545816 | 0.104273570 | 9.0551% |
| Extended, distant boundary | 1.151530127 | 0.129404559 | 11.2376% |

Moving the outlet has not eliminated backflow in the available state. This one
partial extension proves neither sufficient distance nor domain independence.
The constant-section buffer with `slip` sides retains confinement and mixing;
it is not a measured engine plenum.

## Closure, preservation and reproduction

Verified limits: **4 CPU, RAM + swap 5 GiB, no network, private sources read
only**. [Native global time](results/runtime/D2-native-archive-verification.json)
is **627.669 s**, including first preparation, correction under the original
timer, restarts, stopping, audit and archiving, below 720 s. The container is
released at **20:09:21 UTC**; [existing services are unchanged](results/runtime/D2-release-confirmation.json).
No additional calculation, installation, persistent access or service change.

Final private archive: 99 verified members, 189782229 bytes; the first attempt
archive was also transferred and verified. Complete tables, meshes and fields
remain private. The launcher excludes `processor*` replicas from its archive;
extended fields1000 and mappings were therefore recovered **separately after
release** as file preservation without another native phase. The
[supplementary certificate](results/runtime/D2-partial1000-preservation-verification.json)
covers 44 verified private files. Their assembly by IDs supports diagnosis1000;
it does not reconstruct missing checkpoint1020.

[Exact capsules](parameters/D2-executed-capsule-manifest.json) and
[first preparation](parameters/D2-first-preparation-capsule-manifest.json) retain
frozen configurations and sources. Complete pair analysis was never reached.
Native force vector table reading was subsequently corrected and tested in the
current helper without modifying the executed capsule. Partial-batch analysis
uses [a separate script](source/analyze_d2_partial_result.py).

Verification without a solver: `make fan-program-check`. Reproduce statistics
and figures using the same scripts with extracted private native archives.
The launcher requires explicit coordination and must not rerun against its
expired original deadline. **This report neither authorizes nor starts a
continuation.** Any new study requires a budget and protocol defined before
calculation. 935/993 identity, installed interfaces, compressibility, walls,
fatigue and physical validation remain open.

Follow-up: native checkpoints980 and1000 are now audited and a
[fixed twenty-step completion](D2_COMPLETION_PREPARATION.en.md) is prepared. That
preparation launched no solver and does not change this closed batch's results.

Later follow-up: after explicit agreement, the
[single1001–1020 restart completed](D2_COMPLETION_EXECUTION.en.md) in110.505 s
including archiving and release. The missing window now exists, but pressure
remains unadmitted and comparison remains inconclusive. Partial results and the
first batch capsule remain preserved.

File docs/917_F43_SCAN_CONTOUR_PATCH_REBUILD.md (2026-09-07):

# F43 — reconstruction B-Rep locale par contours de scan

## Décision de géométrie

La lignée F39/F42 basée sur une enveloppe elliptique est visuellement obsolète
et interdite pour la suite. F43 reconstruit le corps et les ailettes à partir de
44 coupes irrégulières du stock F36 scan-conforme. Les seuls opérateurs de
construction de l'enveloppe sont des points, segments, fils fermés et un loft
réglé OCCT. Aucun disque, ellipse, cylindre ou parallélépipède global ne définit
la silhouette.

L'origine cyclique des points est alignée entre deux coupes voisines sans
modifier leurs coordonnées. Les diagnostics de maillage ont isolé trois
transitions pathologiques : `z=41,25`, `z=70,25` et `z=75,75` unités de scan.
Ces trois profils sont omis du loft. Le profil supérieur `z=82` conserve sa cote
mais reprend la forme XY du voisin `z=79,5`. Il s'agit de réparations locales et
traçables, pas d'une déformation globale de la peau.

## Provenance et unités

Le seul scan de culasse disponible est la référence publique 935; le scan 917
local représente le carter moteur avec cylindres et ne fournit pas une culasse
isolée exploitable. La géométrie F43 reste donc une référence de forme
scan-conforme, **pas une définition de montage Porsche 917**. Les unités OBJ
sont conservées comme convention numérique. L'échelle absolue, les datums, les
filetages et les interfaces OEM ne sont pas certifiés.

Le scan brut, les profils, le STEP et tous les maillages dérivés restent hors du
dépôt. Le rapport public contient uniquement leurs empreintes, volumes,
surfaces, compteurs et quantiles.

## Contrôles exécutés

Le STEP privé F43 a été réimporté par OCCT et contrôlé avec BRepCheck exact,
BOPAlgo et le contrôle des p-courbes : un solide, une coque, aucune arête libre,
non-manifold ou dégénérée, et aucun défaut BOP/p-courbe. Gmsh 4.15.2 termine le
maillage 2D et 3D du même STEP.

Le meilleur maillage Delaunay raffiné contient 654 729 tétraèdres : aucun
élément n'a un `minSICN <= 0`, mais 378 ont un `minSICN < 0,1`. La majorité est
concentrée dans les bandes de transition `z=40–44` et `z=50–54`. Les essais
Netgen n'améliorent pas le maillage de base; `Relocate3D` l'améliore légèrement;
`UntangleMeshGeometry` le dégrade et est rejeté. La suite défendable est une
partition locale ou des couches/prismes dédiés, sans modifier les autres
contours.

La comparaison unidirectionnelle stock→F43 donne une déviation latérale P95 de
3,207 unités de scan pour un seuil documentaire de 2,0 : échec. L'ajustement des
contours eux-mêmes donne P95 1,027 pour un seuil de 1,5 : réussite. Ces valeurs
ne sont pas une preuve métrologique ou de fitment.

## Verdict

F43 est retenu seulement comme **baseline B-Rep externe non ovale**. Il manque
la chambre, les quatre conduits, les quatre sièges/guides, la bougie, les
galeries d'huile, les interfaces, les jeux et une coque d'épaisseur démontrée.
L'épaisseur minimale de 1,5 mm et l'absence de cavité piégée ne peuvent pas être
validées sur ce volume externe plein. Aucun calcul thermique, structurel,
fatigue ou impression virtuelle ne peut autoriser cette pièce à ce stade.

Le rapport et les images sont dans
`twins/reference-917-engine/evidence/f43-scan-contour-patch/`.

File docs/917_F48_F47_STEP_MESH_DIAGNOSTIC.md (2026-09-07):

# F48 — diagnostic du maillage des STEP internes F47

## Conclusion

Les deux STEP de culasse F47 sont **refusés pour le maillage volumique**. Le
défaut est localisé aux p-curves des arêtes du noyau gaz, puis amplifié par la
soustraction booléenne dans la tête. Il ne provient ni du noyau d'huile, ni
d'une intersection gaz/huile démontrée, ni d'une géométrie extérieure de
remplacement.

F48 est un diagnostic. Il ne produit aucune CAO réparée, aucun maillage de
calcul et aucune preuve CFD, CHT, structure ou impression 3D.

## Résultats mesurés

| variante | solide | `BRepCheck` exact | défauts `InvalidCurveOnSurface` | faces/arêtes fautives | Gmsh 3D |
|---|---|---:|---:|---:|---|
| 2V | noyau gaz | passe | 4 | 3 / 4 | non tenté isolément |
| 2V | noyau huile | passe | 0 | 0 / 0 | non nécessaire au diagnostic causal |
| 2V | tête après soustraction | passe | 8 | 5 / 8 | échec `segment/facette` |
| 4V | noyau gaz | passe | 22 | 10 / 18 | non tenté isolément |
| 4V | noyau huile | passe | 0 | 0 / 0 | non nécessaire au diagnostic causal |
| 4V | tête après soustraction | passe | 32 | 17 / 28 | échec `facette/facette` |

Le point important est que `BRepCheck=True` n'est pas une preuve de préparation
CAE : `BOPAlgo_ArgumentAnalyzer` détecte les incohérences courbe 3D / courbe 2D
sur surface, et Gmsh les transforme ensuite en intersections de contraintes
PLC pendant la tétraédrisation.

Les 93 références d'entités fautives (faces et arêtes, avant et après
soustraction) sont suivies dans le
[`diagnostic-report.json`](../twins/reference-917-engine/evidence/f48-mesh-diagnostic/diagnostic-report.json)
par des identifiants opaques déterministes. Les indices OCCT et les boîtes de
localisation exactes restent dans un rapport local de 34 895 octets, lié par le
SHA-256 `0fdaa6491d4c4c16190856e1858ed76d5ef0609eabab0ee9322176d2d3841ed8`.
Ni ces coordonnées ni les STEP privés ne sont copiés dans Git.

## Cause et limite de l'attribution

Les faits bornent la cause au noyau gaz : 4 puis 22 défauts avant soustraction,
zéro pour l'huile, 8 puis 32 dans les têtes. La construction F47 fusionne une
chambre circulaire, des cylindres circulaires coaxiaux de siège, gorge et guide,
et des cylindres circulaires inclinés pour les conduits. Les arêtes rognées de
ces jonctions sont donc la famille causale la plus probable.

Cette attribution au type de jonction a une confiance moyenne faute d'historique
de nommage OCCT persistant à travers STEP. Les familles de défauts, les solides
et les entités sont en revanche localisés exactement dans le rapport privé.

## Correction chirurgicale proposée

1. Reprojeter uniquement les p-curves des couples arête/face fautifs du noyau
   gaz à partir des courbes 3D et surfaces support existantes.
2. Exiger zéro défaut `InvalidCurveOnSurface` avant export et après un aller-
   retour STEP. Si cela échoue, reconstruire seulement les jonctions internes
   concernées avec recouvrement explicite et partition OCC avant fusion.
3. Soustraire le noyau gaz accepté et le noyau huile inchangé du même fichier
   extérieur F43 verrouillé par SHA-256.
4. Comparer les signatures géométriques des faces extérieures hors ouvertures,
   imposer une distance de peau nulle, puis relancer Gmsh sur trois tailles de
   maille.

Une couture ou réparation globale de la tête est interdite : elle pourrait
déplacer la peau issue du scan. Aucun proxy, aucune ellipse et aucun ovale ne
peut remplacer la géométrie F43.

## Portes fermées

La réparation locale n'a pas encore été exécutée. Les portes BOP zéro défaut,
maillage 2V/4V, convergence, verrou de peau après réparation, CFD/CHT/FEA,
impression métal et démarrage moteur restent donc toutes fermées.

## Reproduction de la publication publique

Le script de diagnostic public charge les STEP uniquement quand l'opérateur lui
fournit explicitement un répertoire privé. Il refuse d'écrire son rapport à
indices et coordonnées dans le dépôt. Ses deux modes séparent les dépendances
OCCT et Gmsh. Le script de publication reconstruit et vérifie uniquement le
rapport expurgé et son manifeste.

```bash
# Dans l'image OCCT; chemins privés fournis par l'opérateur
python3 twins/reference-917-engine/source/diagnose_private_f47_step_mesh_f48.py \
  --mode occt --private-root /CHEMIN/PRIVE \
  --private-output /SORTIE/HORS/DEPOT/f48-occt.json --project-root .

# Dans l'image Gmsh; même règle de confinement
python3 twins/reference-917-engine/source/diagnose_private_f47_step_mesh_f48.py \
  --mode gmsh --private-root /CHEMIN/PRIVE \
  --private-output /SORTIE/HORS/DEPOT/f48-gmsh.json --project-root .

python3 twins/reference-917-engine/source/publish_mesh_diagnostic_f48.py \
  --project-root .
python3 twins/reference-917-engine/source/publish_mesh_diagnostic_f48.py \
  --project-root . --check
python3 tests/test_917_mesh_diagnostic_f48.py -v
```

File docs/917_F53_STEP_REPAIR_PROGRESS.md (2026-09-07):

# F53 — diagnostic de sérialisation STEP

Deux exports du maître natif 2V F50 ont été réellement exécutés sur Kali le
6 septembre 2026, puis relus et contrôlés par OCCT. Le maître source est lié
au SHA-256 `1574eb58b7af09bcadab6c9cfcdd9a56940d479a5aa1b1eb807d31d41d4f7c36`.

| Export AP242 | Mode relu dans OCCT | Défauts CurveOnSurface après réimport |
|---|---:|---:|
| Courbes paramétriques conservées | 1 | 8 |
| Courbes paramétriques omises | 0 | 131 |

Le constructeur STEP est initialisé avant les réglages, leur succès est
contrôlé et le mode est relu avant export. Aucun changement de surface,
épaississement, réparation automatique ou augmentation de tolérance n'est
appliqué par ce diagnostic. Les rapports conservent les empreintes, le contrôle
BRepCheck, la topologie et les écarts de propriétés après réimport.

La voie « omettre les p-curves » est rejetée pour ce maître. La suite consiste
à localiser les huit raccords fautifs du contrôle, examiner leurs surfaces et
leurs courbes 3D, puis reconstruire localement les raccords responsables avant
un nouvel audit. Ces essais ne prouvent aucune réparation et ne libèrent
aucune pièce. Le maître 4V, les épaisseurs, le maillage, les fonctions d'usinage,
le procédé LPBF, le CHT, la distorsion et PhysicsNeMo restent à traiter dans le
programme demandé.

Le script reproductible est
`twins/reference-917-engine/source/probe_step_serialization_f53.py`.
Les deux fichiers STEP et rapports détaillés restent dans l'espace privé de
travail ; les maîtres F50 ne sont pas écrasés. Le code retour 2 de ces deux
essais représente un rejet numérique attendu, pas une exécution inachevée.

## Localisation et première correction

L'inspection de 1 001 paramètres par raccord trouve huit arêtes B-spline
sur cinq faces (quatre supports cylindriques et un support B-spline). Aucun
des huit couples n'est une couture périodique. Les deux écarts les plus élevés
échantillonnés valent `1,9849185e-5` et `7,0727442e-5` unité du scan.
Ces valeurs échantillonnées ne constituent pas une borne globale certifiée.

Une copie profonde du STEP de contrôle a ensuite reçu une correction
`FixSameParameter` uniquement sur les huit arêtes repérées. Le réglage demandé
est `1e-7`. Le diagnostic passe de huit à six défauts avant export et conserve
six défauts après réimport. Les tolérances des arêtes traitées n'augmentent pas.
BRepCheck reste valide ; l'écart relatif de volume est `-1,9732054e-11` et
l'écart maximal de boîte englobante `4,2632564e-14` unité du scan. Ces métriques
globales ne remplacent pas le contrôle spatial des surfaces et l'audit BOP
complet, encore requis. La copie corrigée n'est pas promue comme nouveau maître.

Le STEP candidat privé a l'empreinte
`52f637bc348c765b1e39476df8206d31f0d636527b34cf815f993a3d794889c5`.
Les scripts `inspect_step_faults_f53.py` et
`probe_step_same_parameter_f53.py` reproduisent ces opérations avec contrôle
de l'empreinte d'entrée et refus d'écraser les sorties existantes.

## Reprojection précise et contrôle des deux défauts persistants

Sur la copie à six défauts, la reprojection locale à `1e-7`, suivie de
SameParameter, réduit le résultat à **deux défauts avant et après export**.
Les maxima des tolérances de faces et d'arêtes après réimport valent `1e-7`.
BRepCheck reste valide. Le STEP privé obtenu est lié au SHA-256
`0ba32a920749a6ae9d4fde04ba2b04b470d5b9a555c68f0c3b06ba02e2bc31c1`.

L'inspection relancée confirme que les deux raccords restants sont les deux
supports cylindriques présentant les écarts `1,9849185e-5` et `7,0727442e-5`.
Une reconstruction expérimentale des courbes 3D à partir des p-curves sur une
nouvelle copie ne réduit pas ce nombre : deux défauts persistent après STEP.
Cette voie n'est donc pas retenue comme amélioration. Les déplacements
échantillonnés avant SameParameter sont inférieurs à `9,78e-8` unité du scan ;
ils ne prouvent pas une borne après l'ensemble des opérations.

La prochaine correction doit examiner le raccordement entre ces cylindres et
leurs faces voisines. Le seuil de tolérance n'a pas été élargi pour obtenir
une acceptation. Les défauts concernent toujours le candidat 2V ; aucune
acceptation STEP 2V ou 4V n'est revendiquée à ce stade.

## Supports voisins et projection directe

Le contrôle des faces voisines révèle deux intersections cylindre/cylindre.
Sur 101 paramètres par arête, la distance minimale de la courbe 3D à chacun
des quatre supports reste inférieure à `4,97e-8` unité du scan. Ce contrôle
échantillonné indique une incohérence de représentation paramétrique ; il ne
certifie pas l'intégralité des courbes.

Une projection directe `GeomProjLib.Curve2d`, sans refit SameParameter, réduit
les maxima échantillonnés après STEP à `4,1126721e-7` et `5,7000656e-7`, contre
`1,9849185e-5` et `7,0727442e-5` avant cette opération. Le nombre de défauts
reste deux. À la réimportation, OCCT porte les tolérances de ces arêtes à
`1,1897365e-7` et `1,4998458e-7`, insuffisantes pour les écarts observés.
Le rapport expose cette augmentation automatique ; elle n'est pas présentée
comme une réparation validée.

Les précisions de projection demandées `1e-9` puis `1e-12` donnent les mêmes
comptages et métriques globales. Réduire ce seul paramètre ne résout donc pas
les défauts. La suite devra contrôler la représentation 2D sur les intervalles
de nœuds des splines, puis reconstruire celle-ci avec un contrôle d'erreur
adaptatif avant le prochain round-trip.

## Reconstruction adaptative des deux courbes cylindriques 2V

`rebuild_cylinder_pcurves_f53.py` reconstruit uniquement les deux courbes
paramétriques fautives, sur leurs cylindres existants. Les angles sont dépliés
par rapport à la représentation précédente. L'interpolation conserve les
paramètres de la courbe 3D ; des sondes intermédiaires entraînent le raffinement.
Ni la silhouette extérieure ni les surfaces porteuses ne sont redessinées.

Le candidat `5a8e29c5e8c0e445a72fd8918fc25a4189e8d662978af14149d3cbd2a38d0653`
présente **zéro défaut de courbe paramétrique avant et après réimport STEP**.
Les deux reconstructions utilisent respectivement 232 et 560 points, avec des
maxima échantillonnés de `5,52e-8` et `7,30e-8` unité du scan. Ce ne sont pas
des bornes continues garanties.

BRepCheck passe sur 20 651 sous-formes ; la topologie contient un solide,
une coque, 5 034 faces, aucune arête libre, non-manifold ou dégénérée.
La variation relative de volume par rapport au STEP d'entrée est `-3,50e-10`,
la variation maximale des bornes `5,68e-14` unité du scan. Ces valeurs ne
certifient ni l'échelle physique ni les interfaces moteur.

Le contrôle complet BOP (intersections, petites arêtes, reconstruction des
faces, continuité, courbes sur surfaces) est lancé séparément avec
`audit_step_candidate_f53.py`. Le succès pcurve seul ne constitue pas une
acceptation globale du STEP, encore moins une autorisation de fabrication.
Les rapports complets et les géométries restent privés.

La version 4V est contrôlée séparément : son export témoin présente 32 défauts
de courbe paramétrique. Le résultat 2V ne lui est pas transféré par hypothèse.

### Résultat du contrôle complet 2V

Le contrôle BOP du même hash est terminé : `has_faulty=false`, zéro résultat,
aucune catégorie d'erreur signalée avec les cinq modes précités activés.
BRepCheck et les comptages topologiques sont également inchangés. La
réparation passe donc les contrôles OCCT exécutés sur le STEP 2V. Il reste à
quantifier la déviation de surface par rapport au maître et à reprendre le
maillage, les épaisseurs et les vérifications de procédé ; ce succès ne
remplace aucun de ces contrôles.

Pour la 4V, une reprojection locale suivie de SameParameter réduit les défauts
de 32 à 22, avec BRepCheck valide. Les supports restants sont inspectés avant
d'appliquer la reconstruction adaptative aux seuls cylindres admissibles.

Cette reconstruction corrige ensuite les 19 paires cylindriques : il reste
**3 défauts 4V**, avant et après STEP, sur les surfaces non cylindriques
laissées intactes. Le candidat est
`38344c77438c5406b1faa2ce0420507d234660f56aa91e0f78331fd03a148306`.
Il conserve un solide fermé, sans arête libre ni non-manifold, et BRepCheck
passe. Le mode partiel est explicite et sort avec le code 2 tant que des
défauts subsistent ; il ne transforme pas une réparation partielle en succès.

`make check` passe sur cette révision de travail. Cette suite contrôle le
logiciel et les contrats documentaires ; elle ne prouve pas la résistance,
le refroidissement ou la fabricabilité de la culasse. Les nouveaux outils
sont également exécutés sur les fichiers STEP privés sous OCP sur Kali.

### Suppression des derniers défauts paramétriques 4V

Une projection directe à `1e-9` réduit les trois défauts non cylindriques à
un seul. Pour ce dernier support BSpline, une projection ponctuelle suivie
d'interpolation adaptative (option explicite `--project-bspline`) utilise
35 points, deux itérations et un maximum échantillonné de `6,275e-8` unité
du scan. La surface porteuse et la courbe 3D ne sont pas reconstruites.

Le STEP `700baea66bc72cdb6aee529e21b167270ebde11db94b06f8e1e55ee08bdd9bf2`
présente zéro défaut pcurve avant/après réimport et BRepCheck valide : un
solide, une coque, 4 929 faces, aucune arête libre/non-manifold/dégénérée.
Le contrôle BOP complet de ce hash est lancé, mais son résultat n'est pas
encore acquis ici. Aucune autorisation de fabrication n'est accordée.

Le contrôle complet 4V est maintenant terminé : zéro résultat BOP,
`has_faulty=false`, BRepCheck valide. Les deux candidats STEP passent les
contrôles d'intégrité OCCT exécutés. La comparaison de peau échantillonnée,
le maillage exploitable et les validations fonctionnelles restent séparés.

## Maillage et localisation des faibles épaisseurs

Sur le maillage volumique F50 4V, l'optimisation Gmsh par défaut, Relocate3D,
puis par défaut (5 itérations demandées par appel) réduit les tétraèdres de
`minSICN < 0,1` de **1 086 à 1 048**. Tous les nœuds classés sur la frontière
(dimensions 0, 1, 2) conservent exactement leurs coordonnées. Aucun élément
inversé n'est détecté, mais le minimum `minSICN=2,48e-5` reste insuffisant :
le candidat est refusé par le seuil strict. Cette expérience ne régénère pas
un maillage depuis le nouveau STEP et ne lui transfère aucune acceptation.

Sur le maillage initial, 936 des 1 086 tétraèdres insuffisants ont au moins
trois nœuds de frontière (310 en ont quatre). Ce constat motive une reprise
du maillage de surface et de ses subdivisions plutôt qu'un lissage volumique
répété sans effet suffisant.

Le contrôle privé `localize_thickness_f53.py` conserve les positions des
2 000 sondes et compare deux méthodes géométriques sur le même STL F50 4V :

- sphère inscrite : 194 sondes sous 1,5 unité du scan (9,70 %) ;
- rayon normal : 42 sondes sous ce seuil (2,10 %) ;
- 42 sondes signalées par les deux méthodes, 152 désaccords à examiner.

Ce ne sont pas deux simulations physiques indépendantes et les désaccords
ne permettent pas d'écarter les défauts. La valeur 1,5 reste en unités du
scan tant que l'échelle absolue n'est pas certifiée. La carte privée sert à
localiser la reprise CAO ; aucune paroi n'a encore été épaissie par cet outil.
Les scripts et rapports n'introduisent aucune nouvelle silhouette globale.

La même localisation sur le STL F50 2V reproduit 211 sondes faibles par
sphère inscrite (10,55 %), contre 35 par rayon normal (1,75 %), avec 35
accords et 176 désaccords. Les deux cartes restent conservées intégralement
dans les sorties privées : ni le seuil ni la méthode initiale ne sont
remplacés pour faire disparaître les signalements.

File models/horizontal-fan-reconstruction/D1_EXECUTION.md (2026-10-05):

# D1 exécuté et arrêté dans le budget initial

Le diagnostic a reçu une fenêtre Kali2 explicite après libération du pilote Ti.
Il ne produit pas une comparaison complète à 960 : le témoin termine, la branche
stricte est interrompue. Aucun résultat n'est admis et aucun solveur n'est relancé
après la limite. [Rapport natif](results/cfd/D1-bounded-result.json) ·
[Résidus réellement calculés](results/cfd/D1-residuals.png) ·
[Empreintes des entrées](results/cfd/D1-diagnostic-input-manifest.json).

## Exécution et mesures exactes

La première préparation s'arrête en 8,24 s avant tout solveur : la copie des
répertoires de processeurs déréférençait leurs liens `900/uniform`, créant quatre
fichiers supplémentaires dans une branche. La garde stricte de partition a
rejeté la différence. Le correctif conserve ces liens (`symlinks=True`) ; aucune
physique, condition, tolérance, maille, champ initial ou itération n'est ajoutée.
Le [code préparé initialement](source/run_d1_in_container_setup_v1.py) et son
[manifeste initial](parameters/D1-prepared-pair-manifest-setup-v1.json) restent
conservés. La partition corrigée est identique avant les deux solveurs.

La réparation, le diagnostic de préparation et les deux solveurs restent dans
la même limite initiale de dix minutes : l'enveloppe externe est recalculée à
202 s restantes, puis arrête le seul conteneur D1. Le ledger natif mesure
**590,318 s depuis le lancement initial**, sans dépassement de 600 s. La première
préparation avait calculé zéro itération d'écoulement.

| Branche | Itérations terminées | Mesures par table, état initial compris | Nouvelles mesures | Fenêtre finale 941–960 | Champs finaux960 | Statut |
| --- | ---: | ---: | ---: | --- | --- | --- |
| relTol 0,01 | 60, 901–960 | 61 | 60 | vingt mesures vérifiées | reconstruits, cinq champs complets de 453496 cellules | non admis : pression |
| relTol 0 | 29, 901–929 | 30 | 29 | absente | absents ; seul le restart 900 existe | incomplet, non évalué pour admission |

L'itération 930 est entrée mais ne termine que deux corrections p sur trois ;
elle n'a ni mesure de débit/couple complète ni `ExecutionTime`. Elle est exclue
des statistiques et du rendu. Les seuils originaux restent inchangés. Le
[témoin à 960](results/cfd/D1-control-960-flow-summary.json) passe les critères U,
turbulence, masse, stabilité, direction et champs finis, mais son résidu initial
p maximal des vingt dernières itérations est 1,38616×10⁻⁴ contre 10⁻⁴. Débit moyen
1,15229935 m³/s, puissance 2429,758 W ; ces valeurs ne constituent pas une
performance admise.

## Différence de convergence sur la fenêtre prospective commune

Seule la première fenêtre prévue 901–920 dispose de vingt mesures complètes
pour les deux branches. La fenêtre 921–940 stricte est incomplète ; la fenêtre
941–960 stricte est absente. Elles ne sont pas remplacées par une fenêtre
choisie après le calcul.

| Mesure 901–920 | relTol 0,01 | relTol 0 |
| --- | ---: | ---: |
| Résidu initial p maximal | 1,30859×10⁻⁴ | 1,31086×10⁻⁴ |
| Résidu final linéaire p maximal | 9,60328×10⁻⁷ | 9,90354×10⁻⁹ |
| Itérations linéaires p moyennes, somme des trois corrections | 11,20 | 29,95 |
| Débit moyen, m³/s | 1,152299245 | 1,152299252 |
| Puissance moyenne, W | 2429,7772 | 2429,7775 |

Le résidu final linéaire diminue d'un facteur 96,97 et le coût en itérations
linéaires augmente d'un facteur 2,674. Le maximum du résidu initial varie de
seulement +0,174 % et reste au-dessus du seuil. Les courbes initiales se
superposent presque sur les vingt-neuf itérations strictes disponibles.
Cela affaiblit l'explication d'un arrêt linéaire seul comme cause du dépassement,
sur cette fenêtre. Le couplage non linéaire, le maillage/sillage et l'effet de
sortie restent à départager. Aucun phénomène oscillatoire physique, intervalle
de confiance, classement de variante ou rendement amélioré n'est établi.
La cible 960 stricte incomplète interdit une conclusion appariée finale.

Résidus natifs D1, sans extrapolation de la branche interrompue

## Preuves préservées et ressources libérées

Le conteneur observé respecte 4 CPU, cpuset 0/2/4/5, RAM et mémoire+swap de 5 GiB,
réseau absent, UID 1000, capabilities supprimées et sources montées en lecture
seule. Il n'est plus actif ; à 17:07:52 UTC seuls les deux services préexistants
restent présents. Aucune installation, location ou modification de service.

L'archive privée rapatriée préserve les deux tentatives, journaux, mesures,
protocoles, preuves de partition et le checkpoint 960 du témoin : 63 fichiers,
47047995 octets compressés, SHA-256
`362c82e93a3ed2ae27532f1c7aaa62115b8c02e49146f900caba2fbf1c411dc2`.
Les membres et le transfert sont vérifiés ; le checkpoint 900 et le maillage
sont déjà conservés dans l'archive native initiale. Les vingt petites entrées
utilisées par l'analyse correspondent aux empreintes de cette archive.
L'archivage post-calcul a pris 1,72 s, borné à 1 CPU/1 GiB ; il ne relance aucun
solveur. Les champs/logs complets restent privés. La [preuve d'archive](results/runtime/D1-native-archive-verification.json)
atteste cette conservation sans publier les sorties complètes.

L'admission historique R0 fine reste retirée ; D1 ne fournit pas ses mesures
manquantes. Une comparaison finale stricte nécessiterait une nouvelle fenêtre
explicitement coordonnée : aucune reprise ni extension n'est lancée. Les
interfaces physiques et scénarios de refroidissement installés restent aussi
à établir.

L’[analyse locale des champs conservés et le prochain essai proposé](D1_NEXT_DIAGNOSTIC.md)
complètent ce résultat sans nouvelle exécution. Les [sous-systèmes installés](SUBSYSTEM_PARAMETERS.md)
restent symboliques et sans dimensions mesurées.

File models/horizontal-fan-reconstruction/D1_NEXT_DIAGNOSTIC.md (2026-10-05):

# Après D1 : causes possibles et essai discriminant proposé

**Mise à jour :** l’essai unique préparé ici a été autorisé et exécuté.
Le [résultat D1C](D1C_EXECUTION.md) passe les critères numériques originaux
mais conserve le reflux et les limites physiques. Aucun lot supplémentaire lancé.

Les [champs natifs privés vérifiés](results/cfd/D1-local-field-diagnostic.json)
permettent cette analyse légère, sans nouveau solveur. Elle complète le
[résultat D1](D1_EXECUTION.md). Le témoin reste non admis sur la pression ;
la branche stricte reste incomplète. Les différences de champs ne localisent
pas le résidu algébrique de l'équation de pression.

## Hypothèses hiérarchisées

| Priorité | Hypothèse | Indices quantifiés et portée |
| --- | --- | --- |
| 1 | Mise à jour non linéaire vitesse–pression dans le sillage de bout de pale | À 901–920, le solveur strict divise le résidu final par 96,97 et l'erreur de continuité locale moyenne par 19,40, mais le maximum initial change de +0,174 %. Sur les 60 itérations du témoin, la troisième correction commence en moyenne à 21,27 % du résidu initial de la première ; des premières corrections dépassent encore le seuil lors des mises à jour suivantes. La linéarisation/correction globale mérite une sensibilité, sans conclure qu'elle est la cause. |
| 2 | Influence de la sortie proche dans une zone de reflux | À 960, débit net 1,15229968 m³/s et reflux brut 0,12399009 m³/s, soit 10,76 % du net ; 35,15 % de la surface de sortie a un flux entrant. Les dix variations de pression maximales restent à 31,7–34,1 mm de cette sortie, environ 0,12 D. Cette proximité et le reflux rendent la sensibilité de longueur plausible ; ils ne prouvent pas une condition incorrecte. |
| 3 | Conditionnement ou résolution locale du maillage | Les métriques reproduites correspondent au contrôle indépendant : non-orthogonalité 71,0857°, skewness 1,09927, déterminant minimal 0,00515090. Les 1 448 cellules avec \|Δp\| > 1 Pa ont une non-orthogonalité maximale 55,05°, skewness maximale 0,80398 et déterminant minimal 0,02393. Aucune ne recouvre les 69 cellules à >65°. Les dix maxima ont des angles 14,9–32,8°. La cause « pires cellules seules » est affaiblie ; la résolution du sillage et l'absence de couches restent non qualifiées. |

L'ordre ci-dessus représente la priorité d'un test, pas une probabilité de cause.
Le coarse V2 converge malgré une non-orthogonalité maximale supérieure à celle
du fin ; une métrique globale seule ne justifie donc pas de remesher.

Entre 900 et 960, RMS Δp pondéré par volume = 0,291515 Pa, maximum = 131,776 Pa ;
RMS ΔU = 0,0221393 m/s. Les cellules au-delà de 1 Pa occupent 0,240615 % du
volume. Les maxima sont aux rayons 129,3–137,0 mm, z = −15,4 à −17,9 mm,
à 0,51–2,43 mm du centroïde de face de rotor le plus proche. Ces distances
sont des proxies géométriques, pas des distances de paroi. La corrélation
cellulaire \|Δp\| / \|ΔU\| est 0,487 ; elle ne prouve aucune causalité.

## Cohérence des conditions et des flux

Les types de conditions sont identiques à 900 et 960 : rotor `MRFnoSlip` /
pression `zeroGradient`, carter `noSlip` / pression `zeroGradient`, entrée et
sortie `pressureInletOutletVelocity`, pression totale d'entrée nulle et
pression statique de sortie nulle. Cette configuration autorise effectivement
le reflux observé. Elle représente un ventilateur isolé, pas une résistance
thermique ou hydraulique de moteur mesurée. La turbulence imposée en reflux,
les interfaces moteur et la sensibilité compressible restent à qualifier.

La somme de divergence discrète du `phi` MRF relatif à 960 est
1,78165×10⁻⁷ m³/s et correspond à la somme des **quatre** patches. Le déséquilibre
des deux ports seuls vaut 1,64016×10⁻⁵ m³/s ; les flux de faces tournantes
relatifs expliquent la différence. Cette somme ne se lit pas comme une fuite
de paroi absolue. Le diagnostic n'accède ni à la matrice de pression ni à son
champ de résidu cellulaire ; il ne prétend pas identifier les cellules de
résidu initial maximal.

Le [code officiel de correction](https://raw.githubusercontent.com/OpenFOAM/OpenFOAM-13/master/applications/modules/incompressibleFluid/correctPressure.C)
montre que `consistent yes` modifie le coefficient inverse de la diagonale et
les corrections du flux et de la vitesse. Le [code des contrôles géométriques](https://raw.githubusercontent.com/OpenFOAM/OpenFOAM-13/master/src/meshCheck/primitiveMeshCheck/primitiveMeshCheck.C)
fonde les trois métriques locales reproduites ; leurs extrema sont comparés
aux résultats indépendants avant acceptation de ce rapport.

## Plus petit essai proposé avant lancement : une seule branche

Le [protocole fixé](parameters/D1-coupling-proposed-protocol.json) et le
[dictionnaire candidat](parameters/D1-coupling-candidate/fvSolution) changent
**uniquement `SIMPLE.consistent no` en `yes`**. On réutilise les 60 itérations
complètes du témoin D1 au lieu de recalculer ce témoin. La branche candidate
partirait du même checkpoint 900 et de la même partition MPI, pour 901–960.
Grille, champs initiaux, physique, conditions, schémas, relaxation p = 0,15,
relTol = 0,01, tolérance absolue = 10⁻⁸ et tous les critères sont identiques.
La vérification de chaque empreinte et des liens `uniform` précède le solveur.

Coût proposé : 4 CPU / 5 GiB RAM **et mémoire+swap**, une seule branche ;
environ 112 s de solveur d'après le témoin natif, environ 180 s au total,
plafond global **300 s préparation/reconstruction/audit inclus**, plafond MPI
180 s. Aucun service tiers, installation ou accès nouveau. Lancement bloqué
jusqu'à la coordination d'une fenêtre ; l'erreur ou le dépassement arrête le
lot et préserve son reçu, sans reprise automatique.

Les trois fenêtres 901–920 / 921–940 / 941–960 sont fixées avant le calcul ;
télémétrie chaque itération et checkpoint à 960. Les critères originaux restent
obligatoires sur 941–960 : p ≤10⁻⁴, U ≤10⁻⁵, k/ω ≤10⁻⁴, déséquilibre ≤0,5 %, CV
débit ≤1 %, CV couple ≤2 %, direction et champs finis complets.

- Un maximum p réduit d'au moins 30 % par rapport au témoin **et** tous les
  critères originaux satisfaits étayeraient une sensibilité au couplage.
- Un changement de moins de 10 % sur une fenêtre complète ne l'étayerait pas.
- Entre ces bornes ou en cas d'incomplétude : résultat descriptif, aucune
  conclusion de cause, prolongation ou admission inventée.

Ces règles sont des critères prospectifs de discrimination, pas des seuils
assouplis d'admission. Même un succès numérique ne qualifierait pas le débit
installé, le refroidissement, le rendement ou une oscillation physique.
Si cet essai n'est pas discriminant, la préparation suivante porterait sur
une longueur de sortie commune, avec gates CAD/maillage et transfert de champs
documentés avant toute nouvelle autorisation de calcul.

Pour reproduire l'analyse légère depuis les archives locales privées :

```sh
OPENBLAS_NUM_THREADS=1 OMP_NUM_THREADS=1 VECLIB_MAXIMUM_THREADS=1 python source/analyze_d1_local_fields.py PRIVATE_OLD_INPUTS PRIVATE_960_INPUTS PRIVATE_D1_LOGS work/D1-local-field-diagnostic.json
python source/verify_study.py
```

Le script ne lance ni solveur ni modification de maillage et ne publie aucun
champ natif complet. Les archives et le scan restent privés.

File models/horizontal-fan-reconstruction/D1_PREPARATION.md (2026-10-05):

# Préparation prospective D1 — snapshot avant exécution

Ce document décrit la préparation antérieure au lancement. Le [résultat actuel](D1_EXECUTION.md)
rapporte le témoin terminé et la branche stricte interrompue, sans admission.
À la date de cette préparation, le lot attendait la libération explicite de Kali2 par la coordination. Le pilote
Ti conserve sa fenêtre ; aucun solveur, conteneur ou copie de maillage D1 n'a
été lancé. Les petits dictionnaires V2/900 ont été lus en lecture seule et
recoupés avec l'archive native privée : huit fichiers, 8027 octets. Les champs
et le maillage restent sur leur ressource d'origine.

## Comparaison figée avant calcul

Le [manifeste de la paire préparée](parameters/D1-prepared-pair-manifest.json)
lie les neuf fichiers du checkpoint 900, treize fichiers constants, les
configurations préparées et les sources. Les deux branches sont :

| Branche | GAMG relTol pression | Tolérance absolue | Relaxation p | Itérations |
| --- | ---: | ---: | ---: | --- |
| control | 0,01 | 10⁻⁸ | 0,15 | 901–960 |
| absolute | 0 | 10⁻⁸ | 0,15 | 901–960 |

Modèle, conditions physiques, CAD, maillage, autres tolérances et critères
originaux sont inchangés. Le futur exécuteur copie le même état 900, vérifie les
empreintes des copies, décompose une seule fois et copie la même partition
initiale MPI dans les deux branches avant le premier solveur. Les cas sont
séquentiels. Il ne relance aucun cas en échec.

Les checkpoints ont un intervalle 60 et les trois fonctions de débit/force un
intervalle 1. La fenêtre d'admission exige vingt mesures à 941–960. Le rapport
prospectif exige aussi toutes les soixante mesures pour ses trois fenêtres :
901–920, 921–940, 941–960. Les résidus p/U/turbulence, masse, stabilité débit/couple,
direction et champs complets finis restent exigés avec les seuils originaux.
Le compte attendu de cellules 453496 est lié au résumé des champs natifs 900.

Chaque fenêtre rapporte moyenne, écart type, min/max et CV si la moyenne est
non nulle : Qin/Qout, couple total, résidu initial et résidu final linéaire p,
continuité globale. La différence des moyennes finales entre branches et leurs
CV sont descriptifs. Ces variations d'itérations stationnaires ne sont pas un
bruit physique, des observations indépendantes, un intervalle de confiance ou
une fréquence rotor. Aucun seuil de significativité n'est ajusté après calcul.
Un diagnostic nouvellement admis ne restitue jamais les mesures historiques
fines manquantes et ne rétablit pas rétroactivement l'admission R0 fine.

## Exécution future bornée

Le lanceur est [launch_d1_pair.py](source/launch_d1_pair.py), avec
[exécuteur isolé](source/run_d1_in_container.py). Il utilise seulement l'image
Foundation 13 déjà disponible et figée, sans réseau ni téléchargement :
4 CPU, cpuset 0/2/4/5, 5 GiB RAM et mémoire+swap, tâches à nice 10. Il exige
6 GiB disponibles à l'admission et refuse un autre conteneur de cette image.
Le plafond global est 600 s, préparation/copies incluses ; la charge du
conteneur est plafonnée à 580 s, chaque MPI à 270 s, sans prolongation. Le
lanceur réserve du temps pour arrêter seulement son conteneur nommé en cas
de timeout, puis conserve les logs et receipts. Aucun service tiers n'est touché.
Estimation : 4–6 min ; plafond : 10 min. L'exécution native de ces nouveaux
helpers n'est pas encore vérifiée : cette vérification attend la fenêtre.

Après libération et transfert de la capsule locale de préparation, la commande
sur Kali2 sera de la forme suivante. Ce bloc documente la future exécution ;
il n'a pas été exécuté.

```sh
python D1_CAPSULE/source/launch_d1_pair.py NATIVE_V2_900_CASE D1_CAPSULE NEW_D1_OUTPUT --coordinated-release COORDINATOR_RELEASE_REFERENCE
```

Pour reproduire seulement la préparation locale, sans solveur ni maillage :

```sh
python source/prepare_d1_configurations.py NATIVE_SMALL_CONFIG SOURCE_IDENTITY_JSON NEW_CONFIG_OUTPUT
```

## Sous-systèmes visibles, dimensions en attente

Le [contrat qualitatif](parameters/qualitative-subsystem-contract.json) distingue
quatre sous-systèmes à documenter avant toute reconstruction fonctionnelle :
plénum installé, train poulies/courroie avant, support nervuré et enveloppe
centrale relevée. Les paramètres et interfaces sont tous inconnus (`null`).
La vidéo confirme seulement une implantation générale ; elle ne mesure aucun
diamètre, ratio, axe de fixation, matériau ou tolérance. R0 reste un rotor,
un carter et une transmission analytique ; son propre modèle ne fournit pas
les mesures manquantes des nouveaux sous-systèmes. Aucune nouvelle géométrie
dimensionnée ni preuve de montage n'est générée.

La [publication exacte fournie par le parent](https://www.instagram.com/patrickmotorsports/reel/DeC4x04yjNP/)
revendique un ensemble « 935 3.5L Flat Fan MoTeC EFI » et une boîte-pont 993 à 6 rapports ;
cela n'identifie pas la base moteur comme 993, ni l'équivalence du ventilateur.
Les images tierces restent privées. La recherche publique du moteur n'est
pas dupliquée ici.

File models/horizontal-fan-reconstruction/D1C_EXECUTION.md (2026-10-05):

# D1C : essai terminé, admission numérique limitée

Une seule branche de 60 itérations a été autorisée après libération des
réservations Kali2. Elle reprend le même état V2/900 et les mêmes 80 fichiers
de partition MPI que le témoin D1 conservé. Le seul changement numérique est
`SIMPLE.consistent no` → `yes`. Aucun maillage, condition physique, schéma,
relaxation, tolérance ou critère d'admission n'est changé.

[Résultat et fenêtres natives](results/cfd/D1C-bounded-result.json) ·
[Résumé original à 960](results/cfd/D1C-960-flow-summary.json) ·
[Champs comparés et reflux](results/cfd/D1C-matched960-field-differences.json) ·
[Bilan des ports](results/cfd/D1C-960-energy-and-port-analysis.json) ·
[Conservation](results/runtime/D1C-native-archive-verification.json).

## Mesures et critères identiques

Les itérations 901–960 sont toutes terminées, sans queue partielle. Chaque
table native contient **61 mesures, état 900 compris**, soit 60 nouvelles.
Les trois fenêtres prospectives 901–920 / 921–940 / 941–960 disposent de vingt
échantillons consécutifs ; la dernière est la fenêtre d'admission. Les cinq
champs finaux U/p/k/omega/nut contiennent chacun 453 496 cellules finies.

| Mesure sur 941–960 | Témoin D1 consistent no | D1C consistent yes |
| --- | ---: | ---: |
| Résidu initial p maximal | 1,386159985×10⁻⁴ | 7,622277815×10⁻⁵ |
| Débit de sortie moyen, m³/s | 1,15229935155 | 1,152299802885 |
| Puissance moyenne, W | 2429,758222624 | 2429,768471103 |
| CV débit | 2,77178×10⁻⁷ | 3,30038×10⁻⁷ |
| CV couple | 3,04282×10⁻⁵ | 2,59172×10⁻⁵ |
| Déséquilibre maximal des ports | 1,44516×10⁻⁵ | 1,43770×10⁻⁵ |

La baisse du maximum initial p est **45,0116 %**. Le candidat passe tous les
critères originaux : p ≤10⁻⁴, U ≤10⁻⁵, k/ω ≤10⁻⁴, déséquilibre ≤0,5 %, CV
débit ≤1 %, CV couple ≤2 %, direction et champs complets finis. Il satisfait
la règle prospective « baisse p ≥30 % et tous les gates » : ce résultat étaye
une **sensibilité numérique au couplage**, sans identifier une cause physique.
Le témoin D1 reste non admis sur p. Les mesures R0 manquantes ne sont pas
restaurées et aucune paire historique fine n'est rétroactivement admise.

Le débit moyen change de +0,00003917 % et la puissance de +0,00042179 %.
Ces différences ne prouvent aucun gain de refroidissement ou de rendement.
Les itérations stationnaires ne représentent ni temps physique, ni fréquence
de rotor, ni réalisations statistiques indépendantes.

Résidus natifs D1C et témoin, fenêtre finale fixée avant calcul

## Reflux et champs locaux : limites explicites

À 960, le reflux brut reste **0,123990213 m³/s**, soit **10,76024 %** du débit
net. Il concerne les mêmes 1 572 faces sur 4 542 et **35,15382 %** de la surface
de sortie, pratiquement comme le témoin. L'amélioration du résidu n'a pas
résolu l'influence possible de cette sortie proche, ni fourni une résistance
de moteur mesurée.

La comparaison des champs à 960 donne une différence p RMS pondérée par
volume de 0,544038 Pa, mais un maximum local de **317,669 Pa** ; ΔU RMS est
0,0624630 m/s. La stabilité des débits/couples intégrés ne garantit donc pas
l'insensibilité des champs locaux. Ces différences ne sont ni des résidus
algébriques cellulaires ni une incertitude expérimentale. L'indépendance de
maillage, les couches de paroi, les interfaces et conditions installées
restent non qualifiées.

Le Mach absolu maximal reste 0,3766 sous les hypothèses de screening :
une sensibilité compressible demeure requise. La pression totale de sortie
pondérée par flux est 1569,57 Pa. Le ratio énergie des ports / puissance
0,7444 n'est pas un rendement qualifié. Le couple de pression est retrouvé
avec une erreur relative de 4,68×10⁻¹² et la vitesse de paroi Ω×r à
7,05×10⁻⁹ m/s ; ces identités vérifient la lecture des sorties, pas leur
validation physique.

## Budget et clôture

Préflight actuel : Kali2 amd64, 12 CPU logiques, mémoire disponible
11 353 784 320 octets, aucun conteneur d'écoulement actif. Les limites réelles
sont 4 CPU, cpuset 0/2/4/5, RAM et mémoire+swap 5 GiB, réseau absent, UID/GID
1000, capabilities supprimées et sources/baseline/capsule en lecture seule.
Les services préexistants restent identiques.

Solveur 117,18 s, reconstruction 4,97 s, audit natif 2,63 s ; préparation,
archivage et vérification compris, **128,169 s au total**, sous le plafond
global 300 s. Le conteneur propre est libéré à **18:25:36 UTC le 4 octobre
2026**. Aucune seconde branche, phase additionnelle, relance ou prolongation.

L'archive privée des champs finaux, journaux, systèmes et reçus contient
25 membres vérifiés, 47 464 242 octets, SHA-256
`916c4b4e2a23c22e112763f58a9592896ee28e8f7e05ae8cb608e73c776fbfad`.
Les trois tables natives sont conservées et rapatriées séparément : leurs
empreintes correspondent au résumé natif original inclus dans l'archive.
Le transfert et chaque membre sont vérifiés. Scan, champs complets et tables
restent privés ; les rapports publiés sont assainis.

Les [configurations utilisées](parameters/D1C-executed-configurations/) et
le [manifeste de capsule](parameters/D1C-executed-capsule-manifest.json) sont
conservés. Les indicateurs `not_launched` des protocoles figés décrivent leur
préparation avant lancement ; ils ne remplacent pas le reçu d'exécution.
Le [protocole prospectif](parameters/D1-coupling-proposed-protocol.json) reste
préservé sans réécriture après connaissance du résultat.

Reproduction du paquet et analyses depuis les entrées natives privées :

~~~sh
python source/prepare_d1c_capsule.py . work/D1C-capsule
python source/analyze_d1c_result.py PRIVATE_D1C_INPUTS . work/D1C-result.json
OPENBLAS_NUM_THREADS=1 OMP_NUM_THREADS=1 python source/compare_d1c_native_fields.py PRIVATE_D1_CONTROL_FIELDS PRIVATE_D1C_INPUTS work/D1C-field-differences.json
OPENBLAS_NUM_THREADS=1 OMP_NUM_THREADS=1 python source/analyze_flow_balance.py PRIVATE_D1C_CASE work/D1C-port-analysis.json --time 960
python source/verify_study.py
~~~

Ces commandes ne lancent aucun solveur. Une reproduction du calcul via
`launch_d1c.py` exige une nouvelle fenêtre coordonnée et les sources privées
900/partition ; elle n'est pas lancée automatiquement.

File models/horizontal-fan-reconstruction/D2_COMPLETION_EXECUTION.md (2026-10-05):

# D2 terminé à 1020 : comparaison encore inconclusive

La reprise unique autorisée a terminé **1001–1020**, depuis le checkpoint1000
natif vérifié, sans rejouer le témoin. La branche prolongée totalise donc
**40 + 20 itérations complètes** ; le témoin conserve ses60 itérations d'origine.
Géométrie, partitions, MRF, conditions limites, numérique et critères restent
inchangés. **La pression ne satisfait toujours pas les critères numériques et
de stationnarité.** Le lot est clos, ressources libérées, aucune suite1040.

[Retour à l'étude](README.md) · [Accueil](../../README.md) ·
[Lot D2 initial, preuves conservées](D2_EXECUTION.md) ·
[Préparation et protocole1000→1020](D2_COMPLETION_PREPARATION.md)

## Exécution et ressources

Le [préflight natif](results/runtime/D2-supervisor-native-input-verification.json)
contrôle les96 fichiers de la copie préparée, les16 fichiers de capsule, les12
entrées natives réutilisées et les sélections communes. Une première entrée
du superviseur s'est arrêtée avant création du conteneur : l'import Python
avait ajouté un cache dans la capsule vérifiée. La capsule finale et le
démarrage `python3 -B` corrigent ce point ; aucun solveur n'avait été lancé.
Le transfert initial comportant des fichiers auxiliaires macOS a aussi été
écarté avant lancement. Ces préparations ne modifient aucun état CFD.

Le [reçu d'exécution](results/runtime/D2-completion-execution-receipt.json)
contient exactement trois commandes, toutes terminées avec code0 :

| Commande native | Temps mesuré | Plafond de phase |
|---|---:|---:|
| Un seul `foamRun -parallel`, quatre rangs,1001–1020 | 67,007 s | 110 s |
| `reconstructPar -time 1000,1020` | 12,875 s | 25 s |
| Contrôle final et analyse des deux fenêtres/domaines | 16,724 s | 30 s |

Le [superviseur](source/launch_d2_completion.py) et le
[runner de branche unique](source/run_d2_completion.py) utilisent une seule
date limite monotone pour admission, copie, solveur, reconstruction, analyse,
archivage et libération. **Temps global réellement mesuré : 110,505 s sous
240 s**, [preuve native expurgée](results/runtime/D2-completion-launcher-receipt-sanitized.json).
CPU réel plafonné à4, cpuset de quatre cœurs physiques distincts, RAM+swap
**5 GiB**, réseau absent, sources/préparation/témoin/sélections en lecture seule.
Admission : 11 294 654 464 octets disponibles,12 CPU logiques, charge1,369.
Pic RSS d'enfant460 348 KiB : cette valeur n'est pas une mesure agrégée.

Le conteneur est libéré le4 octobre2026 à **21:26:53 UTC**. La
[confirmation indépendante à21:31:28 UTC](results/runtime/D2-completion-release-confirmation.json)
constate son absence et les services préexistants inchangés. Aucun service
tiers arrêté, accès persistant ajouté, installation, location ou dépense.
Aucune réservation Mac/Kali2 n'est maintenue.

## Validation du checkpoint et de la fenêtre

Le [certificat natif1020](results/runtime/D2-completion-native1020-verification.json)
vérifie32 fichiers : `p/U/k/omega/nut/phi/Uf` et `uniform/time` sur quatre rangs,
cardinalités correctes, valeurs finies, index/temps1020 concordants. Les
champs sériels reconstruits couvrent chacun680 596 cellules. Le log contient
exactement vingt pas complets1001–1020 et `End` ; chaque table finale possède
les vingt mesures consécutives requises. La fenêtre n'est plus manquante.

Le [résumé final natif](results/cfd/D2-extended1020-flow-summary.json) reste
**non admis** :

| Critère original sur1001–1020 | Mesure | Limite | État |
|---|---:|---:|---|
| Maximum du résidu initial p | 0,0106874 | 0,0001 | Rejet |
| Maximum du résidu initial d'une composante U | 0,00184464 | 0,00001 | Rejet |
| Maximum du résidu initial k | 0,00443590 | 0,0001 | Rejet |
| Maximum du résidu initial ω | 0,000003672 | 0,0001 | Passe |
| Déséquilibre de débit maximal | 0,0000340581 | 0,005 | Passe |
| CV du débit de frontière | 0,00115817 | 0,01 | Passe |
| CV du couple | 0,00115130 | 0,02 | Passe |

Les champs finis, les mesures finies et le sens de débit déclaré passent.
Le témoin réutilisé conserve ses dix critères originaux et ses sept contrôles
supplémentaires admis. La branche prolongée échoue encore quatre des sept
contrôles de stationnarité :

| Contrôle supplémentaire | Mesure | Limite |
|---|---:|---:|
| Écart-type pression commune, fenêtre1001–1020 | **6,1701 Pa** | 2 Pa |
| Écart des moyennes pression981–1000 /1001–1020 | **15,5991 Pa** | 2 Pa |
| RMS volumique pression du cœur1000→1020 | **10,3471 Pa** | 1 Pa |
| RMS volumique vitesse du cœur1000→1020 | **0,381724 m/s** | 0,1 m/s |

P99/max des variations locales du cœur :30,170 /195,111 Pa et1,337 /60,557 m/s.
Les variations des zones fixes et les écarts locaux entre domaines figurent
dans l'[analyse complète](results/cfd/D2-completed-pair-analysis.json).
Ces indicateurs restent des variations d'itérations SIMPLE stationnaires,
sans temps physique ; ils ne démontrent pas une oscillation réelle du moteur.

## Comparaison descriptive, sans admission

Sur les vingt mesures natives1001–1020 :

| Observable commune | Témoin réutilisé | Prolongé terminé |
|---|---:|---:|
| Débit orienté au plan commun | 1,152300435 m³/s | 1,153996582 m³/s |
| Pression statique moyenne de bande | 85,647426 Pa | 82,145799 Pa |
| Couple du fluide sur le rotor | −3,867106500 N·m | −3,822585586 N·m |
| Puissance mécanique du rotor, régime supposé6000 tr/min | 2429,7747 W | 2401,8014 W |

Écarts symétriques : débit0,14698 %, couple/puissance1,15127 %, pression
3,501627 Pa pour une bande descriptive5 Pa. **Les quatre bandes descriptives
passent, mais leurs prérequis numériques et de stationnarité échouent.**
Le statut demeure `inconclusive_domain_comparison` ; aucune sensibilité physique
stationnaire du domaine, indépendance générale ou amélioration airflow n'est
établie. La pression de bande n'est pas une hausse de pression entre ports.

À1020, reflux grossier : témoin0,123976 m³/s ; prolongé dans le plan commun
0,107130 m³/s ; prolongé à la frontière éloignée0,125093 m³/s. Le reflux
persiste à la frontière déplacée. L'écart RMS entre champs du cœur des deux
domaines est38,6723 Pa et1,49356 m/s ; ces snapshots non admis ne qualifient
pas un effet stationnaire du domaine. Vitesse locale maximale finale128,760 m/s,
soit Mach estimé0,3754 avec343 m/s : la compressibilité n'est pas qualifiée par
ce modèle incompressible MRF.

Traces natives D2, reprise20 pas séparée

[Provenance du rendu](results/cfd/D2-completed-native-traces.json) : uniquement
les mesures et résidus des60 pas du témoin,40 pas initiaux prolongés et20 pas
repris. Aucune extrapolation ni image inventée. La séparation1000/1001 est
visible et les axes portent les unités.

## Conservation et reproduction

L'[archive privée transférée et vérifiée](results/runtime/D2-completion-native-archive-verification.json)
contient **181 fichiers**,352 214 760 octets compressés, SHA256
`5b2591992c93d92781f871fb6f69a86befb991938ae9807d0af83ecad67c3c6f`.
Tous les membres sont vérifiés nativement puis après transfert. Les champs
natifs de partitions1000 et1020, maillages, logs séparés, tables et capsule
exacte sont conservés ; le brut du scan n'est pas inclus. Aucun champ, maillage
ou table native brute n'est publié dans le dépôt.

L'[analyse composée](results/cfd/D2-completion-comparison-provenance.json)
déclare explicitement40 +20 pas. Les logs originaux restent distincts ; le
bloc1001 incomplet de l'ancien log n'est pas un pas complet. Seules trois
vues de tables dérivées assemblent les lignes natives, avec contrôle de la
mesure1000 dupliquée et SHA des deux sources. Elles ne sont pas présentées
comme un log natif unique. Le témoin est réutilisé sans solveur.

La [capsule réellement exécutée](parameters/D2-completion-executed-capsule-manifest.json)
est conservée avec ses sources et configs exactes. `make fan-program-check`
vérifie les identités, les preuves natives et les limites de qualification.
Les tests logiciels couvrent la branche unique, les limites240 s/4 CPU/5 GiB,
l'isolation avant solveur, l'arrêt du seul conteneur possédé, le timeout sans
relance, l'archivage partiel non qualifié et le démarrage sans cache Python.
Un test refuse explicitement de promouvoir ces résultats lorsque les bandes
descriptives passent mais que la pression reste non stationnaire.

**Arrêt final1020 respecté.** Identité935/993, unités du scan, dimensions et
interfaces installées, modèle compressible, parois, matériaux, fatigue,
simulation process LPBF qualifiée et jumeau NVIDIA physique validé restent
ouverts conformément aux autres étapes documentées. Aucun résultat présent
n'autorise la fabrication ou la mise en service.

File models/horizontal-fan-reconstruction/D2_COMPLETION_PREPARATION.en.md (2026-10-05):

# D2: prepare the twenty missing iterations

**Preparation history.** The [1001–1020 restart is now complete](D2_COMPLETION_EXECUTION.en.md)
after explicit approval, in 110.505 s overall. Pressure remains unadmitted,
the comparison inconclusive and resources released. The prepared protocol
below and its criteria are retained without changing its frozen artifacts.

**Verified preparation, no solver launched, no resource reserved.**
The [initial D2 batch](D2_EXECUTION.en.md) remains closed and its results unchanged.
The control completed 961–1020; only the extended branch concerns this proposal.
The objective is to finish the comparison truncated by its budget at **1020**,
without an automatic extension to obtain admission.

## Native state actually available

The [private checkpoint audit](results/runtime/D2-restart-checkpoint-audit.json),
performed on October 4, 2026 at 20:46:51 UTC without a solver or reconstruction,
verifies **980 and 1000 complete on all four partitions**. Each partition
contains `p`, `U`, `k`, `omega`, `nut`, `phi`, `Uf` and `uniform/time`.
Volumetric fields cover 680 596 cells, with 122 709 / 167 115 / 208 232 /
182 540 cells per rank. Face-field cardinalities are checked against the
native mesh; values are finite. The four indices and times saved at 1000 agree,
`deltaT = deltaT0 = 1`.

The selected checkpoint is **1000**, the latest complete one: 32 native files,
152 261 842 bytes. The serial root contains only 960; no 1001 or 1020 checkpoint
exists. The old log's incomplete start of iteration 1001 is not a restartable
state. The parallel restart will use existing 1000 fields, never a state
reconstructed from integrals.

The [preparer](source/prepare_d2_restart1000.py) actually created a separate
private copy of the mesh, configurations and four 1000 partitions.
The [preparation evidence](results/runtime/D2-restart-preparation-receipt.json)
checks SHAs and sizes before and after copying. Final portable code prepared
this copy in **0.580 s**; an earlier provisional copy was also retained.
No solver, `reconstructPar`, `decomposePar` or container was executed for this
preparation. Native files from the closed batch are preserved. The
`1000/uniform/time` marker at the copy's root is used only by the summary helper;
it is not presented as complete serial fields.

## Proposed fixed restart

The [completion protocol](parameters/D2-restart1000-protocol.json) requires
**one branch, four ranks, exactly 1001–1020**, one solver call. The complete
control is reused read-only. No new mesh, partitioning, geometry, MRF zone,
speed, boundary condition, scheme or threshold. The outlet remains extended
by 275 mm in fifty layers, with the same 453 496-cell core and common selections.

The [prepared controlDict](parameters/D2-restart1000-controlDict) is byte-identical
to the actually executed native control except `startFrom startTime` and
`startTime 1000`. `endTime 1020`, `deltaT 1`, saving every 20 steps,
`purgeWrite 0` and measurements every iteration are retained. The static
check reconstructs those two substitutions and recovers the original native
file's SHA. Restart effectiveness still requires verification in future
execution: first step 1001, twenty consecutive complete steps, `End`
termination, finite native tables and a complete 1020 checkpoint are mandatory.

Reproducible preparation, with private paths supplied explicitly:

```sh
python3 source/prepare_d2_restart1000.py \
  "$D2_NATIVE_EXTENDED" "$D2_NATIVE_CHECKPOINT_AUDIT" \
  parameters/D2-restart1000-protocol.json \
  parameters/D2-restart1000-controlDict "$D2_PRIVATE_PREPARED_CASE"
```

This command copies and verifies files; it launches no calculation.
The only planned numerical commands, **to be supervised in the existing
isolated runtime after explicit coordination**, are:

```sh
mpirun --bind-to none --use-hwthread-cpus -np 4 foamRun -parallel
reconstructPar -time 1000,1020
```

These two commands are not an authorized standalone launcher. The historical
`launch_d2.py` launcher prepares and reruns a pair, so it does not suit this
single restart. Before execution, this batch's supervisor must enforce the
overall ceiling below, preserve evidence and terminate only its own
process/container. It must use a **new deadline**, never the expired deadline
of the 720 s batch. No installation, image download, rental or service change
is necessary.

The [dedicated supervisor now tested and executed](source/launch_d2_completion.py)
applies this contract to one branch; its
[exact capsule](parameters/D2-completion-executed-capsule-manifest.json) and
evidence appear in the final report. Earlier passages about pending adaptation
describe the preparation state before the batch.

## Observed cost and proposed budget

The extended branch's native log gives `ExecutionTime = 81.138094 s` at 980,
then `155.099948 s` at 1000: **73.961854 s for twenty iterations**, or
approximately 3.70 s/iteration. Rounded `ClockTime` values give **75 s**.
This measurement includes saving 1000. The maximum increment in this window
is 4.869 s. Partition imbalance is retained; no linear estimate based only on
cell count replaces this measurement.

| Future stage | Estimate / evidence | Proposed ceiling |
|---|---|---:|
| Fresh admission, identity and isolated copy | Final copy measured 0.580 s; preceding complete audit 10.174 s | 30 s |
| Twenty iterations 1001–1020 | Estimated 75–80 s with restart, last 20 measured at 75 s | 110 s |
| Reconstruction 1000 and 1020 | Control: three checkpoints reconstructed in 11.480 s; extended estimate 15–25 s | 25 s |
| Summary, windows, fields and comparison | Estimate, no measurement of this future batch | 30 s |
| Archiving, verification and release | Previous final archiving/verification 6.389 s; increased reserve for this batch | 45 s |
| **Overall, without reset** | **Estimated nominal 120–180 s** | **240 s** |

This budget is **proposed, not started**: at most 4 CPU, RAM+swap 5 GiB,
no networking, niceness 10, same already available Foundation 13 image.
Load, RAM and coordination must be checked immediately before launch.
No implicit reservation is maintained during preparation. The budget
guarantees neither convergence nor archiving time; an overrun preserves the
partial state and ends the batch without another trial.

## Analysis and stop rule

The [original criteria](parameters/D2-executed-configurations/protocol.json)
are copied unchanged into the proposed protocol. The final window must contain
twenty consecutive measurements 1001–1020. It is compared to the native
981–1000 window; core RMS, local p99/max and backflow are evaluated on actual
1000 and 1020 checkpoints. Common pressure: dispersion ≤2 Pa, difference
between window means ≤2 Pa and core pressure RMS ≤1 Pa. Maximum initial p
residual ≤10⁻⁴; other numerical, velocity and stability thresholds remain
mandatory.

The previous pressure-steadiness failure remains documented.
**Even with twenty complete additional iterations, unsteady pressure rejects
admission.** The physical domain comparison remains inconclusive if any
numerical or steadiness prerequisite fails. The batch stops at 1020 in all
cases; no threshold is relaxed and no 1040 continuation is planned. Eventual
admission would qualify neither local fields, general domain independence nor
installed cooling.

Retain separately the old native log with 40 complete steps plus the start
of 1001, the new 20-step log and their tables. A composed analysis view, if
needed, must be identified as derived: remove only the incomplete 1001 block
from the old view, check equality of measurements at the 1000 checkpoint
before deduplication and retain both source SHAs. Never present that view as
one native log. Future fields and meshes remain private; only original scripts,
parameters and sanitized reports may be published.

Verification without a solver: `make fan-program-check`. Five new tests reject,
among other things, a missing surface field, nonfinite pressure, mixed times,
extra steps and control replay. Initial D2 results, their capsule, archives
and earlier validations remain unchanged.

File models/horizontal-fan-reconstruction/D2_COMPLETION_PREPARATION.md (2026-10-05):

# D2 : préparer les vingt itérations manquantes

**Historique de préparation.** La [reprise1001–1020 est désormais terminée](D2_COMPLETION_EXECUTION.md)
après accord explicite, en110,505 s tout compris. Pression encore non admise,
comparaison inconclusive, ressources libérées. Le protocole préparé ci-dessous
et ses critères sont conservés sans modifier ses artefacts gelés.

**Préparation vérifiée, aucun solveur lancé, aucune ressource réservée.** Le lot
[D2 initial](D2_EXECUTION.md) reste clos et ses résultats restent inchangés.
Le témoin a terminé 961–1020 ; seule la branche prolongée est concernée par
cette proposition. L'objectif est de terminer la comparaison tronquée par son
budget à **1020**, sans prolongation automatique pour obtenir une admission.

## État natif réellement disponible

L'[audit privé des checkpoints](results/runtime/D2-restart-checkpoint-audit.json),
effectué le 4 octobre 2026 à 20:46:51 UTC sans solveur ni reconstruction,
vérifie **980 et 1000 complets sur les quatre partitions**. Chaque partition
contient `p`, `U`, `k`, `omega`, `nut`, `phi`, `Uf` et `uniform/time`. Les champs
volumiques couvrent 680 596 cellules, avec 122 709 / 167 115 / 208 232 / 182 540
cellules par rang. Les cardinalités des champs de faces sont contrôlées contre
le maillage natif ; les valeurs sont finies. Les quatre index et temps sauvés
à 1000 concordent, `deltaT = deltaT0 = 1`.

Le checkpoint choisi est **1000**, le dernier complet : 32 fichiers natifs,
152 261 842 octets. La racine sérielle contient seulement 960 ; il n'existe
aucun checkpoint 1001 ou 1020. Le début incomplet d'itération1001 dans l'ancien
log ne constitue pas un état reprenable. La reprise parallèle utilisera les
champs1000 existants, jamais un état reconstruit à partir des intégrales.

Le [préparateur](source/prepare_d2_restart1000.py) a effectivement créé une
copie privée séparée du maillage, des configs et des quatre partitions1000.
La [preuve de préparation](results/runtime/D2-restart-preparation-receipt.json)
contrôle les SHA et tailles avant et après copie. Le code final portable a
préparé cette copie en **0,580 s** ; une copie provisoire antérieure a également
été conservée. Aucun solveur, `reconstructPar`, `decomposePar` ou conteneur n'a
été exécuté pour cette préparation. Les fichiers natifs du lot clos sont
préservés. Le marqueur `1000/uniform/time` à la racine de la copie sert uniquement
au helper de résumé ; il n'est pas présenté comme des champs sériels complets.

## Reprise fixe proposée

Le [protocole de complétion](parameters/D2-restart1000-protocol.json) impose
**une branche, quatre rangs, exactement 1001–1020**, un seul appel au solveur.
Le témoin complet est réutilisé en lecture seule. Pas de nouveau maillage,
de partitionnement, de géométrie, de zone MRF, de régime, de condition limite,
de schéma ou de seuil. La sortie reste prolongée de 275 mm en cinquante couches,
avec le même cœur de 453 496 cellules et les mêmes sélections communes.

Le [controlDict préparé](parameters/D2-restart1000-controlDict) est identique
octet pour octet au contrôle natif effectivement exécuté, sauf `startFrom
startTime` et `startTime 1000`. `endTime 1020`, `deltaT 1`, sauvegarde tous les
20 pas, `purgeWrite 0` et mesures à chaque itération sont conservés. Le contrôle
statique reconstruit ces deux substitutions et retrouve le SHA du fichier
natif original. L'efficacité de la reprise reste à vérifier lors d'une future
exécution : premier pas1001, vingt pas complets consécutifs, terminaison `End`,
tables natives finies et checkpoint1020 complet sont obligatoires.

Préparation reproductible, avec les chemins privés fournis explicitement :

```sh
python3 source/prepare_d2_restart1000.py \
  "$D2_NATIVE_EXTENDED" "$D2_NATIVE_CHECKPOINT_AUDIT" \
  parameters/D2-restart1000-protocol.json \
  parameters/D2-restart1000-controlDict "$D2_PRIVATE_PREPARED_CASE"
```

Cette commande copie et vérifie les fichiers ; elle ne lance aucun calcul.
Les seules commandes numériques prévues, **à superviser dans le runtime
existant isolé après coordination explicite**, sont :

```sh
mpirun --bind-to none --use-hwthread-cpus -np 4 foamRun -parallel
reconstructPar -time 1000,1020
```

Ces deux commandes ne constituent pas un lanceur autonome autorisé. Le lanceur
historique `launch_d2.py` prépare et rejoue une paire ; il ne convient donc pas
à cette reprise unique. Avant une exécution, le superviseur de ce lot doit
appliquer le plafond global ci-dessous, conserver les preuves et arrêter
uniquement son propre processus/conteneur. Il doit utiliser une **nouvelle
date limite**, jamais la date limite expirée du lot720 s. Aucune installation,
image téléchargée, location ou modification de service n'est nécessaire.

Le [superviseur dédié désormais testé et exécuté](source/launch_d2_completion.py)
applique ce contrat à une seule branche ; sa [capsule exacte](parameters/D2-completion-executed-capsule-manifest.json)
et ses preuves se trouvent dans le rapport final. Les anciens passages sur une
adaptation restant à faire décrivent l'état de préparation antérieur au lot.

## Coût observé et budget proposé

Le log natif de la branche prolongée donne `ExecutionTime = 81,138094 s` à
980 puis `155,099948 s` à 1000 : **73,961854 s pour vingt itérations**,
soit environ 3,70 s/itération. Les `ClockTime` arrondis donnent **75 s**.
Cette mesure inclut la sauvegarde1000. Le maximum d'incrément de cette fenêtre
est 4,869 s. Le déséquilibre des partitions est conservé ; aucune estimation
linéaire basée seulement sur le nombre de cellules ne remplace cette mesure.

| Étape future | Estimation / preuve | Plafond proposé |
|---|---|---:|
| Admission fraîche, identité et copie isolée | Copie finale mesurée 0,580 s ; audit complet précédent 10,174 s | 30 s |
| Vingt itérations1001–1020 | 75–80 s estimés avec redémarrage, dernier20 mesuré75 s | 110 s |
| Reconstruction1000 et1020 | Témoin : trois checkpoints reconstruits en11,480 s ; estimation prolongée15–25 s | 25 s |
| Résumé, fenêtres, champs et comparaison | Estimation, aucune mesure de ce futur lot | 30 s |
| Archivage, vérification et libération | Archivage/vérification final précédent6,389 s ; réserve accrue pour ce lot | 45 s |
| **Ensemble, sans remise à zéro** | **120–180 s nominaux estimés** | **240 s** |

Ce budget est **proposé, non démarré** : 4 CPU maximum, RAM+swap5 GiB, réseau
absent, niceness10, même image Foundation13 déjà disponible. Charge, RAM et
coordination doivent être vérifiées immédiatement avant lancement. Aucune
réservation implicite n'est maintenue pendant cette préparation. Le budget ne
garantit ni la convergence, ni le temps d'archivage ; un dépassement conserve
l'état partiel et termine le lot sans nouvel essai.

## Analyse et règle d'arrêt

Les [critères originaux](parameters/D2-executed-configurations/protocol.json)
sont recopiés sans modification dans le protocole proposé. La fenêtre finale
doit contenir vingt mesures consécutives1001–1020. Elle est comparée à la
fenêtre native981–1000 ; RMS du cœur, p99/max locaux et reflux sont évalués
sur les véritables checkpoints1000 et1020. Pression commune : dispersion
≤2 Pa, différence entre moyennes des deux fenêtres ≤2 Pa et RMS pression du
cœur ≤1 Pa. Maximum du résidu initial p ≤10⁻⁴ ; les autres seuils numériques,
de vitesse et de stabilité restent également obligatoires.

Le précédent échec de stationnarité de pression reste documenté. **Même avec
vingt itérations supplémentaires complètes, une pression non stationnaire
rejette l'admission.** La comparaison physique des domaines reste inconclusive
si l'un des prérequis numériques ou de stationnarité échoue. Le lot s'arrête
à1020 dans tous les cas ; aucun seuil n'est assoupli, aucune continuation1040
n'est prévue. Une éventuelle admission ne qualifierait ni les champs locaux,
ni une indépendance générale du domaine, ni le refroidissement installé.

Conserver séparément l'ancien log natif40 pas complets plus début1001, le
nouveau log20 pas et leurs tables. Une vue d'analyse composée, si nécessaire,
doit être identifiée comme dérivée : retirer seulement le bloc1001 incomplet
de l'ancienne vue, contrôler l'égalité des mesures au checkpoint1000 avant
déduplication et conserver les SHA des deux sources. Ne jamais présenter cette
vue comme un log natif unique. Les futurs champs et maillages restent privés ;
seuls scripts originaux, paramètres et rapports expurgés sont publiables.

Vérification sans solveur : `make fan-program-check`. Cinq nouveaux tests
refusent notamment champ surfacique absent, pression non finie, temps mélangés,
pas supplémentaires et rejeu du témoin. Les résultats D2 initiaux, leur capsule,
leurs archives et les validations antérieures restent inchangés.

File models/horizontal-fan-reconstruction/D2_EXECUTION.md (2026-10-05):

# D2 : sortie prolongée, lot clos et comparaison inconclusive

**Témoin terminé ; sortie prolongée partielle ; ressources libérées.** Le
[protocole préparé](OUTLET_SENSITIVITY_PREPARATION.md) a été conservé : même rotor
V2, `SIMPLE.consistent yes`, extension 275 mm vers −Z, 50 couches uniformes de
5,5 mm, aucune augmentation de distance ou d'itérations après observation.
La [comparaison auditée](results/cfd/D2-partial-pair-analysis.json) refuse une
admission stationnaire de la paire. Aucun gain airflow, indépendance au domaine,
champ local qualifié ou validation installée n'est établi.

## Ce qui a effectivement été exécuté

Les cinq tests géométriques préalables passent : connectivité/volumes du cœur,
volume prismatique ajouté, flux, orientation, zones écrites et correspondances
des champs. Le contrôle des tables vectorielles natives et le refus d'une
fenêtre partielle portent ensuite la suite à sept tests, avec refus explicite d’une admission
partielle ou d’un champ manquant.

Le [mesher](source/append_outlet_prisms.py) ajoute 227 100 prismes : total
680 596 cellules contre 453 496. Le rotor, ses faces, les points et identifiants
du cœur, ses voisins et son appartenance MRF sont conservés. Volume ajouté
0,016591727271 m³, égal à aire de sortie × longueur ; minimum ajouté
4,37078e−8 m³. Écart maximal de volume dans le cœur : 6,35275e−22 m³.
Les [preuves de préparation](results/cfd/D2-mesh-preparation.json) relient les
hashes des maillages, des champs initiaux et des sélections privées.

**Les deux maillages passent les contrôles standard et étendus indépendants,
zéro échec, seuils inchangés** :
[témoin](results/cfd/D2-current-independent-mesh-gate.json) et
[prolongé](results/cfd/D2-extended-independent-mesh-gate.json).
Les [observables à 960](results/cfd/D2-seed-observables-verification.json),
calculées sans nouvelle itération, reproduisent les trois pressions de zones et
le débit orienté d'origine à la précision d'écriture. La syntaxe du fragment
functionObjects a été corrigée avant lancement : Foundation13 utilise
`faceZone` et `cellZone`, plutôt que `regionType/name`.

Une première préparation s'est arrêtée **avant toute itération CFD** : la valeur
`dataFile` de la décomposition manuelle exigeait une chaîne entre guillemets.
Ce [premier essai](results/runtime/D2-first-execution-receipt.json), sa capsule
et son archive sont conservés. La correction de syntaxe et l'en-tête
`faceZoneList` ont été gelés dans une deuxième capsule. Le timer original n'a
pas été réinitialisé. L'affectation manuelle est conforme au
[code Foundation13](https://raw.githubusercontent.com/OpenFOAM/OpenFOAM-13/master/src/parallel/decompose/decompositionMethods/manual/manual.C).

La partition originale du cœur sur quatre rangs est vérifiée exactement dans
les deux cas. Les colonnes appartiennent au rang propriétaire de leur ancienne
face de sortie. Les [comptes prolongés](results/cfd/D2-extended-partition-verification.json)
sont 122 709 / 167 115 / 208 232 / 182 540 cellules : cette conservation induit
un déséquilibre de charge, sans redistribution du cœur.

Le [runner](source/run_d2_in_container.py) exécute ensuite deux branches
séquentielles depuis le même état privé `consistent yes/960` :

| Cas | Itérations complètes | Tables natives avec état 960 | État final |
|---|---:|---:|---|
| Sortie actuelle | 60, 961–1020 | 61 lignes par table | `End`, champs complets, reconstruction 980/1000/1020 |
| Sortie prolongée | 40, 961–1000 | 41 lignes par table | 1001 commencée puis interrompue ; aucun `End` ni champ 1020 |

Le témoin coûte 118,731 s de solveur. La branche prolongée dispose réellement
de **159 s**, jusqu'à la réserve de clôture de la date limite originale ;
elle s'arrête proprement avec code timeout 124 après 160,030 s, signal/arrêt
compris. La limite de 300 s était un maximum, subordonné au timer global.
Aucune itération manquante n'est extrapolée ou ajoutée.

## Critères de stationnarité et écarts communs

Le [résumé témoin1020](results/cfd/D2-current1020-flow-summary.json) passe les
**dix critères originaux** ; la fenêtre 1001–1020 contient vingt mesures
consécutives. Ses **sept contrôles supplémentaires** passent aussi : débit et
pression de bande, différences entre fenêtres, RMS des champs 1000→1020.
La RMS volumique Δp vaut 0,28765 Pa, ΔU 0,04178 m/s. Cependant les maxima locaux
atteignent 122,284 Pa et 48,196 m/s : le passage des critères globaux ne
qualifie toujours pas les champs locaux.

La branche prolongée manque entièrement la fenêtre requise 1001–1020 et ses
champs finaux. À 981–1000, son résidu initial p maximal vaut **0,0277275** contre
le seuil 0,0001 ; U atteint 0,00409826 contre 0,00001, k 0,00797796 contre
0,0001. La pression de bande a un écart-type **11,795 Pa** contre 2 Pa, et sa
moyenne évolue de 138,957 à 97,745 Pa entre les deux fenêtres disponibles.
Elle reste numériquement non admise et non stationnaire selon les contrôles
prévus. Les résidus normalisés sur des domaines différents ne mesurent pas
un effet physique de domaine.

La seule comparaison appariée de vingt mesures disponible, **981–1000**, est
**descriptive** :

| Grandeur dans la zone commune | Sortie actuelle | Sortie prolongée | Écart |
|---|---:|---:|---:|
| Débit moyen orienté [m³/s] | 1,152299531 | 1,149390387 | −0,25246 % relatif symétrique |
| Couple moyen fluide sur rotor [N·m] | −3,867153957 | −3,842874987 | 0,62783 % en valeur absolue |
| Pression statique moyenne volumique [Pa] | 85,644954 | 97,744930 | +12,099976 Pa |

La puissance suit la même variation relative que le couple au régime fixe.
La pression est celle des **mêmes 5 825 cellules**, pas une élévation entre
ports. L'écart de pression dépasse la bande de screening 5 Pa ; toutefois les
prérequis de stationnarité de la paire échouent. Les gates de comparaison du
domaine **ne sont donc pas évalués comme une admission**.

Les champs réellement sauvegardés à 1000 montrent une RMS commune Δp
38,337 Pa et ΔU 1,284 m/s, maximum Δp 514,162 Pa. Ces différences décrivent
un état itératif non convergé ; elles ne donnent pas un effet stationnaire
qualifié de la sortie ni une incertitude expérimentale.

Traces natives : témoin60 et branche prolongée40

Le [script](source/plot_d2_native_trace.py) et ses
[hashes de provenance](results/cfd/D2-native-traces.json) conservent tous les
points réellement complets. L'axe représente des itérations stationnaires,
sans fréquence ou durée physique ; aucune courbe prolongée après 1000.

## Reflux réellement conservé à 1000

Les champs MPI1000 prolongés sont relus par leurs identifiants globaux,
sans solveur ou `reconstructPar` supplémentaire. Les cinq champs couvrent
680 596 cellules, chacune exactement une fois. Les 4 542 faces du plan commun
sont couvertes une fois et leur phi retrouve la somme native du functionObject.

| Emplacement à l'état sauvegardé 1000 | Débit net [m³/s] | Reflux brut [m³/s] | Reflux / net |
|---|---:|---:|---:|
| Témoin, plan de sortie actuel | 1,152299642 | 0,123988412 | 10,7601 % |
| Prolongé, même plan devenu interne | 1,151545816 | 0,104273570 | 9,0551 % |
| Prolongé, frontière éloignée | 1,151530127 | 0,129404559 | 11,2376 % |

Le déplacement n'a pas éliminé le reflux dans l'état disponible. Ce seul
prolongement, partiel, ne prouve ni distance suffisante ni indépendance au
domaine. Le buffer à section constante avec côtés `slip` conserve confinement
et mélange ; il ne représente pas un plénum moteur mesuré.

## Clôture, conservation et reproduction

Limites vérifiées : **4 CPU, RAM + swap 5 GiB, réseau absent, sources privées en
lecture seule**. [Temps global natif](results/runtime/D2-native-archive-verification.json)
**627,669 s**, première préparation, correction sous timer original,
reprises, arrêt, audit et archivage inclus, sous 720 s. Le conteneur est libéré
à **20:09:21 UTC** ; les [services préexistants sont inchangés](results/runtime/D2-release-confirmation.json).
Aucun nouveau calcul, installation, accès persistant ou modification de service.

Archive finale privée : 99 membres vérifiés, 189 782 229 octets ; archive du
premier essai également transférée et vérifiée. Les tableaux complets, maillages
et champs restent privés. Le launcher exclut les répliques `processor*` de son
archive ; les champs1000 prolongés et leurs correspondances ont donc été
récupérés **séparément après libération** comme simple conservation des fichiers,
sans nouvelle phase native. Le [certificat complémentaire](results/runtime/D2-partial1000-preservation-verification.json)
couvre 44 fichiers privés vérifiés. Leur assemblage par identifiants sert au
diagnostic1000 ; il ne reconstitue pas le checkpoint1020 absent.

Les [capsules exactes](parameters/D2-executed-capsule-manifest.json) et
[première préparation](parameters/D2-first-preparation-capsule-manifest.json)
sont conservées avec configs et sources gelées. L'analyse complète de la paire
n'a jamais été atteinte ; la lecture des tables vectorielles de forces a ensuite
été corrigée et testée dans le helper courant, sans modifier la capsule exécutée.
L'analyse du lot partiel utilise [un script distinct](source/analyze_d2_partial_result.py).

Vérification sans solveur : `make fan-program-check`. Reproduction des
statistiques/figures : mêmes scripts avec archives natives privées extraites.
Le launcher exige une coordination explicite ; il ne doit pas être relancé
avec la date limite originale expirée. **Aucune continuation n'est autorisée
ou engagée par ce rapport.** Une éventuelle nouvelle étude exigerait un budget
et un protocole définis avant calcul. Identité 935/993, interfaces installées,
compressibilité, parois, fatigue et validation physique restent ouvertes.

Suivi : les checkpoints natifs980 et1000 sont désormais audités et une
[complétion fixe de vingt pas](D2_COMPLETION_PREPARATION.md) est préparée.
Elle n'a lancé aucun solveur et ne modifie pas les résultats de ce lot clos.

Suivi ultérieur : après accord explicite, la
[reprise unique1001–1020 a terminé](D2_COMPLETION_EXECUTION.md) en110,505 s,
archivage et libération compris. La fenêtre manquante existe maintenant mais
la pression reste non admise ; la comparaison demeure inconclusive. Les
résultats partiels et la capsule du premier lot restent conservés.

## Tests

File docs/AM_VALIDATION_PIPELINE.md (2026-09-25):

# Mandatory metal printing and Omniverse pipeline

## Repository rule

Every record in `catalog/parts/*.json` that proposes `LPBF` or `DMLS` must be
tracked by
[`am-validation-policy.json`](../catalog/manufacturing/am-validation-policy.json).
The check is automatic: adding a new additive part without registering it makes
`make validate` and `make check` fail.

A part can only reach `released` if every mandatory step is `passed`.
`completed_screening` means that a numerical computation was run, but that an
input, a correlation or a review is still missing to make it manufacturing
evidence.

```mermaid
flowchart LR
    A[Sources and measurements] --> B[BREP CAD and meshing]
    B --> C[Full slicing and supports]
    C --> D[Material-machine-process map]
    D --> E[Local melt pool]
    E --> F[Full-build thermomechanics]
    F --> G[Recoater and support removal]
    G --> H[Omniverse SimReady asset]
    H --> I[Omniverse functional assembly]
    I --> J[Coupons, CT, metrology and tests]
    J --> K[Signed engineering review]
```

How the step statuses gate release (fail-closed):

```mermaid
flowchart TD
    N["Record proposes LPBF or DMLS"] --> RG{"Tracked by<br/>am-validation-policy.json?"}
    RG -- no --> RF["make validate and<br/>make check fail"]:::stop
    RG -- yes --> S["Eleven mandatory steps,<br/>01 to 11"]
    S --> Q{"Every step passed?"}
    Q -- "a step is completed_screening" --> CS["Computation run; input, correlation<br/>or review still missing:<br/>never counts as passed"]:::open
    Q -- "a step is blocked_missing_input" --> BL["Blocked: missing input"]:::stop
    CS --> NR["Cannot reach released"]:::stop
    BL --> NR
    Q -- "all eleven passed" --> OK["released possible: step 11,<br/>signed review of a specific revision,<br/>explicitly bounded authorization"]:::ok
    classDef stop fill:#fde2e1,stroke:#c0392b,color:#1a1a1a;
    classDef ok fill:#e3f1e6,stroke:#2e7d32,color:#1a1a1a;
    classDef open fill:#fff4d6,stroke:#b7791f,color:#1a1a1a;
```

## The eleven steps

| Step | Computation or evidence | Exit gate |
|---|---|---|
| 01 | provenance, variant, measurements, assumptions and SHA-256 | geometric authority approved |
| 02 | editable master, STEP/BREP, watertight mesh and scale | geometric integrity |
| 03 | cross-section of every layer, islands, overhangs, supports and depowdering | geometrically printable design |
| 04 | alloy, powder, machine, orientation, parameters, treatments and properties `f(T)` | consistent process route |
| 05 | AdditiveFOAM or equivalent solver, space/time convergence, coupons | correlated melt pool |
| 06 | layer activation, build plate, supports, plasticity, stress relief and distortion | converged deformed shape |
| 07 | recoater collision and access for support removal | mechanically feasible build |
| 08 | OpenUSD, `nvidia_usd_validate`, Geometry, Physics, SimReady profile and OVRTX render | compliant Omniverse asset |
| 09 | interfaces, tolerances, contacts, motion, loads and defects in the assembly | digital function verified |
| 10 | coupons, first article, CT/NDT, metrology, fatigue and correlation | model tied to reality |
| 11 | signed professional review of a specific revision | explicitly bounded authorization |

PhysicsNeMo only comes in after converged and correlated sets of reference
computations have been built. It is an accelerating surrogate, not a step
able to authorize a part on its own. The Material and Physics Agents
may propose USD metadata; every physical property must stay
sourced or be removed before validation.

## First pass: CP1 F0 piston

The synthetic piston is the first 993 object run through this chain. The
mesh derived from the STEP has `136,988` vertices and `273,988` triangles; it
is watertight, single-body and keeps the `99 × 99 × 70 mm` envelope.

The full-part screening actually intersected the mesh at every `50 µm`
layer. The candidate orientation `roll_y_45` gives:

| Result | Value |
|---|---:|
| build height | 119.500 mm |
| computed layers | 2,390 |
| empty internal layers | 0 |
| new islands | 4 |
| layers with an unsupported region | 759 |
| maximum unsupported region | 4.898 mm² |
| conservative support envelope | 8.365 cm³ |
| local thickness p01, 2,000-point screen | 0.420 mm |
| fraction of points under 1.5 mm | 6.25% |
| trapped void detected at 1 mm voxel | 0 mm³ |

The bare part fits in the nominal envelope of the standard Sapphire. This
orientation is not yet a DfAM decision: Velo3D Flow supports, machining
allowances, shrinkage, CT and the machine file are not available. The detailed
result and the per-layer metrics are in
[`evidence/lpbf-f0`](../twins/993-m64-60-piston-gallery-f0/evidence/lpbf-f0/).

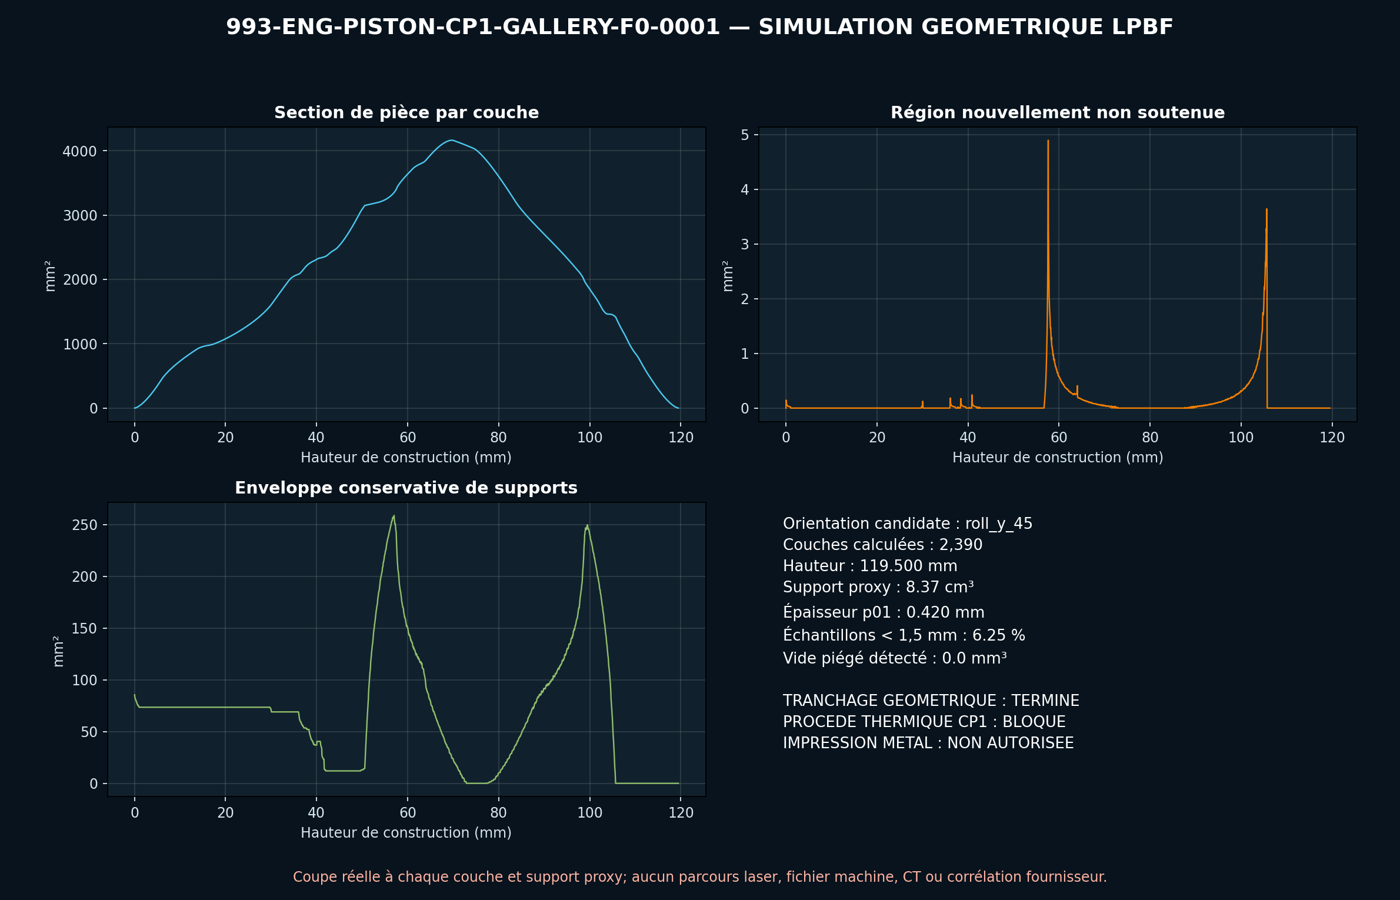
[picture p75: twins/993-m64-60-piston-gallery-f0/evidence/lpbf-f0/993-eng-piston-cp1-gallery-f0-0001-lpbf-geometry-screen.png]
LPBF geometric simulation of the piston


The same STEP separately passes NVIDIA Asset Validator, Geometry, Physics and
the `Prop-Robotics-Neutral 1.0.0` profile. The friction and restitution
coefficients and the gravity proposed without a source by the Physics Agent
were removed before the final pass. The public folder is
[`evidence/simready-f0`](../twins/993-m64-60-piston-gallery-f0/evidence/simready-f0/).

A second Omniverse scene runs the build preparation: it places the piston in
`roll_y_45`, brings it into contact with the build plate and checks its
envelope against the nominal `Ø315 × 400 mm` volume. This scene passes
OpenUSD minimum, NVIDIA Asset Validator, Geometry and Physics; its render was
inspected. The animated recoater remains a guide with no computed collision,
because no calibrated CP1 deformed shape nor supplier support geometry is
available yet.

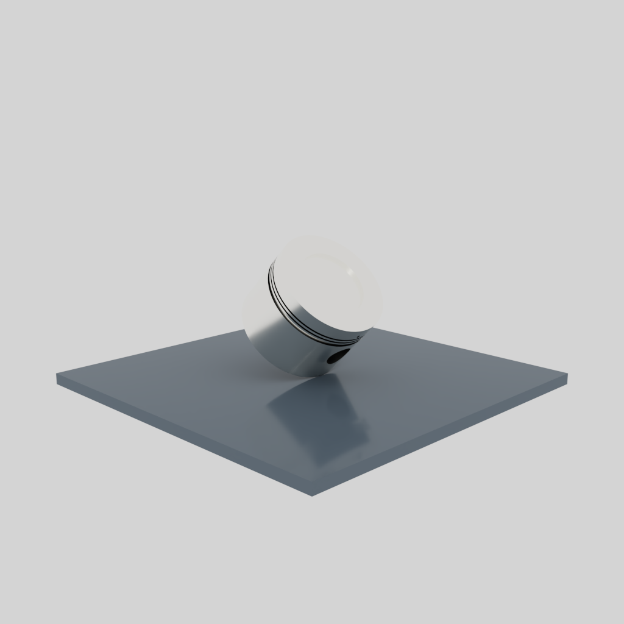
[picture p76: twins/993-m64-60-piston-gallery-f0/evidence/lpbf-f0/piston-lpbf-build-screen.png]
Omniverse LPBF preparation


### Piston generative optimization gate

PicoGK 2.3.0 actually generated six F0 variants. The sweep looks for a low
mass and a gallery more favorable to cooling, but imposes a provisional
room-temperature plate margin of `1.50`. The best gross weight reduction is
`1.60%`; no variant passes the margin. The downstream audit also finds
non-manifold edges in every PicoGK STL.

This sub-gate links steps 01, 02, 04 and 09: sourced objectives and keep-outs,
manifold geometry, hot CP1 map and engine function. It does not create a
twelfth step and does not change the currently validated BREP master. The
PicoGK outputs stay quarantined until BREP reconstruction, FEA/CHT/CFD and a
new full LPBF/Omniverse pass.

### Piston master thermomechanical gate

The sound BREP master has now gone through six CalculiX 2.21 solves: cold
static and sequential temperature–displacement on three C3D10 meshes. At
`2.5 mm`, the model has `139,924` nodes and `81,861` elements. The cold and hot
p95 are `112.17` and `323.46 MPa` respectively; the maximum temperature of the
hot case is `187.04 °C`. The fine/previous variations stay under `3%`.

The case imposes `5 kW` on the crown, ideal sinks of `120 °C` in the gallery
and `160 °C` on the skirt, plus the synthetic axial load. It is therefore a
conservative comparative screen, not an engine CHT. Its hot p95 ratio against
the room-temperature CP1 reference is unfavorable (`0.918`) and blocks the F0.
The PicoGK variants are not simulated as long as their meshes are not manifold.

The evidence is in
[`evidence/calculix-f0`](../twins/993-m64-60-piston-gallery-f0/evidence/calculix-f0/).

## Why the CP1 process thermal simulation stays blocked

The Velo3D datasheet documents the Sapphire `50 µm` route, the density and
room-temperature mechanical properties after `400 °C / 4 h`. It does not
publish the temperature-dependent thermophysical and constitutive map nor the
laser strategy needed for a representative AdditiveFOAM computation. The
official EOS page now provides two TRL 3 CP1 `60 µm` routes and a few
additional properties, but states that the process must be requested from
EOS; it is not the piston's Sapphire route and it still does not provide a
complete solver map.

Consequently:

- no AlSi10Mg computation is transferred to CP1;
- the F0 part thermal field is published only as an explicitly uncorrelated
  synthetic envelope;
- full-build thermomechanics and the recoater stay
  `blocked_missing_input`;
- metal printing and engine use remain prohibited.

Primary references: [Velo3D CP1 / Sapphire 50 et 100 µm](https://velo3d.com/wp-content/uploads/2025/04/Velo3D-Material-Datasheet-Aluminum-CP1.pdf),
[EOS Aluminium Constellium CP1](https://www.eos.info/metal-solutions/data-sheets/all-processes-and-materials?id=eos-aluminium-constellium-cp1).

## Second pass: F0 IN625 oval nozzle

The second object is a double-wall round-to-oval exhaust tip. Only its
commercial `120 × 85 mm` outlet is published; the length, the inlet, the walls
and the fasteners stay synthetic. The STEP forms a single-body BREP of
`48,149.34 mm³`, i.e. `406.38 g` with the selected IN625 density.

The `roll_y_25` orientation was sliced into `3,702` layers of `40 µm`:
zero empty internal layers, one new island, `784` layers with an unsupported
area, `0.843 mm²` at most and `7.194 cm³` of conservative supports. The
thickness check finds `0.636 mm` at the 1st percentile and all 2,000 probes
under `1.5 mm`; this result is consistent with the very thin nominal double
wall and remains a capability warning.

The Omniverse scene places the part in the nominal EOS M 290 envelope
`250 × 250 × 325 mm`. The scene and the isolated asset pass OpenUSD minimum,
NVIDIA Asset Validator, Geometry and Physics; the asset also passes the
`Prop-Robotics-Neutral 1.0.0` profile. The friction, restitution, gravity and
stainless-steel identity proposed without a source by the agents were removed.

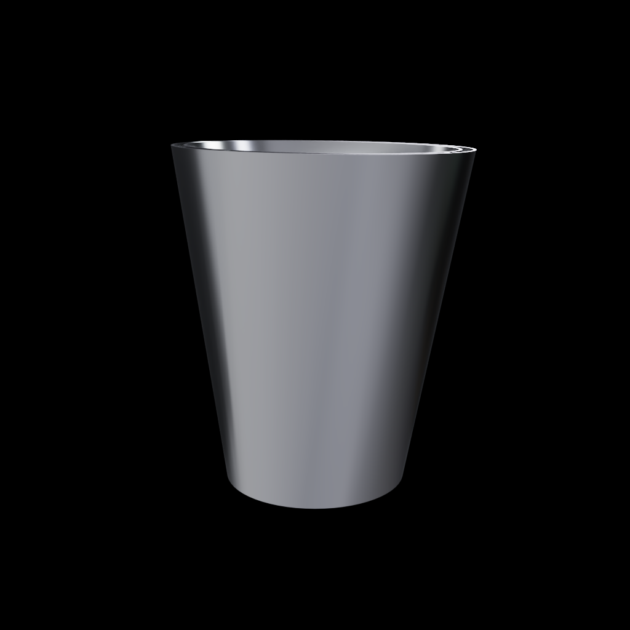
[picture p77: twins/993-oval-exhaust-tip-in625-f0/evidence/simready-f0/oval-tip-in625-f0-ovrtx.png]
SimReady IN625 nozzle


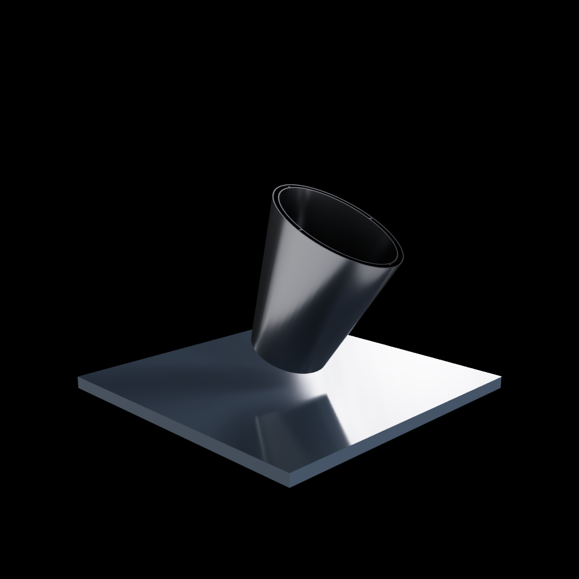
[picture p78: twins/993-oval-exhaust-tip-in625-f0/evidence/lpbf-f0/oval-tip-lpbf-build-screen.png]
EOS M 290 LPBF preparation


The OpenFOAM CFD is diagnostic only: the three steady cases are converged in
residuals, but the pressure loss still varies by `11.17%` between the two
finest meshes and the extended checks keep low-determinant cells. No melt pool,
distortion, recoater collision, vehicle assembly or thermal fatigue
computation passes. PhysicsNeMo only ran a CUDA smoke, with no trained
surrogate.

## Third pass: F0 AlSi10Mg headlamp spring hook

The third object is a small repair hook. The commercial offer confirms that
this function is already made by metal 3D printing, but publishes no
dimension. The `16 × 8 × 15 mm` F0 is therefore an independent concept of
`881 mm³`, i.e. `2.352 g` with the selected EOS AlSi10Mg density.

The `roll_y_45` orientation is sliced into `425` layers of `30 µm`. The
mesh is watertight and single-body; the conservative support proxy is
`3.06 mm³`. Only one layer contains an unsupported region, of
`0.446 mm²`. No closed pocket is detected at the `0.25 mm` voxel.

Six CalculiX 2.21 computations were actually run: cold and steady
thermomechanical on three C3D10 meshes. On the fine mesh of `22,415` nodes,
the p95 is `10.786 MPa` cold and `141.898 MPa` for the synthetic
`80–180 °C` field. The hot maximum of `303.467 MPa` and the absence of a hot
part strength prohibit any favorable conclusion.

The STEP is then converted by `usd-convert-cad 0.2.0`. The binary asset and the
rigid scene pass `nvidia_usd_validate 1.21.0` with no failing rule. Finally,
`ovstage 0.1.1.355824` and `ovphysx 0.5.11` run `240` CPU steps: a test sphere
drops from `22` to `17 mm` and settles on the hook. This synthetic contact only
verifies software integration; the real spring, headlamp and adhesive are
absent.

Step 08 therefore stays `completed_screening`, not `passed`: the full SimReady
profile and the OVRTX render of this revision are missing. Steps 05 to 07 and
09 to 11 stay blocked. See
[the hook technical dossier](993/993_HEADLAMP_SPRING_HOOK_ALSI10MG_F0.md).

## Fourth pass: F0 AlSi10Mg interior door lever

The lever is selected as a small LPBF candidate because the concept
consolidates a perforated plate, a bridge and a clevis. PorscheFanatics
provides the PET references and FVD only a `108 × 45 × 27 mm` envelope and a
pair mass of `180 g`: all interfaces therefore stay hypothetical.

The reproducible normalized STEP and its watertight STL are linked by digest.
The candidate orientation `roll_y_45` is sliced into `2,664` layers of
`30 µm`; the support proxy is `2,714.4975 mm³`, the p01 thickness `2 mm` and
no trapped void is detected at the `0.75 mm` voxel.

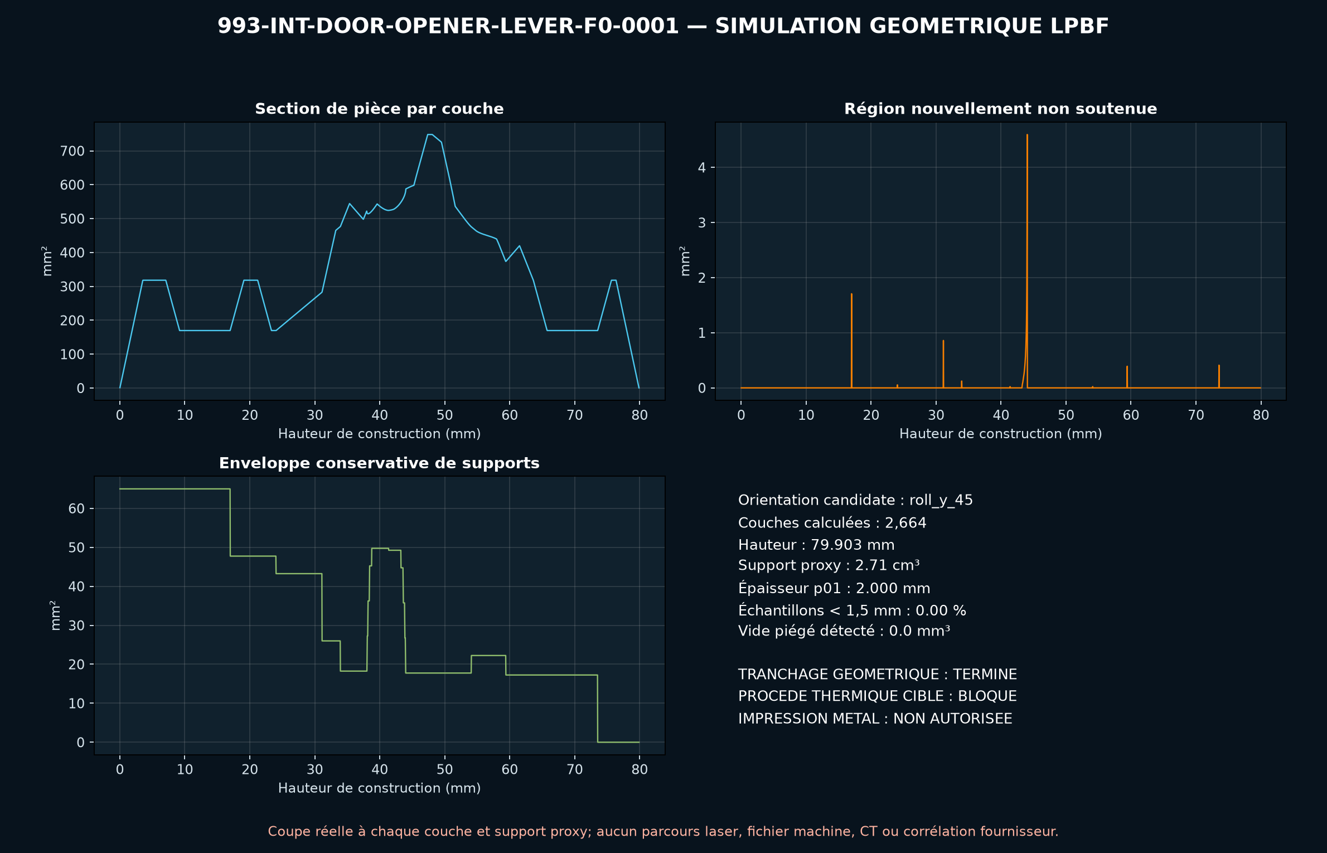
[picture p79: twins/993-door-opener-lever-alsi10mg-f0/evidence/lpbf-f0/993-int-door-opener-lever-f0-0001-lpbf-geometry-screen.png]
LPBF geometric screening of the F0 door lever: section per layer, newly unsupported region, conservative support envelope, 2,664 layers


*Step 03 screening of the lever in `roll_y_45`: real cross-section at every layer and a proxy support envelope. It has no laser path, machine file, CT or supplier correlation, and does not authorize metal printing.*

CalculiX 2.21 runs six cold/hot cases on three C3D10 meshes. On the fine mesh
of `31,666` nodes, the p95 is `45.227 MPa` cold and `46.546 MPa` in the
synthetic `20–80 °C` field. The p95 variation between the last two meshes is
`1.143%` and `0.276%`. The Goodman proxy produces no fatigue life and does not
transfer the EOS coupons to the handle.

The CAD-to-SimReady preflight stops the Material/Physics assignment for lack
of an active instance. Separately, the asset and the scene pass minimal USD
validation; `ovstage`/`ovphysx` run `240` steps and settle the test body from
`35` to `29 mm`. Step 08 stays `completed_screening`, while steps
05 to 07 and 09 to 11 stay blocked. See
[the lever technical dossier](993/993_DOOR_OPENER_LEVER_ALSI10MG_F0.md).

## Reproduction

The generic program can be applied to any part once a watertight computation
mesh has been generated:

```bash
python3 scripts/run_metal_am_geometry_screen.py \
  --part-id 993-ENG-PISTON-CP1-GALLERY-F0-0001 \
  --master parts/993-eng-piston-cp1-gallery-f0-0001/derived/piston_cp1_gallery_f0.step \
  --master-sha256 <sha256-step> \
  --surface <private-or-derived-stl-mesh> \
  --surface-sha256 <sha256-stl> \
  --machine-card catalog/manufacturing/machines/velo3d-sapphire-standard.json \
  --material "Aheadd CP1 / Sapphire 50 um candidate" \
  --expected-envelope-mm 99 99 70 \
  --output work/piston-lpbf
```

## First step 04: the switch trim ring

The ring `993-INT-SWITCH-TRIM-RING-F1-0001` is the first part in the
repository taken to step 04. The generator `scripts/build_process_route_card.py`
is generic: it takes a part record, a geometric screening report, a machine
card and a process card, and it writes a route card plus a request-for-quote
package linked to the files by SHA-256.

It immediately found an internal inconsistency: the step 03 screening slices
at 50 µm while the only published AlSi10Mg route on the EOS M 290 is at
30 µm. Full details in
[`docs/993/993_SWITCH_TRIM_RING_F1.md`](993/993_SWITCH_TRIM_RING_F1.md).

```bash
make route-trim-ring
make route-trim-ring-check
```

The universal check, with no CAE dependency, runs anywhere:

```bash
python3 scripts/validate_am_pipeline.py
```

As of September 8, 2026, it automatically tracks `25` LPBF/DMLS candidate
parts. A virtual success never replaces physical correlation nor
engineering review.

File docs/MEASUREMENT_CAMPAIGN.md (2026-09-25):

# Measurement campaign — phase 2

## State

The three polymer pilots are prepared, but no physical measurement session is
recorded in `catalog/measurements/` yet. The register now contains a separate
record of documentary specifications from the Porsche manual, which does not
replace an instrumented campaign. The repository has no access to a 993, to a
removed part or to an instrument: this document is therefore a handover dossier
for an outside contributor. It contains no invented dimension.

## Work order

| Priority | Part | Minimal method | Expected deliverable |
|---:|---|---|---|
| 1 | `993-INT-SWITCH-BLANK-0001` | Caliper and radius gauge | Seven dimensions D01–D07, three repeats, photo of the reference marks, JSON record |
| 2 | `993-INT-SEAT-RAIL-COVER-0001` | Caliper, depth gauge | Dimensions D01–D05 on both sides, check of the symmetry assumption, JSON record |
| 3 | `993-INT-DOOR-PULL-0001` | Caliper and scaled photogrammetry | Five interface dimensions, photos with a scale bar, manifest and JSON record |
| 4 | `993-INT-DASHBOARD-TRIM-0001` | Reading of the option code, then scaled photogrammetry and caliper | Evidence that no passenger airbag is fitted, fourteen dimensions in place **and** removed, three weighings, mesh and manifest |

The detailed plans are in the `parts/<part_id>/evidence/` directory. Priority 1
is the best first trial: the part is non-critical and its master geometry
already exists in `parts/993-int-switch-blank-0001/source/switch_blank.py`.

Priority 4 is of a different nature from the first three: it is a 1.4 m
freeform surface, and above all the only one whose measurement starts with an
**entry gate that can stop everything**. The dashboard trim can be measured only
on a vehicle without a passenger airbag; on an M562 car it carries the
deployment flap, and is therefore an occupant-restraint part. The plan has the
contributor read the option label before taking out an instrument.

## Contributor prerequisites

- Identify the vehicle's variant, model year and equipment without recording a
  chassis number, a license plate or any personal data.
- Photograph the part and its surroundings before removal, then identify the
  surfaces and axes with the same reference marks as in the measurement record.
- Declare the model, resolution, interface and calibration state of each
  instrument.
- Use at least three readings per critical dimension. A value typed in by hand
  stays `manual_entry`; it must never be presented as an instrumented stream.
- Keep raw images and point clouds out of the repository when they contain a
  vehicle identifier or data whose rights are not established. Submit only
  authorized, anonymized evidence.

## Session procedure

1. Copy `catalog/templates/measurement-record.json` to
   `catalog/measurements/MEAS-<PART>-<DATE>.json` and fill in the subject before
   any reading.
2. Check the zero and the instrument on a gauge block, a pin gauge or a known
   reference; record the actual status, not an assumed one.
3. Define the origin, the axes and the reference planes. The reference marks
   must stay identifiable in the photos and in the CAD.
4. Measure the interfaces before the decorative surfaces. Repeat each dimension
   without trying to make the values converge artificially.
5. Photograph the fasteners, clearances, bearing surfaces and contradictions.
   For the door pull, place a certified scale bar in every shot.
6. Enter the raw readings, compute the value from their samples, then record
   the uncertainty and its basis (`repeatability`, `instrument_resolution` or
   `combined`).
7. Run `make check`. If a measurement does not pass the validator, correct the
   transcription or the method; do not adjust the value to make the check pass.

```mermaid
flowchart TD
    G{"Priority 4 only:<br/>passenger airbag fitted (M562)?"}
    G -- yes --> GX["Dashboard trim cannot be measured:<br/>occupant-restraint part"]:::stop
    G -- no --> S1
    S1["1 · Copy the measurement template,<br/>fill in the subject"] --> S2["2 · Check zero on a gauge block<br/>or known reference"]
    S2 --> S3["3 · Define origin, axes<br/>and reference planes"]
    S3 --> S4["4 · Interfaces before decorative<br/>surfaces; repeat each dimension"]
    S4 --> S5["5 · Photograph fasteners, clearances,<br/>bearing surfaces, contradictions"]
    S5 --> S6["6 · Raw readings → value from samples<br/>→ uncertainty and its basis"]
    S6 --> S7{"7 · make check"}
    S7 -- fails --> FIX["Correct the transcription or method,<br/>never the value"]:::open
    FIX --> S6
    S7 -- passes --> R["Record stays concept until the<br/>session is complete and reviewed"]:::open
    classDef stop fill:#fde2e1,stroke:#c0392b,color:#1a1a1a;
    classDef ok fill:#e3f1e6,stroke:#2e7d32,color:#1a1a1a;
    classDef open fill:#fff4d6,stroke:#b7791f,color:#1a1a1a;
```

## Decision gate

A part record stays `concept` until the session is complete and reviewed.
Moving to `dimensionally_reviewed` requires the critical dimensions, the
evidence files, the variant and a CAD review. Fitting a prototype is a separate
step: the clearances, photos and deviations will then have to be recorded before
any `prototype_fitted` status.

The three pilots are trim parts, but the door pull takes repeated manual loads.
No material, setting or geometry may be called safe or durable on the sole basis
of a good static fit.

## Optional CT brief

CT is not needed for the switch blank. It may be considered for the door pull if
the hidden interfaces are not accessible after removal, or for a polymer part
with internal channels. The records `SRC-HACHTEL-BASIC-CT-SCAN`,
`SRC-BMB-GERMANY-CT-RE` and `SRC-VISION-METRIC-CT-DIGITIZATION` are service
leads, not existing 993 measurements.

Any request must require:

- variant and part number;
- covered volume, resolution/voxel size and stated uncertainty;
- reference marks, scale, orientation and handling of hidden surfaces;
- raw volume or delivered format, segmentation, mesh and optional STEP;
- comparison between at least three interface dimensions and the manual
  measurement;
- rights to use and redistribute the delivered files;
- a prohibition on concluding the accuracy of a safety part from the scan alone.

A CT order or a part purchase requires separate approval by the maintainer. No
external spending or acquisition is presumed by this repository.

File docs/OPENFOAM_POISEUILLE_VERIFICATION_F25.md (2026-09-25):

# OpenFOAM verification by Poiseuille — F25

## Purpose

F25 only verifies that the OpenFOAM tool in the pinned CFD image can
mesh, solve and post-process a synthetic analytical problem. This milestone
is independent of the 917 F13 solver cases and of the PhysicsNeMo F14 dataset.
It is neither an engine simulation, nor a design validation, nor a
manufacturing authorization.

The redacted contract is
`outils/benchmarks/openfoam-poiseuille-f25/benchmark-contract-f25.json`. It
contains no absolute local path, no machine or user identity, no secret and no
vehicle identifier.

## Analytical case

The case is a plane channel between two stationary plates, periodic in the
flow direction and extruded over one cell. A constant body acceleration `a_x`
drives the incompressible laminar flow. The conditions and properties are
entirely synthetic:

- length `L = 0.1 m`, height `H = 0.02 m`, depth `b = 0.01 m`;
- kinematic viscosity `nu = 1e-5 m²/s`;
- acceleration `a_x = 0.01 m/s²`;
- analytical mean velocity `0.03333333333333333 m/s`;
- Reynolds number based on `H` equal to `66.66666666666666`;
- reference density `1.2 kg/m³`, used only to convert the volumetric flow rate
  into a mass metric, never by the incompressible solver.

For `y` measured from the mid-plane:

```text
u(y) = a_x / (2 nu) * (H² / 4 - y²)
Q    = a_x * b * H³ / (12 nu)
```

The uniform meshes have 8, 16 and 32 cells across the height respectively. A
single periodic cell in length and a single empty cell in depth suffice,
because the solution is fully developed and invariant in those directions.

## Evidence chain

```mermaid
flowchart LR
    C[Redacted F25 contract] --> G[Generator]
    D[Tracked OpenFOAM decks] --> G
    G --> M1[Mesh 8]
    G --> M2[Mesh 16]
    G --> M3[Mesh 32]
    I[GHCR image pinned by digest] --> S[blockMesh + checkMesh + simpleFoam]
    M1 --> S
    M2 --> S
    M3 --> S
    S --> A[Analytical profile + mass + L2/Linf]
    A --> R[Two repeats + observed order]
    R --> P[local report.json]
    P -. does not promote .-> F13[F13 engine case]
    P -. does not produce .-> F14[PhysicsNeMo F14 sample]
    P -. does not open .-> FAB[Manufacturing or vehicle gate]
```

In OpenFOAM 13, the legacy `simpleFoam` command present in the image is
a wrapper around `foamRun -solver incompressibleFluid`. The report requires
this delegation, the version 13 banner and build 13 to appear in every solver
log. The problem is linear, fully developed and without axial convection: a
single SIMPLE correction is enough to solve the system from the zero field.
Extending it would needlessly reinject the numerical noise of the
pressure-velocity coupling into an entirely periodic domain.

The asymmetric velocity system uses `PBiCGStab` with `DILU`
preconditioning. The `1e-8` threshold applies explicitly to the final residual
of `Ux` and the `1e-12` threshold to that of `p`; the residuals and iteration
counts of `Ux`, `Uy` and `p` are all kept in the evidence and included in the
repeatability comparison. The contract does not impose a universal iteration
count: the local report must therefore always be read for this point.

## Metrics and criteria

Each repeat produces, for the three meshes:

- `checkMesh` result and expected cell count;
- flow-rate antisymmetry between the two periodic faces;
- dimensionless local continuity error as reported by OpenFOAM,
  i.e. `deltaT × volume_average(|div(phi)|)`;
- mass flow rate computed with the synthetic reference density;
- axial velocity errors `L2` and `Linf`, absolute and relative;
- maximum transverse velocity;
- observed order between 8→16 then 16→32 cells.

For the `N` uniform cell centers, with
`e_i = Ux_i - u_analytique(y_i)`, the analyzer uses:

```text
L2_abs  = sqrt(sum(e_i²) / N)
L2_rel  = L2_abs / sqrt(sum(u_analytique(y_i)²) / N)
Linf_abs = max(|e_i|)
Linf_rel = Linf_abs / max(|u_analytique(y_i)|)
ordre    = log(erreur_h / erreur_h/2) / log(2)
```

(`u_analytique` is the analytical velocity, `ordre` the observed order and
`erreur` the error; the symbol names are kept as used by the analyzer.)

This discrete `L2` norm is equivalent to a volume weighting here,
because all cells of a mesh have the same volume.

The global report is only `passed` if:

- the six meshes pass `checkMesh` and the six solver runs complete;
- the final linear residual of `Ux` stays less than or equal to `1e-8` and
  that of `p` less than or equal to `1e-12`;
- the relative antisymmetry defect of the cyclic faces stays less than or
  equal to `1e-10`; this pair check is not independent evidence of local
  continuity;
- the dimensionless local sum of the continuity error reported by
  OpenFOAM (`deltaT × volume-weighted average of |div(phi)|`) stays
  less than or equal to `1e-12`;
- on the fine mesh, the relative flow-rate, `L2` and `Linf` errors stay
  less than or equal to `0.002`;
- the observed `L2` and `Linf` orders lie between `1.8` and `2.2`;
- the two repeats have exactly the same canonical SHA-256 over all compared
  metrics, including residuals, iterations and completion flags.

The maximum absolute and relative differences stay published as
diagnostics. The absolute difference deliberately aggregates quantities with
different units and must therefore not be interpreted as a physical norm; the
strict canonical hash is the acceptance authority for repeatability.

The aggregator does not trust the `report_status` field of the repeats
alone. It revalidates their shape, the meshes, the gates, the `Ux` residual,
continuity and the fine-mesh thresholds, then recomputes the observed orders
before producing the limited tool-verification claim. A missing, non-finite or
altered metric closes the global report.

These thresholds verify the expected convergence of the scheme on this
specific case. They qualify no material, duct, seal, component or engine
operating point.

## Local execution

The image is imposed by immutable reference:

```text
ghcr.io/cluster2600/3dprinting993-mesh-cfd@sha256:a1db60cbf61bbcca52c171e50cab01ed0b6ec860b227e7c5fc50f7b809659b4f
```

From the repository root:

```bash
outils/benchmarks/openfoam-poiseuille-f25/run_local.sh
```

The runner refuses to overwrite an existing output, imposes `linux/amd64`,
disables the container network and only accepts a destination under `work/`.
Each container mounts only the case it processes, with the following
protections:

- read-only root file system;
- host user UID/GID, `HOME=/tmp` and `/tmp` as a limited `tmpfs`;
- all capabilities dropped, `no-new-privileges` and 128 processes at
  most.

An alternative path can be given, also under `work/`:

```bash
outils/benchmarks/openfoam-poiseuille-f25/run_local.sh work/openfoam-poiseuille-f25-run-02
```

The detailed evidence stays local:

```text
work/openfoam-poiseuille-f25/
├── container-image.json
├── repeat-1/
│   ├── cases/{coarse,medium,fine}/
│   └── metrics.json
├── repeat-2/
│   ├── cases/{coarse,medium,fine}/
│   └── metrics.json
└── report.json
```

The OpenFOAM time directories, `U`, `p`, `C` fields, `polyMesh` meshes,
logs and post-processing are therefore under `work/`, a directory ignored by
Git. The repository only tracks the contract, the generator, the analyzer, the
input decks, the runner, this documentation and the tests.

The historical `mesh-cfd` image remains a broad image, built and used by
default as `root` in other paths of the repository. F25 does not fix this
image debt: it confines its own launch with the host user, a read-only root,
one mount per case and reduced privileges. A future minimal non-root image
would be a separate improvement, without changing the numerical scope of this
benchmark.

## Limits and gates

Even with a `report.json` in the `passed` state, only one assertion becomes
possible: the pinned image reproduced this synthetic benchmark within the
contract tolerances. The following gates stay explicitly closed:

- promotion of an F13 case;
- creation of a PhysicsNeMo F14 sample;
- any 917 engine simulation or validation claim;
- design freeze;
- manufacturing;
- vehicle use.

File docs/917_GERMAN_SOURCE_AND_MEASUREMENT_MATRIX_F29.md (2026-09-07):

# F29 — sources allemandes et matrice de mesures du moteur Porsche 917

## Objet et frontière d'autorité

Cette note transforme la recherche germanophone en une matrice exploitable pour
la réingénierie du moteur Porsche 917. Elle couvre les données dimensionnelles,
fonctionnelles et matérielles publiquement accessibles pour les moteurs Type 912
atmosphériques et le 917/30 biturbo. Elle indique aussi, champ par champ, ce qui
doit encore être obtenu par dessin autorisé, métrologie ou essai.

Les valeurs ci-dessous sont des **paramètres de CAO candidats**. Elles ne sont ni
des cotes de fabrication, ni des tolérances, ni une preuve d'identité du scan, ni
une preuve de fonctionnement. À la date de cette note :

- aucun moteur physique identifié n'est lié au scan par chaîne de garde ;
- aucune campagne CMM, CT, PMI, dureté ou rugosité n'est exécutée ;
- aucune géométrie interne n'est qualifiée ;
- aucun solveur n'est corrélé à un banc moteur instrumenté ;
- aucune pièce interne n'est autorisée à la fabrication ou au montage ;
- aucun PDF, plan, dessin ou média protégé cité ici ne doit être redistribué
  dans le dépôt.

Les liens directs servent à retrouver la source et à vérifier le contexte. Ils
ne constituent pas une licence de copie. Le dépôt ne doit conserver que des
faits courts paraphrasés, leur provenance et la décision d'ingénierie associée.

## Échelle de confiance et états de maturité

| Code | Confiance documentaire | Usage admissible |
| --- | --- | --- |
| `A` | Source primaire Porsche, FIA ou publication technique originale | Valeur de référence documentaire pour la variante et le contexte exacts |
| `B+` | Observation d'un moteur réel par un reconstructeur identifié | Architecture et séquence d'assemblage ; aucune cote implicite depuis une photo |
| `B` | Source technique secondaire attribuée ou entretien d'un ingénieur identifié | Hypothèse paramétrique à confirmer indépendamment |
| `C` | Métadonnée, inventaire ou preuve d'existence d'un dossier | Piste d'acquisition ; aucune valeur de conception extraite |

Les états suivants ne sont pas interchangeables :

| État | Sens |
| --- | --- |
| `reference_documentaire` | Fait attribué à une source et à une variante |
| `candidate_parametric` | Paramètre provisoire utilisable pour une CAO ou un calcul exploratoire |
| `measured_reference` | Valeur issue d'une mesure physique traçable avec incertitude |
| `simulation_correlated` | Modèle numérique comparé à des essais dans un domaine déclaré |
| `manufacturing_authorized` | Définition, matière, procédé et validation approuvés par l'autorité compétente |

La présente note atteint au mieux `candidate_parametric`. Aucun élément ne
devient `measured_reference`, `simulation_correlated` ou
`manufacturing_authorized` par sa seule présence dans ce document.

## Variantes strictement séparées

| Identifiant de travail | Configuration | Données publiées retenues | À ne pas fusionner |
| --- | --- | --- | --- |
| `type912_4494_1969` | Type 912 initial atmosphérique | 4 494,2 cm³ ; 85 × 66 mm ; RV 10,5:1 ; fiche FIA à 520 ch DIN et 8 000 tr/min | Les états ultérieurs annoncés à 580 ch, le 4,907 l et le 4,999 l |
| `type912_4907_1970_71` | Évolution atmosphérique homologuée | 4 907,28 cm³ ; 86 × 70,4 mm ; vilebrequin monobloc `912.102.031.00` ; fiche Porsche KH 1971 à 600 ch | Le 4,999 l final à alésage 86,8 mm |
| `type912_4999_final_na` | Atmosphérique final 5,0 l | 4 999 cm³ ; candidat secondaire 86,8 × 70,4 mm ; RV 10,5:1 ; 630 ch à 8 300 tr/min | Le 4,907 l, même si les deux partagent une course publiée de 70,4 mm |
| `91730_001_5000_turbo` | Prototype 917/30-001 biturbo | 5,0 l ; environ 1 000 ch selon Porsche | Le 917/30 de course 5,374 l |
| `91730_5374_1973` | 917/30 biturbo 1973, cible Type 912/52 à confirmer sur l'actif | 5 374 cm³ ; candidat secondaire 90 × 70,4 mm ; RV 6,5:1 ; état de course publié à 1 100 ch et fiche musée à 1 200 ch | Le prototype 5,0 l et le réglage record 1975 |
| `91730_5374_1975_record` | État record 1975 avec échangeurs | 1 230 ch publiés ; premiers échangeurs de suralimentation 917 en 1975 | Le moteur 1973 sans échangeur ; la puissance et les conditions de boost ne sont pas transférables |

Les puissances de 1 100, 1 200 et 1 230 ch décrivent des états, réglages ou
années différents. Elles doivent devenir des cas de charge séparés avec leur
propre carburant, pression de suralimentation, avance, température, durée et
source. Elles ne doivent pas être moyennées.

La désignation `Type 912/52` doit être liée à une plaque, un numéro de moteur ou
un dossier Porsche autorisé avant de devenir l'identité de l'actif physique.

## Matrice des sources

| ID | Source et URL directe | Variante | Page ou section | Faits paraphrasés retenus | Droits et conservation | Confiance |
| --- | --- | --- | --- | --- | --- | --- |
| `S01` | [FIA Historic Database, homologation n° 250](https://historicdb.fia.com/node/99501) ; [PDF direct de 17 pages](https://historicdb.fia.com/sites/default/files/car_attachment/1601078401/homologation_form_number_250_group_4.pdf) | `type912_4494_1969` | p. 8 | 12 cylindres, 85 × 66 mm, 4 494,2 cm³, RV 10,5:1, chambre nominale 39,5 cm³, cylindres et culasses séparés en alliage léger, alésages chromés durs, piston alliage léger à 3 segments, hauteur axe-calotte 43 mm, vilebrequin forgé assemblé à 8 paliers, carter sec, 30 l d'huile en circulation, ventilateur Ø 330 mm à 6 pales | La FIA présente la fiche pour consultation et précise qu'elle n'a pas valeur d'homologation actuelle. Ne pas redistribuer le scan ; citer les champs courts | `A` |
| `S02` | [Même fiche FIA n° 250](https://historicdb.fia.com/sites/default/files/car_attachment/1601078401/homologation_form_number_250_group_4.pdf) | `type912_4494_1969` | p. 8 | Maneton de bielle Ø 52 mm ; volant 2,2 ± 0,2 kg ; volant et embrayage 5,35 ± 0,2 kg ; vilebrequin 23,75 ± 0,2 kg ; bielle 0,42 ± 0,02 kg ; piston, axe et segments 0,46 ± 0,02 kg | Même restriction. La conversion impériale imprimée de 43 mm paraît erronée ; conserver la valeur métrique. Le libellé de la cote 56 mm de l'article 159 est ambigu et ne doit pas piloter la CAO | `A` |
| `S03` | [Même fiche FIA n° 250](https://historicdb.fia.com/sites/default/files/car_attachment/1601078401/homologation_form_number_250_group_4.pdf) | `type912_4494_1969` | p. 4 et p. 9 | Quatre arbres à cames en tête entraînés par engrenages, poussoirs godets. Admission : Ø 47,5 mm, levée 12,1 mm, jeu froid 0,1 mm, ouverture 104° avant PMH, fermeture 104° après PMB. Échappement : Ø 40,5 mm, levée 10,5 mm, jeu 0,1 mm, ouverture 105° avant PMB, fermeture 75° après PMH. Enveloppes de lobe S/T/U : admission 27,1/15/30 mm ; échappement 25,5/15/30 mm | Les croquis de brides et les enveloppes de lobe sont des références documentaires, pas une définition surfacique ni une loi de levée complète | `A` |
| `S04` | [Même fiche FIA n° 250](https://historicdb.fia.com/sites/default/files/car_attachment/1601078401/homologation_form_number_250_group_4.pdf) | `type912_4494_1969` | p. 10 | Pompe Bosch `PED 12 KL 60 A 120 LV 1675`, 12 pistons, 12 injecteurs indirects, conduit d'admission Ø 41 mm avec tolérance supérieure publiée de 0,8 mm, 3 pompes électriques ; 2 distributeurs, 4 bobines et 2 bougies par cylindre ; alternateur, courroie, 12 V ; 520 ch DIN à 8 000 tr/min, couple 46 mkp à 6 800 tr/min | Citation factuelle seulement. La référence de pompe n'apporte ni loi de came, ni calibration, ni débit d'injecteur | `A` |
| `S05` | [Même fiche FIA, extension 1/1E](https://historicdb.fia.com/sites/default/files/car_attachment/1601078401/homologation_form_number_250_group_4.pdf) | `type912_4907_1970_71` | p. 14, valable au 1er janvier 1970 | 4 907,28 cm³, 86 × 70,4 mm, 408,94 cm³ par cylindre, vilebrequin forgé monobloc `912.102.031.00` | Ne pas appliquer ces valeurs au 4,999 l à alésage publié de 86,8 mm | `A` |
| `S06` | [Brochure usine Porsche 917 de 1969, miroir Stuttcars](https://www.stuttcars.com/wp-content/uploads/2025/02/Porsche-917-1969-INT-.pdf) | `type912_4494_1969` | p. 5 et p. 7 | Carter, culasses et cylindres en métal léger, alésages chromés durs, vilebrequin en deux pièces matricées, bielles en titane forgé, paliers lisses, deux ACT par banc avec godets et engrenages, trois pompes électriques vers une pompe d'injection double rangée à 12 pistons, double allumage transistorisé, carter sec et ventilateur horizontal entraîné par la distribution | Brochure Porsche protégée, hébergée par un tiers. Ne pas la copier ni en extraire des images ou dessins ; conserver URL, pages et paraphrase | `A` pour le document et la variante |
| `S07` | [Porsche, fiche technique 917 KH 1971](https://newsroom.porsche.com/dam/jcr:f4ee0730-e7ea-4bfe-9fd9-2592ef47b762/Datenblatt%20Porsche%20917_KH_) | `type912_4907_1970_71` | p. 1 | V12 à 180°, 4 907 cm³, 441 kW/600 ch, véhicule de 800 kg | Média Porsche protégé. Le réservoir d'huile de 55 l décrit pour cette voiture du Mans est un composant véhicule et un choix de répartition des masses, pas le remplissage générique du moteur | `A` |
| `S08` | [Porsche Museum, 917/30 Spyder](https://newsroom.porsche.com/de/pressemappen/Porsche-Museum/Porsche-917-30-Spyder.html) ; [fiche PDF directe](https://newsroom.porsche.com/pdf/9ede995b-d407-49e1-a654-b29b43514ed2?print=) | `91730_5374_1973` | PDF p. 1 | Année modèle 1973, 12 cylindres en V à 180°, turbo, 5 374 cm³, 882 kW/1 200 ch, vitesse maximale publiée de 385 km/h | Média Porsche protégé. La fiche musée ne donne pas l'état exact de boost, le carburant, la température ni la durée au banc | `A` |
| `S09` | [Porsche, « Die Anfänge und die Turbo-Technologie im Motorsport »](https://newsroom.porsche.com/de/pressemappen/50-Jahre-Porsche-Turbo-36122/Die-Anf%C3%A4nge-und-die-Turbo-Technologie-im-Motorsport.html) | 917/10 et 917/30 turbo | Section « Drucksache » et chronologie | Un turbocompresseur plus petit par banc ; wastegate placée en amont et dérivant les gaz pour régler la pression ; organe allégé, automatique et refroidi intensément ; gaz d'échappement jusqu'à 1 100 °C. Chronologie publiée : 4,5 l turbo 850 ch/270 kg, 5,0 l 1972 1 000 ch, 5,4 l 1973 1 100 ch, moteur record 1975 1 230 ch | Texte et médias Porsche protégés ; paraphrase factuelle seulement | `A` |
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

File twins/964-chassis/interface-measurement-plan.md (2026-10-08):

# Interface survey — 964 first, then a 993 check

Status as of 2026-10-08: **measurement preparation, not a released design**.
The [CSV sheet](derived/interface-measurements-20261008.csv) keeps the 18
identities of the manual's register. Nine carry a documentary transverse span
from that register, and P13 and P14 a span from plate 50-05a; ten have a
projectable XY hypothesis. **No anchor XYZ is validated.**
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

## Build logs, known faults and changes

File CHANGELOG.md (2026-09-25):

# Changelog

All notable changes to the project are recorded in this file.

## Unreleased

Decision 0008, modern magnesium beats titanium, September 11, 2026:

- the 1995 cover does not rot because it is magnesium, but because it is
  magnesium **from 1995**: standard purity and hexavalent chromate conversion;
- what has changed — magnesium corrosion is driven by three internal
  impurities, iron, nickel and copper; the ASTM limits for AZ91D cap them at
  0.004 / 0.001 / 0.015 %, and high purity is given as **up to 100×** more
  resistant to salt spray, more than cast 380 aluminum or cold-rolled steel;
  PEO replaces chromate conversion, without hexavalent chromium;
- final comparison: modern magnesium wins **both** plate-bending indices
  (1.965 and 6.988), removes the galvanic couple since it is the same material
  as the case, cancels differential expansion and addresses the failure mode at
  its root;
- titanium is ruled out on these numbers: heavier, less stiff, and carrying the
  worst galvanic couple in the grid against a magnesium case;
- lesson recorded: three times in this project the right answer has been the
  original material done properly — the question to ask first is not "what to
  replace it with" but "what can we do today that we could not do then";
- obstacles not investigated: a shop able to machine magnesium, a PEO thickness
  of 5 to 40 µm on a sealing face, and availability as AZ31B plate rather than
  cast AZ91E.

The original part is magnesium, not aluminum, September 11, 2026:

- major correction: the factory-fitted 964/993 chain housing covers are **cast
  magnesium**, and their failure mode is corrosion of the sealing faces — that
  is the reason the billet cover market exists;
- every mass comparison run so far set titanium against aluminum, hence
  **against the aftermarket product and not the original part**;
- redone against magnesium at 1.81 g/cm³: titanium is 2.45× denser and loses
  **both** plate-bending indices, strength included, 6.503 versus 6.988 —
  "stronger, therefore lighter" does not hold here;
- on the other hand, the corrosion criterion of `TITANIUM.md` now applies in
  full, and it is a stronger argument than mass;
- new, unresolved obstacle: the mating case is also magnesium, and the
  titanium/magnesium couple is the least favorable in the grid — a titanium
  cover could shift corrosion onto the part that cannot be replaced;
- bug fixed in the screening: a mitigation whose text admitted it was
  "unresolved" counted as a mitigation; the script now raises an error.

Plate-bending performance indices, September 11, 2026:

- the mass trade-off is restated with Ashby indices: at imposed stiffness
  `E^⅓/ρ` gives 1.526 for aluminum versus 1.095 for titanium, aluminum wins;
  at imposed strength `σ_y^½/ρ` gives 4.969 versus 6.503, titanium wins by
  31 %;
- "titanium is stronger, therefore thinner, therefore lighter" is thus
  correct, on the condition that strength is what sizes the part;
- note added: in pure tension `E/ρ` is 25.9 and 25.7, the two materials are
  equivalent; it is the ⅓ exponent of plate bending that makes the difference;
- for this cover, four observations converge on "neither stiffness nor
  strength sizes it" — 9.7 Nm tightening torque, M6 fasteners hence probably
  short bolt spacings with a deflection in `L⁴`, negligible case pressure, and
  a cast part; in that case thin machined titanium is lighter.

Cover expansion margin redone, September 11, 2026:

- two errors corrected at once. The formula compared the expansion of an
  entire face to a **radial** clearance, which overstated the problem by a
  factor of two; what must fit within the clearance is the offset at the hole
  farthest from the fixed point, hence `δ = r · Δα · ΔT`. And the fasteners
  were assumed to be M8 while the manual tightens this cover to 9.7 Nm, i.e.
  M6;
- result: **0.072 mm of offset versus 0.300 mm of clearance** in medium-fit
  M6, with only **24 %** of the clearance used instead of the 72 % announced;
- sensitivity published over six combinations of hole and fixed point: all
  pass, the tightest — dowel location and close-fit hole — using 72 %;
- `--datum dowel` option added: plate 103-05 shows a locating dowel
  `993 105 175 00`, and if it holds the cover the unfavorable radius doubles;
- installation assumption declared: bolts centered in their holes when cold,
  otherwise half the margin is an assembly tolerance and not a reserve;
- mass threshold made decidable: titanium machined to the strictly necessary
  stiffness beats the casting as soon as the casting carries **39 % more
  thickness than its stiffness requirement**, and LN Engineering's 6061
  billet cover, free of casting constraints, measures that excess directly;
- the 9.7 Nm torque on M6 points the same way: low clamping, low gasket
  reaction, a part that carries almost no load;
- correction propagated to the camshaft housing, where the decisive reason is
  requalified: it is not hole clearance that governs but the alignment of the
  camshaft bearing faces, which has no clearance to consume.

Acquiring dimensions without access to parts, September 11, 2026:

- online search for the dimensions of cover `964 105 107 01`: **none are
  published**, but the search establishes something else — two independent
  reproducers, LN Engineering in 6061 aluminum and Auto-Service Schefter in
  CNC, confirm that the part number is the **left** cover, that it is paired
  with gasket `964 105 181 01`, and that the part is made **by machining from
  solid**, which until now was only reasoning;
- both reproducers use aluminum: titanium is a deliberate departure;
- the workshop manual gives "Chain housing cover : 9,7 Nm" (9.7 Nm), which
  puts the fasteners at **M6** and not M8 — the expansion margin computed on an
  M8 assumption must be redone;
- strategy recorded: the right question is not where to find the dimensions
  but what is the cheapest object that carries them — the $13 gasket gives
  outline and bolt spacings, a used cover gives everything, and neither
  requires access to a car.

The whole factory catalog dispositioned, September 11, 2026:

- `scripts/dispose_pet_catalogue.py` gives a category and a reason to the
  **1,026 designations**: not a single silent loss anymore, where 956 used to
  drop out without a reason;
- 373 designations investigated by hand, versus 72 before; **zero**
  designations remain without a verdict;
- `muffler`, 12 part numbers, rises out of the batch: the lexical triage had
  missed it because its name contained no vocabulary term, and together with
  the tip it is the best titanium candidate on the car; `y-piece` joins it;
- the verdict now covers everything judged and not only the 70 designations
  the vocabulary recognized — the pool grows from 7 to 9;
- limitation counted rather than hidden: **50 generic designations, 751 part
  numbers**, where the word does not name a function — `support` covers 142 of
  them — and which require part-number-by-part-number work, not done.

Chain housing cover 964 105 107 01 in Ti-6Al-4V, September 11, 2026:

- part explicitly requested; at equal geometry titanium adds 64 % of mass, but
  there is no reason for the thickness to stay equal, and the opposite claim
  was an error;
- thickness equivalence computed on three criteria: at equal bending
  stiffness titanium is 85 % of the thickness and stays 1.39 times heavier; at
  equal strength it is 46.6 % and becomes 24 % lighter; at equal mass it is
  60.9 % and keeps only 37 % of the stiffness;
- third case recorded, the most likely for a cast part: the original thickness
  is dictated by the foundry — minimum wall, draft, filling — and a machined
  part has none of these constraints, so it can be thinner while staying stiff
  enough; `D03` and the eye will decide, not the calculation;
- parametric screening: differential expansion against the aluminum case is
  0.144 mm over a 100 mm bolt spacing at 100 K, and fits within the 0.200 mm
  clearance of a Ø8.4 hole for M8 bolts, margin +0.056 mm;
- that is what separates the cover from the whole case, rejected on these
  grounds: beyond a bolt spacing of about 139 mm at the same clearance, the
  margin disappears;
- the galvanic couple is already handled by the bill of materials: gasket
  964 105 181 01 separates the two metals over the whole sealing face;
- route chosen: **milling** from Ti-6Al-4V plate, not printing — none of the
  three additive families;
- measurement plan published, thirteen dimensions of which two decide: the
  bolt spacings and the internal clearance to the chain.

Querying the screening on a specific part number, September 11, 2026:

- `scripts/explain_pet_reference.py` and the `pet-explain` target answer part
  by part: designation, plates, triage score, reasons, and judgment;
- it says explicitly when a designation has **never been judged**, instead of
  implying a rejection — a designation dropped by the vocabulary used to
  disappear silently;
- `993 102 050 01`, crankshaft pulley, investigated in answer to a question:
  ruled out, on four independent grounds.

The 70 factory-catalog designations investigated, September 11, 2026:

- `catalog/manufacturing/pet-candidate-judgements.json` judges the 70
  designations kept by the triage: presumed original material, actual benefit
  of titanium, presumed class, additive families;
- `scripts/screen_pet_candidates.py` **derives** the verdict from these
  entries and refuses to run if a written verdict no longer follows from its
  reasons — the guard that previous screenings lacked;
- **seven designations deserve a record**, covering 40 part numbers, six of
  them new; they form a single family, the hot-air and secondary-air circuit
  around the exhaust heat exchangers;
- this pool passes because it is hot without being at gas temperature, made
  of sheet steel and not aluminum, thin and consolidatable, and benign in
  failure;
- the 63 rejections are mechanically justified: titanium does not improve on
  the original material, presumed-critical domain, no additive family, or
  physical impossibility for a heat exchanger whose function is to conduct
  heat;
- `docs/993/993_BACKLOG_TITANE.md` publishes the three denominators side by
  side so they stop being quoted for one another.

SAFETY.md rewritten and chain housing investigated, September 11, 2026:

- `SAFETY.md` rewritten: classes, presumed-critical domains, downgrade rule
  and reporting kept identical, with the addition of what the project has
  learned — failure mode outranks domain and fire is its forgotten case, a
  screening authorizes nothing, service temperature is checked against the
  alloy's ceiling, disassembly is part of the part's life, process and
  material are two separate judgments, and raising a class requires six named
  pieces of evidence while lowering it requires none;
- chain housing of plate 103-05 investigated: eight part numbers established,
  including three bridges, two of which are also designated oil galleries;
- verdict: a genuine case for additive consolidation, but titanium rejected
  three times — differential expansion with the aluminum case, galling on
  re-cut threads, galvanic couple; the answer is aluminum;
- two corrections to the screening, the first of which was wrong: making the
  five contraindications disqualifying removed the words "not addressed" and
  "not controlled" that the grid contains;
- corrected model: a contraindication is a **condition to be lifted**, which
  blocks without a declared mitigation and becomes a requirement carried into
  the route when a mitigation is declared; only the two physical
  impossibilities remain absolute, conducting heat and keeping the stiffness
  of steel;
- missing criterion added, and it was the deciding one: **does titanium
  improve on the original material?** The grid already asked it — "corrosion
  problematic with the original material" — and without it the screening
  ranked a lukewarm aluminum intake manifold first;
- the report now carries its own denominator: 33 records, not 6,259 part
  numbers, and says so in `scope_warning`.

Turbo oil circuit investigated and ruled out, September 11, 2026:

- identity established from factory plate 202-16: four `oil pipe` in two
  positions, three `vent line`, two `oil collection container`, two `bracket`;
- four Porsche part numbers entered in the repository record, which carried
  none;
- correction recorded: the record calls itself "return" without the plate
  establishing it; the feed/return assignment remains to be done;
- rejection justified twice — the failure mode is fire in the sense of
  `SAFETY.md`, and the `TITANIUM.md` grid rules out titanium on repeated
  threading exposed to galling;
- conclusion: the best additive candidate in the triage is not a titanium
  candidate; the two questions are not the same.

Titanium triages of the factory catalog, September 11, 2026:

- finding that the titanium screening covered 32 records, i.e. 0.51 % of the
  6,259 distinct part numbers in the 993 catalog: "applied to the catalog" was
  an overstatement of scope, corrected in an addendum to decision 0007;
- `screen_pet_zones_for_titanium.py` triages the 239 illustrations of the
  skeleton using only repository data, 23 zones kept out of 1,538 part
  numbers;
- `screen_pet_parts_for_titanium.py` triages 1,026 designations from a
  transcription kept outside the repository, 70 kept, publishing only the
  short list;
- the exhaust tip comes out in the top four of the broadened triage, the two
  designations ahead of it falling on exhaust temperature;
- per-plate exclusion rule corrected: it applies only if all the plates of a
  designation are critical, otherwise `oil pipe` wrongly disappeared.

Decision 0007, first titanium part selected by grid, September 11, 2026:

- `scripts/screen_titanium_candidates.py` applies the `TITANIUM.md` grid and
  the three additive families to the 32 records, refusing to run if a record
  is not judged; only five parts are eligible;
- `993-EXH-OVAL-TIP-TI-F1-0001` chosen at +6, the exhaust manifold being ruled
  out despite its +7 because 900 °C is a nickel case;
- tip generator parameterized by `--material`, one geometry and three material
  cards, with STL export and temperature verdict;
- step 02 `passed`, step 03 `completed_screening` at 4,936 layers of 30 µm;
- two mutually exclusive titanium route cards: Ti-6Al-4V is available
  everywhere and blocked by a −27 °C margin, Ti-6242 passes the temperature
  and has no machine, no layer thickness and no supplier;
- generic temperature gate added to `build_process_route_card.py`;
- finding: the decision hinges on 427 °C never measured, and an infrared
  thermometer settles what twelve thousand lines of calculation will not.

Decision 0006, the ring will be turned in 6063 T6, September 11, 2026:

- turning route card `cnc-turning-6063-t6-bright-anodised.json`, grade chosen
  on appearance with 6061 T6 as fallback and 6262 ruled out for its lead;
- generator `scripts/build_turning_route_card.py` and associated turning
  quote, targets `turning-trim-ring` and `turning-trim-ring-check`;
- the ring's `preferred_process` changed from `undecided` to `CNC`, LPBF
  remaining a screened candidate;
- twin renamed `twins/993-switch-trim-ring-f1`, the directory name no longer
  asserting a material the repository has ruled out;
- finding recorded: changing process closed neither of the two gates that
  matter, the untoleranced fit dimension and the undefined edges.

Decision 0005, the ring's material was never chosen, September 11, 2026:

- finding that AlSi10Mg is inherited from the repository's only process card,
  and that the ring is the only `non_critical` LPBF candidate in the catalog;
- two sources on anodizing: AlSi10Mg anodizes gray-brown because of its 9 to
  11 % silicon, while 6063 T6 is excellent for bright anodizing;
- consequence recorded: for this part the material question and the process
  question are one and the same, and the likely answer is turned 6xxx bar.

First LPBF sourcing pass in China, September 10, 2026:

- four source records qualified for Unionfab, JLC3DP and Eplus3D;
- Unionfab kept as the only candidate, JLC3DP ruled out for lack of AlSi10Mg
  in its metal catalog;
- three contradictions recorded and not smoothed over: three layer
  thicknesses for the same subject, two of them from the same supplier, a
  provider material card far below the EOS coupons, and a minimum-wall rule
  the ring passes with one supplier and not the other.

Material-machine-process card for the switch trim ring, step 04, September 10,
2026:

- added `scripts/build_process_route_card.py`, a generic generator of a route
  card and a quote-request package linked to the files by SHA-256, with eleven
  gates evaluated and a `--check` mode;
- first step 04 of the AM pipeline, on `993-INT-SWITCH-TRIM-RING-F1-0001`,
  concluded `blocked_missing_input` with seven gates closed;
- internal inconsistency uncovered: the step 03 screening settles on 50 µm
  when the only published AlSi10Mg route on the EOS M 290 is at 30 µm;
- targets `route-trim-ring` and `route-trim-ring-check`, and guard
  `tests/test_993_switch_trim_ring_route_f1.py`, which fails if a gate opened
  without a coupon, heat treatment or powder lot.

993 Turbo/GT2 intercooler bracket Ti-6Al-4V F0, September 8, 2026:

- creation of an F1 twin record limited to the supplier envelope and the
  PorscheFanatics/PET identities;
- three quadratic Gmsh/CalculiX meshes run on the exact STEP, with regression
  convergence obtained on the p95 and the deflection;
- OpenUSD conversion and minimal validation through the locked NVIDIA
  workflow, without physics attribution, GPU or PhysicsNeMo;
- LPBF choice reduced to a conditional candidate against the CNC and sheet
  metal routes, all manufacturing and fitting gates remaining closed.

993 engine cooling subassembly F0, September 8, 2026:

- composition of the F0 housing and fan in a dedicated interface twin;
- cold clearance and free-when-hot calculation, exact BRep intersection check
  and explicit rejection of the 40,388.378651 mm³ collision;
- conversion of the two STEP files and composition of the assembly into
  minimal OpenUSD on Linux AMD64, with NVIDIA preflight and minimal
  validations passing without a GPU;
- SimReady properties, PhysicsNeMo, manufacturing, rotation and engine
  start-up kept closed.

917-inspired F34 four-valve air-cooled cylinder head, September 2, 2026:

- parametric CAD and process STEP generated locally from only the interfaces
  observable in the two scans, without republishing the raw scans;
- external cooling computed separately with OpenFOAM 14 (finite volumes) and
  FluidX3D (LBM), cycle cross-checked with Cantera and Wiebe, then a sequence
  of three CalculiX meshes;
- `linux/amd64` images of the CAE chain and of FluidX3D built and tested;
- all metal printing and engine start-up gates remain closed, in particular
  for scale, hot material properties, convergence, fatigue/TMF and the absence
  of physical correlation.

Phase 1, batch 1 — official catalogs, accessible manuals and measurements:

- thirteen new source records verified one by one on August 28, 2026;
- actual access statuses recorded, including refusals, paywalls and dead URLs;
- inventory log and justified list of rejected sources.

Phase 1, batches 2 and 5 — German research, scans and measurement handoff,
August 30, 2026:

- register brought to 225 valid source records, with manufacturers, forums,
  declared measurements and CAD/CT/LiDAR leads assessed separately;
- no calibrated, freely reusable 993 scan added, and no third-party file
  copied without an established license;
- two distinct German leads added: 964/993 bumper brackets with declared
  commercial dimensions, and an amateur repair of the sunroof deflector with a
  part number;
- prioritized measurement campaign for the three polymer pilots, with handoff
  procedure, confidentiality rules and an optional CT brief.

Compute environment:

- two container images, `recon` (CUDA) and `cadsim` (CPU), with a smoke test;
- toolchain redirected toward scriptable commands and APIs (ADR 0002);
- deployment procedure on a rented GPU machine and data hygiene rules.

Phase 1, batch 7 — Porsche Fanatics manual and data, August 30, 2026:

- provenance bridge to the public Porsche Fanatics index: 235 procedures,
  195 tightening torques and 111 technical data entries;
- French mapping of the manual's pages and values, with separation of the
  ROW/USA, Carrera/Carrera 4/Carrera 4S and Carrera RS variants;
- Printables lead added for the 964/993 console switch bracket, without
  copying the file and with the license not yet verified;
- exhaustive quantitative register added: 111 technical data entries, 195
  torques and 2,190 OCR occurrences with page, short context and review
  status.
- import of these 2,496 specifications into `catalog/measurements/` as a
  separate documentary record; no physical session is created without a part,
  an instrument and raw readings.

Measurement traceability:

- schema, validator and register of measurement sessions;
- direct capture from an instrument with data output, or manual entry
  explicitly marked as such;
- photogrammetric capture with a manifest and a mandatory scale reference.

## 0.1.0 — 2026-08-28

First public foundation of the project:

- charter, roadmap, safety rules and quality gates;
- free and open-source toolchain;
- schemas and templates for parts, sources, measurements and titanium
  manufacturing;
- local validators, automated tests and GitHub continuous integration;
- initial register of five sources and contribution workflow.

No part is declared printable, fitted or validated in this version.

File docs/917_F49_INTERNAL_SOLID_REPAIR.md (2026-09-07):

# Porsche 917 — F49, réparation topologique interne 2V / 4V

## Verdict

F49 est **refusée en mode fail-closed**. Les tentatives non déformantes
conservent un solide unique, une coque unique, zéro arête libre et zéro arête
non-manifold selon OCCT, mais le round-trip STEP conserve des p-courbes
invalides. Aucun candidat ne remplit donc la condition préalable
`BOPAlgo = 0`; conformément au contrat, aucun nouveau maillage volumique Gmsh
n'a été accepté et aucune impression métal n'est autorisée.

La bonne décision d'ingénierie est de conserver la peau extérieure F43 comme
autorité géométrique privée et de refuser un « soin » global qui déplacerait la
forme. La reconstruction locale des faces fautives doit être traitée dans un
lot ultérieur avec une comparaison de peau complète.

## Enveloppe verrouillée

Les variantes 2V et 4V chargent exactement la même source privée F43,
d'empreinte SHA-256
`38f8ed3071005e5f64156d8670b5a755c98599d8702ef030ff132b7a034f0f24`.
Le dépôt ne contient pas cette géométrie. Les opérations suivantes sont
interdites par contrat : modification de surface externe, mise à l'échelle
anisotrope, ellipse ou ovale global, proxy global et couture globale.

Les seuls cercles autorisés restent fonctionnels : alésage, sièges, cols,
guides, puits de bougie, sections circulaires de conduits et galeries d'huile.
La bbox exacte et quelques échantillons OCCT sont restés invariants à la
précision numérique; cette observation ne remplace pas une signature exhaustive
des faces extérieures.

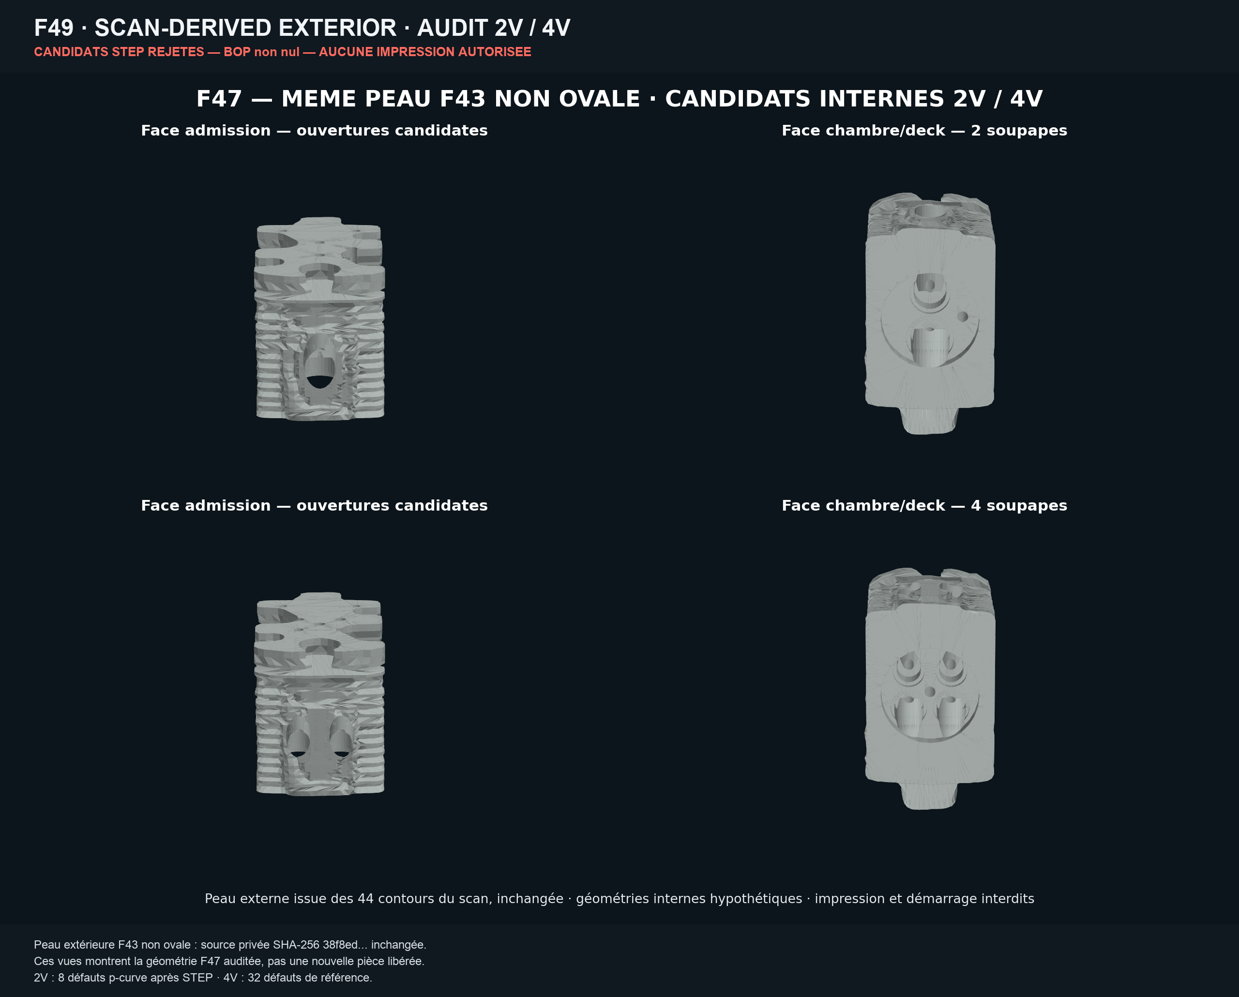
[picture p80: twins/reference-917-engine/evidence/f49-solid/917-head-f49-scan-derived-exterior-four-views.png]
Quatre vues de l'enveloppe dérivée du scan


## Essais exécutés

| Variante / méthode | BRepCheck | Topologie | BOPAlgo après STEP | Gmsh 3D | Décision |
|---|---:|---|---:|---|---|
| 2V F47 de référence | valide | 1 solide, 1 coque, 0 libre, 0 non-manifold | 8 | échec PLC F47 | rejet |
| 2V booléens séquentiels | valide | identique | 8 | non lancé par fail-fast | rejet |
| 2V booléens individuels | valide | identique | 8, sur 5 faces / 8 arêtes | non lancé | rejet |
| 2V reprojection p-curve, surface curves mode 1 | valide | identique | 0 avant export, 8 après round-trip | non lancé | rejet |
| 2V STEP sans surface curves, mode 0 | valide | identique | 131, sur 61 faces / 69 arêtes | non lancé | rejet |
| 4V F47 de référence | valide | 1 solide, 1 coque, 0 libre, 0 non-manifold | 32 | échec PLC F47 | rejet |
| 4V reprojection p-curve, surface curves mode 1 | valide | identique | 0 avant export, 32 après round-trip | non lancé | rejet |

Deux pistes ont également été rejetées : la conversion globale NURBS changeait
le volume et l'aire du noyau gaz tout en créant 22 défauts BOP; le sweep
circulaire tangent créait 27 défauts dont 21 auto-intersections. Elles ne sont
pas utilisées dans le résultat.

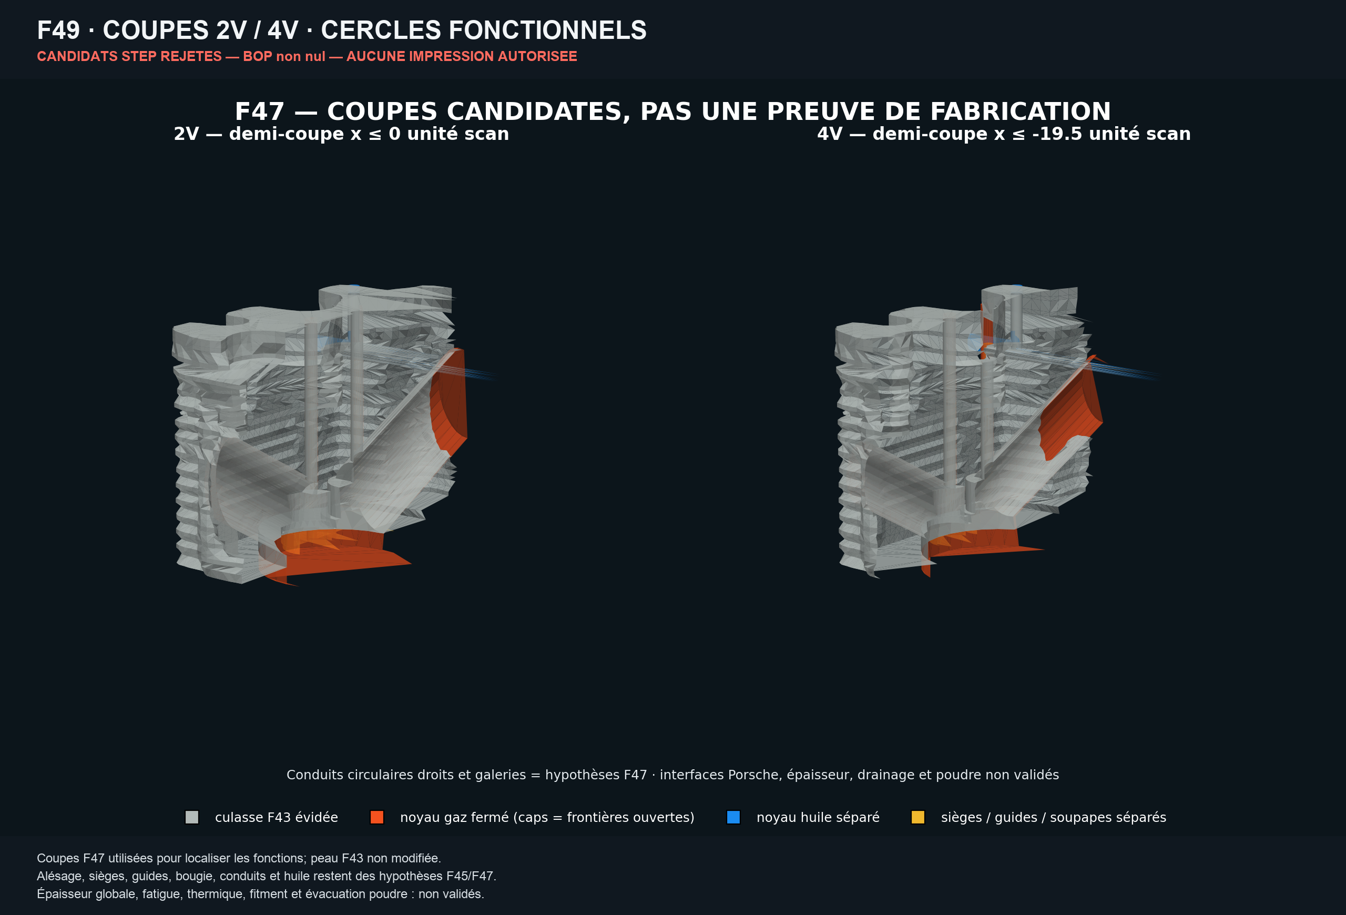
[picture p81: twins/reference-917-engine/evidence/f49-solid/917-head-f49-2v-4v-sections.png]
Coupes 2V et 4V des candidats rejetés


## Huile, épaisseur et physique

Le circuit d'huile reste un composant séparé, inchangé depuis F47 et propre au
contrôle BOP pour les deux variantes. Il n'est pas une chemise de liquide de
refroidissement. Pression, retour d'huile et accès poudre ne sont pas validés.

Les ligaments analytiques nominaux hérités de F47 sont 1,5 unité pour la 2V et
3,159837414 unité pour la 4V. Ce sont des écrans géométriques conditionnels à
la convention « une unité de scan = un millimètre »; ils ne constituent pas une
carte exhaustive d'épaisseur. L'échelle absolue du scan et le montage Porsche
ne sont pas certifiés. La porte `épaisseur >= 1,5 mm` reste donc fermée.

F49 ne valide ni thermique, ni structure, ni fatigue, ni matériau à chaud, ni
fabrication LPBF, ni montage, ni démarrage moteur.

## Fichiers et vérification

- contrat :
  [`internal-solid-repair-f49.json`](../twins/reference-917-engine/internal-solid-repair-f49.json) ;
- rapport public :
  [`f49-solid-public-report.json`](../twins/reference-917-engine/evidence/f49-solid/f49-solid-public-report.json) ;
- manifeste :
  [`publication.json`](../twins/reference-917-engine/evidence/f49-solid/publication.json).

```bash
python3 twins/reference-917-engine/source/publish_internal_solid_repair_f49.py \
  --project-root . --check
python3 tests/test_917_f49_internal_solid_repair.py -v
```

Les STEP, STL, BREP, OBJ et MSH dérivés du scan sont volontairement absents du
dépôt. Le rapport publie seulement des empreintes et métriques assainies.

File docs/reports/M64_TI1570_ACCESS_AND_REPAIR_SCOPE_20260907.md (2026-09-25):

# TI 1570 (02/00) — access and evidence of a distinct repair

Targeted search of September 7, 2026. The reference **1570 (02/00)** is confirmed
in the [official Porsche PET, plate 102-05](https://assets-v2.porsche.com/jp/-/media/Project/PCOM/SharedSite/PorscheClassic/Original-Parts-Catalogue/PDF-EN-WW/KAT013_E_911_94_KATALOG).
**The exact copy of this TI has not been found.** Exact English/German searches,
and searches restricted to the Porsche domain, returned PET references, not a
link to its text. No authentication failure was observed: we therefore cannot
claim that it sits behind an account or a subscription. No purchase, login or
unauthorized manual was used.

## Attributable Porsche bulletin, but a different reference

[Design911 hosts a scan of a Porsche Cars North America bulletin](https://www.design911.co.uk/uploads/pdfs/964_Cylinder_TSB.pdf):
**group 1, part identifier 1570, no. 9404, February 8, 1994**, concerning the
refacing of cylinder heads with tool 9526. All five pages were checked
visually, headers and figures included. It supersedes bulletin 9202; nothing
establishes that it is the same document as "02/00".

Scope p.1: Carrera 2/4 1989–1991, M64.01 up to **62M06836**, M64.02
Tiptronic up to **62M52757**. The repair uses the modified cylinders/pistons
and refaces the cylinder heads. The steel gasket **96410411520** sits in the
groove of the **cylinder** (p.1 and p.3), not in a cylinder-head groove inferred
from the drawing.

| Documentary transcription | Value / location |
|---|---|
| Axial refacing of the inner face marked 2 | **0.10 ± 0.02 mm**, p.4, figure 4 |
| Diameter of the seating surface after this refacing | **145 mm**, p.4, figure 4 |
| Maximum removal from the cylinder-head face | **0.20 mm**, p.4 |
| Stated surface finish | **32 micro-inches**, p.4; Ra parameter not explicitly named |
| Check before machining | Radial and lateral runout with a dial indicator, p.4 |
| Additional service reference | Carrera 2/4 manual, volume 1, **15-10e**, p.4 |

The text on p.4 explicitly designates the **machined surface**, then repeats the
diameter to be obtained on the cylinder-head–cylinder seating surface after
machining. The 145 mm dimension in figure 4 therefore designates **neither tool
9526 nor the lathe fixture**. The axial refacing is a removal from the existing
cylinder head, not a nominal material thickness to be created on a new head.

These transcriptions describe a **specific repair**, not a design drawing.
The 145 mm diameter is neither the engine bore nor a toleranced register
diameter, and is not adopted as a nominal M64 interface diameter.
No dimensioned groove width/depth, stud position or complete interface
tolerance is provided by these transcriptions. Applicability to the
993, M64.50/M64.60 and to our new turbo cylinder head is not established.

## Provenance and next steps

PDF: 252,514 bytes, 5 pages; SHA-256
`86a0f3279be970c3c98b27618357cfb0be0b575602af66d9923eed00c1bce75e`.
The bulletin date is read on the pages; the metadata of the scanned file
are more recent and do not constitute its date of issue.
The document carries Porsche and copyright notices; no PDF, page render
or illustration is added to the repository.

Contribution: a historical procedure and precise locators are now
accessible. What remains is to obtain the TI "02/00" itself, then a drawing of the
seating face and groove matching the selected variant. **No dimension or procedure
is transferred to the CAD contract or turned into a machining authorization.**

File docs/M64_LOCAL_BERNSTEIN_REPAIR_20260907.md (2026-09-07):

# Réparation locale Bernstein sur la référence 935 — 7 septembre 2026

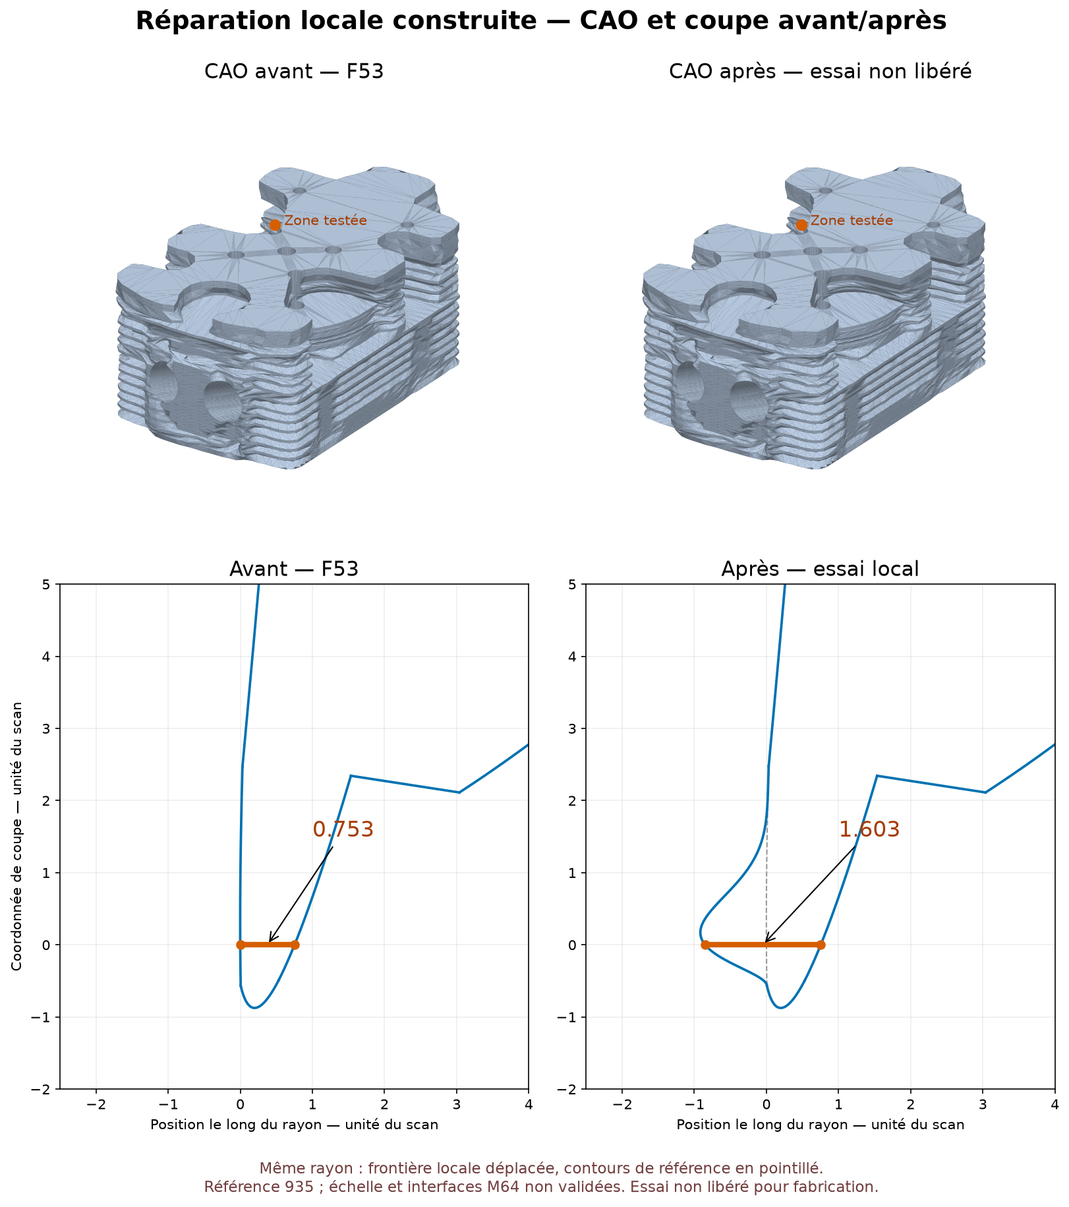
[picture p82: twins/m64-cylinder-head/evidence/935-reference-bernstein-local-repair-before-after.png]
Vraie CAO et coupe avant/après de la réparation locale


Vue produite depuis les deux STEP contrôlés et leurs sections OCCT, sans
image générative. Source attribuée à Wolfe Classics selon
`catalog/sources/src-wolfe-classics-935-billet-cylinder-head-scan.json`.
Le skill `create-viz` a guidé la conservation des vues et échelles et
l'affichage de la référence en pointillé. Le rendu neutre n'est pas un
champ de températures ou de contraintes.

## Une nouvelle face et un solide ont été construits

Le candidat de bidegré **10 × 11** conserve les cinq courbes de bord de la
face source dans les contrôles effectués. La face puis le solide fermé
passent BRepCheck exact, y compris après export et import STEP. Les
tolérances de la face et de ses cinq arêtes restent à `1e-7` : aucune
réévaluation favorable par augmentation des tolérances n'est utilisée.
Le contrôle BOP d'auto-intersections a ensuite terminé sans défaut signalé.

Le même trajet local mesuré par intersection CAO passe de **0,752667 à
1,602667 unité du scan**. Parmi les autres rayons appariés, 39 restent
inchangés à `1e-5` près ; deux rayons demeurent non résolus. Ce résultat
est local et échantillonné, pas une validation d'épaisseur de toute la pièce.

La source reste la reconstruction F53 issue d'une référence de recherche
935. Ce n'est pas une géométrie M64 validée, ni une échelle certifiée, ni
une pièce autorisée à fabriquer ou à monter sur un moteur. La silhouette
globale n'est pas remplacée ; **une surface locale vers le passage d'air
est réellement modifiée**. Une boîte englobante inchangée ne signifie pas
que toute la peau extérieure est inchangée.

## Pourquoi réduire le degré a été utile

La [recherche de champ à contraintes implicites](M64_IMPLICIT_BOUNDARY_BUBBLE_20260907.md)
avait trouvé un premier champ 12 × 23. Sa surface directe respecte les
courbes, mais le contrôle contextuel OCCT de deux arêtes échoue près des
extrémités : l'évaluation par adaptateur donne environ `1,668e-7` d'écart,
alors que l'évaluation directe de la surface aux mêmes paramètres donne
`1,06e-13` et `7,29e-12`.

Le témoin utilisant la surface source inchangée et le même assemblage de
fil passe. Ce n'est donc pas une simple inversion de fil. Le STEP 12 × 23
réimporté devient valide seulement après hausse automatique de deux
tolérances d'arêtes à environ `1,668e-7` : **ce candidat reste rejeté**.
Le diagnostic constate une divergence entre voies d'évaluation ; il ne
prétend pas identifier à lui seul la ligne fautive interne d'OCCT.

La nouvelle sélection minimise d'abord le degré maximal, puis le degré
total, et seulement ensuite l'amplitude sur la grille initiale. Les scores
numériques des 14 641 champs ont été recalculés à partir des coefficients
privés déjà enregistrés : le premier rapport ne conservait que le meilleur
champ, pas tous les scores. Aucun nouvel ajustement de géométrie n'est
effectué pour cette sélection. 360 champs satisfont la limite d'amplitude
sur la grille 81 × 81.

| Exposants `(p,q,r,s)` | Bidegré | Maximum sur 24 732 points | Rapport d'orientation minimal |
|---|---|---:|---:|
| **(4,2,2,5)** | **10 × 11** | **0,934757** | **0,968771** |
| (5,2,2,5) | 11 × 11 | 0,886633 | 0,966479 |
| (3,2,2,6) | 9 × 12 | 0,998871 | 0,979431 |

Seul le premier est construit. La dernière combinaison a très peu de
marge sous la limite 1. Ces maxima restent échantillonnés, pas des bornes
globales certifiées.

## Construction et contrôles du 10 × 11

`trial_transition_bernstein.py` multiplie les coefficients en **base de
Bernstein**, sans développement monomial de haut degré ni BRepFill.
Le facteur de bord possède un unique coefficient non nul avant produit
avec `F²`, où `F` est l'équation du cylindre analytique portant la cinquième
découpe. Le déplacement vaut 0,85 au point cible. Les pôles de la surface
bilinéaire source sont élevés en degré puis additionnés aux coefficients
de déplacement dans la direction retenue.

Les nœuds reprennent exactement le domaine UV original ; les mêmes courbes
paramétriques et intervalles sont attachés aux arêtes. Les opérations
s'effectuent sur une copie du maître. Les conditions de construction
B-Spline et les fonctions de rattachement des courbes sont décrites dans
les références officielles [Geom_BSplineSurface](https://occt3d.com/dev/doc/refman/html/class_geom___b_spline_surface.html)
et [BRep_Builder](https://occt3d.com/dev/doc/refman/html/class_b_rep___builder.html).

| Contrôle natif | Résultat |
|---|---:|
| Erreur du point déplacé de 0,85 | `3,89e-14` unité |
| Erreur maximale courbes/surface à mêmes paramètres, 121 points/arête | `6,25e-9` unité |
| Même contrôle sur surface source | `6,25e-9` unité |
| Écart maximal des premières dérivées aux bords échantillonnés | `9,61e-12` |
| Écart formule factorisée / surface OCCT, 6 250 points | `7,14e-14` unité |
| Déplacement natif maximal sur ces points | `0,934182` unité |
| Rapport d'orientation natif minimal | `0,968804` |
| Face avant et après export/import | BRepCheck exact valide |
| Tolérance face et cinq arêtes, avant et après import | `1e-7`, inchangée |
| Couture | Une coque ; zéro arête libre ou multiple |
| Solide avant et après export/import | BRepCheck exact valide, 20 431 sous-formes contrôlées |
| Topologie | Un solide, une coque, 4 929 faces ; zéro arête non-manifold |
| BOP auto-intersections du solide complet | Terminé, aucun défaut signalé |
| Variation des six bornes englobantes, avant export | 0 |
| Variation de volume | `+10,6963` unités³, soit `+0,0008584 %` |
| Variation de surface | `+7,49387` unités² |
| Variation de volume due au seul aller/retour STEP | `4,66e-10` unité³ |

Le coefficient de normalisation vaut `89,8421`, contre environ 497 655
pour le 12 × 23. La meilleure stabilité n'est pas déduite de ce rapport
seul : elle est observée dans les évaluations et contrôles natifs. Le
maximum absolu des coefficients Bernstein de déplacement vaut `3,18756` ;
ce n'est pas le maximum de la surface.

Un contrôle indépendant supplémentaire a comparé **toutes** les tolérances
des deux STEP complets : 4 929 faces, 10 222 arêtes et 5 278 sommets. Les
distributions sont strictement identiques, avec minimum et maximum `1e-7`
dans chaque catégorie. La seule face 10 × 11 et ses cinq arêtes conservent
aussi cette valeur après la couture et l'import du solide complet.

La [borne globale Bernstein indépendante](M64_BERNSTEIN_GLOBAL_BOUND_20260907.md)
établit pour le polynôme scalaire stocké `|D| ≤ 0,9512202009568349` sur
**tout le carré UV**, et pas seulement aux points de la grille. Elle emploie
une subdivision rationnelle exacte des coefficients flottants enregistrés.
Sa portée n'inclut pas une borne globale des arrondis d'évaluation OCCT,
ni une validation mécanique ou de fabrication.

## Artefacts privés et limites

Sur Kali, sous :

```text
/tmp/917-f50/out/m64-local-transition-bernstein-20260907-low-degree/
```

- `private-bernstein-coefficients.npz` : coefficients, paramètres et pôles privés réutilisables.
- `private-replacement-face.step` : face 10 × 11, SHA `168327ff82585039ccd4c62e4004a73b0176fca42f6ea09d49e8582f37ed33c5`.
- `diagnostic-candidate.step` : solide complet, SHA `42057011e25ecc48b215a58e979a0d9bcf4769f2f96f9690b751a81a7bde2cd8`.
- `surface-report.json`, `solid-report.json`, `audit-report.json` : étapes natives séparées.

SHA des rapports surface/solide/audit :

```text
33f99d631f77a6a6bc14a4a9a3dea531f2e40c2a44a31a97606e76a94209636f
6482f829ed18a836ed54351b630bb2703ab5c3d2b99063b428a1da83ef5784e9
d2bb2b1195b1ef320ca8dc9fac7a57a910aa9477a28c3022f771f4e70eb508af
```

Image publiée : SHA `18057ee6e124420960d5f1d8e742d8f000898f688e78ba68141107c973eaa08a`.
Le [résumé public expurgé](../twins/m64-cylinder-head/bernstein-local-repair-summary-20260907.json)
ne contient ni coordonnées, ni indices de faces/probes privés, ni STEP/NPZ.

Rapports annexes, sous `/tmp/917-f50/out/` :

- `m64-bernstein-adaptor-boundary-audit-20260907.json`, SHA `af85432b9e495205b5672e6eca49f2426e8c2a9a2e31c0e39e00fd9b2e685cec` : rejet du 12 × 23 et hausse automatique des tolérances à l'import.
- `m64-low-degree-localized-fields-20260907.json`, SHA `645bfb542e396528e6372f449b71a27554976d45929ba98ff9c32807dc7526c8` : classement des trois candidats de moindre degré.
- `m64-bernstein-complete-tolerance-audit-20260907.json`, SHA `c68b62f1386ff8879e3d6c90e52937cd2949252a73c1b7179a93e08e79cb85fe` : inventaire privé complet de chaque tolérance, avec histogrammes exacts et contrôle spécifique de la face modifiée.

Le contrôle d'auto-intersections BOP a terminé dans son plafond
de 300 secondes, avec `exit 0`. Il n'est pas remplacé par la seule réussite de BRepCheck.
Les scripts d'audit et de construction sont limités à deux CPU et 4 Gio ;
la sélection numérique est limitée à 60 secondes. Un premier lancement
de l'audit s'est arrêté avant calcul sur un helper distant ancien ; après
mise en cohérence du helper testé, l'audit reprend sans reconstruire la CAO.
Le rapport initial est conservé sous `audit-report-import-error.json`.

Deux tests unitaires vérifient les produits Bernstein et la construction
du facteur localisé ; quatre autres couvrent l'audit et la recherche de
champ. Quatre tests lient le résumé expurgé à ses preuves, vérifient les
comptes de rayons et empêchent sa promotion en pièce M64 libérée.
Les preuves CAO ci-dessus proviennent des exécutions natives,
pas de ces tests seuls.

## Prochaine correction proposée, sans nouvelle construction

`audit_remaining_transition_faces.py` a inspecté les quatre rayons non
adjacents faibles restants dans la géométrie source réelle. Les quatre
surfaces d'entrée sont bilinéaires non rationnelles, à quatre limites
isoparamétriques et un seul fil. Elles ne nécessitent donc pas le facteur
cylindrique utilisé dans la réparation précédente.

- Deux rayons, `1,144959` et `1,304774` unités, traversent le même couple
  de faces en sens opposés. Une correction doit contrôler ces deux trajets
  ensemble, pas les considérer comme deux défauts indépendants.
- Un autre trajet vaut `1,427734` unité.
- Le plus faible restant vaut `1,052418` unité ; son point d'entrée est
  très proche d'une limite paramétrique. Normaliser une bulle globale à ce
  point pourrait surdéplacer d'autres zones de la face.

La piste proposée est une bulle sur un **support UV local**, avec facteurs
cubiques donnant déplacement, dérivées premières et secondes nuls au bord
du support. Une représentation B-Spline par nœuds locaux, de degré 6 × 6,
pourrait conserver les courbes initiales et un raccord C2 sans grand degré
global. Ce sont des propriétés de la construction proposée, **pas une
surface déjà construite**. Son amplitude, sa direction vers le passage
d'air, les collisions, les rayons couplés et la borne continue devront être
contrôlés avant puis après toute construction.

Rapport de lecture seul, privé :
`/tmp/917-f50/out/m64-remaining-transition-feasibility-20260907.json`,
SHA `463eaa85b14c10c2e1284049fd57642fce8e93ad1b73e5b4a37da4e7c9768a75`.
Aucune nouvelle CAO n'a été lancée sur ces quatre rayons.

Thermique, fatigue, charge turbo, interfaces M64, fabrication LPBF et
contrôles physiques ne sont pas validés par cette réparation. Les autres
zones minces doivent encore être traitées. Le maître F53 conserve son SHA
`700baea66bc72cdb6aee529e21b167270ebde11db94b06f8e1e55ee08bdd9bf2`.

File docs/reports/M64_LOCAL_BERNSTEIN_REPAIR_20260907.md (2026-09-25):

# Local Bernstein repair on reference 935 — September 7, 2026

Real CAD and before/after section of the local repair

View produced from the two checked STEP files and their OCCT sections, with no
generative image. Source attributed to Wolfe Classics according to
`catalog/sources/src-wolfe-classics-935-billet-cylinder-head-scan.json`.
The `create-viz` skill guided keeping the views and scales and showing the
reference as a dotted line. The neutral render is not a temperature or stress
field.

## A new face and a solid were built

The candidate of bidegree **10 × 11** keeps the five boundary curves of the
source face in the checks performed. The face and then the closed solid pass
exact BRepCheck, including after STEP export and import. The tolerances of the
face and of its five edges stay at `1e-7`: no favorable reassessment by
increasing tolerances is used. The BOP self-intersection check then ended with
no defect reported.

The same local path measured by CAD intersection goes from **0.752667 to
1.602667 scan units**. Among the other paired rays, 39 remain unchanged to
within `1e-5`; two rays remain unresolved. This result is local and sampled,
not a thickness validation of the whole part.

The source remains the F53 reconstruction from a 935 research reference. It is
not validated M64 geometry, nor a certified scale, nor a part authorized for
manufacturing or for mounting on an engine. The global silhouette is not
replaced; **a local surface toward the air passage is actually modified**. An
unchanged bounding box does not mean that the whole outer skin is unchanged.

## Why reducing the degree helped

The [implicit-constraint field search](M64_IMPLICIT_BOUNDARY_BUBBLE_20260907.md)
had found a first 12 × 23 field. Its direct surface respects the curves, but
the OCCT contextual check of two edges fails near the ends: evaluation through
the adaptor gives a gap of about `1.668e-7`, while direct evaluation of the
surface at the same parameters gives `1.06e-13` and `7.29e-12`.

The control case using the unchanged source surface and the same wire assembly
passes. This is therefore not a simple wire reversal. The reimported 12 × 23
STEP becomes valid only after an automatic increase of two edge tolerances to
about `1.668e-7`: **this candidate remains rejected**. The diagnostic records
a divergence between evaluation paths; it does not claim to identify by
itself the faulty internal line of OCCT.

The new selection first minimizes the maximum degree, then the total degree,
and only then the amplitude on the initial grid. The numerical scores of the
14,641 fields were recomputed from the private coefficients already recorded:
the first report kept only the best field, not all the scores. No new
geometry fit is performed for this selection. 360 fields satisfy the amplitude
limit on the 81 × 81 grid.

| Exponents `(p,q,r,s)` | Bidegree | Maximum over 24,732 points | Minimum orientation ratio |
|---|---|---:|---:|
| **(4,2,2,5)** | **10 × 11** | **0.934757** | **0.968771** |
| (5,2,2,5) | 11 × 11 | 0.886633 | 0.966479 |
| (3,2,2,6) | 9 × 12 | 0.998871 | 0.979431 |

Only the first one is built. The last combination has very little margin under
the limit of 1. These maxima remain sampled, not certified global bounds.

## Construction and checks of the 10 × 11

`trial_transition_bernstein.py` multiplies the coefficients in a **Bernstein
basis**, with no high-degree monomial expansion and no BRepFill. The boundary
factor has a single nonzero coefficient before the product with `F²`, where
`F` is the equation of the analytic cylinder carrying the fifth trim. The
displacement is 0.85 at the target point. The poles of the bilinear source
surface are degree-elevated and then added to the displacement coefficients in
the chosen direction.

The knots take exactly the original UV domain; the same parametric curves and
intervals are attached to the edges. The operations are performed on a copy
of the master. The B-Spline construction conditions and the curve attachment
functions are described in the official references
[Geom_BSplineSurface](https://occt3d.com/dev/doc/refman/html/class_geom___b_spline_surface.html)
and [BRep_Builder](https://occt3d.com/dev/doc/refman/html/class_b_rep___builder.html).

| Native check | Result |
|---|---:|
| Error of the point displaced by 0.85 | `3.89e-14` unit |
| Maximum curve/surface error at the same parameters, 121 points/edge | `6.25e-9` unit |
| Same check on the source surface | `6.25e-9` unit |
| Maximum gap of first derivatives at the sampled boundaries | `9.61e-12` |
| Gap between factored formula and OCCT surface, 6,250 points | `7.14e-14` unit |
| Maximum native displacement on these points | `0.934182` unit |
| Minimum native orientation ratio | `0.968804` |
| Face before and after export/import | exact BRepCheck valid |
| Tolerance of face and five edges, before and after import | `1e-7`, unchanged |
| Sewing | One shell; zero free or multiple edges |
| Solid before and after export/import | exact BRepCheck valid, 20,431 subshapes checked |
| Topology | One solid, one shell, 4,929 faces; zero non-manifold edges |
| BOP self-intersections of the full solid | Completed, no defect reported |
| Change of the six bounding limits, before export | 0 |
| Volume change | `+10.6963` units³, i.e. `+0.0008584%` |
| Surface area change | `+7.49387` units² |
| Volume change due to the STEP round trip alone | `4.66e-10` unit³ |

The normalization coefficient is `89.8421`, versus about 497,655 for the
12 × 23. The better stability is not inferred from this ratio alone: it is
observed in the native evaluations and checks. The absolute maximum of the
Bernstein displacement coefficients is `3.18756`; this is not the maximum of
the surface.

An additional independent check compared **all** the tolerances of the two
full STEP files: 4,929 faces, 10,222 edges and 5,278 vertices. The
distributions are strictly identical, with minimum and maximum `1e-7` in each
category. The single 10 × 11 face and its five edges also keep this value
after sewing and importing the full solid.

The [independent global Bernstein bound](M64_BERNSTEIN_GLOBAL_BOUND_20260907.md)
establishes for the stored scalar polynomial `|D| ≤ 0.9512202009568349` over
**the whole UV square**, and not only at the grid points. It uses an exact
rational subdivision of the recorded floating-point coefficients. Its scope
does not include a global bound on OCCT evaluation rounding, nor a mechanical
or manufacturing validation.

## Private artifacts and limits

On Kali, under:

```text
/tmp/917-f50/out/m64-local-transition-bernstein-20260907-low-degree/
```

- `private-bernstein-coefficients.npz`: reusable private coefficients, parameters and poles.
- `private-replacement-face.step`: 10 × 11 face, SHA `168327ff82585039ccd4c62e4004a73b0176fca42f6ea09d49e8582f37ed33c5`.
- `diagnostic-candidate.step`: full solid, SHA `42057011e25ecc48b215a58e979a0d9bcf4769f2f96f9690b751a81a7bde2cd8`.
- `surface-report.json`, `solid-report.json`, `audit-report.json`: separate native steps.

SHA of the surface/solid/audit reports:

```text
33f99d631f77a6a6bc14a4a9a3dea531f2e40c2a44a31a97606e76a94209636f
6482f829ed18a836ed54351b630bb2703ab5c3d2b99063b428a1da83ef5784e9
d2bb2b1195b1ef320ca8dc9fac7a57a910aa9477a28c3022f771f4e70eb508af
```

Published image: SHA `18057ee6e124420960d5f1d8e742d8f000898f688e78ba68141107c973eaa08a`.
The [redacted public summary](../../twins/m64-cylinder-head/bernstein-local-repair-summary-20260907.json)
contains no coordinates, no private face/probe indices, and no STEP/NPZ.

Supporting reports, under `/tmp/917-f50/out/`:

- `m64-bernstein-adaptor-boundary-audit-20260907.json`, SHA `af85432b9e495205b5672e6eca49f2426e8c2a9a2e31c0e39e00fd9b2e685cec`: rejection of the 12 × 23 and automatic tolerance increase on import.
- `m64-low-degree-localized-fields-20260907.json`, SHA `645bfb542e396528e6372f449b71a27554976d45929ba98ff9c32807dc7526c8`: ranking of the three lowest-degree candidates.
- `m64-bernstein-complete-tolerance-audit-20260907.json`, SHA `c68b62f1386ff8879e3d6c90e52937cd2949252a73c1b7179a93e08e79cb85fe`: full private inventory of each tolerance, with exact histograms and a specific check of the modified face.

The BOP self-intersection check completed within its 300-second cap, with
`exit 0`. It is not replaced by the success of BRepCheck alone. The audit and
construction scripts are limited to two CPUs and 4 GiB; the numerical
selection is limited to 60 seconds. A first launch of the audit stopped before
computing on an old remote helper; after bringing the tested helper in line,
the audit resumes without rebuilding the CAD. The initial report is kept as
`audit-report-import-error.json`.

Two unit tests verify the Bernstein products and the construction of the
localized factor; four others cover the audit and the field search. Four tests
bind the redacted summary to its evidence, verify the ray counts and prevent
its promotion to a released M64 part. The CAD evidence above comes from the
native runs, not from these tests alone.

## Next avenue and result of the separate trial

**Update:** the [local C2 reinforcement on the thinnest isolated path](M64_ISOLATED_C2_REJECTION_20260907.md)
has since been built as a separate surface, then rejected at the slope filter
before any face or sewing. It is not combined with the 10 × 11 solid. The
earlier proposal and audit remain below.

`audit_remaining_transition_faces.py` inspected the four remaining weak
non-adjacent rays in the real source geometry. The four entry surfaces are
non-rational bilinear, with four isoparametric boundaries and a single wire.
They therefore do not need the cylindrical factor used in the previous repair.

- Two rays, `1.144959` and `1.304774` units, cross the same pair of faces in
  opposite directions. A correction must check these two paths together, not
  treat them as two independent defects.
- Another path is `1.427734` units.
- The weakest remaining one is `1.052418` units; its entry point is very close
  to a parametric boundary. Normalizing a global bubble at this point could
  over-displace other areas of the face.

The proposed avenue is a bubble on a **local UV support**, with cubic factors
giving zero displacement, first and second derivatives at the edge of the
support. A B-Spline representation with local knots, of degree 6 × 6, could
keep the initial curves and a C2 blend without a high global degree. These are
properties of the proposed construction, **not an already built surface**. Its
amplitude, its direction toward the air passage, the collisions, the coupled
rays and the continuous bound will have to be checked before and after any
construction.

Read-only report, private:
`/tmp/917-f50/out/m64-remaining-transition-feasibility-20260907.json`,
SHA `463eaa85b14c10c2e1284049fd57642fce8e93ad1b73e5b4a37da4e7c9768a75`.
No new CAD had been launched during this preliminary audit.

Thermal behavior, fatigue, turbo load, M64 interfaces, LPBF manufacturing and
physical checks are not validated by this repair. The other thin areas still
have to be treated. The F53 master keeps its SHA
`700baea66bc72cdb6aee529e21b167270ebde11db94b06f8e1e55ee08bdd9bf2`.

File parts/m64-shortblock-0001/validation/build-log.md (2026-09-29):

# Validation — compile attempt (M64-SHORTBLOCK-0001)

Verdict: **compiled clean** in the pinned station image (0 warnings, 0
errors) after three first-time compile fixes (see below). Execution,
voxelization and export remain unrun; "geometry validated" is still NOT
claimed.

## Environment

- Host: kali2, ext4 worktree `/home/lolman/repos/wt-geo-sb`, branch
  `wave2/geo-sb-20260929`.
- Image: `picogk-station:qualified-final-20260928` (image ID
  `fd50c61399fd`, = `ghcr.io/cluster2600/3dprinting993-picogk-m64:station-20260928-final-fd50c61399fd`),
  PicoGK 2.3.0 at `/upstream/PicoGK`.
- Host dotnet is 6.0.400 (cannot target net9.0), hence the container build.

## Exact command

```sh
timeout 170 docker run --rm \
  -v /home/lolman/repos/wt-geo-sb:/work \
  -w /work/parts/m64-shortblock-0001/source/geometry \
  picogk-station:qualified-final-20260928 \
  bash -lc "dotnet build ShortBlock.csproj -c Release -nologo"
```

## History of attempts (2026-09-29)

1. First attempt (commit `bcdae48`): **FAILED** — 1 error.
   `ShortBlock.cs(381,43) error CS1001/CS1003`: parameter named `base`
   (reserved keyword) in `BuildFinnedCylinder`.
2. After rename `base` → `basePt`: **FAILED** — 7 errors:
   - CS1657 ×5: `Merge(ref using-var, ...)` on `using`-declared `Voxels`
     (`capCuts`, `barrel`) — `ref` cannot alias a using variable;
   - CS1501/CS8422: 6-argument `Annulus(...)` call in the rod shank builder
     (helper takes 5: `lib, a, b, rOuter, rInner`), plus the `base` cascade.
3. Fixes applied (commit `c48b133`):
   - `BuildFinnedCylinder(..., Vector3 base, ...)` → `basePt`
     (call sites pass a local already named `cylBase`; signature-compatible),
   - `Merge(ref Voxels, ...)` → `Merge(Voxels, ...)` (target is only mutated
     via methods; `ref` was never semantically required),
   - shank call corrected to `Annulus(lib, a, b, shankR, 0.0f)` — a solid
     round-section beam, matching the documented "round-section shank
     hypothesis envelope" (was passing widths as if a box API existed).
   No geometry intent was changed beyond the shank call completing the
   documented intent.
4. Final attempt: **Build succeeded. 0 Warning(s), 0 Error(s)** (elapsed
   ~15 s, within the 170 s timeout). Output
   `bin/Release/net9.0/M64ShortBlock.dll`. Build by-products (`bin/`,
   `obj/`, root-owned from the container) removed; a part-local `.gitignore`
   excludes them.

## Record

- `dotnet build -c Release` inside the pinned image: **PASS** at commit
  `c48b133` (this branch), 0 warnings / 0 errors.
- `dotnet run` (voxelization, STL/vdb export, run-report, volume sanity):
  **not executed** — next validation step; requires a headless station run
  with an output dir writable by the container.
- `dimensional_correctness_verified`: **false** (compile ≠ measurement).

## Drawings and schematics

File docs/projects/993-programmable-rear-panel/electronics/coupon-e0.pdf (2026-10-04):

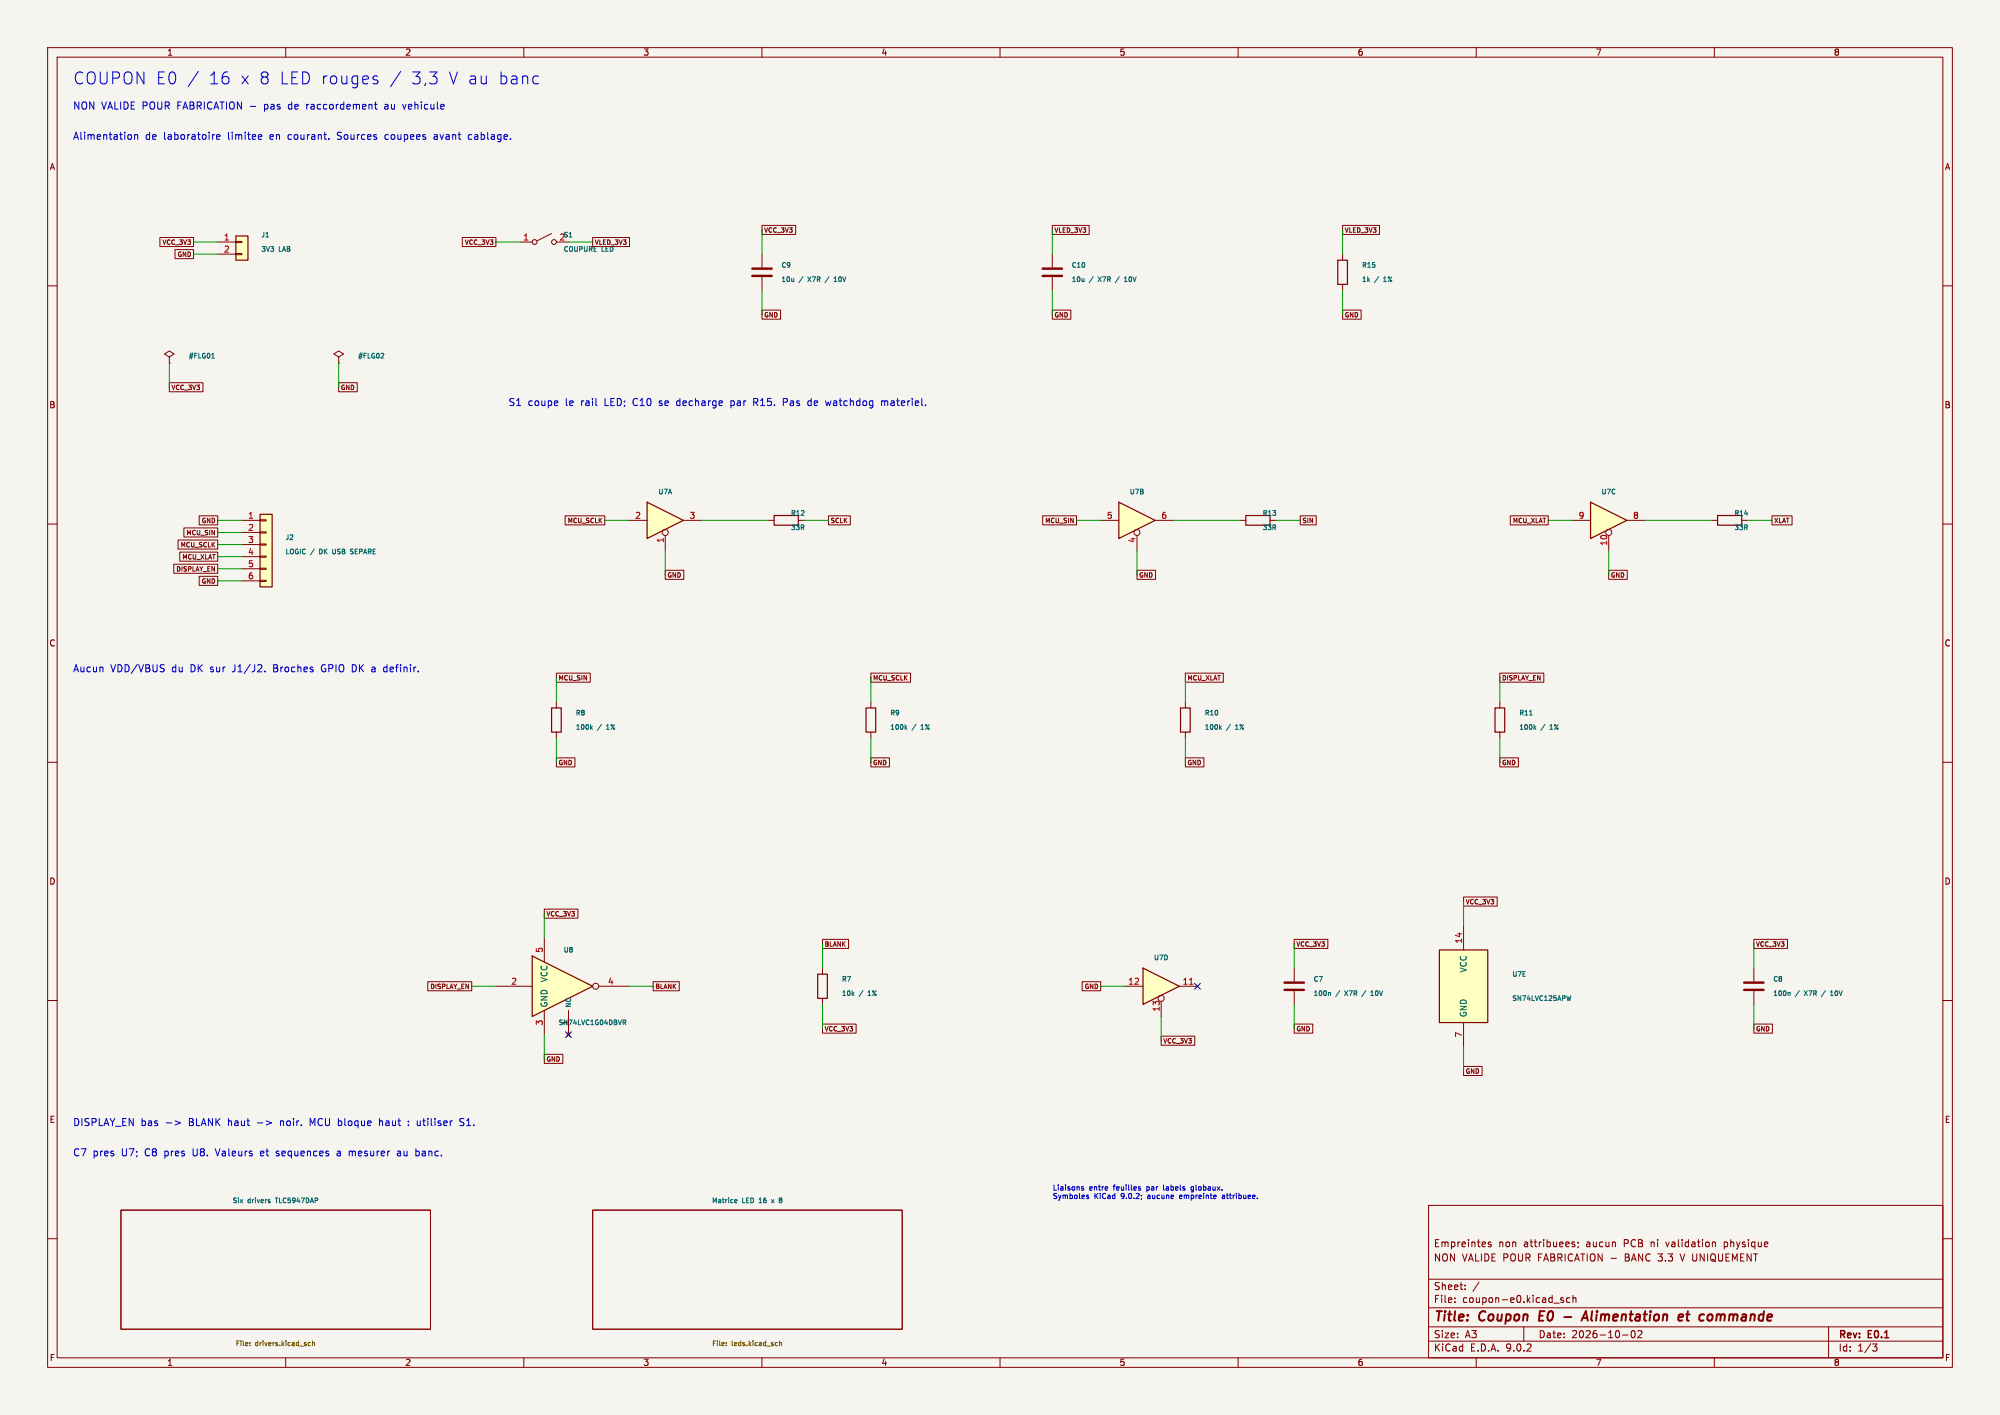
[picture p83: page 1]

COUPON E0 / 16 x 8 LED rouges / 3,3 V au banc

S1 coupe le rail LED; C10 se decharge par R15. Pas de watchdog materiel.

Matrice LED 16 x 8 File: leds.kicad_sch Six drivers TLC5947DAP

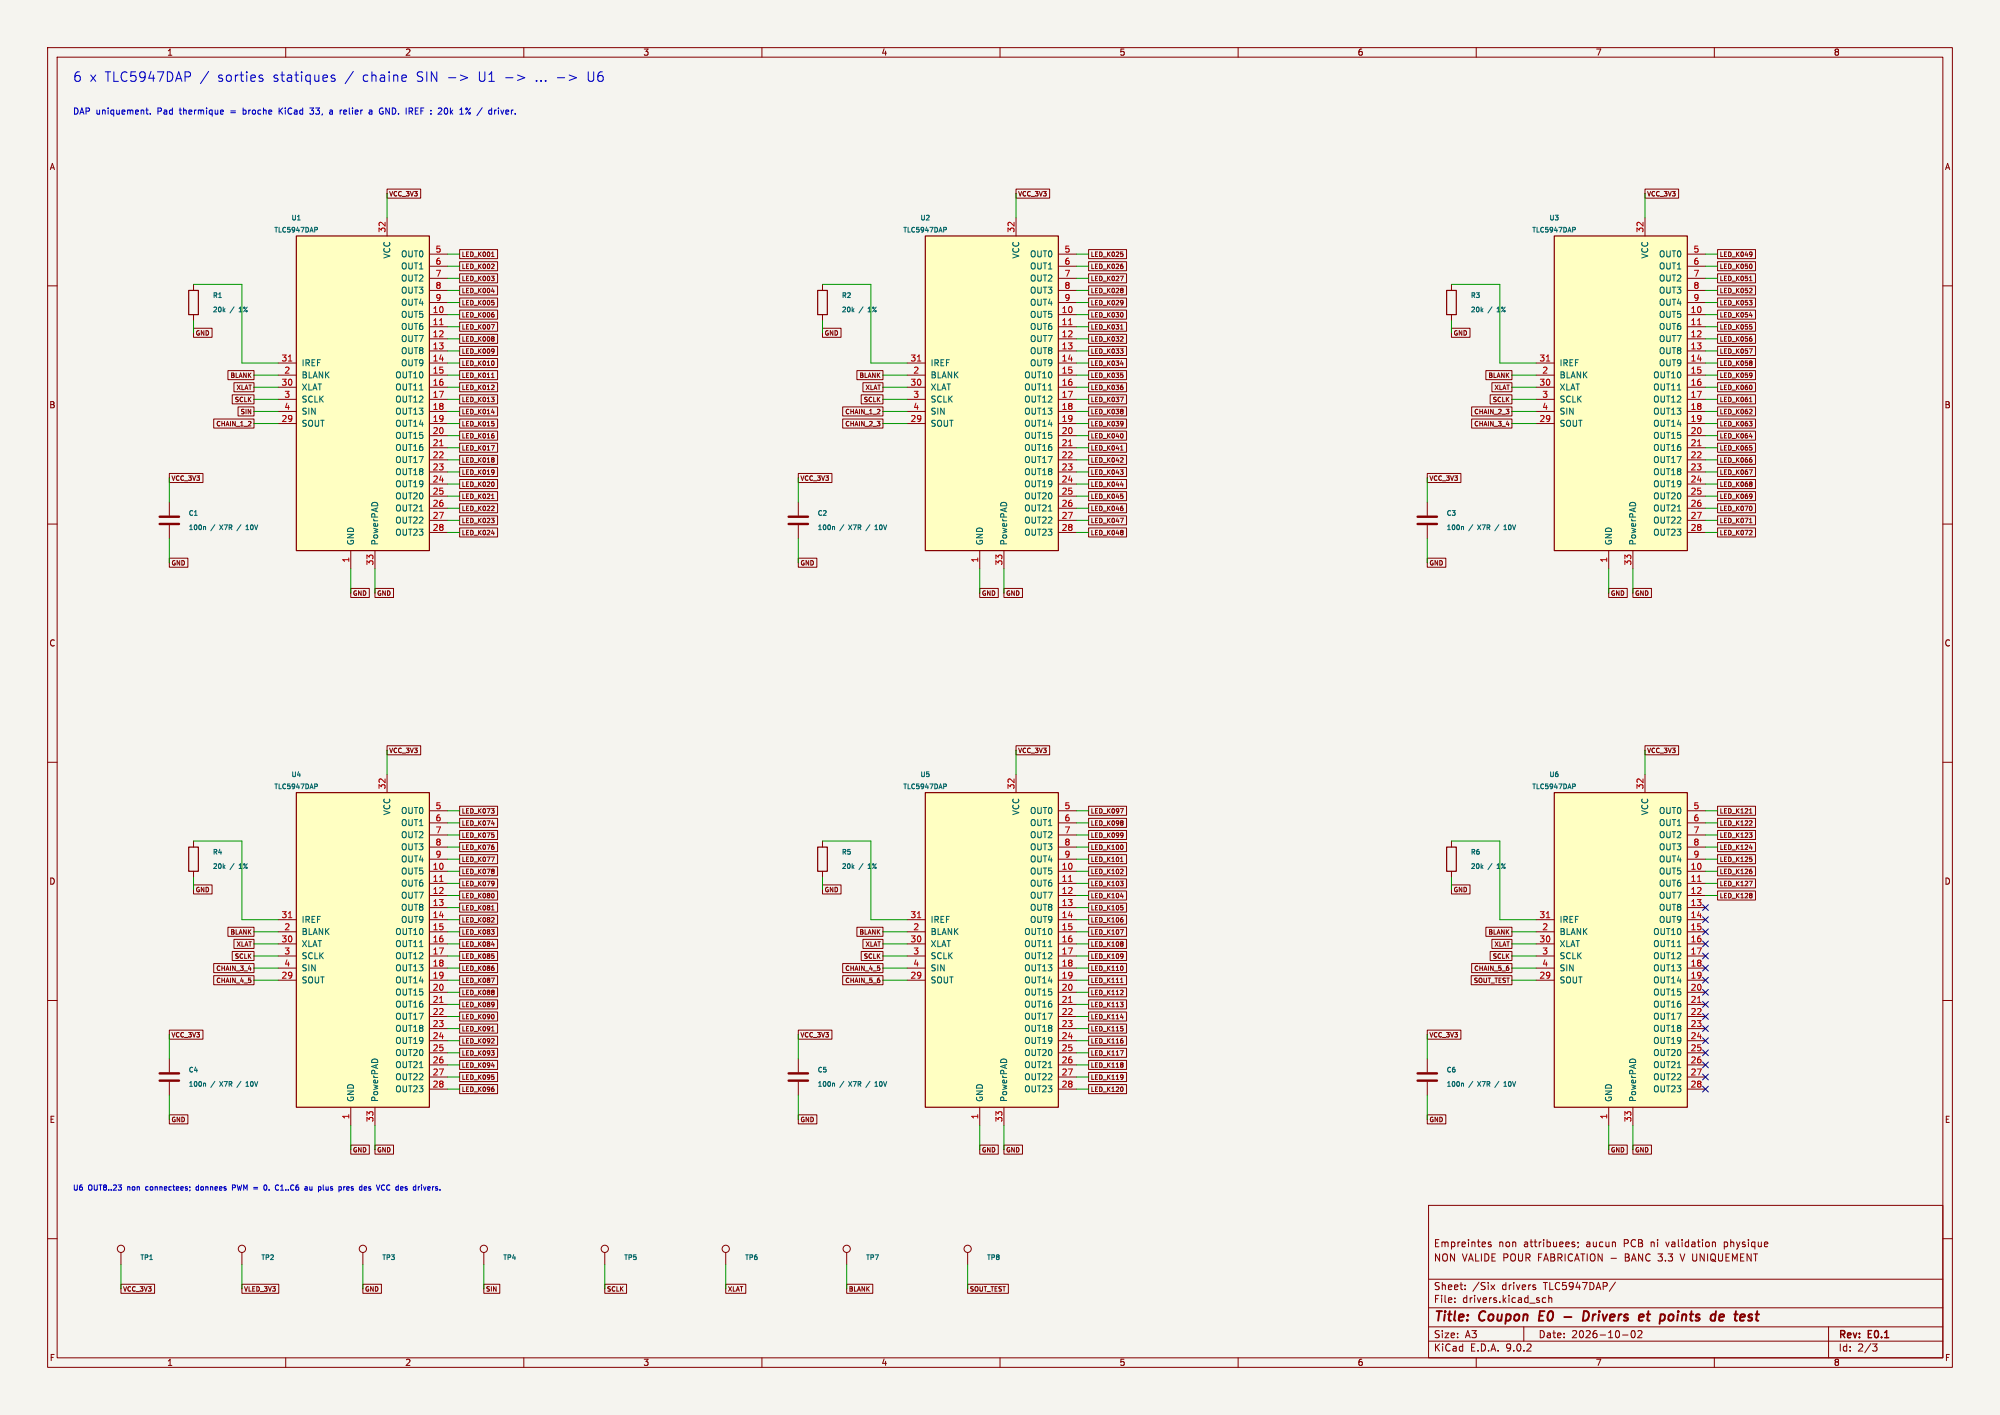
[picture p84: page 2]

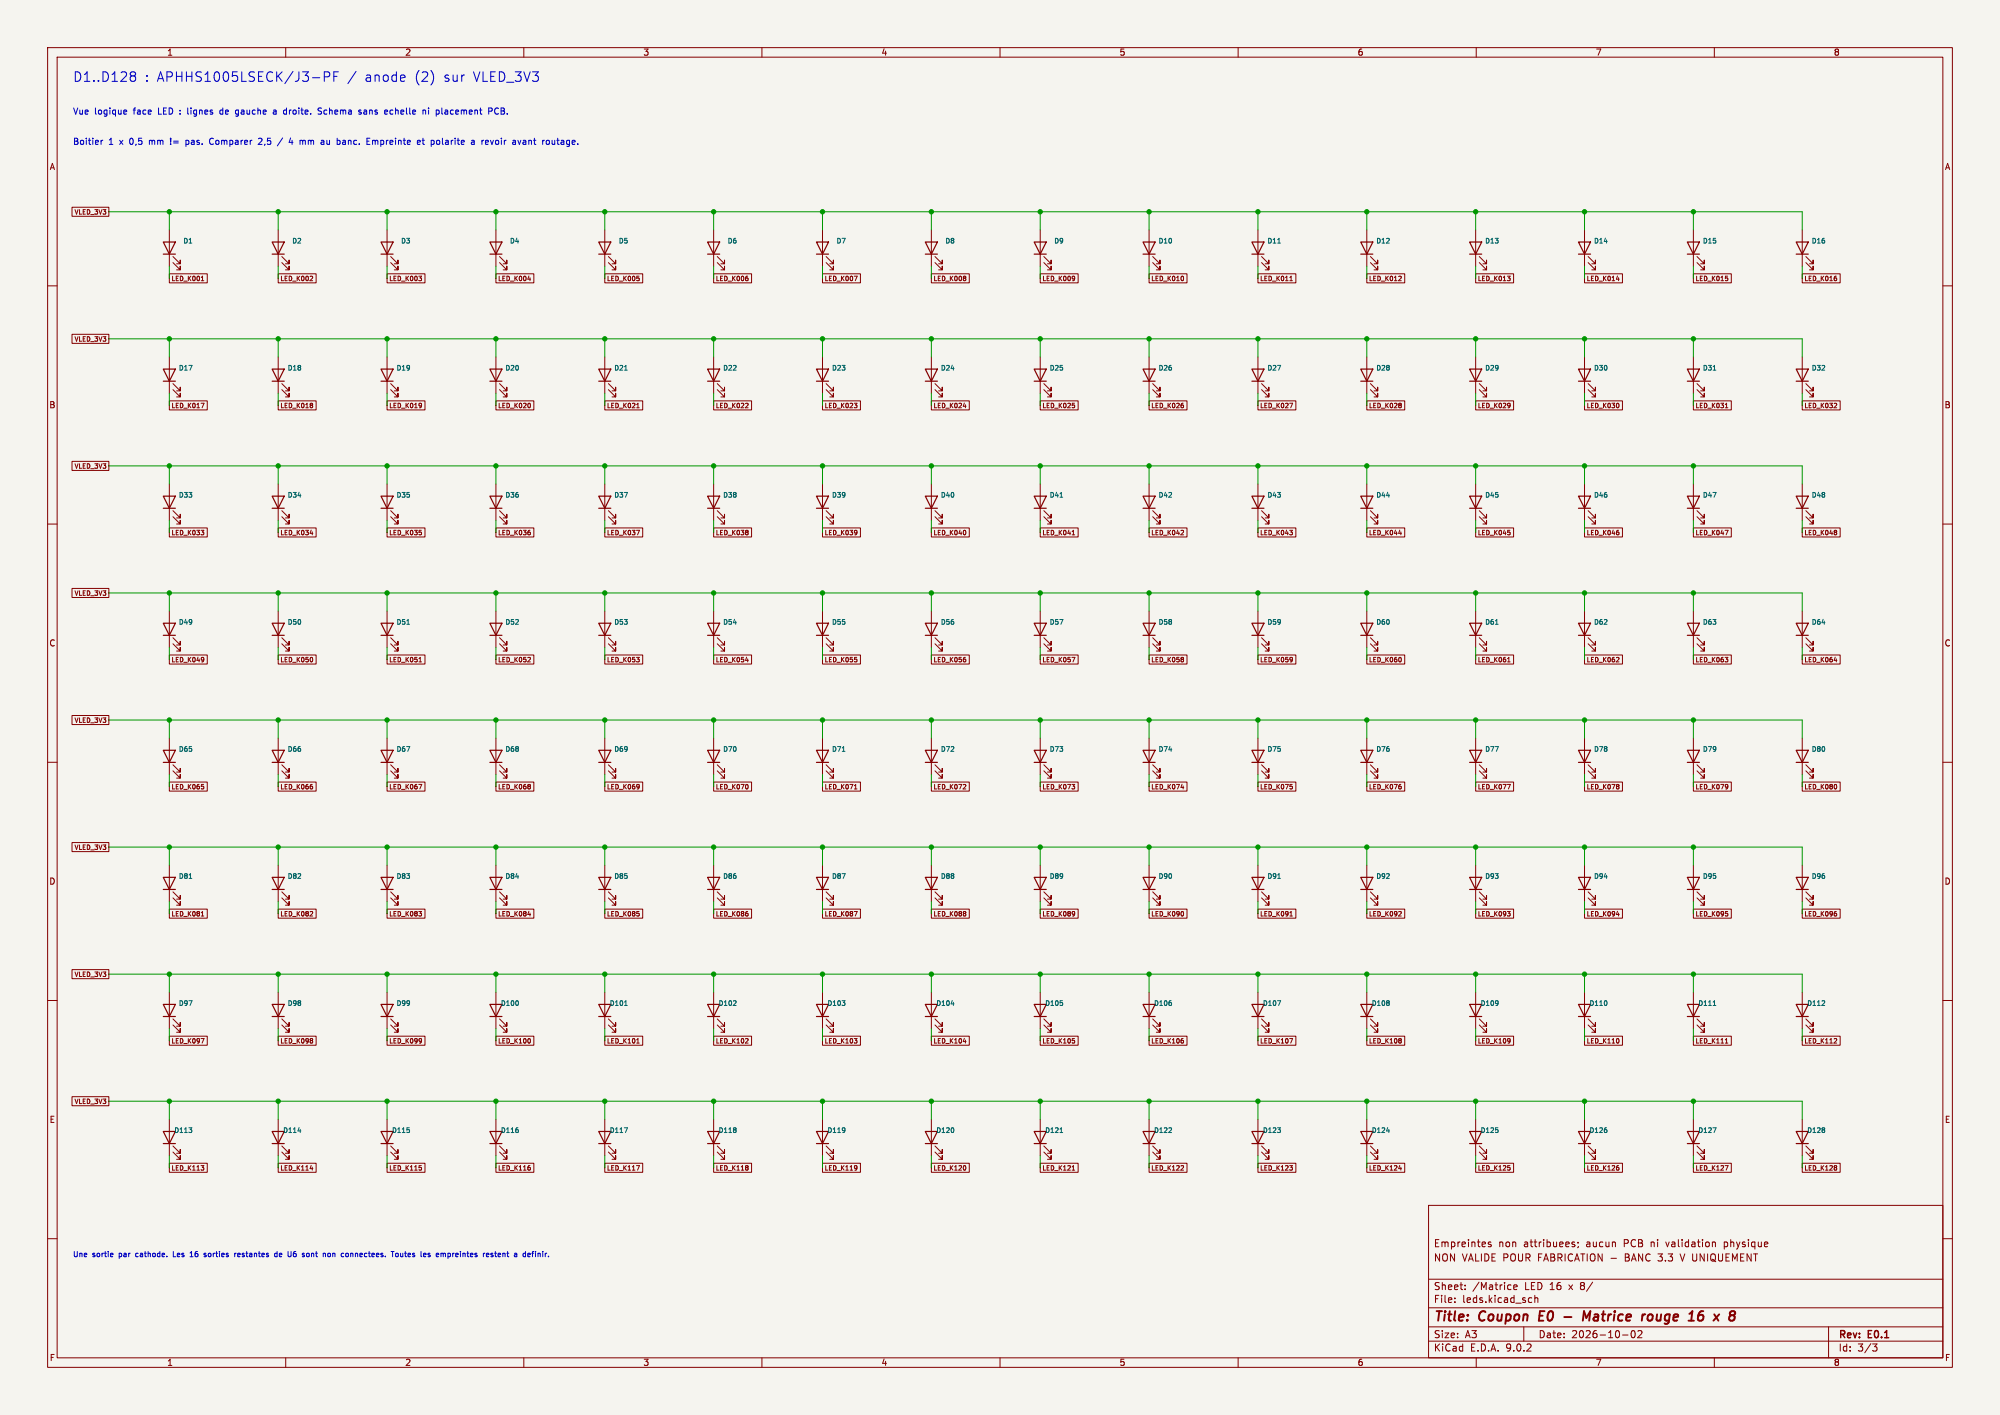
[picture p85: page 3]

Id: 3/3 Title: Coupon E0 - Matrice rouge 16 x 8

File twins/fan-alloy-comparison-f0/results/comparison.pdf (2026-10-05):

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

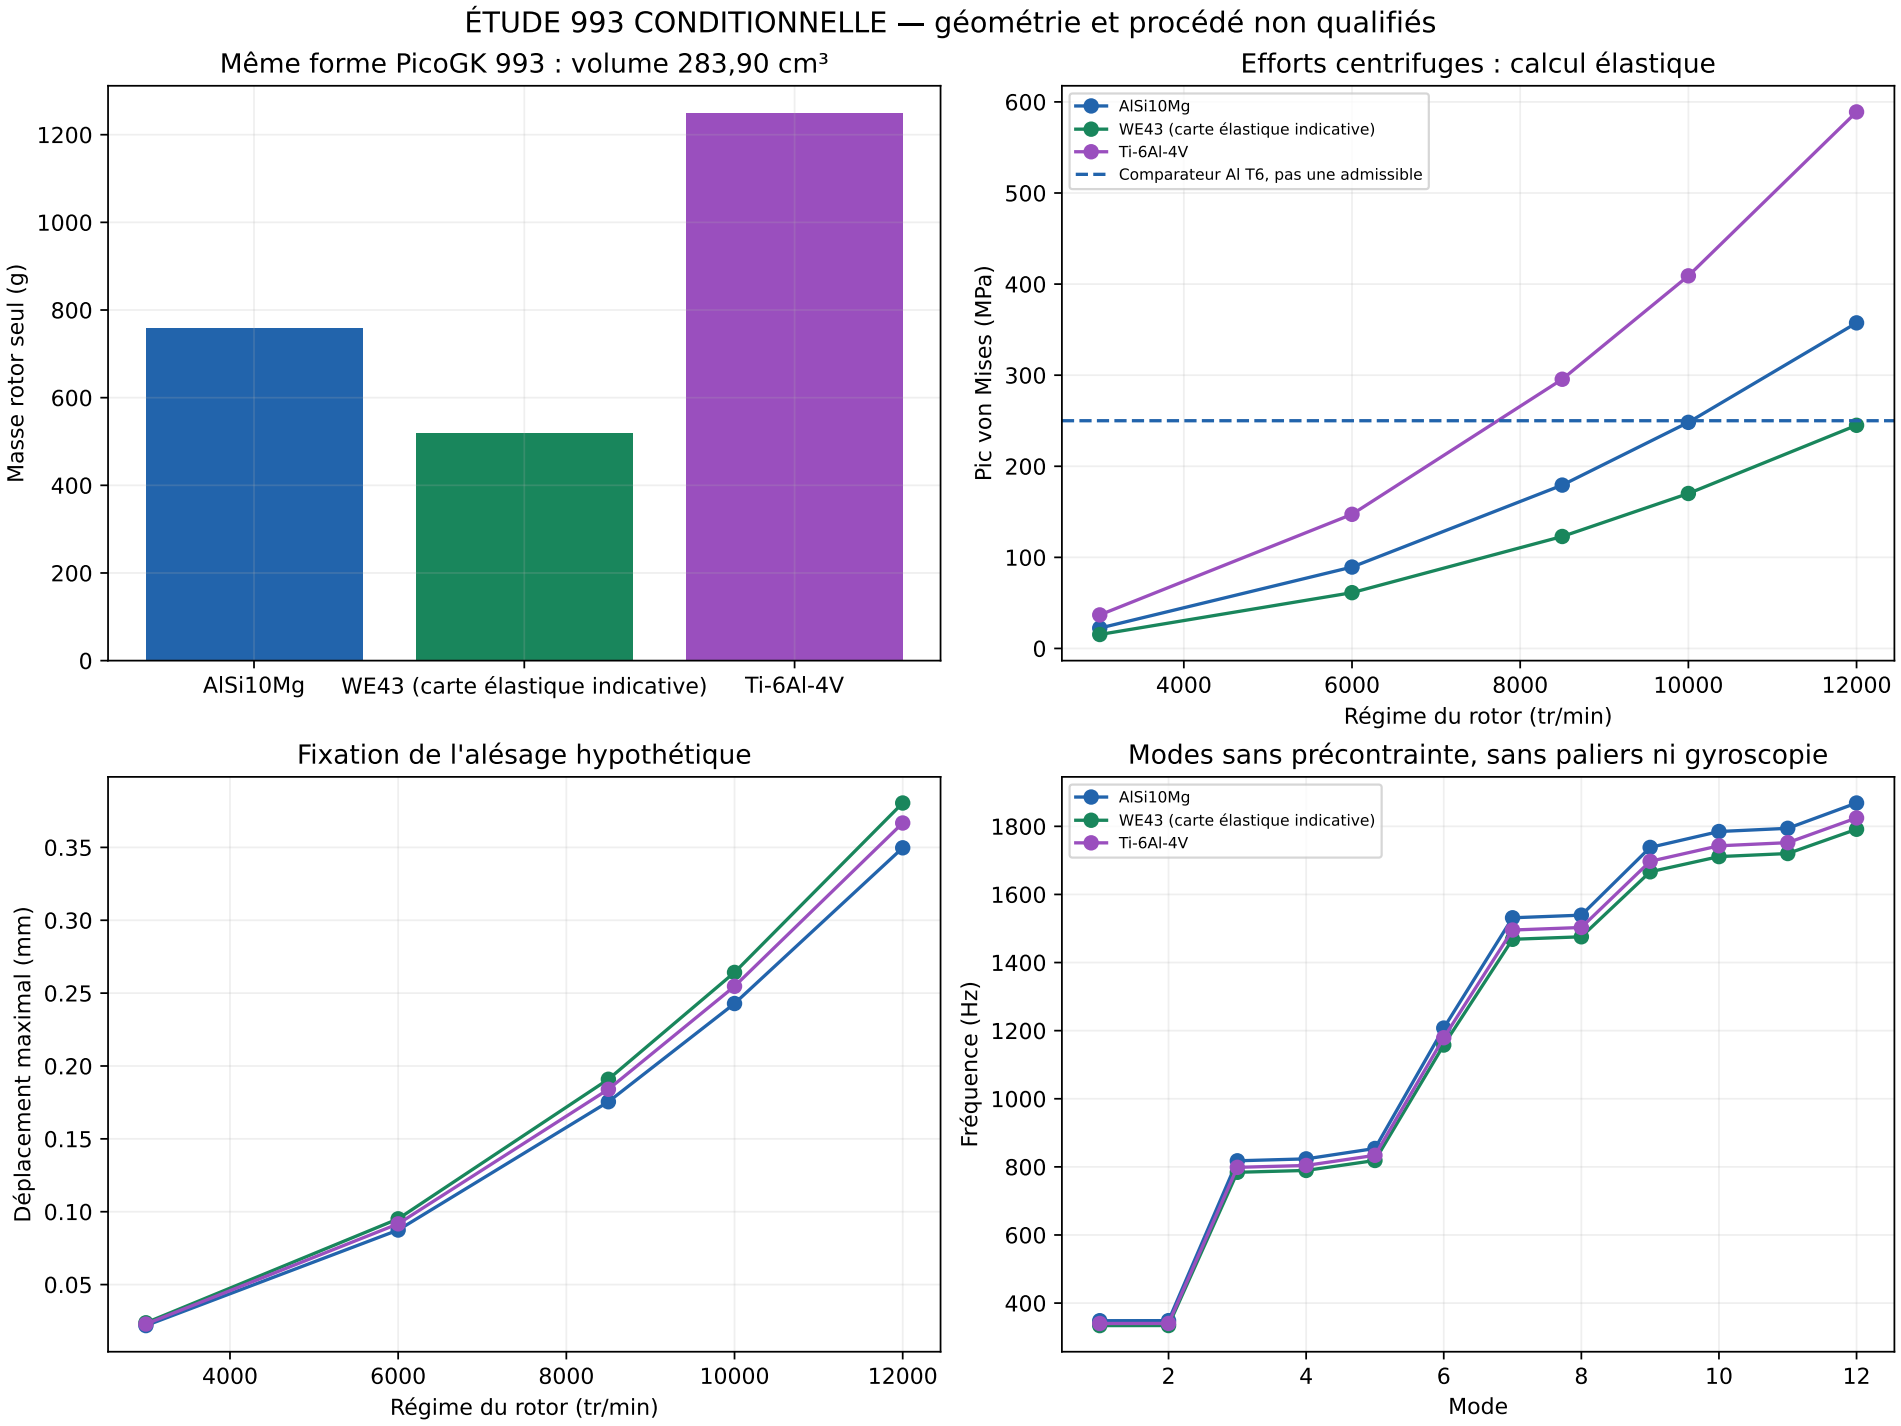
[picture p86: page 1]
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

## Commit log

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2026-09-28 Port reference-validator and process-enum fixes so make check passes on consolidated catalog
    - validate_reference.py: accept additional_declared_dimensions (committed data entries 30/31/41) with field checks, matching the local WIP that was archived in backup/wave1-premerge-20260928
    - validate_catalog.py: add composite_layup to supported processes (carbon body track)
    - tests: port the accompanying reference-validator cases
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2026-09-29 fan: parameterized STEP/geometry source for m64-cooling-fan-0001 (M64Fan.cs, config)
    - geometry/: M64Fan.cs + M64Fan.csproj + fan-config.json; blade_count=11 carries
    its declared provenance note (FVD product images; M64 blade count NOT published,
    docs/research/m64-public-engine-data-2026-09-27.md)
    - KNOWN CHECK FAILURE: csproj targets net9.0 but host SDK is only 6.0.400
    (NETSDK1045) - build validation not runnable here; source preserved, not verified.
    No claim of dimensionally correct/fitted/tested geometry (F1 at best).
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2026-09-29 geo-shortblock: scaffold ShortBlock.csproj (PicoGK project, sources pending)
    - wave2 short-block lane scaffold; net9.0 PicoGK project file only so far -
    implementation and STL export pending in this lane
    - no geometry claims: dims=missing on BOM exhaust/shortblock lines until metrology
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2026-09-29 PET107 lane BOM v1: print/buy candidate lines derived from master engine BOM
    - parts/m64-pet107-bom/: selection record, generated JSON+CSV BOM (14 lines),
    README with selection/evidence rules, stdlib self-check (rc=0)
    - scripts/generate_pet107_bom.py: deterministic stdlib-only generator joining
    the selection record onto twins/m64-engine-system/bom/m64-bom-v1.json
    - every line carries an evidence level (FACT_public/measured_source/
    SINGLE_SOURCE/UNKNOWN), print-or-buy decision, process, quantity, source
    citations, and the fixed 'not fitted/tested/safe/released' status disclaimer
    [pet107-bom-v1.csv]
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2026-09-29 Add m64-charge-air-0001 parametric PicoGK charge-air path geometry (concept)
    Parts: parts/m64-charge-air-0001 with configurable-wall PicoGK C# sources:
    compressor-outlet-to-throttle tube, coupling sleeves, per-bank plenum with
    throttle bores, and interconnect hose centerline sweeps (both banks), plus
    provenance.json tagging every dimension (charge-air line dims are missing in
    the BOM; vendor envelopes tagged SOURCED_ENVELOPE, all sizes ASSUMPTION/
    DERIVED; boost 1.0 bar FACT_public and non-sizing) and a README stating the
    evidence limits (nothing dimensionally correct, fitted, tested, safe,
    released, or manufacturing-ready).
    Checks run:
    - python3 scripts/validate_catalog.py: 34 records vali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
2026-09-29 bench: finish virtual bench — dyno/part-load wiring complete, inputs-gap register, smoke tests, README
    - bench/dyno.py: add partload_sweep + 6-row deviation table (boost and
    fan-flow public anchors added); run_bench.py runs end-to-end again
    (outage left dyno.py mid-edit: AttributeError partload_sweep)
    - charge_air.py: part-load intercooler audit fix (uncommitted WIP)
    - inputs-gap.md: 12 exact acquisition asks (M64-ACQ-BENCH-01b..11 plus
    existing ACQ-0003/0005 references)
    - tests/test_bench_smoke.py: 8 checks incl. anchor exactness, heat-split
    closure, energy ordering, byte-identical determinism; all pass
    - results/: regenerated WOT + part-load sweeps, report.md, deviations
    (peak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
    [deviation_table.csv, sweep_partload.csv, sweep_wot.csv]
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2026-09-29 PET 107-xx wave-2: BOM exhaust/charge-air lines upgraded - heat exchanger and cat converter identity missing->sourced from PET 202-10/202-15, intercooler cross-ref PET-confirmed via 107-45, hoses/duc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
2026-09-29 bench: correct anchor-row labeling in deviation table and fuel verdict
    - torque_at_public_torque_rpm row: the 4050 rpm torque anchor enters the
    two-point calibration solve, so it is exact-by-construction, not a
    blind prediction (deviation note corrected)
    - fuel verdict and dyno docstring aligned with the corrected wording
    - results/ regenerated byte-identically (determinism re-verified);
    smoke suite: 8/8 OK
    [deviation_table.csv]
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2026-09-29 bench: record executed smoke-test validation and evidence-coverage limits in README
    - README validation record: run_bench.py end-to-end OK, rerun byte-identical;
    unittest 8/8 OK (2026-09-29, this worktree)
    - honest deviations at execution date: peak power +1.06%, peak torque +2.93%
    (prediction row), boost plateau -19.95% vs brochure (M64-ACQ-BENCH-08);
    calibration anchors and fan flow exact-by-construction, not blind checks
    - NON verifie list and coverage limit: bench is a 0D model, untested and
    unvalidated against a physical bench; missing inputs stay in inputs-gap.md
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2026-09-29 geo-exhaust: container compile succeeds (picogk-station:qualified-final-20260928)
    - Program.cs: API-conformance fixes to reach a clean build (implicit->xImplicit
    keyword collision, Bounds->oBounds per IBoundedImplicit, two CS0019
    Vector3/scalar broadcasts). Syntax only, no geometry change.
    - provenance.json: build_state records container build succeeded, runtime still
    not exercised; JSON re-validated with python3 -m json.tool (135 lines).
    - validation/compile-record.md: exact docker command, image, dotnet 9.0.317,
    failure/fix sequence, and what the compile does/does not prove.
    - csproj wiring verified complete (net9.0, UpstreamRoot=/upstream in image).
    - bin/obj from the container ru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
2026-09-29 web-gap-closure: replace false pending/skeleton state with honest per-target statuses (0/6 closed; ACQ-0002/3/4/5, oil, conflicts stay open; fan ratio 1:1.6 pre-existing primary)
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2026-09-29 geo-shortblock: deliverable set — validation/build-log.md (station compile PASS at c48b133), provenance.json (per-part tagged dims, ACQ-0004 parameterized), printability.md (LPBF AlSi10Mg vs 2618, fi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
2026-09-29 geo-shortblock: deliverable set — validation/build-log.md (station compile PASS at cf57f3a), provenance.json (per-part tagged dims, ACQ-0004 parameterized), printability.md (LPBF AlSi10Mg vs 2618, fi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
2026-09-29 Consolidation fixes: judge the four PET identity records in the titanium screen, regenerate derived artefacts
    - titanium-am-screen-inputs.json: declare judgements for the four PET
    identity-only records (CA-CHARGE-PIPE-SET, CA-TURBO-INTAKE-MANIFOLD,
    EXH-CAT-CONVERTER-PAIR, EXH-HEAT-EXCHANGER-PAIR); the screen now covers
    all 38 records and still selects the titanium oval tip (unchanged winner)
    - regenerate titanium-candidate-screen.json and pet-zone-titanium-triage.json
    through their own scripts (no hand edits, no SHA-pinned evidence touched)
    - render_parts_table.py: add the CA (charge air) system heading the new
    part_id families require
    - regenerate docs/pieces pages (4 new, 1 rebui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
2026-10-02 Publish corrected 993 air-oil head review and workshop prototypes
    [component-01-context.stl, component-02-context.stl, component-03-context.stl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]
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2026-10-03 Publish tested metal-AM Qwen3 prototype and paired base evaluation (#116)
    * Prepare corrective Qwen data and registered evaluation cycle
    * Record rejected Qwen3 trial and prepare precision SFT with fresh tests
    * Package tested Qwen3 fidelity prototype and paired base results
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2026-10-07 feat(993): F1 cooling impeller with radial equilibrium, cup hub and matched stator
    Brings the staged F1 work (WE43 impeller, AlSi10Mg vane ring, flat-fan
    sizing F2) onto current main and closes its hub-loading gate.
    - Rotor model: simple radial equilibrium behind the rotor, marched
    implicitly from the hub; Lieblein terms use the local axial velocity
    ratio; Borda-Carnot mixing of the exit profile. The earlier uniform-
    axial model hid a hub at de Haller 0.58 with a stalled station.
    - Redesign: 120 mm thin-walled cup hub (rim, web, boss) and free vortex;
    every station >= 0.75 de Haller, rotor-only stall margin 11 %. Blades
    thinned to 0.090/0.054 t/c to keep the shrouded mode 24 % off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
    [cooling_impeller_we43_f1.step, cooling_impeller_we43_f1.stl, fan_stator_alsi10mg_f1.step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]
2026-10-07 feat(993): redesign F1 impeller from the Turbo rotor rebuild
    The first F1 was a generic shrouded axial fan derived from the synthetic
    F0; next to the original it shared nothing, and its 120 mm, 30 mm-deep
    hub left no room for the alternator end the original cup wraps.
    F1 now starts from twins/993-engine-cooling-fan-system-f0's visual rebuild
    of the Turbo rotor and keeps its envelope and interfaces: 245 mm, 165 mm
    cup 56 mm deep, web, twelve windows, three bolt holes, bore, eleven
    blades, no shroud. Only the blades (twisted airfoils, free vortex, DF 0.30)
    and the alloy (WE43) change.
    - Reference rotor is the rebuild itself, modelled as constant-pitch
    cambered plates; the duty is its best-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
    [cooling_impeller_we43_f1.step, cooling_impeller_we43_f1.stl, fan_stator_alsi10mg_f1.step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]
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2026-10-08 feat(964): close the longitudinal datum chain from plate 50-05a
    Critical path M1 of the carbon monocoque programme. The 964 datum network
    could not be placed along X: P21 landed in the rear bumper.
    - Plate 50-05a (volume V, local copy) dimensions P1 (722 +/- 2), P3 (215)
    and P5 (143 +/- 2) from a 0 line through the front strut mounts P4.
    - Plate 50-02 draws dimension P as longitudinal; datum_solve.py read it
    as a crossed diagonal and put P5 230 mm forward.
    - datum_chain_50_05a.py: P17 reached twice from published data only,
    441.1 mm (P5-P20-K) and 439.2 mm (P3-L): 1.9 mm apart against a 3.6 mm
    tolerance spread. P20, P3, P5, P17, P18, P19 fixed to +/- 2-4 mm (95 %).
    - scan_tie_50_05a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
2026-10-08 feat(964): port the monocoque interface audit and PicoGK tunnel study onto main
    Ports origin/codex/964-monocoque-interface-audit-20260925 (6 commits, never
    merged, 1,100+ commits behind) onto current main, where the datum chain was
    closed from plate 50-05a on 2026-10-08. Main stays the reference for
    dimensions; the branch brings identities, corrections and studies.
    Contract (monocoque_interface.py, monocoque-interface.json):
    - designations and pair spans now come from MEAS-MANUAL-964-BODY-CONTROL,
    with value ids; P12 is the GEARBOX crossmember support (MNL-964BC-0009), not
    the rear axle; P3, P19, P20 and P21 names corrected the same way;
    - the published tolerance is on the pair span, no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
    [interface-measurements-20261008.csv]
2026-10-08 feat(964): ZESAD-type carbon monocoque in PicoGK, inside the plate-50-05a shell
    The pinned PicoGK kernel (m64-leap71 native image) voxelizes a carbon
    monocoque architecture in the traced 911 shell: outer skin with its
    apertures, a closed section around every aperture (door, windscreen,
    quarter and rear windows, lids, arches), boxed sills, tunnel, front and
    rear rails and a B-pillar ring, hollowed once so that meeting rings make
    one section, 25 mm sandwich floor and bulkheads, wheel tubs. 3 mm voxels,
    18 min, 4.4 GB peak.
    About 95 kg from assumed layups. Every member size is a hypothesis, the
    tunnel is not 964 geometry, no stiffness is computed yet; the model stays
    prohibited_pending_enginee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
2026-10-09 feat(964): torsion of the ZESAD-type monocoque architecture
    torsion_monocoque.py puts the PicoGK members on the open shell's own mesh
    as shells (skin band, inner wall offset by the section depth, side walls
    on every free edge; bands united first) and reruns the torsion load case
    of torsion.py, four cases at three shell densities.
    Monocoque: K 33,246 / 31,501 / 29,492 N.m/deg in 0.8 mm steel (123 kg)
    and 23,192 / 24,564 / 22,283 in the assumed CFRP layup (75 kg), stable
    within 6%. The open shell does not converge (5,425 / 3,468 / 2,261, and
    966 with every triangle split in four), so the ratio between them is not
    a result; only "more than five times stiffer" holds. CFRP against steel
    on the s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
2026-10-09 feat(catalog): PicoGK models replace the concept blocks in the parts gallery
    The README gallery showed the build123d concept blocks. parts/picogk-catalog/
    rebuilds 34 of the 35 parts with CAD on the pinned PicoGK kernel - hollow
    where the concept is hollow, filleted, with the blades, galleries, ribs,
    double walls, vanes and flanges each concept describes.
    - common/: signed-distance helpers, open-cell lattice, parameters, and a
    runner that discovers IPartGenerator implementations by reflection;
    groups rotating, engine, exhaust, body, trim are separate projects.
    - parts/<id>/source/picogk.json: each part's parameters with their basis
    (published / catalogue / community / assumption) and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
    [993-carrera-exhaust-42_5-f1-picogk.stl, 993-intake-49-f1-picogk.stl, chain_case_concept_f0-picogk.stl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]
2026-10-09 feat(964): two PicoGK monocoque architectures in torsion, one load case
    torsion_rings.py runs the closed-ring study of picogk-rings/ through the
    shell model and load case of torsion_monocoque.py: sills and tunnel as skin
    bands, tubes as B32 beams with the tube's area, bending and torsion
    stiffness (torsion.tube_equivalent; CalculiX reads CIRC as diameters),
    welded at joints and tied to the skin along the tangent line; members and
    paths from the study's own params and prepare.py.
    CFRP layups, three meshes: skin boxes (picogk/) 23,192 / 23,080 / 22,283
    N.m/deg for 75 kg; tubes (picogk-rings/) 13,723 / 10,778 / 9,559 for
    61 kg; the same without tubes 4,881 / 3,104 / 2,480. Per kilogram the ski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
2026-10-10 fix(964): bulkheads in the monocoque torsion models; where the carbon pays
    The shell builder placed the bulkheads at exactly d 380 and 1975 mm, a few
    millimetres from the section whose ring they used: they did not weld and
    connectivity("largest") dropped them. Every torsion value since #139 was
    computed without them. Placed on their section, they weld: the open shell
    goes from 2,261 to 3,209 N.m/deg. Two more faults fixed: side-wall needles
    under 0.5 mm wide (1-1.5% too stiff, inverted when thickened) are
    filtered, and each K is the value two solves agree on (CalculiX now and
    then returns one too high, +2% to +60%).
    Everything rerun at three meshes: monocoque 47,267 N.m/deg in steel and
    35,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
2026-10-11 feat(catalog): bionic redesign of the PicoGK gallery parts
    Redo of the gallery models as load-path structure grown by 3D SIMP
    topology optimization instead of geometric rules.
    Tooling:
    - parts/picogk-catalog/bionic/topopt.py: hex8 SIMP, density filter,
    Heaviside continuation, OC update, pyamg-preconditioned CG; driven by
    each part's source/bionic.json (design, solid keep-ins, void
    keep-outs, supports, load cases).
    - BionicTopology.cs generator: smooth PicoGK body from the density
    field, exact functional features added and cut afterwards.
    - finish.py: envelope_mode "max" (model must fit inside the published
    envelope); Runner exposes ParamsPath.
    - Helpers to build exact base meshes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
2026-10-11 feat(964): tubes bonded over a strip; the tube-to-skin joint decides the ranking
    The tube model of picogk-rings/ never converged (-15% per refinement):
    each tube node was tied to a single skin node, which sinks into the skin
    as the mesh is refined. Tied by stiff links to every skin node within
    20 mm of the tangent point (a bonded strip about 40 mm wide, ASSUMED), it
    converges: 38,640 then 38,630 N.m/deg in CFRP for 73 kg.
    But K then follows the strip width (--bond-sensitivity, finest mesh):
    23,665 (single node), 25,155 (20 mm), 38,630 (40 mm), 57,508 (60 mm),
    against 35,462 for the skin boxes, i.e. x 0.78 to x 1.89 per kg. A beam's
    section cannot ovalize, so strip ties are an upper bound an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
2026-10-11 feat(964): tubes meshed as shells; the skin between tubes stays open
    torsion_shell_tubes.py gives every tube of picogk-rings/ its own wall: S3
    shells refined with the skin, bonded along the line of tangency to the
    skin triangle beneath (translation ties, *EQUATION, now supported by
    torsion.solve), tied to each other where they meet. On a cantilever plate
    with a tube this bond converges to 9% softer than composite beam theory;
    tying more generators around the tube came out stiffer than the theory and
    was rejected.
    CFRP: 35,198 / 29,607 / 25,895 N.m/deg over the three meshes, still
    falling: the tubes are now refined with the skin, so the cause is the skin
    between them, which a line bond leave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
2026-10-11 feat(964): monocoque in bending; same cabin members, torsion decides
    bending.py puts the shell models of torsion_monocoque.py under vertical
    bending: supports on +/-40 mm strips at the axles (rollers front, pins
    rear, no clamp moment), 2 kN on the sill skin at mid-wheelbase, K read on
    the loaded skin and the cabin's sag below the chord d 400-1950, both on
    the sill line. torsion.solve now wraps a general run() (fixed DOF sets,
    per-node loads); the published torsion K is unchanged (3,209 N.m/deg).
    The skin boxes stiffen the open shell x3.6 to x4.4 in bending on three
    meshes, against x5 to x15 in torsion. Leave-one-out (CFRP, two meshes):
    the cabin's bending is carried by the sills (28-37%) an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
2026-10-12 feat(bionic): analysis-only solids for thin walls
    A solid marked analysis_only stiffens the topology optimization (modulus scaled by stiffness_scale, e.g. wall thickness / element size) but is not printed from the grid: BionicTopology skips it and the exact wall comes from shaping.base_stl. In the written density the band takes the largest neighbouring free density so members reach the wall.
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2026-10-12 fix(catalog): restore hash-pinned Runner.cs
    Runner.cs is pinned by SHA-256 in twins/993-engine-mount-system-f0, twins/bionic-turbo-f0 and twins/bionic-turbo-f1, which were built before #153 added Runner.ParamsPath; main has been red since. Restore the pinned bytes and let BionicTopology read the params path from the command line instead. Same output (Ti oval tip rebuilt: 65.59 cm3).
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2026-10-12 Study 750 hp intercooler sizing and assumed installed cooling architectures (#179)
    * Build PicoGK installed cooling study and preserve airflow experiment evidence
    * Retain feature-snapping rejection and clarify intercooler envelope
    * Size the 750 metric hp intercooler and screen thin metal fin routes
    * Retain inspected PicoGK thin-fin coupons and sizing figures
    * Compare assumed 750 hp cooling architectures and generate PicoGK headers
    * Clarify coupon pitch mismatch for the new cooler candidate
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2026-10-13 feat(993): 3D FE screen and Campbell diagram of the F1 WE43 impeller
    The engineering screen checks the F1 rotor with beam and ring formulas and
    a single cantilever blade. A gmsh C3D10 + CalculiX screen of the committed
    STEP (stress-stiffened modes, 0-12,000 rpm, hub joint bracketed as clamped
    or fixed bore) shows what those formulas cannot:
    - peak 92-96 MPa at 12,000 rpm at the unfilleted blade-root/rim corner
    (yield / peak 2.3-2.4, against 4.7-20.6 in the beam screen); mesh
    independence not demonstrated
    - cup/web modes at 344-525 Hz at rest, below the 1,351 Hz the modal pass
    checks; first blade family at 1,890-2,530 Hz
    - the 17-vane stator order meets the ND5 blade mode at 7,581 rpm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
2026-10-14 fix(qwen): pin continuation results to the published rejected trial
    prepare --continuation-from read the predecessor's own run-001/results.json
    and then trusted the adapter, configuration and receipt hashes it carried, so
    a consistently altered result, adapter and receipt would be accepted and
    recorded as the predecessor. The result is now accepted only when its SHA-256
    matches the private receipt of a committed rejected-trial publication
    (results-*.json, completed_rejected_final) and agrees with its adapter digest
    and final score; the trial's FROZEN.json must match the pinned frozen_sha256
    before verify() trusts it.
2026-10-14 Validate the F13 alignment receipt before placing the private scan
    PICOGK_F13_ALIGNMENT accepted any 16 finite values once the scan digest
    matched, so a stale or edited receipt could scale, shear or move the scan
    and its collisions were still reported as F13-aligned.
    The native preflight, before the viewer opens, now requires the F13
    producer's phase, status and unmeasured-datum flags, the scan's triangle
    count, and a rigid row-vector matrix (last column 0,0,0,1; orthonormal
    rotation with determinant +1 to 1e-6). In the run, the aligned scan bounds
    must match the receipt's within 1 mm, and the receipt and scan must be
    unchanged since preflight. The report embeds the receipt, and the reporte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
2026-10-14 docs(962): translate the cylinder head study pages to English
    Translate the six study pages added by this PR (BIONIC_FIELDS, COOLANT_BOUNDARIES,
    GALLERY, ORIGINAL_ARCHITECTURE, REFINEMENT, STOCK_ENVELOPE) and the sections it
    adds to KIT_962_PROGRAMME.md and validation.md. Numbers, links, identifiers and
    limits are unchanged; no claim is strengthened.
    Sources, prompts, generators and derived reports stay as they are: their
    SHA-256 digests are recorded by the derived/*-report.json files, which come
    from native PicoGK and Qwen runs on inputs that are not on this machine.
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2026-10-14 docs(993-rear-panel): translate CSV data and KiCad schematic text to English
    Finishes the English pass started in PR 146. Free-text columns of bom.csv,
    measurements.csv, coupon-bom.csv and coupon-wiring.csv, plus the titles,
    notes, sheet name and two component values of the three KiCad sheets, are now
    English. Identifiers, nets, pins, references, numeric values, statuses and CSV
    columns are unchanged; the schematic test expects the two new values.
    The review PDF is re-exported with kicad/kicad:9.0.2 (network disabled):
    schematic test OK, ERC 0 errors 0 warnings, pages reviewed visually. The
    verification page records the run and the export's environment dependence.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
2026-10-15 wip(964): monocoque buckling and element check (rescued after WSL crash)
    Uncommitted work from 2026-10-12, committed as-is to preserve it.
    Not checked with make check.
2026-10-15 chore: track the k16-rod-improvement-plan workflow script
    The script behind PR #86 (docs/993/993_K16_ROD_IMPROVEMENT_PROGRAMME.md)
    lived only in an untracked .claude/workflows/ directory on one machine and
    was nearly lost in a WSL crash on 2026-10-15. Track it so the plan can be
    re-run.
2026-10-15 Re-run the hydraulic proxy with the assumed rib-root fillets
    Solve the fully developed laminar section problem by finite elements on the
    sharp and filleted four-rib channels and repeat the study's equal-pressure split
    at the same mass flow and assumed K = 2. The sharp case reproduces the exact
    rectangular series and the study's 4.866 Pa; the assumed 0.2 and 0.4 mm fillets
    add 0.33 % and 1.47 %. study.py is unchanged; this stays a proxy.
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2026-10-16 docs(993): ADR 0013 pilots on documentary evidence and a consolidated capture protocol (#3, #4)
    Decision 0013 records why the three phase 2 pilots were chosen on 2026-08-28,
    the SAFETY.md exclusion rule they pass, and the owner's constraint of
    2026-09-14: nothing is bought or measured, so the pilots advance on documentary
    evidence and physical capture stays backlog for an external contributor. The
    evidence owner is written into each pilot's known_limits. Pilot 2, the door
    pull, is classed functional; keeping or swapping it is left open for the owner.
    No repository source gives a PET number with plate and position for any pilot,
    so porsche_part_numbers stays empty and each record says why. 9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

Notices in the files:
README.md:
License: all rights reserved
